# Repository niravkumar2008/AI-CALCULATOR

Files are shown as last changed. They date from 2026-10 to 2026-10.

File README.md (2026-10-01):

# AI Calculator

## Stage 4: the full calculator

The device now works like a Casio fx-300ES PLUS in COMP mode, with the AI photo solver as mode 4 in the MODE menu. The same C++ code runs in three places:

| Where | How |
| --- | --- |
| **Browser** | `AI_Calc_Simulator.html` (next to the exe; same as `sim/web/simulator.html`): double-click to open in Chrome or Edge. Clickable keypad, test bench (demo replies, hotspot/key switches, clock fast-forward, USB unlock). For real scans, pick Photo or Typed problem and paste your API key: it then sends exactly what the ESP32 sends (upright, grayscale, max 1600 px JPEG, same request, model, streaming and error handling). Direct API calls only work in this local file; the Claude artifact page blocks them. |
| **Windows** | `AI_Calc_Simulator.exe`: type on the keyboard (key list at the bottom of the window). **F6 scans a photo** (needs `api_key.txt` next to the exe). |
| **Tester** | `firmware/`: see [firmware/README.md](firmware/README.md). |

What the calculator does:

- **COMP maths:** + − × ÷, exact fractions (1÷3 = 1⌟3, S⇔D for decimal), powers, roots, x², x³, x⁻¹, x!, nPr, nCr, log (with base), ln, eˣ, 10ˣ, sin/cos/tan and inverses, hyp menu, Abs, %, π, e, Ran#, Rnd, ENG. Casio priorities: implicit × binds tighter than ÷ (1÷2π = 1÷(2π)), (−)2² = −4, brackets close themselves at the end. 10 significant digits, Norm1/Norm2.
- **Editing:** cursor with ◀ ▶ (wraps), DEL, SHIFT DEL = INS (overwrite), ▲ ▼ replay of the last 20 sums, Ans / PreAns, carry on from Ans with an operator.
- **Errors:** Math ERROR / Syntax ERROR / Stack ERROR with [AC] Cancel and [◀][▶] Goto.
- **Memory:** STO / RCL into A–F, X, Y, M; ALPHA types a variable; M+ / M−; SHIFT 9 = CLR (Setup / Memory / All).
- **MODE:** 1 COMP, 2 STAT and 3 TABLE (later), 4 AI SOLVE.
- **SETUP (SHIFT MODE):** 1–3 Deg / Rad / Gra, 4–5 Norm1 / Norm2, 6 Wi-Fi & key, 7 Screen look (Plain / LCD dots), 8 Exam mode.
- **AI SOLVE:** = scans; answer, question and steps scroll with ▲ ▼. If the photo is a calculation, Claude also sends it as `expression` and it is **typed into the main screen** for you to check, edit and press = (AC from the answer takes you there). Unclear scans are flagged on the main screen in reverse video.
- **Exam mode:** SETUP 8 then =, or SHIFT, 7, ON while off. AI, camera and Wi-Fi off; black status bar with a padlock and the time it's been on; survives power-off and restarts. Ends only with the USB cable (`exam off` over serial) or after 12 hours. CLR All doesn't end it.
- **Power:** SHIFT AC = OFF, auto-off after 10 minutes idle.

Screen: 125×61 pixels (the 2.13" e-paper at 2×) = 25 characters × 7 rows; row 0 is the status bar (S, A, M, STO/RCL, D/R/G, Wi-Fi, AI, ▲▼).

New code: `core/calc_engine.*` (tokens, parser, exact fractions, formatting), `core/device.*` (keys, menus, modes, exam, drawing), `sim/web/` (browser build). Tests: 422 checks, `./build/tests`.

Rebuild the browser simulator after changing `core/`: install [Emscripten](https://emscripten.org), then `sim/web/build.sh`.

## Stage 2: Windows simulator (AI flow)

Software for a modified Casio fx-300ES Plus that does one thing: take a picture of a problem and show Claude's answer and the steps to it.

Stage 2 runs the whole flow in a Windows simulator with **real Claude calls**: a photo file stands in for the camera.

## Run it

1. Extract the zip anywhere.
2. Create `api_key.txt` next to `AI_Calc_Simulator.exe` containing your Claude API key (from [console.anthropic.com](https://console.anthropic.com), *API Keys*). One line, nothing else. Setting a monthly spend limit in the Console is a good idea.
3. Double-click `AI_Calc_Simulator.exe`. (Windows may show a SmartScreen warning for an unsigned app: *More info → Run anyway*.)
4. Press Enter and pick a photo of a problem (JPG, PNG, HEIC if Windows can open it).

What happens: the photo is rotated upright, shrunk to at most 1600 px, turned grayscale, and sent to Claude Sonnet 5.5. Claude may think first on harder problems. The answer appears as soon as it arrives, and the steps follow a moment later.

**No `api_key.txt`?** The simulator falls back to Stage 1's sample mode and plays back the hand-written replies in `samples/`. The key file is re-read on every request, so you can add or fix it without restarting.

**Privacy:** the photo is sent only when you press Enter and pick a file. It is kept in memory only. `api_key.txt` is listed in `.gitignore`, so it is never committed to your repo.

| Laptop key | Calculator key | What it does |
| --- | --- | --- |
| Enter or `=` | `=` | Calculate; in AI SOLVE: take a picture / retake / retry |
| Esc | `AC` | Clear, back, or cancel while solving |
| Backspace | `DEL` | Delete |
| Arrows | REPLAY pad | Cursor, history, scroll |
| `m` then `4` | MODE 4 | AI SOLVE |
| Other keys | see `keysForChar` in `core/device.h` | s c t = sin cos tan, `[` SHIFT, `]` ALPHA ... |
| F2 / F3 | — | Simulate hotspot / API key on or off |
| F4 | `ON` / `SHIFT`+`AC` | Power on/off |
| F5 | — | USB cable: ends exam mode |

If Claude isn't sure it read the photo correctly (confidence below 0.8), you see what was unclear first: press `=` to retake, or ↓ to see the answer anyway.

## Messages you might see

| Screen | Meaning |
| --- | --- |
| CLAUDE ERROR / API key was rejected | Check `api_key.txt` |
| CLAUDE BUSY | Rate limit or Claude overloaded; try again shortly |
| NO CONNECTION | No internet, or the connection dropped mid-reply |
| TIMED OUT | No reply within 2 minutes |
| CAMERA ERROR / Couldn't open that image | Windows can't decode that file type |

## What's in here

```
AI_Calc_Simulator.exe   Windows simulator (built from the source below)
samples/                Hand-written example replies in Claude's reply format
core/                   Portable C++17 device logic, shared with the future ESP32 firmware
  device.*              The whole calculator: keys, COMP editing, menus, AI SOLVE, exam mode, status bar
  calc_engine.*         Tokens, Casio-order parser, exact fractions, number formatting, typed-text parser
  app.*                 AI SOLVE screens (Ready, Solving, Warning, Answer, Message)
  claude_api.*          Claude's instructions, reply schema, request body, stream reader, error mapping
  framebuffer.*         125x61 1-bit screen buffer (the e-paper at 2x)
  font*.cpp/h           5x7 font (X11 misc-fixed, public domain) incl. Greek, sub/superscripts
  text.*                Word wrap for 25-character lines
  json.*, solve_result.*  Reading Claude's reply
sim/win32_main.cpp      Simulator: Win32 window, file dialog as camera, WIC photo shrinking, WinHTTP
sim/web/                Browser simulator: web_main.cpp (JS bridge), page.html, build.sh -> simulator.html
tests/                  Unit tests + screen snapshots (tests/golden)
tools/gen_font.py       Regenerates core/font_data.cpp
firmware/               ESP32-S3 tester firmware (PlatformIO), Stage 4
```

## Reply format

Claude replies with exactly this JSON, enforced by the API's structured output. The field order is fixed, so the answer streams in before the steps:

```json
{
  "readable": true,
  "confidence": 0.95,
  "unclear": ["line 1: '7' could be '1'"],
  "expression": "sqrt(2*9.81*5.0)",
  "answer": "v ≈ 9.90 m/s",
  "read_as": "the question as understood",
  "steps": ["step 1", "step 2"]
}
```

The instructions (in `core/claude_api.cpp`) tell Claude the screen is 25×6 characters, so the answer is kept to about 2 lines, steps to about 75 characters, in calculator notation with no LaTeX. `expression` is the calculation in typed form (`*`, `/`, `^`, `sqrt(`, `pi`, `E` for ×10ˣ), or empty for word problems.

## Build from source (optional)

The tests run on Linux or macOS: `cmake -S . -B build && cmake --build build && ./build/tests` (run from this folder).
The exe is cross-compiled with MinGW:
`x86_64-w64-mingw32-g++ -std=c++17 -O2 -static -mwindows -o AI_Calc_Simulator.exe sim/win32_main.cpp core/*.cpp -lgdi32 -lwinhttp -lwindowscodecs -lole32 -loleaut32 -lcomdlg32`

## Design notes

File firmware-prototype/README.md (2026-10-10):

# Board firmware (the calculator inside the Casio shell)

This is the firmware for the custom board (`../hardware/kicad`, ESP32-S3-MINI-1-N4R2): the full
calculator from `../core` (the same code as the simulators), the whole keypad, the e-paper, the OV5640
autofocus camera, the 150 mAh battery and deep sleep, Wi-Fi through the AI proxy (`../server/proxy`),
over-the-air updates and a phone setup page. **`../firmware/` is the old breadboard tester** (different
pins, different board): never flash it to this board.

**Status (stage 14, 2026-10-06):** builds clean (`pio run`: RAM 30.7 %, flash 63 % of the 1.9 MB OTA
slot). Not yet run on hardware: start at `../hardware/ARRIVAL_CHECKLIST.md`, then `../hardware/bringup_guide.html`
(step 10 = AI server + token); the day-one script in `../firmware/FINAL_REVIEW_firmware.md` is the same path. Version string: `kFirmwareVersion` in `src/claude_client.h`.

## Hardware it expects (from the schematic)

| Part | What |
| --- | --- |
| Module | ESP32-S3-MINI-1-N4R2 (4 MB flash, 2 MB quad PSRAM) |
| Camera | OV5640 autofocus on J1; power through CAM_PWR_EN (GPIO 34), PWDN 48, RESET 38 (open-drain); data pins in `hardware/pins_final.h` |
| Screen | 2.13" e-paper panel (SSD1680, 250x122) on J2 with the board's boost circuit; BUSY on GPIO 33 (weak internal pull-down so a missing panel doesn't stall the bench) |
| Keys | 49 keys as an 8 x 10 matrix (ROW0-7, COL0-9) into a TCA8418 (I2C on GPIO 1/2, INT 4); ON on GPIO 7 |
| Power | Adafruit #1317 150 mAh LiPo on J4, MCP73831 charger at 50 mA (STAT on GPIO 35, pulled up to VBUS_SENSE), battery sense GPIO 9 (1 M / 1 M), USB sense GPIO 37 |
| USB | the chip's own USB on GPIO 19/20, through the magnetic plug (J3) |

Every pin is in **`hardware/pins_final.h`** (`src/pins.h` only includes it; it is the single source of
truth and `python tools/check_pins.py` compares it with the schematic's netlist). Which key sits at which
matrix crossing is `kMatrix` in `src/keys.cpp`.

## Files

| File | What |
| --- | --- |
| `src/main.cpp` | the loop: keys, screen, Wi-Fi on/off, battery lock-out, viewfinder, Send, setup mode, updates, deep sleep |
| `src/settings.*` | NVS settings (hotspot, proxy, token) and the Serial Monitor commands |
| `src/setup_portal.*` | phone setup: the calculator's own Wi-Fi network + sign-in page that writes the settings |
| `src/ota.*` | over-the-air update: manifest, download, SHA-256 check, second app slot, rollback |
| `src/claude_client.*` | HTTPS to the proxy: the photo solve (streamed), small JSON calls, the firmware download |
| `src/camera.*`, `src/preview.*` | OV5640 capture / tuning, and the laptop preview page (`preview` command) |
| `src/keys.*`, `src/screen.*`, `src/power.*` | TCA8418 keypad + ON, e-paper, battery / charging / deep sleep |
| `src/selftest.*` | factory self-test (`SELFTEST_JSON` line; fields listed in `hardware/bringup_guide.html`) |
| `src/log.h` | `LOGF("module", ...)`: every log line is `[module] text` |
| `platformio.ini` | board settings; `min_spiffs.csv` partition table = two 1.9 MB app slots for OTA |

## 1. Build and flash (USB)

1. VS Code with the PlatformIO extension. **File > Open Folder** > `firmware-prototype` (this folder).
2. Plug the magnetic USB cable into the board and the PC.
3. Click **Upload** (the arrow in the blue bar). First build downloads the toolchain (5-10 minutes).
   Command line: `%USERPROFILE%\.platformio\penv\Scripts\pio run -t upload` from this folder.
4. **Serial Monitor** (plug icon) at **115200**. Type `help`.

The first upload after this version also writes the new partition table (two app slots). Saved settings
survive it (NVS sits at the same place in both tables). **The first flash of every board is this USB
upload**: an over-the-air update only writes the other app slot, never the partition table. After it,
`status` shows `slot app0`.

### Recovery: no COM port, or "no serial data"

The chip is in normal boot and must be forced into download mode. Plugging the cable in does **not**
reset the chip while the battery is connected (the battery keeps 3.3 V and EN up), so holding BOOT while
plugging in does nothing on its own. Back cover off:

1. Hold a wire from **TP1 (BOOT)** to **TP4 (GND)**.
2. Tap a second wire from **TP7 (EN)** to **TP4 (GND)** for about 0.2 s. The chip restarts in download mode.
   (Or unplug the battery at J4 first, then hold TP1 to GND while you plug the cable in.)
3. Release TP1 and click Upload.
4. When it finishes, tap TP7 to GND once more to start the new firmware.

Backup path if the USB path ever fails: the ROM also listens on UART0. A 3.3 V USB-serial adapter on
**TP2 (TX) / TP3 (RX) / TP4 (GND)**, then the same TP1 + TP7 sequence, and upload over that COM port.

**Never burn the security or USB-disable eFuses** (`DIS_USB_SERIAL_JTAG`, `DIS_DOWNLOAD_MODE`,
`ENABLE_SECURITY_DOWNLOAD`), and never enable secure boot or flash encryption on this board: they are
the only things that could lock it out for good.

## 2. First setup

The calculator needs three things to use AI: a phone hotspot (name + password), the AI server address
(`https://...`, your deployed `server/proxy`) and its device token (`python admin.py new-device "board 1"`
on the server). The maths works with none of them. It never holds a Claude API key: the `token` command
refuses anything starting with `sk-ant-`, and an old key left by earlier firmware is erased at first boot.

**From a phone (no PC):** SHIFT MODE (SETUP) > **6: Wi-Fi & key** > press **=**. The screen shows
`SETUP BY PHONE` with a network name (`AI-Calc-xxxx`) and an 8-character password. Join that network on
the phone; the setup form pops up as the network's sign-in page (or open `http://192.168.4.1`). Pick the
hotspot from the list the calculator saw, type its password, the server address and the token, **Save**.
The calculator closes the network a few seconds later. AC leaves setup mode; it also ends by itself after
10 minutes. (The serial command `setup` does the same and prints the details; `setup off` stops it.)

**From the Serial Monitor:** `wifi`, `proxy`, `token`. Then `pair` for the 6-letter code and open
`<server>/link` on the phone (an unlinked calculator also shows the code when you first press = in AI
SOLVE), and `account` for the subscription state.

Other commands: `status`, `scan`, `snap`, `preview` (laptop camera page), `selftest`, `update`,
`forget`, `keys 1/3=` (press keys from the keyboard: digits . + - * / ^ ( ) =; s c t sin cos tan,
l log, n ln, r sqrt, q x², i x⁻¹, b Abs, g logₐb, f fraction, ~ (−), E ×10ˣ, h hyp, k RCL, w S⇔D, M M+,
a Ans, # DEL, $ AC, m MODE, o ON, [ SHIFT, ] ALPHA, < > u d arrows, p π, ! x!, % percent, , comma),
`exam off` (the teacher's USB unlock).

## 3. Using it

- **MODE 4 = AI SOLVE.** The viewfinder runs on the e-paper; **point the camera at the problem and
  press =**. ▲▼ change the effort, **1** toggles tutor mode (one hint per =), AC goes back to the
  calculator, ▶ restarts the viewfinder after its 30 s idle timeout.
- **Messages on the glass:** `No connection` / `NO CONNECTION` (turn the phone's hotspot on),
  `Not set up` (see First setup), `Battery low: plug in the cable to use AI solve` (below 3.6 V the
  camera and Wi-Fi stay off together until the cell is back above 3.7 V or a cable is in; maths keeps
  working), `AI ACCOUNT` (link / subscription / monthly cap, with the server's own sentence), the black
  `EXAM` bar (exam mode), and while off on a cable: `Charging 64%`.
- **Off** (SHIFT AC, or 10 minutes idle) is deep sleep (~25-35 µA for the board). ON or any key wakes
  it; memories, history and settings come back from RTC memory. With a cable in it stays awake so the
  Serial Monitor keeps working.
- **Exam mode:** SHIFT, 7, ON while off (or SETUP 8). Wi-Fi and camera off until a USB cable's
  `exam off` or 12 hours. Survives a battery pull.
- Battery reading off by more than 2 % from a meter on TP6? Adjust `kBatteryCal` in `src/power.cpp`.

## 4. Firmware updates over the air (OTA)

1. Build (`pio run`). The image is `.pio/build/prototype/firmware.bin`; bump `kFirmwareVersion` in
   `src/claude_client.h` first (the proxy compares version strings, so any change counts as "different").
2. On the server: `python admin.py firmware .pio/build/prototype/firmware.bin stage14-2026.10.10`.
   That copies the image into `FIRMWARE_DIR/stage14/` with its size and SHA-256. The proxy keeps one
   image per board family, so a v15 LCD image (`v15lcd-...`) can be published at the same time and
   is never offered to these boards (nor this one to v15 boards).
3. On a calculator: either type `update` in the Serial Monitor, or just **switch it off (SHIFT AC)
   with the cable in**: 20 s later it joins the hotspot, asks the proxy (`GET /v1/firmware` with its
   version), and if the server has a different image it shows `UPDATING ... 45%`, checks the SHA-256,
   writes the other app slot and restarts. It checks again once a day while it stays on the cable.
   On battery an update needs more than 3.8 V (`update` command only; the automatic check needs a cable).
4. The new firmware **confirms itself** 15 s after boot once the keypad scanner answers
   (`esp_ota_mark_app_valid_cancel_rollback`). If it crashes before that, the bootloader boots the
   previous slot (`status` shows the slot and "not yet confirmed").

The image travels over TLS to the root-pinned proxy and is accepted only when its hash matches the
manifest; there is no signing key in the firmware or the repo (nothing secret is in either).

### Proxy follow-ups in `stage14-2026.10.10` (small, safe changes)

- **Preview Send no longer gives up on a long answer.** `kSendSolveTimeoutMs` (120 s *total*) became an
  idle limit, `kSendSolveIdleMs` = 150 s without a byte to or from the proxy (the client's own `kIdleMs`
  of 120 s still reports first), plus an overall cap `kSendSolveMaxMs` = 300 s (`src/main.cpp`). The
  proxy's `: ping` every 15 s counts as activity, so an `xhigh`/`max` solve that is still thinking or
  streaming isn't called "took too long" at 2 minutes. `src/claude_client.cpp` notes the time of the last
  byte sent or received (`claudeLastActivityMs()`).
- **Burst-limit message.** The proxy can now answer its burst limit as `429 rate_limited`; `core`'s
  `classifyFailure` shows its message like the other account errors. The proxy sends the old
  `fair_use_exceeded` to firmware older than 2026-10-10 (by `x-firmware`), so boards still on
  `stage14-2026.10.06` keep showing the message too.
- The request still carries the system prompt on v14 (`CALC_SEND_SYSTEM_PROMPT` defaults to 1), so these
  boards also work with an older proxy. Build result unchanged: RAM 30.7 %, flash 63.4 %, no warnings.

## 5. Serial log

Every line starts with its module: `[keys] 7`, `[wifi] connected: 172.20.10.3`, `[cam] focus ...`,
`[solve] [3] answer after 6120 ms`, `[ota] ...`, `[setup] ...`, `[power] deep sleep`. Two lines are
different on purpose: the `status` block, and `SELFTEST_JSON {...}` (one JSON line the bring-up guide
asks you to save). Interactive prompts (`Hotspot name:`) have no prefix.

## Differences from the tester

| | Tester (`../firmware`) | This board |
| --- | --- | --- |
| Keys | =, AC, ▲, ▼, BOOT | whole keypad; hold ▲ ▼ ◀ ▶ DEL to repeat |
| Key row 2 | — | fx-115ES legends: CALC, ∫dx, x⁻¹, logₐb (CALC / ∫dx show "Not supported yet") |
| Starts in | AI SOLVE | COMP, like the Casio (MODE 4 = AI SOLVE) |
| Photo | 1600x1200 + enhanced close-up | 2048x1536 after autofocus, best of 4 frames, one photo |
| Claude | API key in the device (never ship it) | proxy + device token, no key on the device |
| Power | USB | LiPo; deep sleep when off; Wi-Fi only in AI SOLVE, capped at 11 dBm; AI off below 3.6 V |
| Setup | Serial Monitor | Serial Monitor or the phone setup page |
| Updates | USB | USB or over the air with rollback |
| Serial Monitor | COM/UART port | the magnetic USB plug |

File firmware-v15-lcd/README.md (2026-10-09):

# Board firmware for v15-LCD (colour screen + live camera preview)

Firmware for the **v15-LCD board** (`../hardware/kicad_v15_lcd`): the v14 calculator board with the
2.13" e-paper replaced by a **1.9" 170x320 colour IPS LCD** (panel: **BuyDisplay ER-TFT019-1**, no touch,
ST7789P3, 4-wire SPI) and a PWM backlight (Q5 switch, R23 = 15 Ω: ≈ 26 mA typical at 100 %, 16-37 mA range).
Everything else is the v14 hardware and the v14 behaviour: the full calculator from `../core` (the same
code as the simulators), the whole keypad through the TCA8418, the OV5640 autofocus camera, the 150 mAh
battery and deep sleep, Wi-Fi through the AI proxy, over-the-air updates, the phone setup page and the
factory self-test.

**This is a separate project.** `../firmware-prototype/` is the v14 (e-paper) firmware and is unchanged
for the v14 boards being built now; never flash this one to a v14 board (the e-paper GPIOs are driven as
LCD lines and KEYPAD_INT is on a different pin). `../firmware/` is the old breadboard tester.

**Status (2026-10-08):** builds clean (`pio run`: RAM 28.8 %, flash 68.0 % of the 1.9 MB OTA slot).
**Not yet run on hardware** (the v15 board was verified "ORDER" in `hardware/verification/14_v15_final_preorder.md`
but has not arrived yet): everything marked "verify on the panel" in `PORT_NOTES.md` needs the real LCD.
The GPIO roles below are the final (review 13) ones; `src/pins.h` takes them from the header, so no code
change was needed for review 14 (R23 and the key-pad moves are hardware only; `kMatrix` is unchanged). The v14 project still builds unchanged (RAM 30.7 %, flash 63.4 %).

## What is different from v14

| | v14 (`firmware-prototype`) | v15 (this) |
| --- | --- | --- |
| Screen | 2.13" e-paper, 250x122, 1-bit, ~0.3 s partial refresh, ghosting | 1.9" IPS LCD, 320x170, 65k colours, ~22 ms per frame |
| Driver | GxEPD2 (`screen.cpp`) | LovyanGFX `Panel_ST7789` (`lcd.cpp`): SPI2 at 40 MHz with DMA, column offset 35, canvas in PSRAM |
| UI | the core's 125x61 picture drawn at 2x | the same picture read back as text (`fbtext.cpp`) and re-typeset in colour: status bar with battery % / Wi-Fi, large expression (3x font) and result (4x), soft-key bar (`ui.cpp`) |
| Viewfinder | grey, dithered, 2-3 fps | **live colour preview**, 320x240 RGB565 from the sensor, middle 320x170 shown 1:1, framing guide, focus state, ▶ to refocus (`vf_lcd.cpp`) |
| Backlight | none | LEDC PWM on IO4 (R23 15 Ω: ≈ 26 mA at 100 %, ≈ 9 mA average at the 60 % default, because the duty is squared to 36 %): brightness setting in NVS, dim after 20 s, off after 60 s, panel sleep after 120 s, any key wakes it |
| Power down | hold e-paper lines | backlight 0 → SLPIN → every LCD line low → LCD_PWR_N high (panel unpowered, < 2 µA) |
| Pins | `hardware/pins_final.h` | `hardware/kicad_v15_lcd/pins_v15_lcd.h` (KEYPAD_INT on **IO3**) |
| Self-test | e-paper checkerboard, `display_ok` from the BUSY timing | colour bars + grey ramp + border, backlight sweep: `lcd_ok`, `lcd_push_ms`, `backlight_ok`, `backlight_pct` (and `display_ok` / `display_refresh_ms` kept as aliases) |
| Serial | | new: `bright N`, `screen dim|off|sleep N`; `status` has a Screen line |
| Keys | | SHIFT ▲ / SHIFT ▼ = brightness (like the Casio's contrast); ▶ in the viewfinder = refocus |

Nothing in `../core/` changed. The firmware files that are byte-identical to v14: `claude_client.*`, `ota.*`,
`keys.*` (the pin comes from the header), `preview.*` (the laptop page), `setup_portal.*`, `root_ca.h`, `log.h`.

## Files

| File | What |
| --- | --- |
| `src/main.cpp` | the loop (as v14) + the LCD viewfinder, backlight idle policy, brightness keys |
| `src/lcd.*` | ST7789 driver setup (LovyanGFX), power sequence, panel sleep, canvas, backlight PWM + idle policy (NVS `lcd`) |
| `src/ui.*` | the colour screens: status bar, calculator, menus / AI pages / notices (from the core's render), setup / update / self-test pages |
| `src/fbtext.*` | reads the core's 1-bit render back into text cells (glyph matching against the core font) |
| `src/glyphdraw.h` | draws the core's 5x7 font scaled on an LGFX sprite (one font everywhere, every maths symbol) |
| `src/vf_lcd.*` | the live preview overlay (brackets, focus state, text box, hints) drawn into the camera frame, then pushed |
| `src/camera.*` | v14's capture + **preview mode** (`cameraPreviewBegin / Grab / Release`, `cameraRefocus`, `cameraFocusState`): RGB565 QVGA ↔ JPEG mode switch |
| `src/power.*` | as v14, with the LCD lines held low and LCD_PWR_N / backlight floated in deep sleep |
| `src/selftest.*` | as v14 with the LCD / backlight step |
| `src/settings.*` | as v14 + `bright`, `screen` commands |
| `src/pins.h` | includes `hardware/kicad_v15_lcd/pins_v15_lcd.h`; refuses to build without `-DBOARD_V15_LCD` |
| `platformio.ini` | `env:v15lcd`; the four panel flags to confirm on the bench (`LCD_ROTATION`, `LCD_INVERT`, `LCD_RGB_ORDER`, `PREVIEW_SWAP_BYTES`) |

## Build and flash

1. VS Code + PlatformIO. **File > Open Folder** > `firmware-v15-lcd`.
2. Plug the magnetic USB cable in; click **Upload**. Command line:
   `%USERPROFILE%\.platformio\penv\Scripts\pio run -t upload` from this folder (`pio run` only builds).
3. **Serial Monitor** at 115200, type `help`. Recovery (no COM port) is exactly as in
   `../firmware-prototype/README.md` (TP1 to GND, tap TP7). **Never burn an eFuse.**

Dependencies (fetched by PlatformIO): `lovyan03/LovyanGFX@^1.2.0` (built with 1.2.32), the
`ESP32-OV5640-AF` library, and `../core` via symlink. Partition table `min_spiffs.csv` (two OTA slots),
same as v14, so an OTA image built here installs on a v15 board that was first flashed over USB.

## Pins (from `hardware/kicad_v15_lcd/pins_v15_lcd.h`)

| Signal | GPIO | Note |
| --- | --- | --- |
| LCD_MOSI | 5 | SDO (MISO) not wired: write-only panel |
| LCD_DC | 6 | |
| LCD_SCK | 8 | SPI2 through the GPIO matrix, 40 MHz |
| LCD_CS | 41 | |
| LCD_RST | 42 | |
| LCD_PWR_N | 33 | low = panel powered (Q4 P-FET); R21 pull-up keeps it off in sleep |
| LCD_BL_EN | 4 | backlight PWM (Q5), R22 pull-down = off in sleep |
| KEYPAD_INT | **3** | was IO4 on v14; still an RTC pin (deep-sleep wake works) |
| Camera, I2C, ON, battery, USB | unchanged | |

`python tools/check_pins.py` (copied from v14) compares the header with a netlist exported from the
v15 schematic.

## Using the live preview

MODE 4 (AI SOLVE) starts the camera in preview mode (about 1 s). The screen shows what the camera sees
in colour, the middle 170 of the 240 rows: the photo that will be sent continues above and below the
dashed marks. Top band: the focus state (**FOCUSING** amber / **FOCUSED** green / **HOLD STILL** when
the picture moves), the effort / tutor setting, battery. Bottom band: `= Scan`, `▶ Focus`, `▲▼ Effort`,
`AC Back`, and the frame rate (or "off in 10 s" near the 30 s idle time-out). An amber box marks writing
the analysis found. Keys: **=** takes the full-resolution photo (the sensor switches to JPEG mode for the
scan, ~1 s added to the hold-still time; the viewfinder comes back on the next visit to AI SOLVE),
**▶** triggers a single-shot autofocus, **▲▼** effort, **1** tutor, **AC** back. Rules kept from v14: no
preview, camera or Wi-Fi below 3.6 V on battery (3.7 V to resume, or a cable); camera off before Wi-Fi
bursts; 30 s without a key turns the camera off (▶ turns it on again).

## Screen and backlight

- `bright N` (10-100, saved) or SHIFT ▲ / SHIFT ▼ on the calculator screen. Default 60 %. The duty is
  squared (50 % looks half as bright). Full current at 100 % is set by R23 = 15 Ω: ≈ 26 mA typical,
  16-37 mA depending on the panel's LED voltage (ER-TFT019-1: 2.8-3.2 V at 60 mA); measure it as
  V(R23) / 15 (bring-up guide step 10).
- `screen dim 20`, `screen off 60`, `screen sleep 120` (seconds without a key; 0 = never). While the
  viewfinder, a scan, setup by phone or an update is on, the light stays full. When the light is off, the
  next key only wakes the screen (ON still counts).
- Off (SHIFT AC or 10 min idle) = deep sleep as in v14; the panel is unpowered, so the whole board stays
  at the ≤ 40 µA target. The screen is redrawn from the calculator's saved state on wake (~150 ms).

## Self-test

`selftest` (or SHIFT + ALPHA + ON): colour bars, a grey ramp, a white border and the device id, then the
backlight sweeps 0 → 100 %. The JSON line adds `lcd_ok` (driver initialised and a frame pushed in
< 200 ms — the panel cannot answer back, so look at it), `lcd_push_ms`, `backlight_ok`, `backlight_pct`;
`display_ok` / `display_refresh_ms` are kept so the v14 bring-up checklist still reads. Other fields are
unchanged.

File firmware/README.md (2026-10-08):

# Tester firmware (Stage 4)

> **This is the old breadboard tester (ESP32-S3-CAM dev board + buttons), not the board firmware.** The firmware for the custom board inside the Casio is **`../firmware-prototype/`**; never flash this one to that board.

Runs the full calculator (the same code as the browser and Windows simulators) on the real tester:
ESP32-S3-CAM (OV3660 camera) + Waveshare 2.13" e-paper HAT V4 + 4 buttons.
Wire it first with the hole-by-hole checklist in the Build Book.

## 1. Install (once)

1. Install [VS Code](https://code.visualstudio.com).
2. In VS Code: Extensions (left bar) → search **PlatformIO IDE** → Install. Restart VS Code when asked.

## 2. Upload

1. **File → Open Folder…** and pick `AI-CALCULATOR\firmware` (this folder, not the repo root).
2. Plug a USB-C **data** cable into the board's port marked **COM** (or UART).
3. Click the **→ Upload** arrow in the blue bar at the bottom. The first build downloads the ESP32 tools and takes 5–10 minutes; later builds take seconds.
4. When it says `SUCCESS`, press the board's **RST** button.

If upload fails with "Failed to connect" or "Wrong boot mode": hold **BOOT**, tap **RST**, let go of BOOT, and click Upload again. Press RST once it finishes.

If Windows doesn't show a COM port at all: try a different cable (many only charge), or install the **CH340** USB driver from the chip maker, WCH.

## 3. Set up Wi-Fi and your key (once)

1. Turn on your phone's hotspot. iPhone: Settings → Personal Hotspot → turn on **Maximize Compatibility** (the chip only uses 2.4 GHz).
2. In VS Code, click the **plug icon** (Serial Monitor) in the bottom bar.
3. Type `wifi` and press Enter, then the hotspot name, then the password.
4. Type `key`, press Enter, paste your Claude API key, press Enter.
5. Type `status` to check: camera found, Wi-Fi connected, key saved.

What you type isn't echoed back, so your key never appears on screen. Settings survive power-off and re-uploads. `forget` erases them.

| Command | Does |
| --- | --- |
| `wifi` | Set hotspot name and password |
| `key` | Set the Claude API key |
| `status` | Camera, Wi-Fi, key, free memory |
| `preview` | Live camera view + tuning + **Send to Claude** (scans what the camera sees and shows the answer on the page; the board steps onto the hotspot for a few seconds, then comes back) + a live **Focus** number (highest = sharpest distance), and the last scan photo and its close-up. The board makes its own network (name, password and link printed); join it from the laptop. `preview off` stops, 15 min limit |
| `scan` | List the Wi-Fi networks the board can see (checks the hotspot name) |
| `snap` | Take a test photo and report its size and time |
| `forget` | Erase hotspot and key |
| `keys ...` | Press calculator keys, e.g. `keys 1/3=` (list below) |
| `exam off` | End exam mode (the USB cable is the teacher's unlock) |

## How a scan photo is taken

The photo matters most, so a scan takes its time (about 10 s; the screen counts down):
1. **Careful scan** (on by default): tries exposure, gain and contrast on the real page and keeps
   the best for the light (see below).
2. **Hold still** wait (1.5 s by default; "Hold-still wait" on the preview page, 0.2-3 s).
3. **8 frames over 2 s**; keeps the one whose writing is sharpest.
4. **Zoom + enhance**: the writing is cut out at full resolution (or the whole frame when it fills
   it), the lighting evened out, contrast raised, enlarged to ~1.15 MP and sharpened. Claude gets
   the photo plus this enhanced copy.
With an **OV5640** (5 MP) the photo is 2560x1920, already as much detail as Claude reads, so steps 3-4
become 4 frames and no close-up: just the sharpest photo is sent.
Claude always gives its best guess; unsure answers show as "BEST GUESS (62% sure)" with what to
check. Press = to retake.

**Careful scan** (on by default; turn off on the preview page with "Careful scan" = 0, then Save for scans): before each photo it
tries 5 exposure levels, extra gain for dim rooms and 3 contrast levels on the real page, scores
each photo for clean ink edges, bright-but-not-washed-out paper and dark ink, and keeps the best.
About 5 s slower. "Tune for this light now" on the page does the same once, without scanning.

## 4. Use

The tester starts in **AI SOLVE** (MODE 4). It has 5 buttons:

| Key | Does |
| --- | --- |
| `=` | Take the photo / retake / retry; on the calculator screen: calculate |
| `AC` | Back or cancel. On an empty calculator screen: back to AI SOLVE (the tester has no MODE key) |
| ▲ ▼ | On the AI SOLVE screen: effort (Normal / Careful / Max: slower, better at tricky math). On an answer: scroll (hold to keep scrolling). On the calculator screen: history |
| BOOT (on the board) | ON / OFF |

After a scan of a calculation, `AC` takes you to the calculator screen with the scanned sum typed in: press `=` to check it.

**Every other key** can be pressed from the Serial Monitor with `keys`, one character per key:

| Type | Key | Type | Key | Type | Key |
| --- | --- | --- | --- | --- | --- |
| `0`–`9` `.` | digits | `+ - * /` | + − × ÷ | `^` | xⁿ |
| `(` `)` | brackets | `=` | = | `~` | (−) |
| `s` `c` `t` | sin cos tan | `l` `n` | log ln | `r` `q` | √ x² |
| `i` | x⁻¹ | `f` | fraction | `E` | ×10ˣ |
| `h` | hyp | `k` | RCL | `w` | S⇔D |
| `M` | M+ | `a` | Ans | `#` | DEL |
| `$` | AC | `m` | MODE | `o` | ON |
| `[` | SHIFT | `]` | ALPHA | `< > u d` | ◀ ▶ ▲ ▼ |
| `p` | π | `!` | x! | `%` `,` | % and comma |

Examples: `keys 1/3=` (1⌟3), `keys s30)=` (sin 30), `keys [m1` (SETUP → Deg), `keys m1` (back to COMP), `keys m4` (AI SOLVE), `keys [m8=` (exam mode on), `exam off`.

The Serial Monitor logs each key and each photo: size, time to the answer, time to done. That's the data for the camera distance test (15, 25, 35 cm).

Exam mode turns Wi-Fi off, is saved to flash every minute, and comes back on after a restart; only `exam off` over USB or 12 hours ends it.

## Troubleshooting

| You see | Try |
| --- | --- |
| E-paper stays blank | Check the 8 e-paper wires against the checklist; the Serial Monitor still works |
| `Camera: not found` | Re-seat the camera ribbon (flip the latch up, push the ribbon fully in, latch down) |
| NO CONNECTION | Hotspot on, Maximize Compatibility on, then `status` |
| "Secure connection failed" | Send me the exact text; the server certificate list may need a new entry |
| A button does nothing | Check its wire; pins are in `src/pins.h` |

## Files

```
platformio.ini        board, memory and library settings (N16R8: 16 MB flash, 8 MB PSRAM)
src/pins.h            every pin in one place (provisional until the board's labels are checked)
src/main.cpp          buttons, serial keys, Wi-Fi, exam radios, and the task that captures + sends each photo
src/camera.*          finds the camera wiring, takes a grayscale 1600x1200 JPEG
src/screen.*          draws the 125x61 calculator screen on the 250x122 e-paper (Plain or LCD dots)
src/claude_client.*   HTTPS to Claude with streaming, same request as the simulator
src/settings.*        hotspot, key and exam state in flash, serial commands
src/root_ca.h         certificates used to verify api.anthropic.com
../core/              shared calculator logic (the same code the simulator runs)
```

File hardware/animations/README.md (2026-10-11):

# Animations of the finished calculator

Animated GIFs for the build guides and the project hub (`hardware/project_hub/index.html`, section "See it come together").
They are rendered from the 1:1 Fusion 360 final-assembly models. Only the camera and the part positions are animated: no geometry was changed and nothing was saved in Fusion.

All files are 960 × 720 and loop forever. The `*_poster.jpg` files are the last frame of each GIF. The hub shows them instead of the GIF when "reduce motion" is turned on.

| File | What it shows | Frames | Size |
|---|---|---|---|
| `v15/assembly_v15.gif` | Same order and step numbers as the build guide. The bare board, key side up. Step 5: LCD onto the board, tail through the slot into J5. The board turns over. Step 6: camera + ribbon into J1. Step 7: magnet piece into J3. Step 8: the empty front shell, key mat in, then the finished board onto the posts. Step 9: battery in, plug into J4. Step 10: back cover + screws. Step 11: the view swings to the front and the colour screen comes on. | 50 | 1.67 MB |
| `v15/turntable_v15.gif` | Closed calculator turning 360° (front and back), screen on | 36 | 1.43 MB |
| `v15/xray_v15.gif` | See-through shells, assembled ↔ exploded and back | 24 | 2.93 MB |
| `v14/assembly_v14.gif` | Same steps for the e-paper build (step 5: e-paper screen onto the board). At the end the e-paper shows a sum. | 50 | 1.73 MB |
| `v14/turntable_v14.gif` | Closed v14, 360°, e-paper showing the sum | 36 | 1.42 MB |
| `v14/xray_v14.gif` | v14 x-ray, exploded ↔ assembled | 24 | 2.92 MB |
| `v15/*_poster.jpg`, `v14/*_poster.jpg` | Still of the last frame | 1 | 52–69 kB each |

No MP4 files: ffmpeg is not installed on this PC. If `ffmpeg` is on PATH, the script also writes `<anim>_<ver>.mp4` next to each GIF.

The v15 screen image is the real firmware screenshot `hardware/renders_ui_v15/05_calc_result_functions.png` (`sin(30)+π×2²−log(100)` = 11.06637061). Fusion renders the LCD's active area in chroma-key green. Pillow then fits the screenshot into it with a perspective warp, using the screen's four corners projected from the model (the same method as `compose_v15.py`). While the calculator is still being built, the screen is shown as dark glass (off).

The v14 e-paper works the same way. Its image is drawn by the script (`epd_image()`): a 250 × 122, 1-bit black-on-white screen made with the firmware's own 5 × 7 font from `core/font_data.cpp`. It shows a status line, `√(144)+2^3×1.5` and the result `24`. It is drawn as dark ink on light-grey film. A copy is saved as `_frames/v14/<anim>/epd_screen.png`. Before the screen comes on, the e-paper is shown as blank film. The turntable and x-ray show the e-paper image as well.

The assembly follows the build guides (`final_assembly/assembly_guide.html`, `final_assembly_v15_lcd/assembly_guide_v15_lcd.html`), and its caption bars use the guides' step numbers. Steps 5–7 are shown on the bare board. The camera turns over with the board for steps 6–7. Only the camera moves; the model stays put.

## Regenerate

Fusion 360 must be open with the FusionMCPBridge add-in and both final-assembly documents loaded: v14 (`Final - …`) and v15 (`V15 - …`). Opening `final_assembly/ai_calculator_final_assembly.f3d` and `final_assembly_v15_lcd/ai_calculator_v15_lcd_final_assembly.f3d` is enough. Then run:

```
cd hardware/enclosure
python animate_assembly.py ver=v15 anim=all      # about 6 min: render in Fusion, then build the GIFs
python animate_assembly.py ver=v14 anim=all      # about 1 min
python animate_assembly.py compose ver=v15       # rebuild GIFs only, from frames already rendered (no Fusion)
python animate_assembly.py ver=v15 anim=assembly pick=0,20,43   # quick look at a few frames
```

Then copy the GIFs and posters to `hardware/project_hub/img/` as `anim_<anim>_<ver>.gif` / `anim_<anim>_<ver>_poster.jpg`.

- Raw frames (1280 × 960 PNG plus `frames.json` with the captions, durations and screen corners) go to `_frames/<ver>/<anim>/`. That folder is git-ignored and takes about 50 MB.
- Every change made in Fusion is restored at the end of a run: part positions, visibility, the x-ray opacity and the screen marker's appearance. The document is never saved.
- Fusion's progress is logged to `hardware/enclosure/animate_assembly.log`.
- The GIFs use one shared, optimised palette (median cut, no dithering). If a GIF goes over its limit (assembly 6 MB, turntable 4 MB), the script retries with fewer colours.

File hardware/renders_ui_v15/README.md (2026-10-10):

# v15 colour LCD: real UI screenshots

These are **real screenshots, not mock-ups**. The firmware's own drawing code drew every image on a PC:

- `firmware-v15-lcd/src/ui.cpp`, `fbtext.cpp`, `vf_lcd.cpp` and `selftest.cpp` are compiled **unchanged**.
- They draw into a real **LovyanGFX `LGFX_Sprite`** (the library version the firmware builds with, compiled for the PC).
- The real **core/** calculator feeds them (`calc::Device`, `App`, `Viewfinder`).

Only the panel itself is simulated. `lcd::flush()` and `lcd::pushRaw()` copy the 320 × 170 RGB565 frame into a file instead of sending it over SPI.

Old mock-up, for comparison: `hardware/enclosure/final_assembly_v15_lcd/renders/mock_ui_320x170.png`. It was a mock-up and is **not** what the firmware draws.

## Regenerate

```
python tools/ui_sim_v15/make_screens.py
```

What it needs:

- Pillow and numpy
- the MSVC Build Tools (found the same way as `tests/msvc/build_and_run.bat`)
- LovyanGFX in `firmware-v15-lcd/.pio/libdeps`. If it isn't there, run `pio run -e v15lcd` once in `firmware-v15-lcd`.

What it does:

1. It makes the sample photo.
2. It builds `tools/ui_sim_v15/build/ui_sim_v15.exe` with `build.bat` and runs it.
3. It writes every PNG in this folder.

It takes about 1 minute; the first LovyanGFX build takes about 2 minutes. Nothing in `firmware-*` or `core/` is changed. The harness only adds host stand-ins:

| File | What it stands in for |
|---|---|
| `shim/fw/Arduino.h`, `WiFi.h`, `esp_chip_info.h`, `esp_camera.h` | The ESP32 Arduino core and ESP-IDF headers |
| `host_hw.cpp` | `lcd::`, using a fake clock |
| `shim/lgfx_host/SDL.h` | Type names only, so LovyanGFX picks its desktop platform. No real SDL and no window. |
| `lgfx_host_*.cpp` | LovyanGFX's platform functions |

## Files

All files are 320 × 170, which is exactly the panel's pixels. `x3/<name>_x3.png` is the same image ×3, nearest-neighbour, for print.

| File | Screen | Drawn by |
|---|---|---|
| `01_calc_home` | Calculator after ON (cursor) | `ui::showDevice` ← `Device` |
| `02_calc_typing` | Typing `2×(3+4)²÷7+√16` | same |
| `03_calc_result` | …and `=` → 18 | same |
| `04_calc_typing_functions` / `05_calc_result_functions` | `sin(30)+π×2²−log(100)` (wraps to 2 lines) → 11.06637061 | same |
| `06_calc_shift` | SHIFT on: amber S, soft keys change | same |
| `07_calc_result_fraction` | `1÷3+1÷4` → 7⌟12 | same |
| `08_calc_syntax_error` | Syntax ERROR page (amber) | same |
| `10_menu_mode` | MODE menu | same |
| `11_setup` | SETUP (SHIFT MODE) | same |
| `20_ai_ready` | AI SOLVE home (MODE 4) | same (`App`) |
| `21_ai_hold_still` | `=`: HOLD STILL countdown | same |
| `22_ai_reading`, `23_ai_solving` | Waiting pages | same |
| `24`–`26_ai_answer_page1..3` | Claude's answer (x = 5, ✓ calculator agrees, steps), scrolled with ▼ | same |
| `30`–`35_status_*` | Status bar: Wi-Fi off / joining / connected, charging, 15 % (red), battery unknown | same, different `ui::Status` |
| `36_low_battery_ai_screen` | AI SOLVE at 6 %, AI locked out | same (`setLowBattery`) |
| `37_low_battery_notice` | BATTERY LOW notice after `=` | same |
| `40_off_charging` | Off with the cable in: "Charging 64%" | same (`drawOff`) |
| `41_off_blank` | Off, no cable (black) | same |
| `42_exam_mode_on`, `43_exam_mode_calc` | Exam mode (SHIFT 7 ON while off): red bar | same |
| `50_setup_by_phone`, `51_setup_by_phone_saved` | Setup-by-phone pages | `ui::showLines` with `main.cpp`'s strings * |
| `52`–`54_ota_progress_0/42/100` | Firmware update progress | `ui::showProgress` with `main.cpp`'s strings * |
| `55_ota_done`, `56_ota_failed` | Update result pages | `ui::showLines` * |
| `60_selftest_start` … `65_selftest_pass` | The whole factory self-test: colour bars + grey ramp + border, camera, Wi-Fi, key count, PASS | `selftestRun()` run whole, with stubbed sensors (every check passes) |
| `70_camera_starting` | Camera powering up | `vflcd::showStarting` |
| `71_camera_focusing` | Viewfinder: FOCUSING (amber), white brackets | `vflcd::showFrame` over the sample photo; box from core `Viewfinder` |
| `72_camera_focused` | FOCUSED (green brackets), amber box around the writing | same |
| `73_camera_hold_still` | Picture moved 14 px → core reports motion → HOLD STILL | same |
| `74_camera_careful_tutor` | Mode text "Careful +Tutor" | same |
| `75_camera_fixed_focus_timeout` | Fixed-focus module, 18 % battery (red), "off in 8s" | same |
| `sample_photo_320x240.png` | The made-up camera picture: a handwritten "3x + 7 = 22" on lined paper, made with Pillow, at the preview size | `make_screens.py` |
| `sheet_status_bar_variants.png` | The top 24 px of the status-bar screens, ×3, labelled | composed |
| `sheet_all_screens.png` | Contact sheet of every screen, ×2 | composed |
| `framed/front_*.png`, `framed/display_*.png` | 10 screens placed in the calculator window of `final_assembly_v15_lcd/renders/{front,display}_screen_key.png` | Same chroma-key corner fit as `compose_v15.py` (its functions are imported); slight lens tint |

\* `main.cpp` (Wi-Fi, FreeRTOS, OTA) is not compiled. Its `showLines` / `showProgress` calls are made with the same strings it passes. The network name and password are made up, in `setup_portal.cpp`'s format. The update version `v15lcd-2026.10.20` is invented.

## How these can differ from the real panel

- **Colour.** The PNGs show the RGB565 values exactly, expanded to 8 bits. The real IPS panel adds its own gamma, viewing angle and backlight level. Also, `LCD_INVERT`, `LCD_RGB_ORDER` and `PREVIEW_SWAP_BYTES` in `platformio.ini` are unconfirmed (see `PORT_NOTES.md`). If one is wrong on the real board, colours will be inverted or red/blue swapped until it is set.
- **Camera pictures.** The photo is synthetic, and it is fed in at the right size and byte order. A real OV5640 frame will have its own white balance, noise and sharpness, so the focus state and the writing box will vary. The fps (14.3) and the time-out are fixed inputs, not measured.
- **The cursor.** It blinks on the real screen. Every screenshot is taken in its "on" phase.
- **Fake time.** The self-test runs on a fake clock. The "86 s left" and the key count (`21 of 50`) are what a fast tester would see.

### Fixed in the firmware (2026-10-10)

The first run of these screenshots showed six UI bugs. They are fixed in `firmware-v15-lcd/src` (details in `firmware-v15-lcd/PORT_NOTES.md`, "UI fixes"):

1. √ printed as `?`, and ▲▼ scroll arrows never appeared: the decoder now knows core's replacement glyphs and icons. √ is drawn as a real radical sign; ✓ is green, ⚠ amber.
2. HOLD STILL countdown garbled: the 2× text is read back at 2× and shown as a large amber number.
3. Status bar overlaps: laid out from measured widths.
4. Text cut off at the right (soft keys, "Downloading …", self-test caption): measured, tighter spacing or fewer keys.
5. Viewfinder band collisions: measured layout; the mode or the Effort hint is left out when there's no room.

Before / after: `sheet_before_after.png` (every changed screen; the old images are in `before_fixes/`). Rebuild it with `python tools/ui_sim_v15/before_after.py` after `make_screens.py`.

Known trade-offs: the calculator soft key says `MODE 4 AI` (not "AI solve"), and the AI SOLVE home shows three soft keys (Effort ▲▼ and 1:Tutor are written on the page). With a fixed-focus module and a long mode such as "Careful +Tutor", the top band shows "FIXED" instead of "FIXED FOCUS".

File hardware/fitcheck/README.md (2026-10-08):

# Fit check: paper grind maps, dummy board, clearance table

> **Rev F (2026-10-06, `../verification/07_final_review_fitment.md`):** everything in this folder was regenerated. The maps now carry the Shell Grinding Guide's zone numbers (1 solar box, 2 rib B, 3 camera window, 4 LR44 cup = **keep**, 5 magnet notch, 6 antenna relief = only if needed), the **yellow ESP32 antenna tab** for the paper dry fit, and the battery at its rev E place (Adafruit #1317 on the back-cover floor). The old "LR44 cup: TRIM FLAT" line is gone; the cup is drawn green. Throw away older prints.

Regenerate everything after any board change: `"C:\Program Files\KiCad\10.0\bin\python.exe" tools/make_fitcheck.py` (KiCad's python, from `hardware/`). Inputs: `../kicad/ai_calc.kicad_pcb` (read only) and `backcover_fx115es.json` (ribs, rings, solar box, front-shell features, zone names, antenna tab).

## 1. Paper dry fit and grind maps (1:1)
- Print `grind_map_front_shell.svg` and `grind_map_back_cover.svg` from a browser at **100 % / actual size**. Measure the 50 mm line with the calipers; it must read 50 mm.
- **Front-shell map** = the paper dry fit (`../FINAL_STATUS.md` section 1). Cut along the board outline **together with the yellow antenna tab** (4.5 × 15.4 mm on the map's left edge = the ESP32 module's bare antenna PCB, 0.8 mm thick, 4.15 mm past the board edge). Punch out the post holes. Lay it in the front shell, printed side up, pressed onto the posts: every post inside its hole (H6 has the least play, 0.10 mm), and the tab lying flat beside the side wall. If the tab fouls the thin inner rib of that wall, that is grinding zone 6.
- **Orientation:** the map is drawn in KiCad coordinates (component side up). Lying in the front shell seen from the inside, the map's left edge (antenna, J3, solar-box parts) is the calculator's **right-hand side when you use it** (the solar-window side). "Left edge" in the board docs always means the map's / KiCad's left.
- **Back-cover map** is mirrored on purpose. Red dashed = ribs and rings; red filled = zones 1 and 2 to grind; the 7 mm circle with cross-hairs = zone 3 drill centre.
- Colour of the parts = height above the board (component side): red 4+ mm, orange 2–4, blue 1–2. The camera, the battery (rev E spot, under the board edge) and the magnet body are drawn dashed because they are not soldered to the board.

## 1b. Clearance table
- `clearance_table.md`: every component-side part, its height from its 3D model, the back-cover rib/ring/solar box above it, and the margin for 6.0 mm (design, D4) / 5.5 mm (pessimistic) of free height, plus after the grind plan. Bold = needs a grind. The LiPo row is informational (its real limit is the LR44 cup, 0.3 mm, see `../enclosure/final_assembly/assembly_report.md` section 9).
- The complete CAD check (every part vs every shell feature, closed case) is `../enclosure/final_assembly/clearance_table_full.md`.

## 2. Dummy board (3D print)
- `dummy_board.stl`: the full board at real size (outline, holes, 0.8 mm thick) with **every** part at its real height from the KiCad 3D models, including the ESP32 module with its antenna overhang (x 114.75), plus an 8.5 × 8.5 × 5.4 mm camera block on the board and a **loose 26.02 × 19.75 × 3.8 mm block for the #1317 battery** at its rev E place (KiCad x 152.59–178.61, y 60.36–80.11; it lies on the back-cover floor, not on the board). Tallest point: 5.5 mm above the board (battery socket J4).
- Print it flat, parts up, 0.2 mm layers, no supports.
- Marker test: colour the rib tops (and the ground zones), press the dummy onto the posts, put the battery block on the back-cover floor, close the back cover gently, open it. Marks on the dummy = plastic that still touches.

## Don't grind
Screw bosses (6), the 12 pegs, outer walls, window frame, key holes, the LR44 cup. Grind at low speed, a little at a time, keep the floor at least 0.8 mm thick, eye protection + mask. Zones 5b and 6 only if your shell needs them (pre-grind checklist in `../verification/07_final_review_fitment.md`).

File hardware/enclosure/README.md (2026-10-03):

# AI Calculator custom case (rev A concept)

> **Shell switch (2026-10-02):** Nirav now uses a **Casio fx-115ES** shell, not the fx-300ES Plus. Same key grid, but it has paired screw posts (not 12 pegs), stubs on the side walls beside the screen, and rings and ribs in the back cover. The geometry below is still from the fx-300ES scan: the post holes, outline and key pads must be re-derived from the new readings and a flatbed scan (measurement sheet C7–C15, F6) before ordering.

A 3D-printable replacement for the fx-300ES PLUS shell, generated in Fusion 360
straight from the KiCad board (`hardware/kicad/ai_calc.kicad_pcb`). The board
was laid out to drop into the original Casio shell; this case keeps every
Casio mounting point (screw posts, locating pegs, back-cover pins), so the same
board fits both.

| Front | Back | Exploded |
| --- | --- | --- |
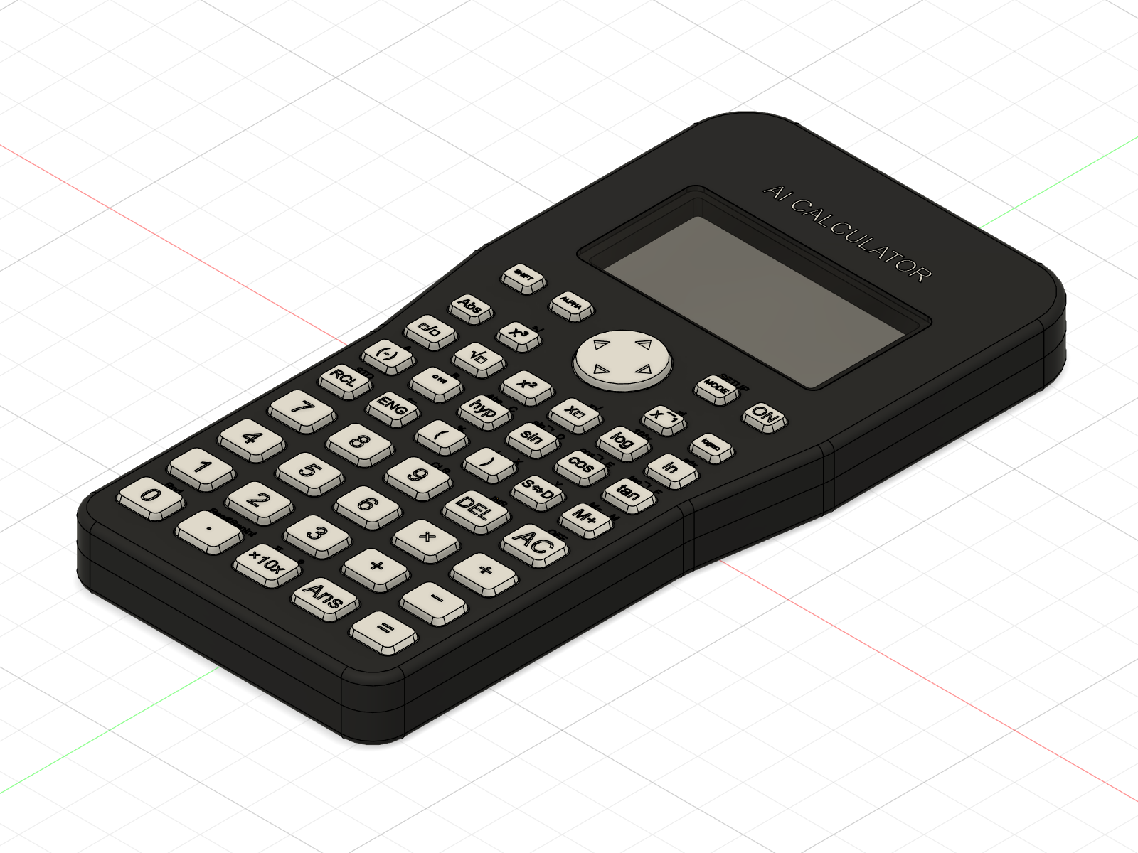
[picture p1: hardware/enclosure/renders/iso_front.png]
front
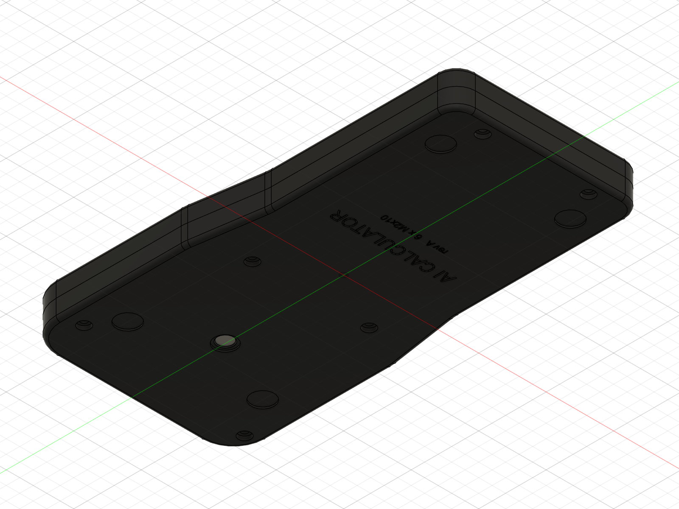
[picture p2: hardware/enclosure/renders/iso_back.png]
back
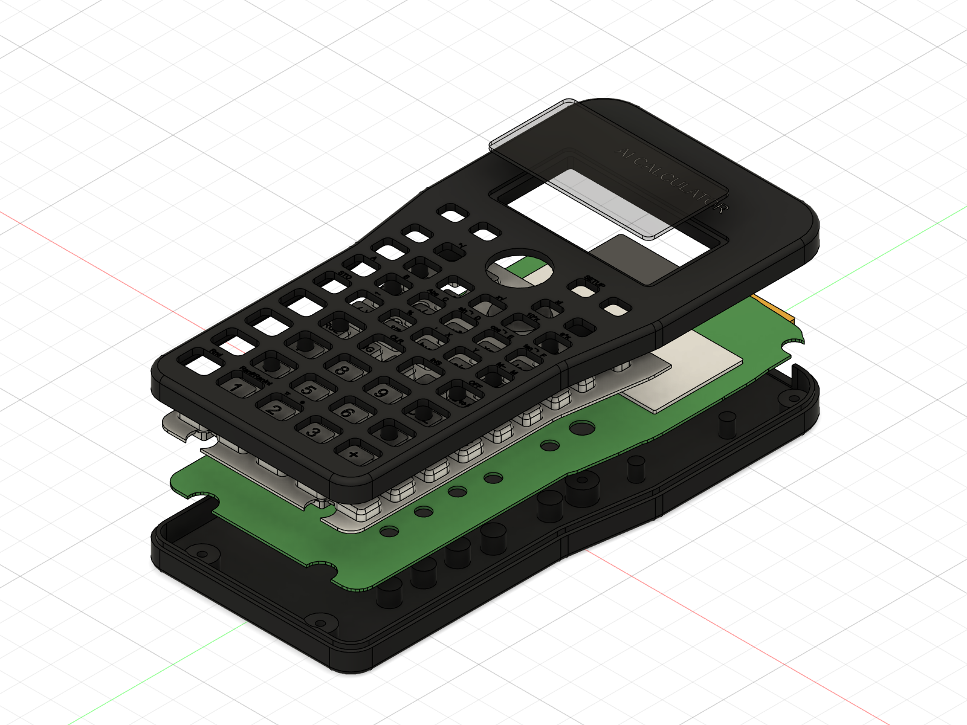
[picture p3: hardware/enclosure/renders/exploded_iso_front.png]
exploded
|  |  |  |

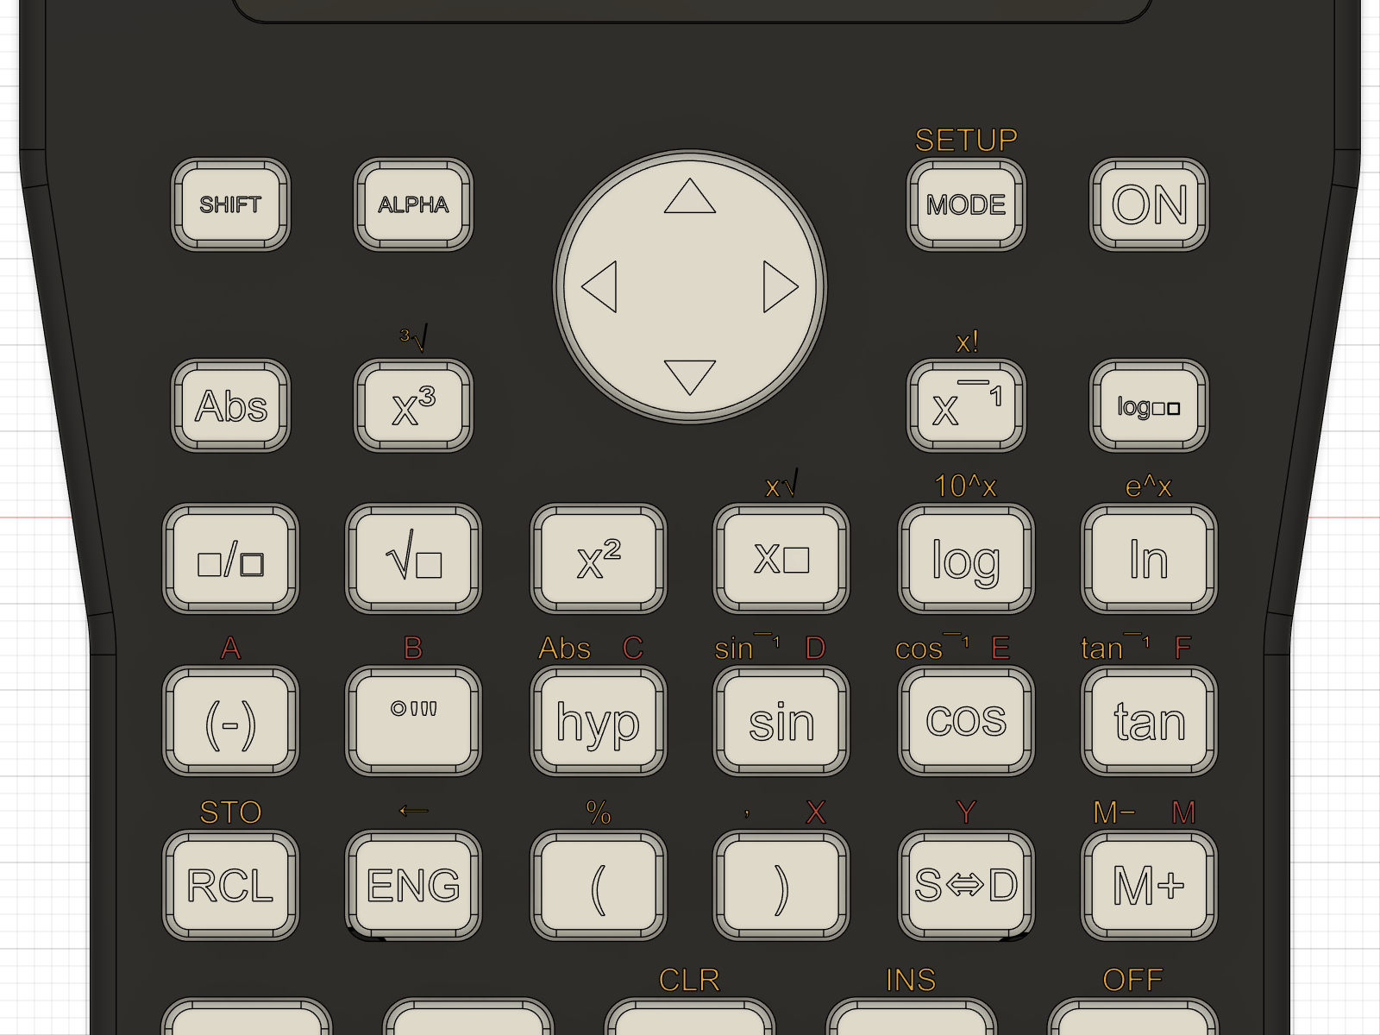
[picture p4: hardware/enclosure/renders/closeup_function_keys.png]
function keys close-up


| Section through display and camera | Section through REPLAY and keys |
| --- | --- |
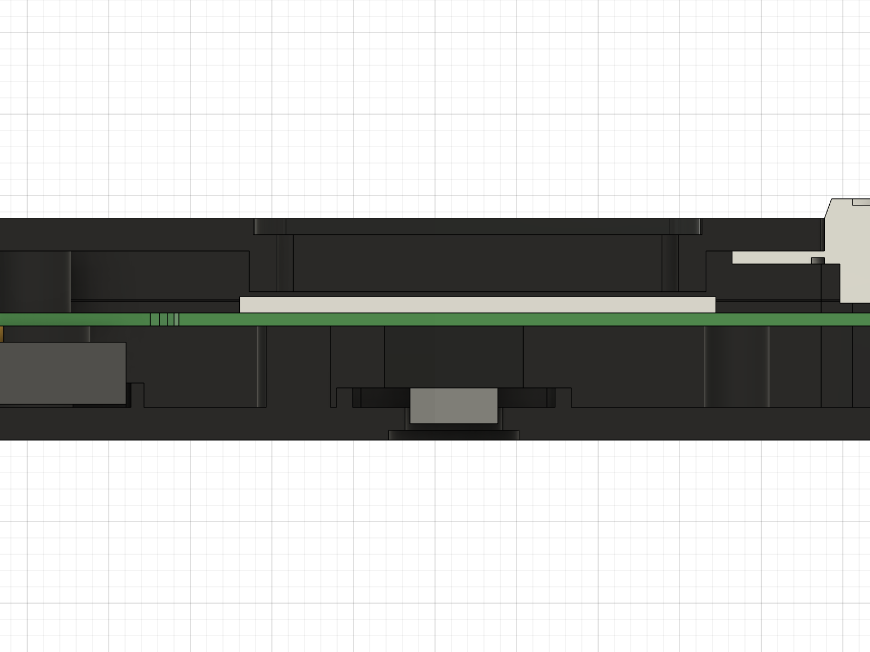
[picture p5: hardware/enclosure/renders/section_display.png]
display section
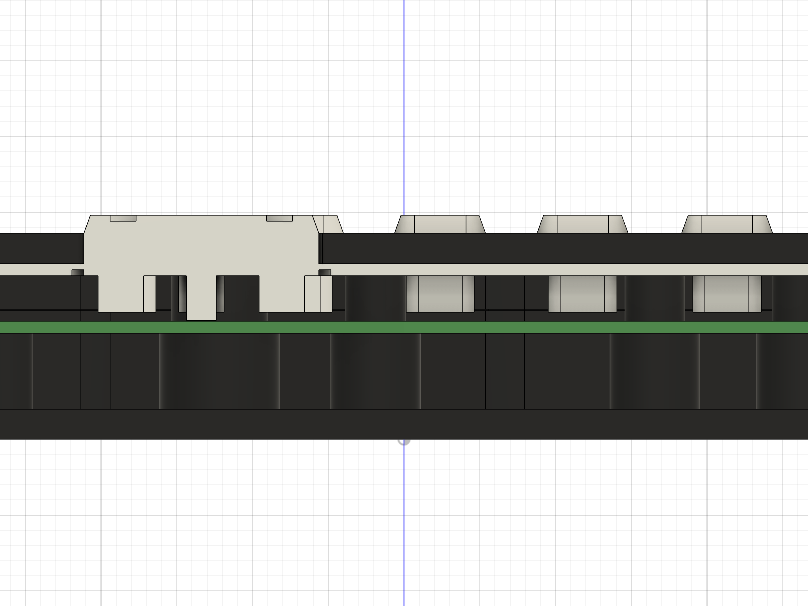
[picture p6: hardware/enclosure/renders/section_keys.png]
keys section
|  |  |

## fx-115ES shell (2026-10-03)
`build_case.py` now copies the **fx-115ES** shell, with no Casio branding:
- **Outline:** `fx115es_outline.json`, traced from Nirav's back-cover photo (fitted on its 6 screw holes, 0.31 mm RMS) and scaled to the caliper readings: **79.3 × 161.0 mm**, **13.8 mm** thick.
- **Screws:** six screws at the fx-115ES spots (row-1 pair, bottom pair, top corners from C11).
- **Pins:** locating pins at the real 3.85 mm post size.
- **Key openings:** the measured fx-115ES sizes, with oval top-row keys and a Ø 15.4 round pad.
- **Window:** 60.65 × 24.3 at the C13 position.
- **Solar window:** kept as a shallow decorative panel.
- **Label:** "AI CALCULATOR" where the Casio logo sits.

`python build_case.py` checks it offline (board-to-wall gap ≥ 0.5 mm, e-paper centred in the window). The 3D build needs Fusion open with the bridge add-in.

## What's in it

- **Casio silhouette** from the board: wide top, short taper, narrow bottom; 77.7 × 156.2 × 13.6 mm.
- **Two-part shell** split at the board's back face, with a 1.1 mm tongue-and-groove lip and 1.5 mm rounded edges.
- **Six M2 screws** at the original Casio screw posts (two through the board, two in its bottom notches, one in the LR44 notch, one in the battery cut-out), plus 10 locating pins through the board's Ø4.4 peg holes and 5 back-cover pins pressing the board under the display.
- **Display:** flush 1 mm acrylic lens in a front recess, window sized to the e-paper's active area (49.5 × 24.6 mm), and a frame that holds the panel against the board.
- **Keymat:** one TPU piece with 46 bevelled caps and a REPLAY rocker (centre pivot, four plungers). Each cap has a thinned hinge ring so the sheet flexes, a plunger 0.6 mm above its carbon pad, and a 0.3 mm debossed legend.
- **Face legends:** SHIFT functions (yellow) and ALPHA letters (red) above the keys, from the firmware's key table, debossed 0.25 mm and modelled as paint fill.
- **Back cover:** camera window with a chamfered bezel and a module guide, a LiPo cradle with a lead gap, a slot for the magnetic connector, counterbored screw holes, pockets for four 8 mm feet, and the label.
- **Interference check:** 0 overlaps between shells, keymat, lens, PCB, e-paper, battery, camera and connector.

## Regenerate

Fusion 360 must be open with the FusionMCPBridge add-in running
(`../../../fusion360-mcp-bridge`). The whole build takes about 3 minutes:

```bash
python build_case.py
```

```bash
python fusion_run.py build_case.py all
```

The first command is an offline check of the outline against the board; the
second runs every stage in order (shells, front, back, keymat, legends,
faceplate, parts, check, export) in a new Fusion document and closes earlier
builds. Single stages and pictures:

```bash
python fusion_run.py build_case.py stage=shots "views=iso_front,front,back,top@0;0;60"
```

```bash
python fusion_run.py build_case.py stage=section x=0.2 "views=left,detail@45;7;40"
```

```bash
python fusion_run.py build_case.py stage=explode gap=14
```

`gap=0` puts the exploded view back together. Progress goes to `build.log`
(the bridge stops waiting after 30 s, Fusion doesn't).

All dimensions are parameters at the top of `build_case.py`. Board features are
read from the KiCad layers each time, so moving a key pad or the camera in KiCad
moves it in the case too.

| KiCad source | Used for |
| --- | --- |
| `Edge.Cuts` | board outline, case outline (0.5 mm clearance + 2.2 mm wall), bottom screw notches |
| `KEYPADS` (User.2) | 46 key holes, caps and plungers, REPLAY pad |
| `KEEPOUTS` (User.3) | e-paper, active area, camera hole, battery bay, magnetic connector, 5 back-cover pins |
| `VERIFY` (User.1) | the two top screw positions |
| `Post_Hole_4.4` / `ScrewBoss_Hole_6.0` footprints | 10 locating pins, 2 middle screws |

## Parts

| Part | Make it from | Notes |
| --- | --- | --- |
| Front shell | PETG / ASA / resin, face down | 2 mm plate, flush lens recess, debossed name |
| Back cover | PETG / ASA / resin, outside down | 2 mm floor, lip that keys into the front shell |
| Keymat | TPU 95A | one piece: sheet + caps + plungers, thinned hinge ring round each cap |
| Lens | 1 mm clear acrylic, laser cut (`export/lens_1mm_acrylic.dxf`) | glue into the front recess |
| Screws | 6 × M2 × 10 pan head, self-tapping into plastic | from the back |
| Feet | 4 × 8 mm self-adhesive bumpers | pockets in the back |

## Stack-up (Z from the back face)

| Z (mm) | What |
| --- | --- |
| 0 – 2.0 | back floor (camera window, counterbores, feet pockets) |
| 2.0 – 7.0 | components on the board's back side: ESP32-S3, camera, battery (3.8 mm) |
| 7.0 | parting line = PCB back face; back bosses and posts stop here |
| 7.0 – 7.8 | PCB (0.8 mm) |
| 7.8 – 8.8 | e-paper (1.0 mm, check the real panel) |
| 8.4 | plunger tips (0.6 mm key travel to the pads) |
| 9.1 – 11.6 | display frame pressing the e-paper |
| 10.8 – 11.6 | keymat sheet |
| 11.6 – 13.6 | front plate |
| 14.8 | key cap tops (1.2 mm proud) |

Total 77.7 × 156.2 × 13.6 mm (the Casio is 80 × 161 × 13.8).

## Printing

| Part | Orientation | Settings |
| --- | --- | --- |
| Front shell | face down on a textured or smooth PEI sheet | 0.2 mm layers, 3 walls, 20 % infill; the face comes out flat and clean. Key holes and the lens recess need no supports. |
| Back cover | outside down | same; the lip prints upright, no supports |
| Keymat | sheet down | TPU 95A, 0.15 mm layers, slow (20–25 mm/s), 100 % infill; the plungers print on top of the sheet without supports. Legends are 0.3 mm deep: fill them with paint and wipe, or print with a colour change at Z = 14.5 mm. |

Resin printing gives a much nicer front face; scale nothing, all clearances are already in the model
(0.5 mm board-to-wall, 0.25 mm per side cap-to-hole, 0.1 mm on the lip).

## Assembly

1. Glue the 1 mm acrylic lens into the front recess (thin bead of UV glue or 0.1 mm VHB tape round the edge).
2. Drop the keymat into the front shell, caps through the holes. The locating pins and screw columns pass through its holes.
3. Fit the e-paper on the board, then lay the board face down on the pins (the ten Ø4.4 holes) so the display sits under the frame.
4. Battery into its cradle on the back cover, leads out through the gap at the right-hand end.
5. Close the back cover (the lip keys into the front shell's groove) and fit 6 × M2 × 10 self-tapping screws.
6. Stick four 8 mm bumpers into the pockets.

## Check on real hardware

Most of these come straight from the board's VERIFY layer; the case has a knob for each one.

| # | What | Where to change it |
| --- | --- | --- |
| 1 | E-paper module thickness (1.0 mm assumed) and whether the frame should press its glass or only its border | `EPD_T`, display frame in `stage_front` |
| 2 | Key travel: 0.6 mm from plunger to pad through a 0.4 mm TPU hinge. Print one row first. Too stiff: thinner hinge or wider ring; too loose / double presses: raise `TRAVEL`. | `TRAVEL`, hinge cut in `stage_keymat` |
| 3 | Magnetic connector height (V5). The slot is 22 × 6 mm in the top wall, Z 2.5 to 8.5. | magnet slot in `stage_back` |
| 4 | Camera module depth (V6). Back cavity is 5 mm; the guide ring assumes a 12 × 12 keep-out and a Ø6 lens window. | `cam_ko`, camera guide |
| 5 | Battery 3.8 mm thick (V3). The cradle gives 31.6 × 12.1 mm and 5 mm of height. | battery cradle |
| 6 | Tallest part on the back of the board (ESP32-S3-MINI-1 is 2.4 mm; the 5 mm cavity has room). | `Z_SPLIT`, `FLOOR` |
| 7 | BOOT button: no access hole yet because it isn't placed on the board. Add a Ø2 pin hole in the back once it is. | `stage_back` |
| 8 | Wi-Fi: the ESP32-S3 antenna works fine through plastic; keep any metal paint or foil off the case near it. | – |
| 9 | Screws: M2 self-tappers into 1.7 mm pilots. For many open/close cycles use M2 heat-set inserts (3.2 mm holes, change `PILOT_D`). | `PILOT_D` |
| 10 | **Key layout mismatch:** the board's second row is Abs, x³ │ x⁻¹, logₐb (the real fx-300ES PLUS), but the firmware key table (`sim/web/page.html` TOP) has x⁻¹, nCr │ Pol, x³. The case follows the board. Change one or the other before printing the keymat. | `FACE`, `LEGENDS`, firmware key table |
| 11 | Small legends: SHIFT/ALPHA/MODE caps get ~1 mm text and the face labels are 1.3 mm. That's fine for resin or paint fill, marginal on FDM. | `FACE_H`, `glyph_width` |

Material (solid volume): front shell 19.9 cm³ (≈25 g PETG solid, ~15 g printed),
back cover 30.6 cm³ (≈39 g solid, ~22 g printed), keymat 16.4 cm³ (≈20 g TPU).

## Files

| File | What |
| --- | --- |
| `build_case.py` | the whole design, generated from KiCad (parameters at the top) |
| `fusion_run.py` | sends a script to Fusion through the FusionMCPBridge add-in |
| `export/ai_calc_case.step` | full assembly (shells, keymat, lens and reference parts) |
| `export/ai_calc_case.f3d` | Fusion archive with the timeline (open in Fusion, edit any feature) |
| `export/*.stl` | print files |
| `export/lens_1mm_acrylic.dxf` | laser-cut file for the window |
| `renders/` | screenshots of the current build |

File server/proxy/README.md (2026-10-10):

# AI Calculator proxy

A small web server that sits between the calculators and Claude. **It holds the Claude API key; the
calculators never do.** Each calculator has its own device token instead.

```
calculator --(HTTPS, device token)--> proxy --(HTTPS, API key)--> Claude API
```

What it does for every AI solve:
1. Checks the device token (stored only as a hash; revocable).
2. Checks the calculator is linked to an account, and the account's subscription: **trial** (first month
   free from linking, one free month per calculator), **active**, **past_due** (card failed: a few days'
   grace), **canceled**. Optional free tier: `FREE_DAILY`.
3. Enforces fair use: a monthly cap per tier (`MONTHLY_CAP` 500 base, `PRO_MONTHLY_CAP` 280 pro) and
   per-calculator burst limits (1 solve at a time, 4 a minute, 40 an hour). Only finished answers count.
4. Keeps only the photos and the short instruction from the calculator's request. **The system prompt and
   the JSON schema are the server's** (`prompts/solver_v1.txt`, `prompts/solver_v1.schema.json`), so a
   prompt fix needs no firmware flash and a stolen token can't be used for anything but photo solves.
   The v15 firmware no longer uploads `system` at all (`CALC_SEND_SYSTEM_PROMPT=0`, about 5 KB less per
   solve); the v14 firmware still does, so it also works with an older proxy. `PROMPT_SOURCE=device`
   (bench testing the prompt in `core/claude_api.cpp`) needs a firmware built with `-DCALC_SEND_SYSTEM_PROMPT=1`.
5. Picks the model by tier and streams Claude's reply back event by event, with a `: ping` comment every
   15 s while Claude thinks, so the calculator's 120 s idle timeout never fires.

**Models** (prices from the Claude API price list; per-user costs from
`hardware/production/UNIT_ECONOMICS.md`):

| Tier | Model | $ per M tokens in / out | Typical user / month | At the cap |
| --- | --- | --- | --- | --- |
| base (the $15 plan) | `claude-sonnet-5-5` | $2 / $10 | about $3.77 | $12.40 at 500 |
| pro (optional) | `claude-opus-5-5` | $4 / $20 | about $7.52 | about $13.84 at 280 ($24.72 at 500) |

- **Fallback:** if the tier's model answers 429 / 5xx / 529 overloaded (or can't be reached), the proxy tries
  the other model once before the calculator shows "busy" (`MODEL_FALLBACK=1`).
- **Prompt caching:** the fixed system prompt (about 1,500 tokens) carries a `cache_control` breakpoint, so
  repeat solves within 5 minutes read it from the cache at a tenth of the input price. The log line of
  every solve shows `cache_read=` / `cache_write=` so you can see it working.
- **Refusal fallback** (`REFUSAL_FALLBACK=1`): the Claude API's server-side fallback (beta
  `server-side-fallback-2026-07-01`, `fallbacks: "default"`), so a harmless homework photo that a safety
  filter declines is answered by another model instead of showing an error. Set 0 if your account rejects it.
- Effort is always sent explicitly (Opus 5.5 would otherwise default to `medium`).
- Optional **Haiku-first routing** (`ROUTING=haiku-first`): tries `claude-haiku-4-5` first and keeps its
  answer only if it is confident and clean.

## Files

| File | What |
| --- | --- |
| `app.py` | the web server (FastAPI): every endpoint, request ids, the SSE relay with keep-alive |
| `solve.py` | checks the calculator's request, the server's prompt, model routing + fallback, prompt caching |
| `policy.py` | who may solve: link, subscription state, tier cap, free tier (messages shown on the calculator) |
| `limits.py` | per-calculator burst limits (in memory: run one worker) |
| `linking.py` + `mailer.py` | the e-mail confirmed link flow (signed, short-lived tokens; SMTP) |
| `billing.py` | Stripe-signed webhook check + subscription events -> accounts |
| `db.py` | SQLite: devices, accounts, pairing codes, usage, billing events (adds new columns itself) |
| `logs.py` | request ids and redaction (no tokens, keys, photos or links in the log) |
| `firmware.py` | over-the-air updates: the published image + manifest, board-family check |
| `admin.py` | command line: devices, tiers, accounts, paid, prompt version, firmware publish |
| `prompts/` | the versioned system prompt and JSON schema |
| `config.py` + `.env.example` | every setting |
| `test_proxy.py`, `test_hardening.py` | tests: `python -m pytest -q` (offline: a fake Anthropic client, no key) |

## Run it on your PC (to try it)

```
cd server/proxy
python -m venv .venv
.venv\Scripts\activate            (Windows)      or   source .venv/bin/activate
pip install -r requirements.txt -r requirements-dev.txt
python -m pytest -q                (all tests, no network)
copy .env.example .env             then edit .env: ANTHROPIC_API_KEY, LINK_SECRET; MAIL_BACKEND=console
python admin.py new-device "board 1"
uvicorn app:app --port 8000
```
On your PC, `MAIL_BACKEND=console` plus `MAIL_LOG_LINKS=1` prints the confirmation link in the terminal
instead of sending an e-mail (never on the real server). The calculator needs **HTTPS**, so for a real
test use a hosted option below (or `cloudflared tunnel --url http://localhost:8000`).

## Deploy (Render, Railway or Fly.io)

The `Dockerfile` is ready (Python 3.12, non-root user, **one** uvicorn worker: the burst limiter is in
memory and SQLite has one writer; one small instance serves thousands of calculators because each solve
mostly waits for Claude).

1. **Create the service from this folder** (`server/proxy`):
   - **Render:** New -> Web Service -> your repo, Root Directory `server/proxy`, Runtime Docker. Add a
     **Disk** mounted at `/data` (1 GB is plenty). Instance: Starter. Health check path `/healthz`.
   - **Railway:** New Project -> Deploy from repo, set the service's Root Directory to `server/proxy`.
     Add a **Volume** mounted at `/data`.
   - **Fly.io:** `cd server/proxy`, `fly launch --no-deploy` (internal port 8000), then
     `fly volumes create data --size 1` and in `fly.toml` add `[mounts] source="data" destination="/data"`.
     Keep exactly one machine (`fly scale count 1`). `fly deploy`.
2. **Set the environment variables** in the host's dashboard (Render: Environment; Railway: Variables;
   Fly: `fly secrets set NAME=value`). Never in git. The required ones are in the table below.
3. Open `https://<your address>/healthz`: `{"ok": true, "version": ...}`. That address is your `PUBLIC_URL`
   (set it, redeploy).
4. **Stripe:** Developers -> Webhooks -> add endpoint `https://<your address>/v1/billing/webhook`, events
   `checkout.session.completed`, `customer.subscription.created`, `customer.subscription.updated`,
   `customer.subscription.deleted`, `invoice.paid`, `invoice.payment_failed`. Copy its signing secret
   (`whsec_...`) into `STRIPE_WEBHOOK_SECRET`. In Checkout, pass the customer's e-mail (or
   `metadata.email`) and start the subscription with `subscription_data.trial_end` = the account's `trial_ends_at` (the
   first month is already free on the proxy). Give the pro price the lookup key `calc_pro_monthly` (or
   list yours in `PRO_PRICE_KEYS`).
5. Set a **monthly spend limit** on the Claude Console (last line of defence).

The calculator trusts Let's Encrypt, Google Trust Services, DigiCert and Amazon certificates, which covers
all three hosts.

## Environment variables

Required in production:

| Variable | What |
| --- | --- |
| `ANTHROPIC_API_KEY` | the Claude API key (only here) |
| `PUBLIC_URL` | the proxy's https:// address (shown with the pairing code, used in e-mails) |
| `LINK_SECRET` | 32+ random characters (`python -c "import secrets;print(secrets.token_urlsafe(32))"`): signs the e-mail links |
| `MAIL_BACKEND=smtp`, `SMTP_HOST`, `SMTP_PORT`, `SMTP_USER`, `SMTP_PASSWORD`, `MAIL_FROM` | where the confirmation e-mails go out (any SMTP provider: Postmark, Resend, SES, Mailgun...) |
| `STRIPE_WEBHOOK_SECRET` | the webhook's signing secret (`whsec_...`) |

Useful knobs (defaults in brackets): `BASE_MODEL` [claude-sonnet-5-5], `PRO_MODEL` [claude-opus-5-5],
`MODEL_FALLBACK` [1], `CLAUDE_MAX_RETRIES` [1 per model], `PROMPT_CACHE` [1], `REFUSAL_FALLBACK` [1],
`ROUTING` [main], `PROMPT_SOURCE` [server], `SYSTEM_PROMPT_FILE` / `SCHEMA_FILE` [prompts/solver_v1.*],
`MONTHLY_CAP` [500], `PRO_MONTHLY_CAP` [280], `TRIAL_DAYS` [30], `PAST_DUE_GRACE_DAYS` [3], `FREE_DAILY` [0],
`SOLVE_CONCURRENCY` [1], `SOLVES_PER_MINUTE` [4], `SOLVES_PER_HOUR` [40], `OTHER_PER_MINUTE` [30],
`LINK_PER_MINUTE_PER_IP` [10], `KEEPALIVE_SECONDS` [15], `LINK_MODE` [email], `LINK_CONFIRM_MINUTES` [30],
`PAIR_CODE_MINUTES` [15], `WEBHOOK_TOLERANCE_S` [300], `PRO_PRICE_KEYS`, `ADMIN_TOKEN` [off],
`DB_PATH` [/data/proxy.db in Docker], `FIRMWARE_DIR` [/data/firmware in Docker], `APP_VERSION`, `LOG_LEVEL`.
`MAIN_MODEL` still works as the old name of `BASE_MODEL`.

## Admin commands

Run them in the host's shell so they use the database on `/data` (Render: the service's **Shell** tab;
Fly.io: `fly ssh console`, then `cd /app`; Railway: the service's shell / `railway ssh`).

```
python admin.py new-device "Nirav board 1"      a device token, shown ONCE (type it into the calculator: token)
python admin.py devices                         every calculator, its account, revoked?
python admin.py revoke dev_1a2b3c               a lost calculator stops working at once
python admin.py tiers                           models (with fallback), caps and limits per tier
python admin.py tier someone@example.com pro    move an account to pro (Opus) or base (Sonnet)
python admin.py account someone@example.com     subscription state, tier, solves this month
python admin.py paid someone@example.com 2026-12-31   mark paid by hand (without Stripe)
python admin.py usage                           solves per account this month
python admin.py prompt                          the prompt version the proxy sends (also in every solve's log line)
python admin.py firmware <firmware.bin> <version>   publish an over-the-air update for that version's board family
python admin.py firmware                        what is published now, per board family
```
With `ADMIN_TOKEN` set, devices can also be created over HTTP:
`curl -X POST "https://<proxy>/v1/admin/devices?label=board%201" -H "x-admin-token: <ADMIN_TOKEN>"`.

**Changing the prompt:** add `prompts/solver_v2.txt` (and a schema file if the reply format changes, which
also needs a firmware change), set `SYSTEM_PROMPT_FILE`, redeploy. The version (`solver_v2+<hash>`) shows
in every solve's log line.

## Set up a calculator

1. `python admin.py new-device "..."` on the server -> copy the token.
2. Calculator on USB, Serial Monitor: `proxy` -> paste `https://your-proxy-address`; `token` -> paste the
   token; `wifi` -> hotspot name and password (or the phone setup page, `firmware-prototype/README.md` §2).
3. Link it: `pair` prints a 6-letter code (an unlinked calculator also shows it when you try an AI solve).
   Open `https://your-proxy-address/link`, type the code and your e-mail. **Open the e-mail and press the
   button**: only then is the calculator linked and the free month starts.
4. `account` on the calculator shows the subscription, tier and solves used this month.

## Firmware updates over the air

Switched off on a cable, a calculator asks `GET /v1/firmware` (device token, its version in `x-firmware`);
when the answer is `"update": true` it downloads `/v1/firmware/image`, checks the SHA-256 and installs it
into its second app slot (rollback if the new one crashes). The board family (`stage14-...` = v14 e-paper,
`v15lcd-...` = v15 LCD) must match, on the manifest and on the image download.

```
python admin.py firmware ../../firmware-prototype/.pio/build/prototype/firmware.bin stage14-2026.10.10
python admin.py firmware ../../firmware-v15-lcd/.pio/build/v15lcd/firmware.bin v15lcd-2026.10.10
python admin.py firmware          (what is published, per family)
```
One image **per board family** (`FIRMWARE_DIR/<family>/firmware.bin` + `firmware.json`; the version's part
before the first `-` picks the folder), so v14 and v15 calculators can be offered updates at the same time;
publishing one family's build never touches the other's. A calculator is only ever offered, and only ever
downloads, its own family's image (by `x-firmware`, which every firmware sends); a request without
`x-firmware` gets the image only when exactly one family has one. An image published by an older proxy
(`FIRMWARE_DIR/firmware.bin`) is still served to its own family until that family is published again.

## Errors the calculator understands

`401 device_unknown`, `402 device_not_linked` (message carries the pairing code), `402 subscription_inactive`
(free month over / payment failed / subscription ended), `429 fair_use_exceeded` (monthly cap),
`429 rate_limited` (burst limits, with `retry-after`), `429 free_tier_exhausted`. The calculator shows these
messages (<= 110 characters). `503 overloaded_error` (and an SSE `error` event if Claude drops mid-answer)
shows "busy".

`rate_limited` is only shown by firmware of 2026-10-10 or later (`core/claude_api.cpp` classifyFailure).
The rule (`policy.rate_limit_error_type`): if `x-firmware` reads `<family>-YYYY.MM.DD...` with a known family
(`stage14`, `v15lcd`) and a date on or after `RATE_LIMITED_SINCE` (2026.10.10 for both), the burst limit is
sent as `rate_limited`; anything else (older builds such as `stage14-2026.10.06` / `v15lcd-2026.10.08`, an
unknown board, no or unreadable header) gets `fair_use_exceeded` with the same message, which every
firmware displays. Guessing "old" is always safe; only the type name differs.

**Early failures are retried:** if Claude's stream fails before the first content event (an `error` event
such as `overloaded_error` / `api_error` / `rate_limit_error`, or the connection drops / ends right after
`message_start`), the proxy has only sent `: ping` comments so far, so it quietly opens the request again on
the other model (`MODEL_FALLBACK`). Once content has started, a failure is passed on as before ("busy"): the
calculator has already shown part of the answer and its `StreamReader` appends text, so a second answer
would be glued onto the first (and the first one's tokens are already paid for).

## Security checklist (before selling)

- [ ] `ANTHROPIC_API_KEY`, `LINK_SECRET`, `STRIPE_WEBHOOK_SECRET`, `SMTP_PASSWORD`, `ADMIN_TOKEN` only in the
      host's secret settings; `.env` and `api_key.txt` are git-ignored, never copied anywhere.
- [ ] Spend limit set on the Claude Console; usage alerts on.
- [ ] `LINK_MODE=email` (default) and SMTP working: link a test calculator end to end.
- [ ] Stripe webhook test event returns 200; an edited payload returns 400.
- [ ] `ADMIN_TOKEN` empty unless needed (admin.py in the host shell is enough).
- [ ] One instance, one worker, a volume on `/data`; back up `/data/proxy.db` (Render/Fly snapshots).
- [ ] `/healthz` shows only ok/version; the logs show device ids, models and token counts, never tokens,
      photos, answers or e-mail links (checked by the tests).
- [ ] Revoke lost calculators with `admin.py revoke`.
- [ ] Root CA bundle in the firmware refreshed before 2031 (DigiCert Global Root CA expiry).

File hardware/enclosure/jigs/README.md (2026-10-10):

# Grinding jigs (3D-printed) for the donor fx-115ES shell

These jigs make the per-unit grinding faster and the same every time. Estimated hand time per unit drops from
**≈ 25–34 min freehand to ≈ 9–11 min** (details: `../final_assembly/battery_upgrade.md`, section 3).
They were modelled **in place on the rev D shell**, then checked in Fusion: each jig has **0 mm³ overlap** with the part
it sits on and rests on it with 0.0 contact (`jigs_check.json`).

| File | Jig | Used for | Print |
| --- | --- | --- | --- |
| `A_back_cover_plate.stl` | **A: back-cover plate** | zones 1 (solar box) + 2 (rib B), and holding A2 | PETG/PLA, 0.2 layers, 4 walls; print with the pins pointing UP |
| `A2_camera_drill_bush.stl` | **A2: camera drill bush** | zone 3 (7 mm camera window), the 2 mm pilot | flange down, 100 % infill round the hole |
| `A3_depth_gauge_7_2.stl` | **A3: depth gauge, 7.2 mm** | sets the Dremel router bit for A | flat |
| `B_magnet_notch_saddle.stl` | **B: magnet-notch saddle** | zone 5 (+ 5b lip) in the grinding guide (U-notch 21.5 × 7.95 in the top wall) | bridge face down, supports off |
| `C_LR44_trim_sled.stl` | **C: LR44 trim sled** | battery upgrade only: holder tips cut 1.9 mm | knob down |

Rebuild / re-export (Fusion open, final assembly built with `python ../build_final_assembly.py new shell grind pcb parts mask`):
```
python ../fusion_run.py build_jigs.py stage=build      # builds component "Jigs", checks, exports the STLs + renders
python ../fusion_run.py build_jigs.py stage=remove
```
All sizes are parameters at the top of `build_jigs.py`; printed fit clearance against the shell is 0.15 mm.

---

## A + A2 + A3: back-cover plate (solar box, rib B, camera window)

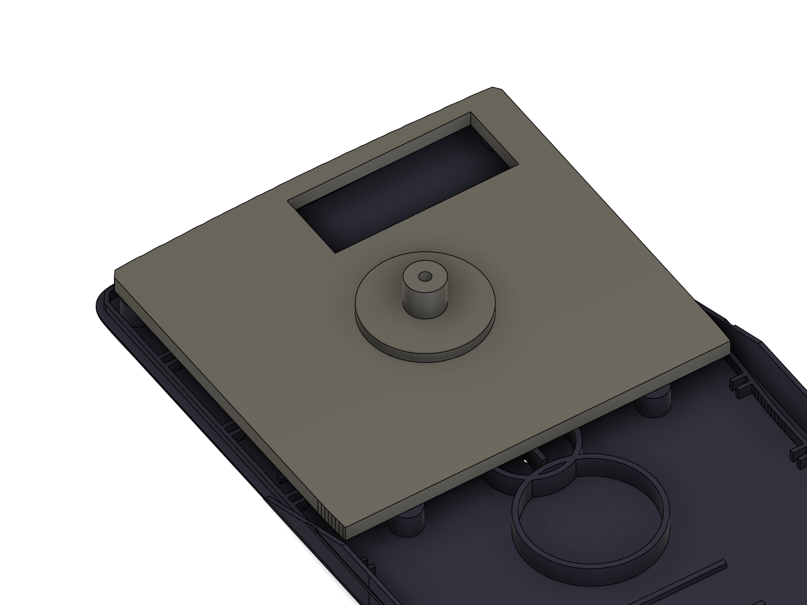
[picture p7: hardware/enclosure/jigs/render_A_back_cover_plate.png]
A on the back cover


**What it is:** a 3 mm plate shaped like the inside of the navy back cover (0.8 mm inside its lip, from the top end
down to 12 mm above the centre line). It **rests on the 4 upper screw bosses** (tops at Z 5.4) and registers with
**four Ø2.0 × 3 mm pins in the bosses' Ø2.2 screw holes** (corner L/R, mid L/R). It has two openings:
- **solar-box window** = the zone 1 outline exactly (front X −4.8…29.8, Y 62.1…75.7, i.e. the frame + grid + 0.8);
  on the part that is the outer frame (6.3–19.3 mm down from the back cover's own top outer edge, straight down at
  the middle of the box) plus about 0.3 mm all round;
- **Ø16 hole** on the camera centre (front X 0, Y 43.84 = 38.0 mm down from the back cover's own top outer edge, on
  the centre line; datums as in the grinding manual, 2026-10-10). It also covers the rib B zone (rib B runs through the camera centre).

**Router depth:** the plate's top is Z 8.4, the floor's top Z 1.0. Stand the Dremel router base (Dremel 335 plunge
attachment or similar) on **A3**, plunge until a **3.2 mm flat-end straight bit** touches the bench, and lock it.
The bit now ends **7.2 mm below the base**, i.e. **0.2 mm above the floor** when the base rides on plate A.

**Steps (≈ 4.5–6.5 min per back cover):**
1. Drop A into the back cover (pins into the 4 boss holes).
2. Solar box: run the router inside the window. The bit shank against the window wall is the fence. Then remove A
   and sand the 0.2 mm skin flat with a sanding block (the floor stays 1.0 mm).
3. Rib B: router inside the Ø16 hole across the rib (it takes 16 mm of rib instead of the 14 mm minimum; fine).
   Scrape the last 0.2 mm off with a flat chisel blade. The camera has to sit flat on the floor.
4. Camera window: put **A2** into the Ø16 hole (flange on top), drill **Ø2.0 straight down** through the bush, remove the
   jigs, then open the hole **from the outside with a step drill to 7 mm** (it centres on the pilot). Deburr.

## B: magnet-notch saddle

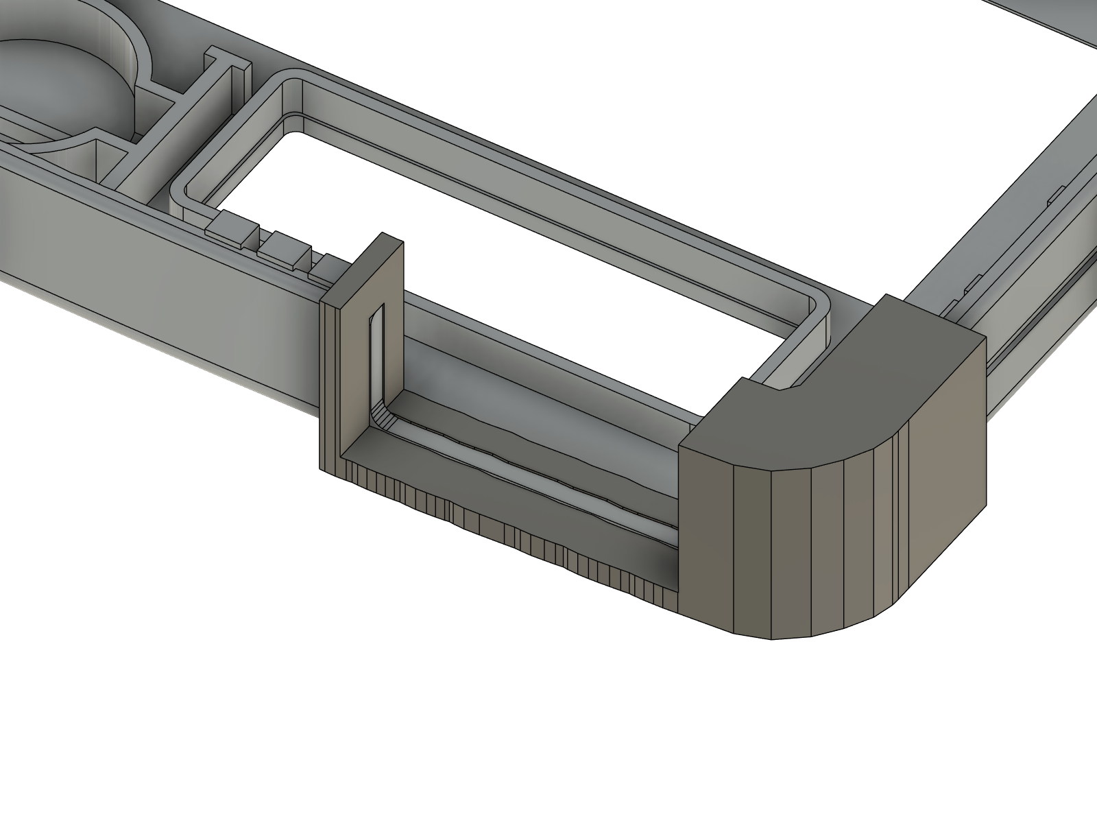
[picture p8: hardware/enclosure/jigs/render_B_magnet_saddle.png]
B on the faceplate


**What it is:** a saddle that clips over the silver faceplate's **top wall** with the faceplate face down on the bench.
- **Bridge** (3 mm) rests on the rim (the parting-line face).
- **Outer leg** (3 mm) hugs the outside of the top wall and **wraps round the right-hand top corner** down to front Y 68.
  That sets the X position; no measuring.
- **Inner leg** (2 mm) hugs the inside of the wall between the comb snap tabs (it starts at X 10, they end at X 9.5) and
  the corner screw post.
- **Window** = the U-notch: 21.5 wide, centred at front X 22.5 (6.4–27.9 mm in from the right outer edge),
  **7.95 deep from the rim**.

**Steps (≈ 4–5 min):** clip B on. Saw down both window edges with a fine razor saw, to the window bottom. Cut the
bottom with flush cutters and file flat to the window's bottom edge (light strokes: PLA wears). Round the two inner
corners (r 1). Then cut the **navy back cover's lip** behind the notch to the same width with two snips (≈ 0.5 min).

## C: LR44 trim sled (battery upgrade only)

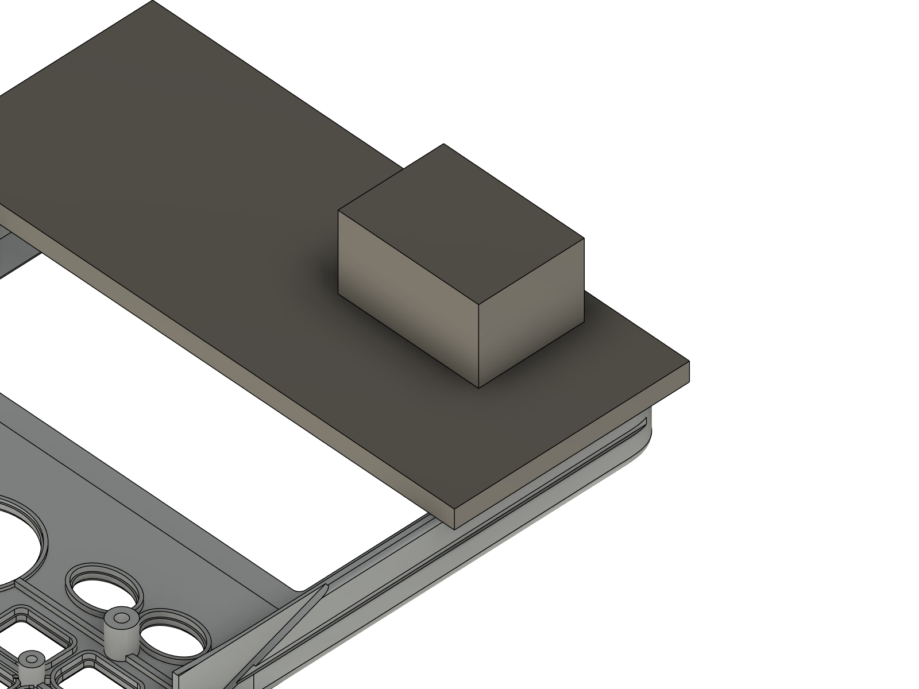
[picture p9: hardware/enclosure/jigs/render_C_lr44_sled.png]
C on the faceplate


**What it is:** an 84 × 35.6 × 3 mm sled that rides on the faceplate rim (wider than the faceplate, so it always spans
both side walls), with a **tongue** under it over the LR44 holder and a knob on top. Fill the tongue with **P120
sandpaper on double-sided tape (≈ 0.6 mm in total)**. The abrasive then ends exactly **5.5 mm below the rim** (Z 7.0).
The tongue is 2.5 mm smaller than the zone in X and 1.5 mm in Y, so you scrub ±2.5 / ±1.5 mm and cover the whole
holder. A relief clears the comb snap teeth at the top.

**Steps (≈ 1–1.5 min):** scrub with small strokes until the sled sits flat on the rim at both side walls. Blow off the
dust. The holder now ends 1.9 mm lower (3.6 mm tall). Nothing else of the faceplate is inside the tongue's reach:
the solar frame stops 1.1 mm short of the abrasive.

---

## Time summary (per unit, estimates)

| Zone | Freehand | With jig |
| --- | --- | --- |
| 1 solar box | 8–12 min | 3–4 min |
| 2 rib B | 2 min | 0.5–1 min |
| 3 camera window | 4–5 min | 1–1.5 min |
| 5 + 5b magnet notch (+ lip) (grinding-guide numbers) | 10–15 min | 4–5 min |
| **Total today** | **≈ 25–34 min** | **≈ 9–11 min** |
| 4a LR44 trim (optional, battery upgrade only; the guide's zone 4 = cup kept) | 4–6 min | 1–1.5 min |
| 6 side-wall relief (only if the paper template won't drop in on the solar-window side; no jig: a needle file, 35 mm of a 1 mm rib) | 3–5 min | — |

Print the jigs in PETG if you can: PLA softens where the Dremel bit rubs the window walls. Check jig A's window walls
after ~20 units and reprint when they're worn.

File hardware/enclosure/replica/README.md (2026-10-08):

# fx-115ES shell replica (unbranded)

> **Stage 14 note:** the fit-check lines about cutting the LR44 cup are superseded: the battery lies on the back-cover floor, so the cup stays. See `../../FINAL_STATUS.md`.

A 3D model of the Casio fx-115ES calculator case, made in Fusion 360 from your caliper readings
(two batches: stage 10 and `hardware/measurements_2026-10-03.md`), your photos and the key positions
on the KiCad board. It has **no logo, no model name and no key labels**. It is for checking fit (will
our board, display and camera fit the real shell?) and as a starting point for a printed case.

**Rev C2 (2026-10-05):** the split between the two body parts now follows Nirav's photos: the **silver faceplate** is deep only in the screen section (it forms the top wall) and is a faceplate with a short skirt round the keypad and the bottom end; the **navy back cover**'s walls rise along a ramp from the small ring to the big ring and form the side walls round the keypad and the bottom end. Proper silver / navy colours. The placeholder slide cover is replaced by the **navy slide case** (a separate part, stored over the face here; guessed sizes). A shallow rail groove along both long sides is a guess (no photo shows one). Photo-by-photo notes: `photo_notes.md` (rev C section). Interference: 0 (with the case on).

**Rev B (2026-10-03):** rebuilt on the second batch of caliper readings. Main changes: the thickness
is now 11.8 at the top part and 11.3 at the keypad (it was 13.8, wrong); the board's component side is
6.0 above the inside of the back floor (D4) and 5.5 below the front shell's rim (D1), so the parting line is
1.5 from the back (rev B2, from Nirav's answers); the posts are placed from C8/C9/C10/C15; the side-wall stubs, the wire holders,
the LR44 cup and the 4 × 2 solar box are modelled at their measured sizes; rib and ring heights come
from D13. A new **fit check** puts our real PCB (STEP) into the replica and lists every collision
(`fitcheck_report.md`).

| Front | Back | Exploded |
| --- | --- | --- |
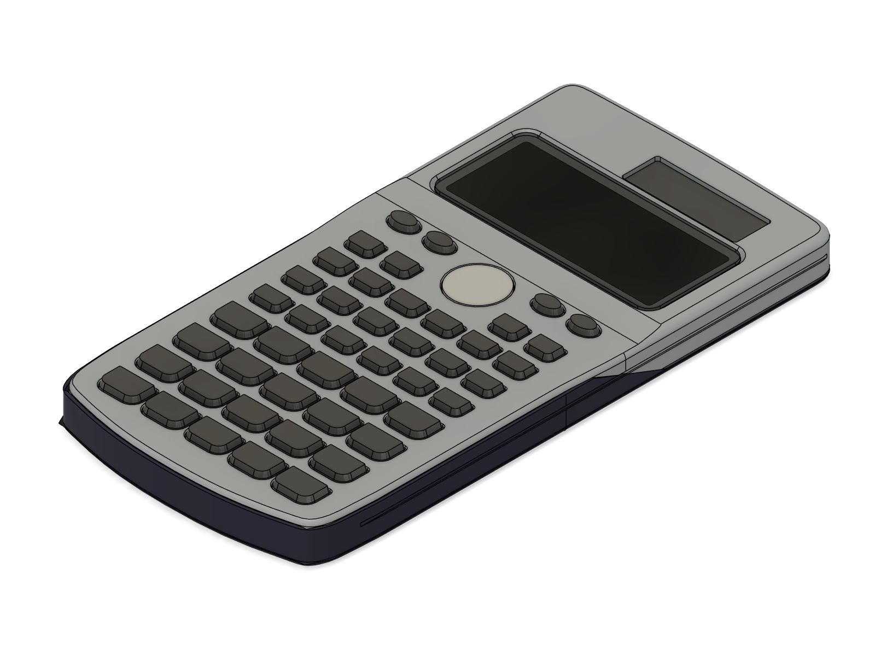
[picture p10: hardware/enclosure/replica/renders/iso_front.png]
front
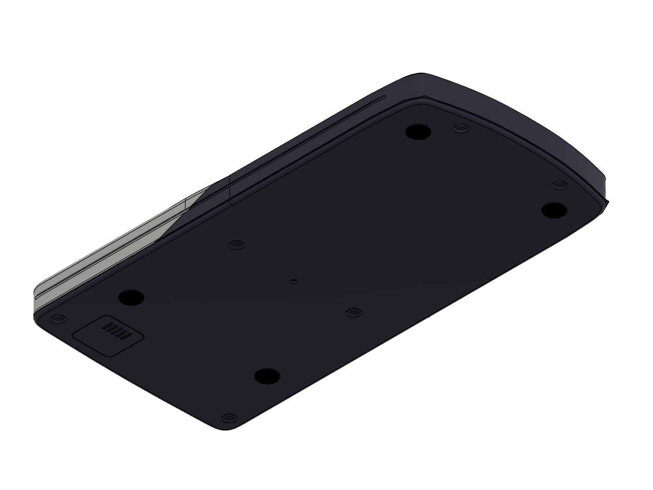
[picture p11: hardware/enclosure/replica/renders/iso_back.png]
back
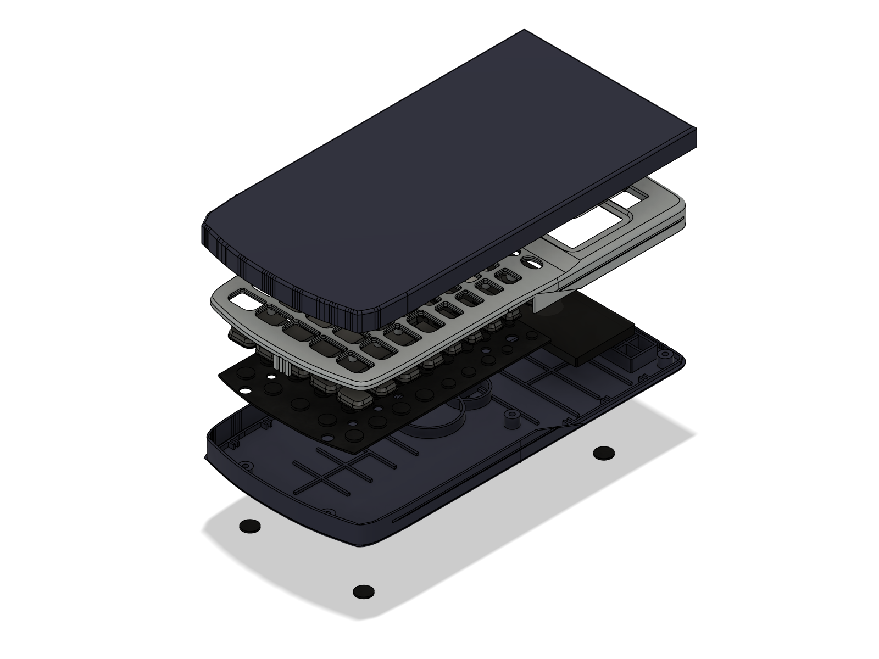
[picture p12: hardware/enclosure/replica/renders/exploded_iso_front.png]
exploded
|  |  |  |

| Side (split line ramps up along the keypad) | Other side | With the slide case (stored) |
| --- | --- | --- |
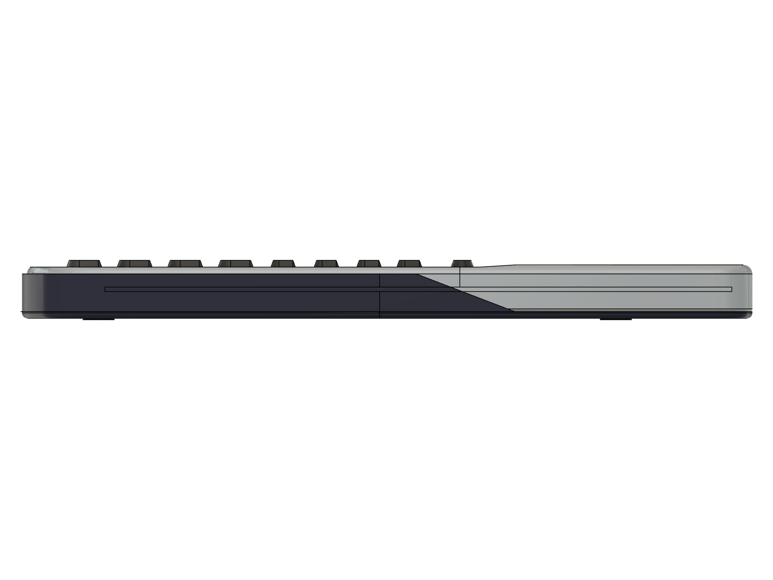
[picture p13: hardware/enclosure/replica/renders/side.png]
side
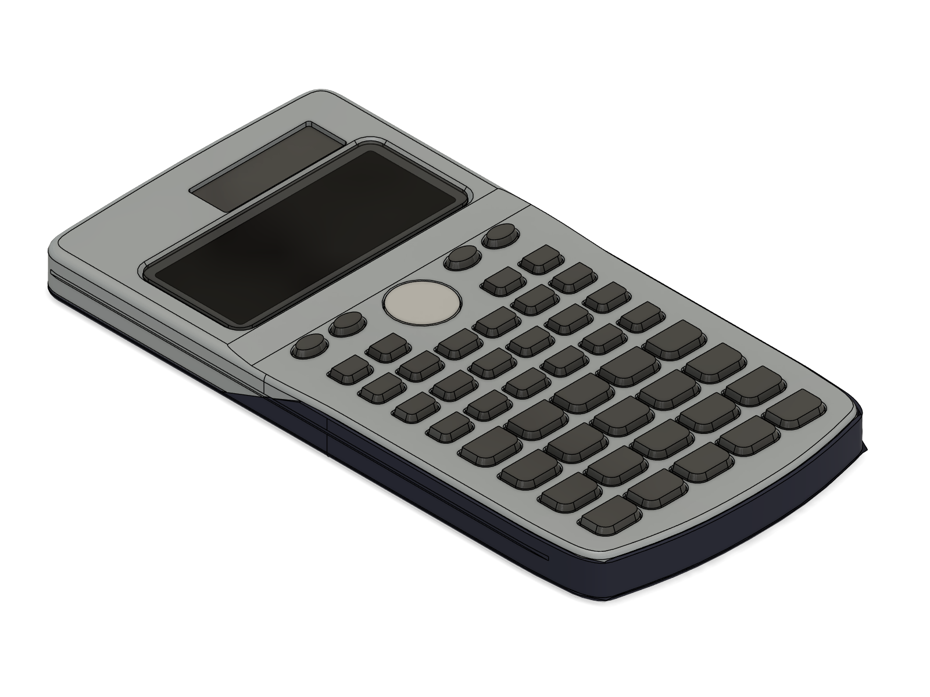
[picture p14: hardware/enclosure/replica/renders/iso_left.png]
left
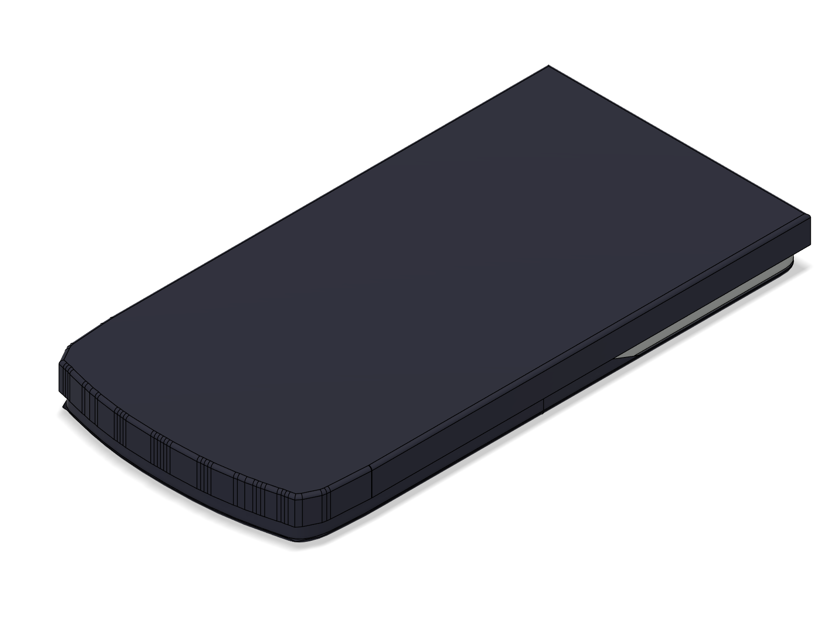
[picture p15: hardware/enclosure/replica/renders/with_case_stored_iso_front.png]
case
|  |  |  |

| Inside the front shell | Inside the back cover | Side (the face steps up 0.5 at the display) |
| --- | --- | --- |
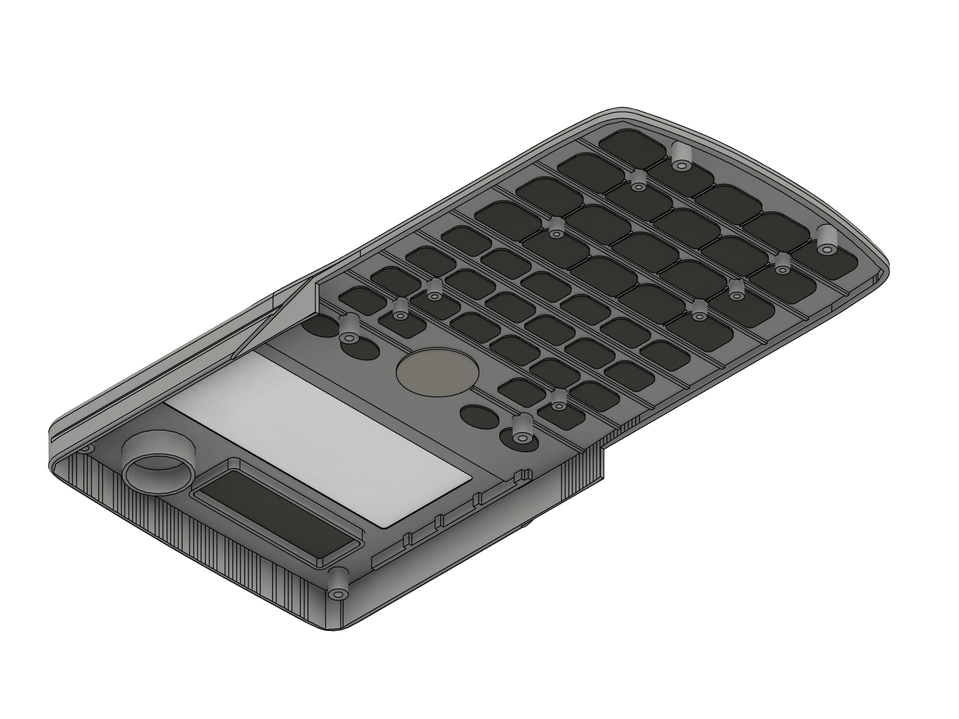
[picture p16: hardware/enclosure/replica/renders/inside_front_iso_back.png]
inside front
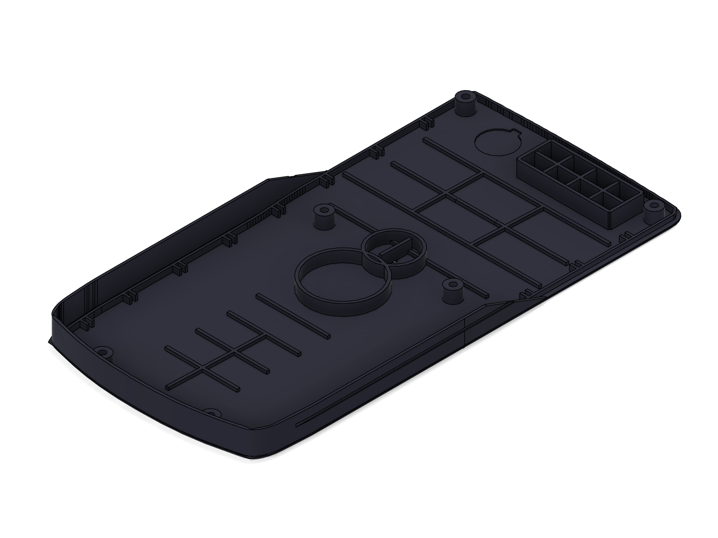
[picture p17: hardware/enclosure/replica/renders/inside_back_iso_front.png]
inside back
|  |  | side |

| Our PCB in the back cover | Cut through the screen section, with our PCB | Close-up of the cut |
| --- | --- | --- |
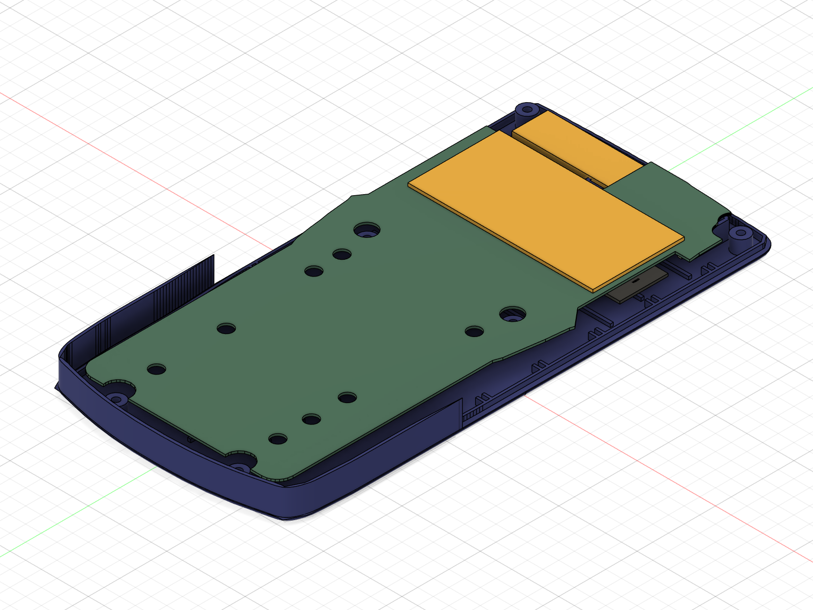
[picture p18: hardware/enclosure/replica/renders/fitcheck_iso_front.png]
fit
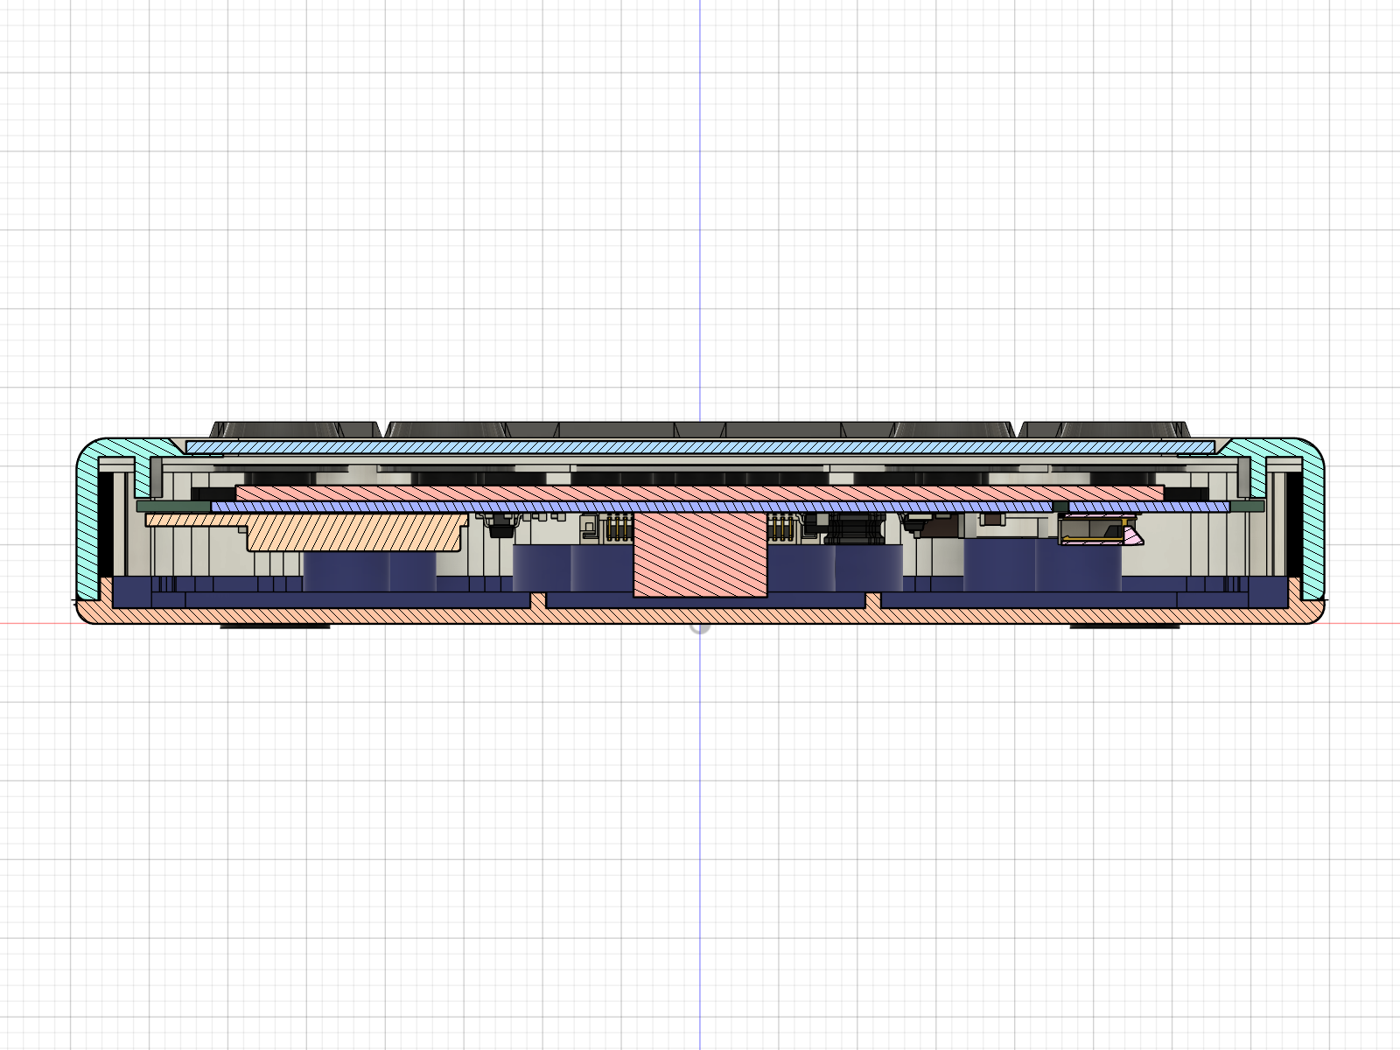
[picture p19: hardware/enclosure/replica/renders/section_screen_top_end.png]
section
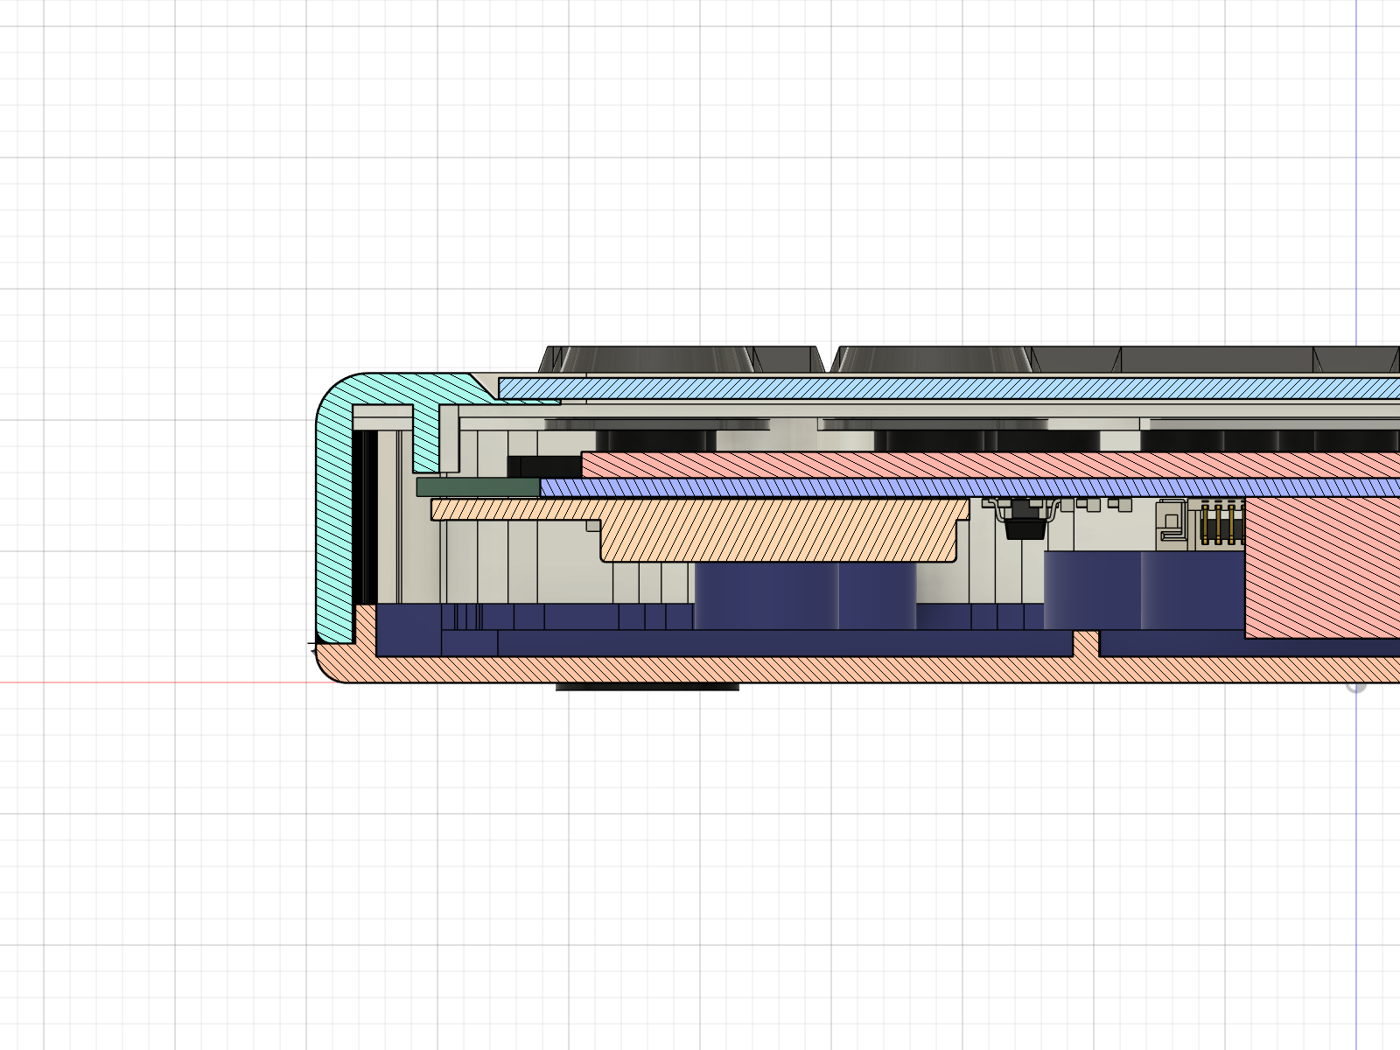
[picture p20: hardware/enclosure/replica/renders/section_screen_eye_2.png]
section close
|  |  |  |

More pictures in `renders/` (straight front/back/side views, the slide cover, a close-up, a lengthwise cut).

## What is in the model

| Part (Fusion component) | What it is |
| --- | --- |
| Front shell | Silver top half: face (11.8 at the display, 11.3 at the keys, with a ramp between), display window in a bevelled recess, solar-cell through-window with a rib frame behind it, 46 key openings (tab-shaped like the real ones, ellipses for SHIFT/ALPHA/MODE/ON, round REPLAY hole), 6 screw posts (Ø3.85, pilot hole), 8 locating posts (Ø2.9, bored), the 4.7 mm wall beside the screen (skin + wire channel + inner rib) with 3 stubs and 1 wire holder per side, the LR44 cup, ribs between the key rows and a collar round each key hole underneath. |
| Back cover | Navy tray: 1.0 floor, rim, a lip that locates inside the front shell, tray walls that come up round the front shell in the keypad section, 6 screw bosses with counterbores, rib grid / two rings / lower ribs (D13 heights), the 4 × 2-cell solar box, short ribs along the inside of the side walls, the round LR44 hole in a shallow recess, the small centre hole, pockets for 4 feet. |
| Keycaps | 47 separate caps (46 keys + REPLAY), each with a skirt at the bottom that stops it falling out. No labels. |
| Keymat | Board-sized rubber sheet lying on the board, one dome per key (top 1.5 above the contact, D9), holes for the posts. |
| Window lens | Clear window in the bezel recess. |
| Solar cell (dummy), Battery lid, Rubber feet | Small parts. |
| Slide case (stored) | The navy slide-on hard case over the face (open end at the display end, closed end at the key end; lips ride in the side grooves). Sizes are guesses (not measured). The final assembly also has it on the back (in use). |
| Reference - Casio board (C6), Reference - LCD (dummy) | Only for checking fit; not exported as STL. LCD: 68 × 28 × 3.75 (D8), fits between the stubs. |
| Fit-check - PCB, Fit-check - missing parts | Only after `fitcheck`: our board from `hardware/fab/ai_calc_board.step`, plus yellow boxes for parts the STEP has no model for. Never exported. |

**Interference check (replica only):** 60 bodies, 0 overlaps (Fusion's own check and a second
pairwise check; `interference.txt`).

## Fit check: our PCB in the shell

```bash
python build_fx115es_replica.py fitcheck fitcheck_shots
```

Run it after `all` (or on the open replica document). It imports `hardware/fab/ai_calc_board.step`,
turns it over (the KiCad top view is seen from the back cover, so F.Cu parts face the back cover),
puts the key side at Z = 6.3 (D1) and checks every board body and part against the front shell,
back cover, keymat, battery lid and solar cell. It also reads `hardware/kicad/ai_calc.kicad_pcb`
(read only) for reference names, the holes, Edge.Cuts and the keep-outs, and adds boxes for the
ESP32-S3 module, the QFN, the camera module, the LiPo and the e-paper glass, which are not in the STEP.
Results, with the STEP timestamp: **`fitcheck_report.md`**. When the PCB agent regenerates the STEP,
just run the two stages again.

Summary of the run on the **stage-12 STEP (2026-10-03 23:02)** with the rev B2 stack-up (6.0 free behind
the board). The full list with depths, the 2D clearances and a stage-11 vs stage-12 table are in
`fitcheck_report.md`; `renders/section_camera_*` and `renders/section_j4_*` cut through the camera and J4.

- **Camera module (proxy, 5.4)**: bottom at Z 1.69, 0.69 above the floor, but it sits on upper rib B (1 high): 0.31 overlap. Grind that rib locally.
- **J4 (JST-PH, 5.5)**: bottom at Z 1.48 (0.48 above the floor) but inside the solar box: grind the box (it overlaps the box walls and grid over J4's full height).
- **J3** (pin socket) 1.0 into the solar-box grid; **U3, D1, Q2** 0.70 to 1.05 into the solar-box frame and grid; **LiPo** 3.2 into the solar box. The solar box has to go (as planned).
- **LiPo vs the front shell's LR44 cup** (D7, 5.5 high): 2.0 overlap. Cut the cup away.
- **Locating posts vs board holes:** H2 −0.54, H9 −0.29, H6 −0.11 (the C15 rows put them 0.8 to 1.2 below the board's holes). H1 is fine now (stage 12).
- Gone with rev B2: everything against the back floor itself, the big ring (D2), the wall ticks (U1), the screen-section inner rib and stubs (they stop above the board).
- The STEP board is 0.71 thick (KiCad 0.8), so real parts sit 0.09 closer to the floor than shown.

## Files

| File | What |
| --- | --- |
| `../build_fx115es_replica.py` | The script. All sizes are named parameters at the top. |
| `fx115es_replica.f3d` | Fusion archive with the full timeline (open it in Fusion and edit anything) |
| `fx115es_replica.step` | Whole assembly for any CAD program (replica only) |
| `stl/` | One STL per part; `stl/keycaps/` has one per key, `keycaps_all.stl` has all of them |
| `renders/` | Pictures (`fitcheck_*` and `section_screen_*` include our PCB) |
| `fitcheck_report.md` | Fit check of our PCB: every collision with location and depth, 2D clearances, STEP timestamp |
| `interference.txt`, `check_2d.txt` | Replica check results (`check_2d.txt` has the caliper cross-checks) |
| `photo_notes.md` | What each of your photos showed and what the model took from it |
| `geometry.json`, `board_snapshot.json` | Numbers the script works from (key and post x positions copied from the KiCad board once, so the replica does not change when the board is edited) |

## Rebuild

Fusion open, FusionMCPBridge add-in running, then in `hardware/enclosure`:

```bash
python build_fx115es_replica.py all
```

It opens a new Fusion document (your other designs are not touched), builds every part, runs
the interference check, exports and takes the pictures, in about 2 minutes. Then optionally
`python build_fx115es_replica.py fitcheck fitcheck_shots`. `python build_fx115es_replica.py` on its own
only checks the 2D layout (no Fusion needed). Single steps: `new front back keys parts check export
shots explode_shots fitcheck fitcheck_shots`. `export` removes the fit-check parts first, so the
exported files are the replica only.

## Every dimension and where it came from

Source: **caliper** = your measurements (ID from the measurement sheets), **spec** = Casio's published
size, **photo** = measured on your photos (about ±1 mm), **board** = KiCad board positions, **derived** =
worked out from other readings, **guess** = my estimate. Confidence: high / medium / low.

| Dimension | Value (mm) | Source | Confidence |
| --- | --- | --- | --- |
| Back cover length x width | 161.0 x 79.3 | caliper C3 | high |
| Front shell length | 159.9 (photo e59eff71 caliper shows 159.8) | caliper C1 | high |
| Front shell width, screen section | 79.3 | caliper C2 | high |
| Front shell width, keypad section | 77.4 (back cover's tray wall 0.8 + 0.15 gap each side) | caliper C5 + photos | medium |
| Outline shape | photo trace 88e03c27, long sides straightened to 79.3 (the trace was ±0.5 wavy), top corners ~5 mm | photo + calipers C2/C3/C9/C11/C15 | medium |
| Thickness, top part / keypad | 11.8 / 11.3 (+ 0.3 feet, + 1.5 keys) | caliper D10 | high |
| Stack-up | floor 1.0 + 6.0 + board 0.8 + 4.0 front side = 11.8; 3.5 front side at the keys = 11.3 | D5 + D4 + board + D10 | high |
| Face step | 0.5, ramp between Y 22 and 30 (between REPLAY and the bezel) | D10 + guess (position) | low |
| Board height | component (F.Cu) side at Z 7.0: 6.0 above the inside of the back floor, 5.5 below the front shell's rim | caliper D4, D1 (Nirav: D4 to the inside face, D1 from the rim) | high |
| Parting line | Z 1.5 from the outside of the back (back cover = shallow tray; tray walls up to 9.8 in the keypad section) | derived from D1 (rim to board 5.5) | high / low (tray walls) |
| Back cover floor | 1.0 | caliper D5 | medium (edges are rounded) |
| Space behind the board | 6.0 (board back to floor) | caliper D4 | high |
| Side wall beside the screen | 4.7 (1.4 skin + channel + 1.0 inner rib), from the plate down to Z 8.0 | caliper C4 + photos; Nirav: stops above the board | medium |
| Side-wall stubs | 3 per side at Y 37.3 / 47.5 / 56.0, tips 5.45 from the outside, from the plate (10.6) down to Z 8.0 (0.2 above the board), 1.5 wide | caliper C14 (depth), Nirav + photo 871567b6 (stop above the board), photo 2a97120d (Y), guess (width) | medium |
| Wire holder | 1 per side at Y 26, tip 5.5 from the outside, 2 wide | caliper C4, photo 2a97120d | medium |
| Tray wall (keypad section) | 0.8 | caliper C5 | medium |
| Front shell skin | 1.4 sides, 1.2 top, 1.6 bottom | derived from C11 (sides, top), guess (bottom) | medium / low |
| Face plate | 1.2 (plate underside 10.6 at the display, 10.1 at the keys) | guess; caps (domes to 9.6 + 0.4 flange) fit under it; D3 check: board line to the outside at the top edge 4.8 ("about 5") | medium |
| Edge round-over front / back | 2.0 / 1.2 | guess (photos) | low |
| Display window | 60.65 x 24.3, top edge 24.0 below the case top, centred | caliper C12, C13 | high |
| Bezel recess | window + 2.5 all round, 1.0 deep, 45° edge | photo 921b4503 + guess | medium |
| Solar window | 34 x 11 at (10.85, 67.3), through; rib frame 0.8 x 2.5 behind it | photo | medium / low |
| Key openings: number / function / row-2 / oval | 11.8x8.2 / 8.9x5.9 / 8.1x6.0 / 8.3x5.6 | measured on the shell (stage 10) | medium |
| Key opening corners (top / bottom) | 1.0/3.0 number keys, 0.8/2.0 others | photo aa09fe8a + guess | low |
| REPLAY opening | Ø15.4 | measured | medium |
| Key centres | KiCad board | board + photos | high |
| Key height above face | 1.5 (REPLAY 1.2) | guess | low |
| Keymat | sheet 0.8 on the board, dome tops 1.8 above the board (contact 0.3 + D9 1.5) | caliper D9 + guess | medium |
| LCD stack | LCD shield 6.8 to 10.55, level with the Casio board's back face (7.0) | D8 + photo 871567b6 | medium |
| LCD module | 68 x 28 x 3.75 | caliper D8 (thickness), photo fd923128 (width), guess (height) | medium / low |
| Screw posts | Ø3.85, pilot Ø1.7 | caliper C7 / guess | high / low |
| Locating posts | Ø2.9, bore Ø1.2 x 3 | caliper C7 / guess | high / low |
| Corner screw posts | (±34.05, 74.05): 68.1 apart, 8.05 below the top | caliper C9, C15 (C11 4.2 / 6.1 agree: 4.20 / 6.02) | high |
| Middle screw posts | (22.45, 13.0), (−24.05, 13.0): 46.5 apart | caliper C8, C15; centre from the mat photo | high (spacing) / medium (centre) |
| Bottom screw posts | (±19.5, −71.65): 39.0 apart | caliper C10, C15 | high |
| Locating posts H8/H10 | 42.3 apart, at the photo height | caliper C8 + photo | medium |
| Locating posts H4, H2/H9, H6, H13/H14 | x from the photo fit, y from C15 rows | caliper C15 + photo | medium |
| C15 reading convention | "to the outside of the holes" = case top to the far edge of the post's hole (pilot / bore); fits the photos to ≤ 1.05 | derived | medium |
| Back ribs and rings | positions photo 2f54d6c7; rings Ø16.8 / Ø24.8 | photo | medium |
| Rib / ring heights | grid 1, rings 4, lower ribs 1, vertical rib through the small ring 4 | caliper D13 (that rib: guess) | high / low |
| Solar box | 33 x 12 at the top right, 4 x 2 cells; frame 5.5, grid 5 high | caliper D6, D13, photo 050df9b7 | medium |
| LR44 cup (front shell) | Ø12.4 inside, 0.8 wall, 5.5 high | caliper D7 (height), photos | medium |
| Battery hole / recess | Ø12 hole with notch, 16 x 15 x 0.6 recess at (−18.3, 69.9) | photo + guess | low |
| Back screw bosses | Ø5.5 up to Z 5.4, Ø2.2 hole, Ø4.4 x 1.2 counterbore | guess | low |
| Feet | 4 x Ø7, 0.3 proud | guess | low |
| Casio board | 65.05 x 97.9 x 0.8 | caliper C6 | high |
| E-paper (fit check) | 59.0 x 29.2 x 1.0 | caliper P3 (thickness from the drawing) | high / medium |
| Split line on the long sides | rim (Z 1.5) in the screen section, ramp from Y 31 (small ring) to Y 8 (big ring), then Z 9.8 round the keypad + bottom | photos 2f54d6c7, 84e63d95, 050df9b7, 7c6e8116 (position) + guess (straight ramp, 9.8) | medium / low |
| Faceplate skirt (keypad section, bottom end) | silver part ends at Z 8.3 inside the navy wall | photos 76dd27d2, e82c982d (shape) + guess (depth) | low |
| Silver step-in (keypad) | 0.95 (navy wall 0.8 + 0.15), from Y 18 (under SHIFT/ALPHA) to full at Y -2 | photos 7c6e8116, 4e287737, e59eff71 | medium |
| Rail groove | 1.0 tall x 0.35 deep at Z 5.9-6.9, both long sides | guess (not in any photo) | low |
| Slide case | wall 1.0, floor 1.2, 0.3 clearance, lips 0.9 in the groove, open end at the top | guess + Casio manual (open end) | low |

Coordinates are front-view mm with (0, 0) at the KiCad board's reference point: X = 150 − x_kicad,
Y = 138.94 − y_kicad.

## Remaining guesses (the things that would make it exact)

1. **Side profile photo with a ruler:** how high the back cover's tray walls come up in the keypad section
   (9.8?), where the face steps from 11.3 to 11.8, edge round-overs, key height.
2. **Stub / inner rib bottom:** Nirav says they stop above the board; modelled 0.2 above it (Z 8.0). The
   exact height would tell how much room is left under them.
3. **Face-plate thickness** (calipers through a key hole) and the **back floor** away from the edge.
4. **A flatbed scan** of the face and of both insides: would replace every "photo" row above.
5. **Battery recess and lid**, the **centre hole**, the **feet**.
6. **Keycap** height and top shape; **slide cover** (not measured at all).

## Known simplifications

- Key tops are a straight bevel, not the real slightly curved shape.
- The inside of the front shell's top wall and the tray walls are built from short straight
  segments, so they show faint facet lines in close-ups (the outer surfaces are smooth).
- The face step is a straight ramp with a small round where it meets the edge round-over.
- The slide cover is a simple lid; the real one's grip is unknown.
- No screws are modelled.

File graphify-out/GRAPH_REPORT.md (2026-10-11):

# Graph Report - AI-CALCULATOR  (2026-10-10)

## Corpus Check
- 424 files · ~7,153,224 words
- Verdict: corpus is large enough that graph structure adds value.
- Unclassified: 328 file(s) not represented in the graph (top: .kicad_mod 81, .stl 69, .step 39)

## Summary
- 4890 nodes · 9633 edges · 306 communities (239 shown, 67 thin omitted)
- Extraction: 90% EXTRACTED · 10% INFERRED · 0% AMBIGUOUS · INFERRED: 934 edges (avg confidence: 0.85)
- Token cost: 0 input · 0 output

## Graph Freshness
- Built from commit: `7f23a282`
- Run `git rev-parse HEAD` and compare to check if the graph is stale.
- Run `graphify update .` after code changes (no API cost).

## Community Hubs (Navigation)
- tests.cpp
- device.cpp
- mm
- Tok
- build_case.py
- win32_main.cpp
- Device
- geometry
- Stage 11: e-paper moved to the measured window, calipers applied, review fixes (ai_calc_pcb_11)
- DKey
- Json
- Ann
- JLCPCB order walkthrough (stage 14 board, silk "AI CALC v14 2026-10-04")
- Fit check: paper grind maps, dummy board, clearance table
- web_main.cpp
- firmware/src/camera.cpp
- battery_envelope.py
- Full tables
- firmware-prototype/src/main.cpp
- AI Answer Flow
- Stage 4: full calculator
- animate_assembly.py
- AI Calculator PCB Handoff
- check_requirements_11.py
- AI Calculator launch roadmap
- vector
- build_fx115es_replica.py
- stage_front
- firmware-prototype/src/setup_portal.cpp
- db.py
- App
- 12: Inner rib / pins / hooks re-check against the v14 board (2026-10-06, before ordering)
- Focus
- Stage 12: second caliper batch, new photos, CAD fit check (ai_calc_pcb_12)
- Vars
- Router
- Framebuffer
- firmware/src/preview.cpp
- sys
- Independent electrical + manufacturability review (2026-10-03)
- ai_calc_pcb_8/hardware/geometry/derive_geometry.py
- Back cover (engraved 'AI CALCULATOR rev A, 6 x M2x10')
- test_hardening.py
- AI Calculator Board Concept Layout v2
- stage_parts
- hardware/tools/build_board.py
- linking.py
- 08 — Second-opinion PCB check (v14), re-derived from the raw files
- app.py
- font.h
- Root sheet ai_calc.kicad_sch
- solve.py
- firmware-prototype/src/camera.cpp
- selfTestRun
- AI Calculator Multiple Choice Test
- fit_tw302030.py
- stage_fitcheck
- View
- Competitor analysis: AI calculators (checked 2026-10-03)
- firmware-prototype/src/power.cpp
- re
- Stage 10: moving the board to the Casio fx-115ES shell
- Breadboard Wiring Diagram (exact, camera up)
- ai_calc_pcb_8/hardware/tools/fixroute.py
- Stage-8 board ai_calc.kicad_pcb (72.3x148.8 mm, 0.8 mm, 2 layers, 140 footprints, 4630 tracks, 322 vias, 92 nets, GND pour)
- publish
- stage_cell
- host_hw.cpp
- Prototype firmware README (board inside the Casio)
- Stage 9: finishing the v8 board (ai_calc_pcb_9)
- Nirav's caliper readings, fx-115ES shell (2026-10-03, second batch)
- D
- os
- build_final_assembly.py
- SolveResult
- fbtext.cpp
- make_lcd_sheet.py
- Parser
- PR_hardware-stage11-roadmap.md
- Tester firmware README (Stage 4)
- make_bringup.py
- Num
- ai_calc_pcb_8/hardware/tools/build_board.py
- Overlay
- SerialCmd
- load_info
- Viewfinder
- algorithm
- Fit check: our PCB in the fx-115ES replica
- fit_2d
- full.sh script
- Stage 12 progress notes (working log)
- firmware-v15-lcd/src/main.cpp
- Stage 14: fixing the 4-part verification findings
- U1 ESP32-S3-MINI-1-N4R2 (MCU module)
- calc_engine.cpp
- 03 — External interfaces, end to end (stage 13b board)
- firmware-v15-lcd/src/claude_client.h
- fx-115ES shell replica (unbranded)
- Board geometry from the scan: assumptions and confidence
- Photo notes for the fx-115ES replica
- clearance_table.md
- Replica progress (for resuming after a cut-off)
- stage11_progress.md
- Fit check: our PCB in the fx-115ES replica
- Stage 13: the three height problems (J4 battery socket, J3 magnet, camera)
- Final pre-order review (2026-10-04, stage 13b board)
- build_jigs.py
- guide_renders.py
- firmware-prototype/src/claude_client.cpp
- stage13_progress.md
- Calculator Mode
- 04 — Manufacturing verification (JLCPCB PCB + PCBA), stage 13b
- Final firmware review (board v14, ESP32-S3-MINI-1-N4R2)
- lgfx_host_platform.cpp
- SerialCmd
- firmware/src/screen.cpp
- Battery upgrade study: a bigger LiPo without changing the board (2026-10-06)
- build
- Docs consistency audit (2026-10-06, 01:20–01:40 EDT, stopped early to save usage)
- Menu System
- test_proxy.py
- pinmap_crossref.py
- Final assembly progress (resume here)
- Firmware stage-13 work: progress notes
- Kind
- graphify skill trigger (/graphify)
- firmware-prototype/src/keys.cpp
- AI Calculator PCB - KiCad design summary
- assembly_howto_pictures.py
- gen.py
- stage_tailcase
- sim/web/build.sh
- Browser simulator page (page.html)
- ui.cpp
- Part B: end-of-line test, every finished unit
- arduino
- Decode
- AI Calculator PCB: handoff for the next Claude session (from stage 14)
- Stage 2: electrical plan (pins, power, keypad)
- JLCPCB order checklist (stage 14, silk "AI CALC v14 2026-10-04")
- Stage 3: schematic (done)
- Stages 4 + 5: footprints and placement
- full.sh script
- Verification 02: power, boot, recovery, protection, analog (stage 13b)
- Final assembly check: does everything fit?
- CameraPins
- 05: Independent re-check of stage 14 (v14) before the one-shot order
- AI Calculator PCB - KiCad design summary
- billing.py
- viewfinder.cpp
- firmware-v15-lcd/src/settings.cpp
- hardware/tools/make_outputs.sh
- annotate_guide_v15.py
- IdlePolicy
- AI Calculator board: final status (start here)
- Slide case mods (LATER: not needed for testing)
- Stage 14 progress (verification fixes)
- time
- clearance_table_full.md
- CameraPins
- Grinding jigs (3D-printed) for the donor fx-115ES shell
- sim_state
- pilroute.py
- annotate_guides.py
- Who should build the board? JLCPCB vs the alternatives
- spline
- firmware-prototype/src/settings.cpp
- Stage 15: v15-LCD, the 2.13" e-paper replaced by a 1.9" colour IPS LCD
- firmware-prototype/src/screen.cpp
- archive/README.md
- 13 — Independent review of the v15-LCD board, re-derived from the raw files
- lcd.cpp
- Knockoff shell plan: measuring a 991ES-style clone and refitting the board (v15)
- rrect_pts
- build_cost_model.py
- all_bodies
- 06 — Final adversarial review of PCB v14 (before ordering)
- app.cpp
- Goldenmorning T190X7-C30-01H: does it fit the v15-LCD build?
- Unit economics: what each calculator costs and earns
- Keypad 8x10 matrix (ROW0-7, COL0-9, SW1-SW50)
- Arrival checklist: from boxes to a working calculator
- 11 — Requirements trace: is everything we decided actually on the v14 board?
- LCD panel options for the v15-LCD board
- Json
- glyphdraw.h
- firmware-v15-lcd/src/claude_client.cpp
- bringUp
- Router
- config.py
- firmware-v15-lcd/src/camera.cpp
- make_screens.py
- make_outputs_v15.sh
- CalcError
- string
- Panel
- What changed, file by file
- previewStart
- Firmware for the stage-13 board
- Status
- probe
- firmware-v15-lcd/src/preview.cpp
- Router
- F
- onWifiEvent
- cam_route
- SerialCmd
- wifi
- t218/clearance_table_full.md
- Event
- 14 — Final pre-order verification of the v15-LCD board (ER-TFT019-1 panel)
- Kind
- final_assembly_v15_lcd/clearance_table_full.md
- FakeClient
- Event
- harness.cpp
- StreamReader
- FrameInfo
- Failure
- View
- JLCPCB order walkthrough: v15-LCD board (silk "AI CALC v15-LCD 2026-10-08")
- restoreState
- 15. v15-LCD key pads vs the original Casio fx-115ES keyboard PCB
- build_final_assembly_v15.py
- ai_calc_pcb_8/hardware/tools/prepass.py
- OtaInfo
- DIR
- Decode
- AI Calculator proxy
- SolveCallbacks
- check_hole_clearance.py
- SendStep
- Crop
- Button
- 2026-10-10
- cameraShot
- t203/clearance_table_full.md
- Wake
- string
- firmware/src/settings.cpp
- firmware/src/main.cpp
- Tuning
- HistoryItem
- ScanNote
- firmware-v15-lcd/src/setup_portal.cpp
- selfTestRun
- annotate_guide.py
- key_pills.md
- Key
- esp_random
- vf_lcd.cpp
- Settings
- check_hole_clearance_v15.py
- v15 colour LCD: real UI screenshots
- pil
- cameraPreviewRelease
- firmware-v15-lcd/src/power.cpp
- Tuning
- Com
- SendStep

## God Nodes (most connected - your core abstractions)
1. `Device` - 122 edges
2. `Tok` - 91 edges
3. `DKey` - 80 edges
4. `App` - 70 edges
5. `Num` - 48 edges
6. `Viewfinder` - 45 edges
7. `Parser` - 42 edges
8. `loop()` - 37 edges
9. `loop()` - 35 edges
10. `Framebuffer` - 33 edges
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

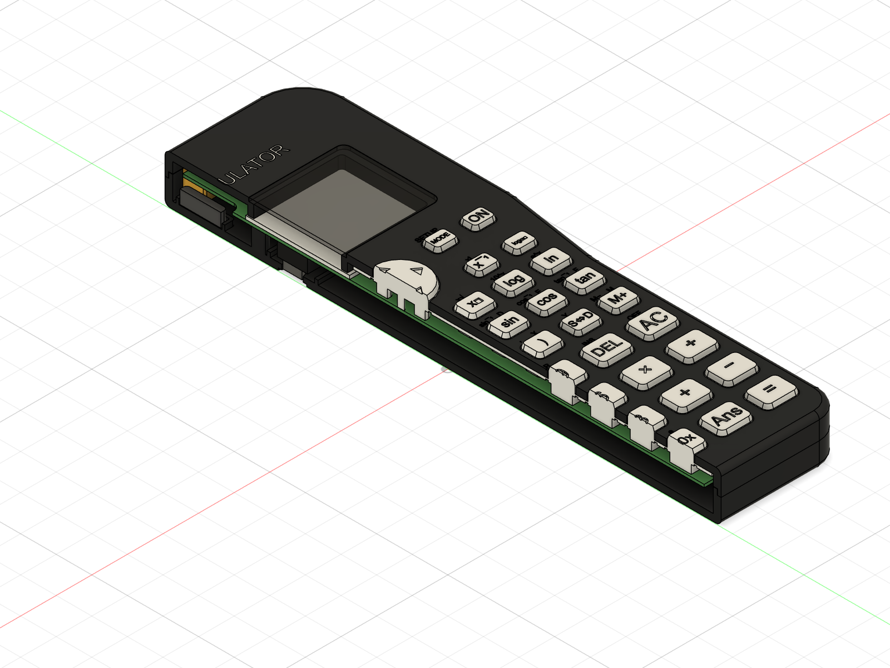
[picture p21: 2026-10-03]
hardware/enclosure/renders/section_iso_left.png

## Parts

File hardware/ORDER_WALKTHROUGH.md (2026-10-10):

# JLCPCB order walkthrough (stage 14 board, silk "AI CALC v14 2026-10-04")

This replaces the walkthrough at the end of `REVIEW_final_2026-10-04.md`. The short version is in `ORDER_CHECKLIST.md`; overall status and what's left: `FINAL_STATUS.md`.

There is only one order, and no second board, so go slowly and check each step.

## 0. Before you start

- **Paper dry fit (the only thing that could still change the board):**
  - Print `../Claude outputs/paper_dry_fit_v14.svg` at 100 % ("actual size"). Measure the printed 50 mm line: it must be 50 mm. Cut it out **together with the yellow antenna tab** on the left edge of the drawing (4.5 × 15.4 mm: the ESP32 antenna is a bare 0.8 mm tab that overhangs the board by 4.15 mm; on the calculator this is the right-hand, solar-window side as you use it). `hardware/fitcheck/grind_map_front_shell.svg` (regenerated 2026-10-06) is the same template with the grinding-guide zone numbers.
  - The antenna tab must clear the shell's side wall; if it rubs on the thin inner rib of that wall, the fix is grinding-guide zone 6 (file 35 mm of that rib, 14–49 mm from the shell's own top outer edge at that wall, i.e. from the rim's top edge right above the side rib; datum corrected 2026-10-10, older notes said 15–50; zones 6 and 6b are now always done, verification 12), not the board; the board's top corner beside the tab must drop in too. Also do the 10-minute pre-grind checklist in `verification/07_final_review_fitment.md`.
  - Lay it in the front shell, on the posts. Each post must sit inside its hole (H2/H3/H6/H9/H13/H14 and the screw posts) without pushing. H6 has the least play (about 0.10 mm); if it pushes only slightly, that's OK (file H6 a little towards the board top later).
  - Ignore any "LR44 cup" grind note: the LR44 holder stays and the battery lies on the back-cover floor.
  - If one is off by more than about 0.5 mm, stop and ask for a hole move.
- **Have these open:**
  - The upload files in `fab/`: `ai_calc_gerbers_JLCPCB.zip`, `ai_calc_BOM_JLCPCB.csv`, `ai_calc_CPL_JLCPCB.csv`.
  - `fab/render_top.png` and `fab/ai_calc_assembly_top.pdf` to compare the preview against.
- **The CPL is already corrected.** `tools/make_outputs.sh` writes it through `tools/jlc_cpl.py`, which adds JLCPCB's rotation offsets:

  | Part | Rotation in the CPL |
  |---|---|
  | Q1 | 180 |
  | Q2 | 270 |
  | U2, U3, U7 | 270 |
  | U4, U5 | 180 |
  | J3 | 180 |

  Every one was checked against JLCPCB's own (EasyEDA) footprints: pin 1 lands on pad 1 (`stage14_verification_fixes.md`, fix 2). **Upload the `fab/` CPL as it is. Don't rotate anything in the preview; only verify it against the table in step 5.** (Independently re-checked: `verification/05_stage14_recheck.md`.)

## 1. Upload the gerbers

- jlcpcb.com → **Order now** → **Add gerber file** → `ai_calc_gerbers_JLCPCB.zip`.
- The viewer should show 2 layers and about **71.7 × 148.9 mm**, with the thin e-paper slot to the right of the screen area.

## 2. PCB options

| Option | Setting |
|---|---|
| Base material | FR-4 |
| Layers | 2 |
| Dimensions | auto |
| PCB qty | **5** |
| Product type | Industrial/Consumer |
| Different design | 1 |
| Delivery format | Single PCB |
| PCB thickness | **0.8 mm** (needed for the keypad stack) |
| PCB colour | Green |
| Silkscreen | White |
| Surface finish | **ENIG** (gold key pads; HASL is too bumpy for the rubber keys) |
| Outer copper weight | 1 oz |
| Via covering | Tented |
| Mark on PCB / remove order number | **Specify a location** (the "JLCJLCJLCJLC" marker is on the component side, away from the keys) |
| Everything else | default |

The four oval NPTH holes and the 1.0 mm e-paper slot are normal. There's no castellation and no impedance control.

## 3. PCB Assembly

| Option | Setting |
|---|---|
| PCBA type | **Standard** (needed for the ESP32 module and the QFN; it includes X-ray) |
| Assembly side | Top side |
| PCBA qty | **2** |
| Tooling holes | Added by JLCPCB |
| Confirm parts placement | **Yes** |
| Edge rails | if asked: **right and bottom edges only** (step 7) |

## 4. BOM and CPL

- Upload `fab/ai_calc_BOM_JLCPCB.csv` and `fab/ai_calc_CPL_JLCPCB.csv`.
- All 30 lines should match, with no shortfall. Every designator is listed separately (C32,C33,C34, not C32-C34), so all 77 parts match the CPL.
  - 14 Extended part types: U1–U7 (6 types), Q3, D7, L1, R12, J1/J2 (one type), J3, J4.
  - Everything else is Basic.
- **Ignore the "not in BOM" note** for TP1–TP7, FID1–3, H* and SW1–SW50. They are bare copper, not parts.
- If any line says "consign" or "pre-order", stop and ask.

## 5. Placement preview: what each part must look like

"Top-left" etc. is as seen in `render_top.png` (component side, board top edge at the top of the picture).

| Part (KiCad x, y) | Must look like |
|---|---|
| **U2, U3, U4, U5** (SOT-23-5) | Pin-1 dot **top-left** (3-pin side on the left) |
| **U7** (SOT-23-6, 133.6, 83.2) | Pin-1 dot **top-left** |
| **Q1** (136.1, 79.5) | Pins 1–2 on the **left**, the single pin 3 on the **right** |
| **Q2** (135.9, 75.6) | The single pin 3 at the **top**, pins 1/2 at the bottom |
| **Q3** (163.6, 97.4) | The single pin 3 on the **left** |
| **U6** TCA8418 (126.0, 146.5) | Pin-1 dot **top-left** |
| **D1–D6** | Band on the **left** pad |
| **D7** TVS (119.2, 73.4) | Band on the **right** pad, towards J3. **This one matters most:** backwards, it shorts the charging cable. |
| **U1** ESP32 (127.55, 97.0) | The antenna end (no pads) hanging off the **left** board edge. If the model sits sideways from the pads, ask them to align it to the pads. |
| **J1** camera socket (150, 161) | Opening facing **up**, towards the camera area. JLCPCB's pin-1 mark will be at the **right** end: that is correct. **J1's pin numbering is intentionally reversed. Don't rotate it.** Align by the pads and the two mounting tabs. |
| **J2** e-paper socket (177.9, 92.8) | Opening facing **left**, towards the slot |
| **J3** magnet header (127.5, 72.0) | The 4 socket openings face the **top edge**; the body hangs about 0.4–1 mm past the edge. The 4 contacts are identical, so "pin 1" doesn't matter here. Only the direction does: body towards the edge, never over D1/D6/U7. |
| **J4** battery socket (142.6, 74.6) | Opening facing **down**; the two small pins at the top, the big tabs at the bottom |

**Don't rotate anything.** The files are already set up to match this table, and the re-check confirmed it. If a part seems to disagree, stop and ask Claude (or JLCPCB's engineer) before clicking anything: it's more likely a reading mistake than a wrong file.

## 6. Order notes (paste into the "remark" box)

> J1 pin numbering is intentionally reversed vs. the library footprint: please align J1 to its pads and mounting tabs, do not rotate it. U1 antenna and J3 body overhang the board edges on purpose (left and top edges). If rails are needed, please put them on the right and bottom edges only. Please X-ray U1 and U6. OK to pull back copper locally if any copper is too close to a hole.

## 7. If JLCPCB's engineers email you

Answer within a day, or the order waits.

| They ask about | Answer |
|---|---|
| "Component exceeds the board edge" (U1, J3) | **Intended, please keep.** The U1 antenna overhang is Espressif's recommended placement. J3 overhangs for the magnet connector. |
| Edge rails / conveyor clearance | Rails on the **right and bottom edges only**. Keep the left edge (antenna) and the top edge (J3) free. A small rail fee is fine. |
| Copper too close to a hole / NPTH / board edge | **OK to pull back copper locally.** Stage 14 already keeps everything ≥ 0.25 mm from every hole. |
| J1 pin 1 doesn't match the library | **Intentionally reversed.** Align by pads and mounting tabs; don't rotate. |
| D7 polarity | Cathode band on the pad towards J3 (KiCad x 120.65, the VBUS pad). |
| Pin-1 silk marks too thin to print | Fine. Use the pads / the assembly drawing. |
| Oval holes / the slot | Intended non-plated slots; the 1.0 mm slot is a routed cut-out. |
| Drill-map files are "unknown layers" | Ignore them, or delete the two `*-drl_map.gbr` files from the zip and re-upload. |
| A part is out of stock / needs a substitute | Stop and check with Claude before accepting a substitute. |

## 8. Expected cost (2026-10 prices; check the final quote)

| Item | Estimate |
|---|---|
| 5 PCBs, 2-layer, 71.7 × 148.9, 0.8 mm, ENIG | $25–40 |
| PCBA setup (Standard) + stencil | about $33 |
| Extended part fees (14 × $3) | $42 |
| Parts (2 boards) | $28–30 |
| Solder joints, misc, possible edge-rail fee | about $2–10 |
| **Subtotal** | **about $135–155** |
| Shipping (DHL/FedEx express) | $20–40 |
| US import duty, collected at checkout (about 35–37.5 %; de-minimis suspended since 2026-06-24) | about $45–55 |
| **Total delivered** | **about $200–240** |

Timing: about **10–14 days door-to-door** (build 5–8 days + express 3–6 days). If express isn't offered, economy shipping takes 7–15 days on its own. Other fabs compared in `FAB_VENDOR_COMPARISON.md` (verdict: stay with JLCPCB).

If the quote is far above this (for example over $200 before shipping), something is mis-ticked. Look for a consigned part, "Economic" instead of "Standard", or a PCB qty other than 5.

## 9. After the boards arrive: meter checks before anything is plugged in

### Battery
- Meter the Adafruit cell's red wire against J4 "+" (right-hand pin, seen from the component side with the opening towards you).
- If it's reversed, swap the two crimp pins in the plug: lift the tabs with a needle. No soldering.

### Camera ribbon
- Fingers 2 and 15 must both beep to GND.

### Magnet piece (do this **before gluing**, with the real #5412 cable)

J3 is wired, from pin 1 (silk "N" and "+", the leftmost pin seen from the component side with the top edge away from you): **VBUS, D−, D+, GND**.

Alternates (added 2026-10-10): the Yiwei **MG04254FRA1S1N** piece is the same part as the #5358, and the Yiwei **MG0425-UB-60-4P** cable is the equivalent of the #5412 (its face reads GND, D+, D−, V+ from its N end, like the #5412). Do exactly the same steps with whichever cable you actually use.

1. Straighten the 4 legs of the #5358 piece, but don't fit it yet. Snap the cable's magnet end onto it. The magnets only latch one way.
2. Plug the cable's USB-A end into a **phone charger**. Set the meter to DC volts.
   - Black probe on one **outer** leg, red on the other outer leg. You should see about **+5 V**. The red-probe leg is **VBUS**; mark it with a pen.
   - If you read −5 V, swap the probes.
   - The two inner legs must read **0–0.6 V** to the black (GND) leg. If 5 V appears on an inner leg, **stop**: the cable is wired differently from Adafruit's drawing. Don't fit it, and ask.
3. Unplug the charger. Set the meter to continuity (beep).
   - The VBUS leg beeps to one **outer** contact of the USB-A plug (USB pin 1). The GND leg beeps to the other outer contact (USB pin 4), and usually to the metal shell.
   - The inner leg **next to VBUS** must beep to the USB-A contact next to pin 1 (USB pin 2 = **D−**).
   - The inner leg **next to GND** must beep to the contact next to pin 4 (USB pin 3 = **D+**).
   - If the inner legs are the other way round, stop and ask. It wouldn't damage anything, but USB data wouldn't work.
4. Fit the piece with the **VBUS leg in J3 pin 1** (silk "N" / "+") and the **GND leg in pin 4** (silk "−"). By Adafruit's drawing, that puts the piece's N magnet at the pin-1 end.
5. With the piece pushed in (not glued), meter on the board:
   - J3 pin 4's leg beeps to **TP4 (GND)**.
   - J3 pin 1's leg does **not** beep to TP4.
6. Only now glue the body into the top-wall slot.

*Why this matters:* if the piece went in backwards, the cable's 5 V would land on the board's GND contact. D7 clamps that, and a computer's USB port cuts the current quickly, but a phone charger can push 2 A or more through D7 and the charger chip, so damage is possible (`verification/05_stage14_recheck.md` C1). Never test it. (Stage 14 wiring puts power and ground on the outer pins, so a backwards fit can never put 5 V on a data line. The old advice "turn the magnet piece over if mirrored" is withdrawn.)

### First power-up
- USB only, with nothing else plugged in.
- Probe TP5 = 3.3 V and TP7 = EN high. TP6 = battery (0 V, or 4.1–4.25 V from the charger, with no cell).
- First flash over USB (always; the OTA partition table can't arrive over the air), then the e-paper, then the camera, then the AI settings. The full sequence is the Power-Up guide (`bringup_guide.html`); start at `ARRIVAL_CHECKLIST.md`.

### If the board ever won't take new firmware
See `firmware-prototype/README.md` §1, "Recovery" (and Power-Up guide step 7):
1. Hold TP1 (BOOT) to TP4 (GND).
2. Tap TP7 (EN) to GND.
3. Flash.

The UART backup is TP2/TP3. Never burn the security or USB-disable eFuses.

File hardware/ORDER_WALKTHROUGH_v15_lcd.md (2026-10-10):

# JLCPCB order walkthrough: v15-LCD board (silk "AI CALC v15-LCD 2026-10-08")

The v15 version of `ORDER_WALKTHROUGH.md` (which stays as the v14 record). The board was verified **"ORDER"** by the final pre-order review `verification/14_v15_final_preorder.md` (ERC 0, DRC 0/0/0/0, copper-to-hole ≥ 0.25 mm, CPL 20/20 against freshly fetched EasyEDA footprints, every part in JLCPCB stock on 2026-10-08 21:30). Overall status: `FINAL_STATUS.md`. v14 stays frozen (git tag `v14-order`, `kicad/`, `fab/`): **don't upload anything from `fab/`.**

The settings below are the ones Nirav used for the v14 order on 10/8. Go slowly and check each step.

## 0. Before you start

- **No paper dry fit and no panel test are needed first.** The outline and all holes are identical to v14 (review 14 §2 check 6), and the bench checks for the panel (section 9) can all be fixed on this board if they come out differently.
- **Panels:** order **3 × BuyDisplay ER-TFT019-1, the version without touch** (~$6–7 each; $6.22 at 10), the same day. Do **not** add BuyDisplay's ER-CON30HT-1 socket: J5 is already on the board. (Adafruit #5394 is only an optional fallback.) Shopping list: `Claude outputs/AI_Calculator_Shopping_List.xlsx`, sheet "v15-LCD prototype".
- **Have these open** (all regenerated **2026-10-08 21:38** from the final board):
  - Upload files in **`hardware/fab_v15_lcd/`**: `ai_calc_v15_lcd_gerbers_JLCPCB.zip`, `ai_calc_v15_lcd_BOM_JLCPCB.csv`, `ai_calc_v15_lcd_CPL_JLCPCB.csv`.
  - To compare the preview against: `fab_v15_lcd/render_top.png` and `fab_v15_lcd/ai_calc_v15_lcd_assembly_top.pdf`.
- **The CPL is already corrected.** `tools/v15_lcd/make_outputs_v15.sh` writes it through `tools/jlc_cpl.py`, which adds JLCPCB's rotation offsets. Every polarised or multi-pin part (20 of them) was placed with JLCPCB's own EasyEDA footprint at the CPL angle and compared pad by pad: 20 PASS (`fab_v15_lcd/cpl_easyeda_check_v15.md`). **Upload the CPL as it is. Don't rotate anything in the preview; only verify it against the table in step 5.**

## 1. Upload the gerbers

- jlcpcb.com → **Order now** → **Add gerber file** → `fab_v15_lcd/ai_calc_v15_lcd_gerbers_JLCPCB.zip`.
- The viewer should show 2 layers and about **71.7 × 148.9 mm** (same outline as v14), with a thin **1.0 × 20 mm slot near the right edge** beside the screen area (x 180.5–181.5). The old e-paper slot further in is gone.

## 2. PCB options

| Option | Setting |
|---|---|
| Base material | **FR-4** |
| Layers | **2** |
| Dimensions | auto |
| PCB qty | **5** |
| Product type | Industrial/Consumer |
| Different design | 1 |
| Delivery format | Single PCB |
| PCB thickness | **0.8 mm** (needed for the keypad stack) |
| PCB colour | Green |
| Silkscreen | White |
| Surface finish | **ENIG, 1U"** (gold key pads; HASL is too bumpy for the rubber keys) |
| Outer copper weight | 1 oz |
| Via covering | **Tented** |
| Min via hole size / diameter | **0.3 mm** (the board's vias are 0.3 mm) |
| Mark on PCB | **Remove mark** |
| Confirm production file | **Yes** |
| Everything else | default |

The oval NPTH holes and the 1.0 mm slot are normal. There's no castellation and no impedance control.

## 3. PCB Assembly

| Option | Setting |
|---|---|
| PCBA type | **Standard** (needed for the ESP32 module and the QFN; it includes X-ray) |
| Assembly side | **Top side** |
| PCBA qty | **5** (as for v14; 2 is the minimum and saves roughly $40–55) |
| Edge rails / fiducials | **Added by JLCPCB**, on the **right and bottom edges only** (say so in the remark, step 6) |
| Depanel boards before delivery | **Yes** (rails removed) |
| Confirm parts placement | **Yes** |
| Photo confirmation | **Yes** |
| Review before payment | **Yes** (pay only after JLCPCB's engineers have reviewed the files) |

## 4. BOM and CPL

- Upload `fab_v15_lcd/ai_calc_v15_lcd_BOM_JLCPCB.csv` and `fab_v15_lcd/ai_calc_v15_lcd_CPL_JLCPCB.csv`.
- **32 BOM lines, 65 placed parts**, all matched, no shortfall. Every designator is listed separately, so the BOM matches the 65 CPL rows.
  - **13 extended part types** (v14 had 14): U1 C3013941, U2 C424093, U3 C841192, U4 C53099, U5 C53100, U6 C138713, U7 C7519, D7 C193402, J1 C6364666, J3 C46061768, J4 C295747, **J5 C2919501**, **R23 C22810** (15 Ω, new in review 14). L1, Q3, R12 and the second C6364666 socket (J2) are gone.
  - Everything else is Basic (Q4 is the same AO3401A C15127 as Q1/Q2; Q5 AO3400A C20917 is Basic).
- Stock on 2026-10-08 21:30 (review 14): **U1 ESP32-S3-MINI-1-N4R2 C3013941: 1,218** (the tightest), J5 C2919501: 2,242, R23 C22810: 314,584. **If U1 is out of stock, accept no substitute** (an N8R8 loses IO33–37, which the board uses): order the bare PCBs and ask for a pre-order of C3013941.
- **Ignore the "not in BOM" note** for TP1–TP7, FID1–3, H* and SW1–SW50. They are bare copper, not parts.
- The LCD panel is **not** on the BOM: it plugs into J5 by hand.
- If any line says "consign" or "pre-order", stop and ask.

## 5. Placement preview: what each part must look like

"Top-left" etc. is as seen in `fab_v15_lcd/render_top.png` (component side, board top edge at the top of the picture). Coordinates are KiCad (x, y) in mm.

| Part (KiCad x, y) | Must look like |
|---|---|
| **J5** LCD socket (158.6, 93.1) | Opening facing **right**, towards the slot (x 180.5–181.5); the row of 30 pads on the **left**. **J5's pin numbering is intentionally reversed, like J1's.** JLCPCB's pin-1 mark will be at the **top** end; our pad 1 and the silk tick are at the **bottom** (157.4, 100.35). That is correct. **Don't rotate it.** Align by the pads and the two mounting tabs. |
| **Q4** LCD power switch, AO3401A (159.5, 103.9), just below J5 | The single pin 3 at the **top**, pins 1/2 at the bottom (same as Q2) |
| **Q5** backlight switch, AO3400A (157.3, 82.3), just above J5 | The single pin 3 at the **bottom**, pins 1/2 at the top |
| **D7** TVS (119.2, 73.4) | Band on the **right** pad, towards J3 (KiCad x 120.65, the VBUS pad). **This one matters most:** backwards, it shorts the charging cable. |
| **U1** ESP32 (127.55, 97.0) | The antenna end (no pads) hanging off the **left** board edge. If the model sits sideways from the pads, ask them to align it to the pads. |
| **U6** TCA8418 (126.0, 146.5) | Pin-1 dot **top-left** |
| **J1** camera socket (150, 161) | Opening facing **up**, towards the camera area. JLCPCB's pin-1 mark will be at the **right** end: that is correct. **J1's pin numbering is intentionally reversed. Don't rotate it.** Align by the pads and the two mounting tabs. |
| **J3** magnet header (127.5, 72.0) | The 4 socket openings face the **top edge**; the body hangs about 0.4–1 mm past the edge. The 4 contacts are identical, so "pin 1" doesn't matter here. Only the direction does: body towards the edge, never over D1/D6/U7. |
| **J4** battery socket (142.6, 74.6) | Opening facing **down**; the two small pins at the top, the big tabs at the bottom |
| U2, U3, U4, U5 (SOT-23-5) | Pin-1 dot **top-left** (3-pin side on the left), as v14 |
| U7 (SOT-23-6, 133.6, 83.2) | Pin-1 dot **top-left** |
| Q1 (136.1, 79.5) | Pins 1–2 on the **left**, the single pin 3 on the **right** |
| Q2 (135.9, 75.6) | The single pin 3 at the **top**, pins 1/2 at the bottom |
| D1, D2, D6 | Band on the **left** pad |
| R23 (161.0, 80.6), 15 Ω 0603 | Not polarised; just check it sits on its two pads |

**Don't rotate anything.** If a part seems to disagree, stop and ask Claude (or JLCPCB's engineer) before clicking anything: it's more likely a reading mistake than a wrong file.

## 6. Order notes (paste into the "remark" box)

> J1 and J5 pin numbering is intentionally reversed vs. the library footprints: please align J1 and J5 to their pads and mounting tabs, do not rotate them. U1 antenna and J3 body overhang the board edges on purpose (left and top edges). Edge rails: please add them on the right and bottom edges only, and remove them before delivery (depanel). Please X-ray U1 and U6. Please do not substitute U1 (ESP32-S3-MINI-1-N4R2, C3013941). OK to pull back copper locally if any copper is too close to a hole or the slot.

## 7. If JLCPCB's engineers email you

Answer within a day, or the order waits.

| They ask about | Answer |
|---|---|
| "Component exceeds the board edge" (U1, J3) | **Intended, please keep.** The U1 antenna overhang is Espressif's recommended placement. J3 overhangs for the magnet connector. |
| Edge rails / conveyor clearance | Rails on the **right and bottom edges only**, removed before delivery. Keep the left edge (antenna) and the top edge (J3) free. A small rail fee is fine. |
| Copper too close to a hole / NPTH / slot / board edge | **OK to pull back copper locally.** Everything is already ≥ 0.25 mm from every hole and ≥ 0.30 mm from the slot. |
| J1 or J5 pin 1 doesn't match the library | **Intentionally reversed** (the ribbons arrive mirrored). Align by pads and mounting tabs; don't rotate. |
| D7 polarity | Cathode band on the pad towards J3 (KiCad x 120.65, the VBUS pad). |
| Pin-1 silk marks too thin to print | Fine. Use the pads / the assembly drawing. |
| Oval holes / the slot | Intended non-plated slots; the 1.0 × 20 mm slot is a routed cut-out for the LCD ribbon. |
| Drill-map files are "unknown layers" | Ignore them, or delete the two `*-drl_map.gbr` files from the zip and re-upload. |
| A part is out of stock / needs a substitute | Stop and check with Claude before accepting a substitute. **Never** for U1. R23 may only be another **15 Ω** 0603 (not 10, 12, 20 or 22 Ω). |

## 8. Expected cost (2026-10 prices; check the final quote)

v14 (5 PCBs, 5 assembled) came to about **$275 delivered**. v15 has **one fewer extended part type** (13 × $3 instead of 14 × $3; R23 C22810 is new, but L1, Q3 and R12 left) and a board BOM about **$0.19 cheaper** per board, so expect about the same:

| Item (5 PCBs, 5 assembled) | Estimate |
|---|---|
| 5 PCBs, 2-layer, 71.7 × 148.9, 0.8 mm, ENIG, remove mark | $25–40 |
| PCBA setup (Standard) + stencil | about $33 |
| Extended part fees (13 × $3) | $39 |
| Parts (5 boards; ESP32 module ≈ $5 each) | $70–75 |
| Solder joints, edge rails, depanel, misc | about $5–12 |
| **Subtotal** | **about $172–199** |
| Shipping (DHL/FedEx express) | $20–35 |
| US import duty, collected at checkout (about 35–37.5 %) | about $60–65 |
| **Total delivered** | **about $255–285 (≈ $270)** |

With only 2 assembled the total drops to about $195–235. Timing: about **10–14 days door-to-door**. If the quote is far above this (for example over $230 before shipping), something is mis-ticked: look for a consigned part, "Economic" instead of "Standard", or a PCB qty other than 5. The cost model uses $270 (`production/COST_MODEL.xlsx`, Inputs "v15-LCD JLCPCB order"); replace it with the real total.

## 9. After the boards and panels arrive (bench checks)

None of these blocked the order; all are recoverable on this board (review 14 §6). Step by step: the **v15 Power-Up guide** `bringup_guide_v15_lcd.html` (https://claude.ai/artifact/BeQnacuLhchaHz492CnLRT) and the **v15 Assembly guide** (https://claude.ai/artifact/FU8YVqaksDPk2cfiD2cz3f); checklist: `ARRIVAL_CHECKLIST.md`, v15 section.

- **Magnet piece, battery polarity, camera ribbon:** exactly as v14 (`ORDER_WALKTHROUGH.md` step 9; J3 is 1 VBUS, 2 D−, 3 D+, 4 GND). Magnet parts: Adafruit #5358 + #5412, or the equivalent Yiwei MG04254FRA1S1N piece (same part as #5358) + MG0425-UB-60-4P cable (GND, D+, D−, V+ from its N end, like #5412); meter check before gluing either way.
- **Pin-1 end of the panel tail: diode test on the first ER-TFT019-1, before it is plugged in.** The LED sits between finger 20 (anode) and finger 22 (cathode), i.e. the 11th and 9th fingers from the pin-30 end. Mark the finger-1 corner. Plugged in with no twist, finger 1 must land at the **J5 silk tick (bottom)**, the LED fingers in the top half. If not: nothing is damaged; a half twist of the tail fixes it.
- **Backlight current:** volts across R23 ÷ 15 at 100 %. Expect **16–37 mA (≈ 26 mA typical)**; it cannot exceed the 60 mA rating.
- **Panel at 3.3 V:** picture quality (3.3 V is the top of its 2.4–3.3 V range); IDD ≤ 20 mA.
- **Colours:** `LCD_INVERT` / `LCD_RGB_ORDER` build flags (`firmware-v15-lcd/PORT_NOTES.md`).
- **Tail length 36.6 ± 0.3 mm** and the bow's clearance to rib B (assembly guide, marker dot).
- **Feel of the three moved keys** SHIFT (SW1), ALPHA (SW2) and ON (SW50), now centred on the Casio contacts.
- **Recovery** if a board won't take firmware: as v14 (TP1 to TP4, tap TP7, flash). Never burn an eFuse. Flash only `firmware-v15-lcd/` to a v15 board.

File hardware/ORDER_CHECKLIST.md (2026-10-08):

# JLCPCB order checklist (stage 14, silk "AI CALC v14 2026-10-04")

One order, no second board. The full click-by-click version, with the meter checks, is `ORDER_WALKTHROUGH.md`. Overall status and what's left: `FINAL_STATUS.md`.

**Board state:** DRC 0 errors / 0 warnings / 0 unconnected / 0 schematic-parity issues. ERC 0. Every copper item is ≥ 0.25 mm from every hole. What stage 14 fixed is in `stage14_verification_fixes.md`.

## Before paying
- [ ] **Paper dry fit:** print `Claude outputs/paper_dry_fit_v14.svg` at 100 %, check the printed 50 mm line measures 50 mm, cut it out **with the antenna tab** and lay it in the front shell; the tab must clear the side wall's inner rib (if not: grinding zone 6, plastic only). Then the pre-grind checklist in `verification/07_final_review_fitment.md`. Every post must sit inside its hole (H2/H3/H6/H9/H13/H14 and the screw posts); H6 has the least play. Off by more than about 0.5 mm → stop and ask.
- [ ] Use the files in `fab/`, regenerated by `tools/make_outputs.sh` (stage 14). Don't use the older `verification/ai_calc_CPL_JLCPCB_corrected.csv`: it's the same data, but `fab/` is the maintained copy.

## Files
| Upload where | File |
|---|---|
| "Add gerber file" | `fab/ai_calc_gerbers_JLCPCB.zip` |
| PCB Assembly → BOM | `fab/ai_calc_BOM_JLCPCB.csv` |
| PCB Assembly → CPL | `fab/ai_calc_CPL_JLCPCB.csv` (**already rotation-corrected** for JLCPCB: Q1 180, Q2 270, U2/U3/U7 270, U4/U5 180, J3 180) |

## PCB options
2 layers · qty **5** · **0.8 mm** · **ENIG** · green · tented vias · "Specify a location" for the order number · everything else default.

## Assembly options
**Standard** PCBA · top side · qty **2** · tooling holes by JLCPCB · confirm parts placement **Yes**.

## In the placement preview
The CPL is corrected, so **don't rotate anything: only verify** against the table in `ORDER_WALKTHROUGH.md` step 5. If something disagrees, stop and ask before clicking. The ones that matter most:
- **D7** band on the **right** pad (towards J3).
- **U2/U3/U4/U5/U7** pin-1 dot top-left.
- **Q1:** single pin on the right. **Q2:** single pin at the top.
- **U1:** antenna off the left edge.
- **J3:** openings face the top edge.
- **J1: pin numbering is intentionally reversed. Don't rotate it.** Align it by its pads and tabs; JLCPCB's pin-1 mark sits at the right-hand end.

## Order notes (paste)
> J1 pin numbering is intentionally reversed vs. the library footprint: please align J1 to its pads and mounting tabs, do not rotate it. U1 antenna and J3 body overhang the board edges on purpose (left and top edges). If rails are needed, please put them on the right and bottom edges only. Please X-ray U1 and U6. OK to pull back copper locally if any copper is too close to a hole.

## If the engineers email
- **Board-edge overhang (U1, J3):** intended, keep.
- **Rails:** right and bottom edges only.
- **Copper near a hole:** OK to pull back copper locally.
- **J1 pin 1:** intentionally reversed, don't rotate.
- Full answer table: `ORDER_WALKTHROUGH.md` step 7.

## Expected cost
About **$135–155 before shipping** (5 PCBs + 2 assembled; 14 Extended parts × $3). About **$200–240 delivered** (+ $20–40 express shipping and US import duty about 35–37.5 % collected at checkout (the de-minimis exemption has been suspended since 2026-06-24)). Much more than that means something was mis-ticked. Door-to-door about **10–14 days** (economy shipping 7–15 days on its own if express isn't offered).

## After it arrives (before anything is plugged in)
1. **Battery:** red wire vs J4 "+". If it's reversed, swap the crimp pins.
2. **Camera ribbon:** fingers 2 and 15 beep to GND.
3. **Magnet piece, before gluing:** with the real cable on a phone charger, find the +5 V leg and put it in **J3 pin 1** (silk "N" / "+"). The GND leg goes in **pin 4** (silk "−"). D−/D+ must beep through to USB-A pins 2/3. Full steps: `ORDER_WALKTHROUGH.md` → "Magnet piece".
4. **First power-up** from USB only. TP5 = 3.3 V, TP7 = EN, TP4 = GND, TP1 = BOOT, TP2/TP3 = UART.
5. **Recovery if flashing ever fails:** hold TP1 → TP4, tap TP7 → GND, flash. Never burn the security or USB-disable eFuses.

## Before closing the case
Grind list (`stage13_heights.md` §6, updated by the final assembly; guide: https://claude.ai/artifact/9rCWyw8MeHP2z8FWijnyfL):
- Solar box flat to the floor.
- Rib B flat for 14 mm over the camera.
- **Not** the LR44 cup: the battery lies flat on the back-cover floor (`enclosure/final_assembly/assembly_report.md`).
- Back-cover lip at the magnet notch (5b), only if your cover has a lip there.
- Camera window Ø 7 mm. Drill it where the lens actually ends up after taping the module down: the camera ribbon has only about 1.4 mm spare (see `stage14_verification_fixes.md`, fix 6).
- Magnet U-notch.

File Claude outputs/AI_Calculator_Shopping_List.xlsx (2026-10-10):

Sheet: Budget
What the 2026-10-08 plan costs now, against the $2,000 budget
All black cells are formulas from the other two sheets. The rest of the $2,000 plan (knockoff samples, pilot, legal) is in hardware/production/COST_MODEL.xlsx 'Cash budget'.
Item | Amount | Notes
Option A, all current parts: 5 testers |  | Plan ≈ $670.
Option B, all generic screen / camera / battery: 5 testers |  | Plan ≈ $575. Cheapest, but every unit carries the untested generic parts.
Option C, units 1–3 current, 4–5 generic: 5 testers (recommended) |  | Plan ≈ $670.
Chosen option |  | Switch on the 'Testers v14 (5 units)' sheet.
Chosen option total
…of which the JLCPCB v14 order (paid 10/8)
…still to buy for the testers
v15-LCD: 3 × BuyDisplay ER-TFT019-1 + the v15 JLCPCB order |  | v15 verified ORDER (review 14). Panels ≈ $32, board order ≈ $270 (estimate).
SPEND NOW (testers + v15 order + panels)
Budget | $2000.00 | Business plan: $2,000 total budget.
LEFT after these, for the rest of the plan |  | Covers knockoff samples, pilot, server, legal: see COST_MODEL.xlsx 'Cash budget'.
Share of the budget spent now

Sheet: Testers v14 (5 units)
AI Calculator: 5 v14 e-paper TESTERS in genuine Casio fx-115ES shells. Options A / B / C side by side; the switch picks one.
Updated 2026-10-08. Blue = inputs/estimates you can edit (yellow cells); black = formulas. v14 is ordered at JLCPCB (git tag v14-order). Prices: Adafruit/Seeed/Waveshare checked 2026-10-03/06; generic prices are AliExpress-level estimates; JLCPCB delivered ranges from hardware/FAB_VENDOR_COMPARISON.md.
Inputs
Option chosen (A / B / C) |  | C | A = all current parts (Seeed camera, Waveshare screen, Adafruit battery). B = all generic. C = units 1–3 current, 4–5 generic (recommended: known-good parts first, generic ones tested on 2 units).
Tester units to build |  | 5 | Plan 2026-10-08: 5 testers.
JLCPCB boards assembled (PCBA qty, 2 or 5) |  | 5 | Nirav was choosing 2 vs 5 at checkout on 10/8. Assumed 5; set 2 if you picked 2 (then only 2 testers can be built until more boards come).
JLCPCB delivered, 5 PCBs with 2 assembled |  | $220.00 | ≈ $200–240 incl. DHL and ~35 % US duty collected at checkout (DDP); midpoint. Replace with the real order total.
Extra delivered cost for 5 assembled instead of 2 |  | $55.00 | ≈ $50–60 more (parts + assembly for 3 more boards, incl. ~35 % duty). Midpoint.
Casio fx-115ES shells you already own |  | 2 | You own 2 (one is the measured one).
Casio fx-115ES price each |  | $20.00 | Walmart $19.99 (LAUNCH_ROADMAP.md [S6]); tax not included. Must be the SAME edition you measured.
Spares per part kind (camera, screen, battery, magnet piece) |  | 1 | 6 of each for 5 units = 1 spare. In option C each kind (current and generic) gets its own spare.
 |  |  |  |  | Option → | A | B | C
Units built with CURRENT parts (Seeed camera, Waveshare screen, Adafruit battery) |  |  |  |  |  |  | 0 | 3
Units built with GENERIC parts (GDEY0213B74, generic OV5640 AF, 302030 cell)
# | Item | Vendor | Link | Part / SKU | Unit $ | Qty A | Qty B | Qty C | Total A | Total B | Total C | Qty (chosen) | Total (chosen) | Order by | Why / notes
 | JLCPCB board order (v14, ordered 2026-10-08)
1 | JLCPCB v14: 5 PCBs, 2 assembled, DELIVERED (incl. DHL + US duty) | JLCPCB | https://jlcpcb.com | ai_calc_pcb_14.zip / tag v14-order |  |  |  |  |  |  |  |  |  | Ordered 10/8 | 2-layer, 0.8 mm, ENIG, Standard PCBA. Delivered ≈ $200–240 (duty ~35 % collected at checkout, de-minimis suspended). Boards ≈ 10/18–22.
2 | JLCPCB: boards 3–5 assembled too (per extra board) | JLCPCB | https://jlcpcb.com | PCBA qty 5 |  |  |  |  |  |  |  |  |  | Ordered 10/8 | ≈ $50–60 more for all 3, incl. duty. Qty follows the PCBA input (5 assembled → 3 extra).
 | Shells
3 | Casio fx-115ES donor calculator (buy the missing ones) | Walmart / Target / Staples | https://www.walmart.com/ip/418401755 | fx-115ES PLUS (same edition) |  |  |  |  |  |  |  |  |  | Before boards land | You own 2, buy 3. Check the box shows the same edition you measured (PLUS vs PLUS 2nd edition): posts and ribs can differ.
 | Per-unit parts: CURRENT (known-good) vs GENERIC (cheaper, needs checking)
4 | Camera OV5640 AF for XIAO ESP32S3 Sense (CURRENT) | Seeed / DigiKey | https://www.seeedstudio.com/catalogsearch/result/?q=OV5640%20XIAO | 114993115 | $12.99 |  |  |  |  |  |  |  |  | Now | J1 (reversed) was worked out for THIS ribbon. Seeed $12.99; DigiKey US $11.99 was faster on 10/6. Avoid the $46 Newegg reseller.
5 | Camera OV5640 AF, generic 24-pin 0.5 mm DVP (GENERIC) | AliExpress | https://www.aliexpress.us/w/wholesale-ov5640-af-24pin.html | OV5640 AF 24-pin | $7.00 |  |  |  |  |  |  |  |  | Now | ≈ $7 (estimate; listings $4.58–8). BEFORE plugging in: beep test E6, fingers 2 and 15 must beep to GND, and the ribbon length/contact side must match the Seeed one. Wrong pinout = no image (no damage).
6 | Waveshare 2.13" e-Paper raw panel V4, B/W, SSD1680 (CURRENT) | Waveshare / Amazon Prime | https://www.waveshare.com/2.13inch-e-Paper.htm | SKU 12672 | $6.99 |  |  |  |  |  |  |  |  | Now | $6.31–6.99. You also own 1 in your HAT: lower the qty by 1 if you will use it.
7 | Good Display GDEY0213B74 2.13" e-paper (GENERIC) | AliExpress / Good Display | https://www.good-display.com/product/391.html | GDEY0213B74 | $4.50 |  |  |  |  |  |  |  |  | Now | ≈ $4.50 (estimate). Same 250 × 122 SSD1680 family, 24-pin 0.5 mm FPC, same pin order as the V4: compare one with the Waveshare panel before relying on it.
8 | LiPo 3.7 V 150 mAh JST-PH, 26 × 19.75 × 3.8 mm (CURRENT) | Adafruit | https://www.adafruit.com/product/1317 | #1317 | $5.95 |  |  |  |  |  |  |  |  | Now | Fits with no grinding. Meter-check polarity before plugging in (red = + on J4 pad 2).
9 | LiPo 302030 150 mAh with PCM, JST-PH 2.0 (GENERIC) | AliExpress / Amazon | https://www.aliexpress.us/w/wholesale-302030-lipo-jst-ph.html | 302030 | $3.00 |  |  |  |  |  |  |  |  | Now | ≈ $3 (estimate). 30 × 20 × 3 mm fits the 33.5 × 20.7 × 3.8 envelope. Generic JST leads are OFTEN REVERSED: meter it, swap pins if needed. Must have a protection board (PCM). Candidate: Taiwoo TW302030 (140 mAh, 30 × 20 × 3.0, Alibaba): CAD fit-checked 2026-10-10 (v14 + v15), it fits when placed 1 mm LEFT of the #1317 position (left edge ~1.7 mm from the corner post, top edge 0.8 mm from the lip); same tape L. Order: PCM, JST-PH 2.0 red (+) on pin 2, 50–80 mm leads, UN38.3 + MSDS (hardware/enclosure/final_assembly/battery_upgrade.md).
10 | Magnetic connector, 4-pin right angle, both halves (all options) | Adafruit | https://www.adafruit.com/product/5358 | #5358 | $6.50 |  |  |  |  |  |  |  |  | Now | Legs straightened into J3. Meter-check against the cable before gluing. Alternate (2026-10-10, from Nirav): Yiwei MG04254FRA1S1N is the same part as #5358. Not price-checked.
11 | Magnetic USB charging cable for the 4-pin (all options, 1 per tester) | Adafruit | https://www.adafruit.com/product/5412 | #5412 | $4.95 |  |  |  |  |  |  |  |  | Now (low stock) | Charges AND flashes. Stock was ~35 on 10/6: order first. Backup: Jameco / DigiKey. Alternate (2026-10-10, from Nirav): Yiwei MG0425-UB-60-4P = equivalent of #5412; reads GND, D+, D−, V+ from its N end, like #5412. Same J3 order (1 VBUS, 2 D−, 3 D+, 4 GND, N end at pin 1) and the same meter check before gluing. Not price-checked.
 | Shipping
12 | Adafruit shipping (UPS 2nd Day), one box | Adafruit | https://www.adafruit.com | — | $15.00 |  |  |  |  |  |  |  |  | Now | Estimate. The v15 panels now come from BuyDisplay (sheet 'v15-LCD prototype'), not in this box.
13 | Seeed / DigiKey shipping (only if current cameras) | Seeed | https://www.seeedstudio.com | — | $12.00 |  |  |  |  |  |  |  |  | Now | Estimate.
14 | Waveshare shipping (only if current screens) | Waveshare | https://www.waveshare.com | — | $20.00 |  |  |  |  |  |  |  |  | Now | Estimate; $0 with Amazon Prime.
15 | AliExpress shipping (only if generic parts) | AliExpress | https://www.aliexpress.us | — | $10.00 |  |  |  |  |  |  |  |  | Now | Estimate (Choice shipping, 7–15 days). Batteries may ship separately.
 | Supplies and tools (same for every option; ≈ $61)
16 | Kapton tape (10–20 mm) | Amazon | https://www.amazon.com/s?k=kapton+tape+10mm | — | $9.00 | 1 |  |  |  |  |  |  |  | This week | Insulates the battery, camera and e-paper back. Estimate.
17 | Thin double-sided tape 0.1 mm (camera, battery) + about 0.15 mm for the e-paper | Amazon | https://www.amazon.com/s?k=thin+double+sided+tape+0.1mm | — | $10.00 | 1 |  |  |  |  |  |  |  | This week | No foam anywhere: only 0.3 mm above the battery and 0.5 mm above the lens. Estimate.
18 | Plastic glue / 2-part epoxy | Hardware store | — | — | $6.00 | 1 |  |  |  |  |  |  |  | This week | Glues the magnet piece into the top-wall slot. Estimate.
19 | 7 mm drill bit (9/32" OK) + 2–3 mm pilot bit + deburring tool | Hardware store | — | — | $12.00 | 1 |  |  |  |  |  |  |  | This week | Camera window in the back cover at KiCad (150, 95.1): pilot first, then 7 mm, then deburr. Estimate.
20 | Matte black vinyl sheet (window mask, 47.75 × 22.90 mm opening) | Amazon | https://www.amazon.com/s?k=matte+black+adhesive+vinyl+sheet | — | $8.00 | 1 |  |  |  |  |  |  |  | This week | Hides the board edge beside the e-paper glass (hardware/enclosure/final_assembly/window_mask.md). Estimate.
21 | Isopropyl alcohol 99 % | Amazon / pharmacy | https://www.amazon.com/s?k=99%25+isopropyl+alcohol | — | $6.00 | 1 |  |  |  |  |  |  |  | This week | Cleans the ENIG pads and the window. Estimate.
22 | Safety glasses + dust mask | Hardware store | — | — | $10.00 | 1 |  |  |  |  |  |  |  | This week | Grinding and drilling (ABS dust). Estimate.
23 | USB-A 5 V charger or USB-C→USB-A adapter (only if you have none) | Amazon | https://www.amazon.com/s?k=usb-a+5v+wall+charger | — | $8.00 | 0 |  |  |  |  |  |  |  | This week | Qty 0 = you have one (that is how the $61 is counted). Set 1 if not.
 | TOTAL for 5 testers |  |  |  |  |  |  |  |  |  |  |  |  |  | Plan figures: A ≈ $670, B ≈ $575, C ≈ $670 (recommended C).
 | …of which the JLCPCB order (already paid on 10/8)
 | …still to buy (everything else)
 | Per tester (total ÷ testers)
 | Chosen option
Not on this list (you already have them): 2 Casio fx-115ES calculators, calipers, multimeter, 1 Waveshare e-paper panel (in the HAT), a rotary tool for the grinds. Casio screws are reused.
Option C detail: units 1–3 get the known-good Seeed/Waveshare/Adafruit parts so the first builds isolate board problems; units 4–5 test the generic parts that bulk will need. Each kind gets 1 spare.

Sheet: v15-LCD prototype
v15-LCD prototype: the v15 JLCPCB order and the panels for it
v15-LCD board verified "ORDER" in hardware/verification/14_v15_final_preorder.md (2026-10-08). Panel: BuyDisplay ER-TFT019-1, no-touch version (datasheet checked pin for pin; hardware/LCD_PANEL_OPTIONS.md). Buy 3 panels and order the v15 board (hardware/ORDER_WALKTHROUGH_v15_lcd.md). Bench checks at arrival: diode test (pin-1 end), backlight V(R23)/15, panel at 3.3 V, colour flags, tail 36.6 ± 0.3 mm, the 3 moved keys. Adafruit #5394 is only an optional fallback now.
# | Item | Vendor | Link | Part / SKU | Unit $ | Qty | Line total | When | Why / notes
1 | BuyDisplay ER-TFT019-1 1.9" 170×320 IPS, ST7789P3, 30-pin 0.5 mm FPC, NO touch | BuyDisplay (East Rising) | https://www.buydisplay.com/full-viewing-angle-spi-1-9-inch-ips-tft-lcd-display-panel-170x320-st7789 | ER-TFT019-1 | $6.75 | 3 |  | Now, with the v15 order | ~$6–7 each at 1–9 pcs (6.75 = estimate inside that range; confirm at checkout); $6.22 @10, $5.71 @100. Same glass as the board was designed for; pin 1 lands at the J5 silk tick. Do NOT add the ER-CON30HT-1 socket (J5 is on the board).
2 | BuyDisplay shipping | BuyDisplay | — | — | $12.00 | 1 |  | Now | Estimate, not quoted: replace with the checkout figure.
3 | v15-LCD JLCPCB order: 5 PCBs, 5 assembled (Standard PCBA), delivered incl. DHL + ~35 % duty | JLCPCB | https://jlcpcb.com | hardware/fab_v15_lcd/ (21:38 files) | $270.00 | 1 |  | Now | Estimate ≈ $255–285 (ORDER_WALKTHROUGH_v15_lcd.md §8): v14 was $275; v15 has one fewer extended part type (13 vs 14, ~$3) and a ~$0.19/board cheaper BOM. Replace with the real total.
4 | Optional fallback: Adafruit 1.9" 320×170 IPS breakout #5394 (same 30-pin glass inside) | Adafruit | https://www.adafruit.com/product/5394 | #5394 | $17.50 | 0 |  | Only if needed | Fallback only (qty 0). $17.50 (1) / $15.75 (10+). The breakout does not fit the calculator: take the panel off it.
5 | Adafruit shipping (only if the fallback is bought) | Adafruit | — | — | $10.00 |  |  | Only if needed | Estimate ≈ $10 if ordered on its own.
6 | Optional bulk check: Alibaba Goldenmorning T190X7-C30-01 sample (plastic frame) | Alibaba (Shenzhen Goldenmorning) | https://www.alibaba.com/product-detail/1-9-Inch-IPS-TFT-LCD_1601731552729.html | T190X7-C30-01 | $2.50 | 0 |  | Later, before bulk | $1.85–2.50, MOQ 1 (search snippets). Ask for the plastic-frame (~1.4 mm) build. ZJY (~$2.30–2.50) is the other bulk candidate. Qty 0 = not now.
7 | Alibaba express shipping (only if the sample is bought) | Alibaba | — | — | $20.00 |  |  | Later | $15–30 by express for a few panels (LCD_PANEL_OPTIONS.md).
 | TOTAL to buy now (3 panels + the v15 order)
 | …of which the panels (rows 1–2)
 | Board parts JLCPCB places on the v15 order (inside row 3, info only)
 | Board part | LCSC |  |  | Unit $ (JLCPCB 10/8) | Qty / board | Per board
J5 | HDGC 0.5K-HX-30PWB 30-pin 0.5 mm FPC socket, dual contact (LcdReversed footprint) | C2919501 |  |  | $0.360 | 1
Q4 | AO3401A P-MOSFET (LCD power switch) | C15127 |  |  | $0.100 | 1
Q5 | AO3400A N-MOSFET (backlight switch) | C20917 |  |  | $0.090 | 1
R21, R22, C36 | 100 k ×2, 100 nF | C25741 / C1525 |  |  | $0.002 | 3
R23 | 15 Ω 0603 (was 22 Ω until review 14; extended part, ~$3 one-off fee) | C22810 |  |  | $0.001 | 1
 | Added parts per v15 board (the 17 removed e-paper parts make the board ≈ $0.19 cheaper overall)
The rest of the $2,000 plan (knockoff samples, pilot, legal) is in hardware/production/COST_MODEL.xlsx 'Cash budget' (rows 3–4 there = this sheet).

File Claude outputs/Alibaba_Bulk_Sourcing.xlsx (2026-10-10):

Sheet: Cost by batch
AI Calculator: bulk cost per unit at 10 / 100 / 1,000 units (knockoff 991ES-style shell)
Prices as of 2026-10-05. Blue = estimate inputs you can edit; black = formulas. Sources: 'Supplier options' and 'Sources' sheets, and Claude outputs/LAUNCH_ROADMAP.md §3 (JLCPCB, freight). Alibaba pages sit behind a CAPTCHA for automated reading, so listing prices come from search-index snippets: confirm every number by RFQ before paying. Battery updated 2026-10-06: Adafruit #1317 150 mAh (26 × 19.75 × 3.8) replaces the #1570 100 mAh.
 |  |  |  |  |  |  |  |  |  |  |  |  | Batch size → | 10 | 100 | 1000 | ← edit batch sizes here
# | Category | Item & key spec | Source @10 | Source @100 | Source @1,000 | Main link | Qty / unit | Unit $ @10 | Unit $ @100 | Unit $ @1,000 | Per-unit $ @10 | Per-unit $ @100 | Per-unit $ @1,000 | Batch total @10 | Batch total @100 | Batch total @1,000 | Price basis / notes
1 | PCBA | Main board v14: PCB 2-layer 0.8 mm ENIG + Standard PCBA (ESP32-S3-MINI-1, TCA8418, LDOs, FPCs, passives) | JLCPCB | JLCPCB | JLCPCB (Economic/Standard PCBA) | link (https://jlcpcb.com/quote) | 1 | $18.00 | $9.00 | $7.30 |  |  |  |  |  |  | LAUNCH_ROADMAP.md §3 price-scaling table (JLCPCB + LCSC breaks, estimate). Stays with JLCPCB at all sizes. Extended-part fees ($3 x 14 types) vanish into per-unit cost at 100+.
2 | Shell | Knockoff 991ES PLUS-style calculator (shell, key mat, window, screws, slide cover); board removed | AliExpress / Amazon (MOQ 1) | Alibaba (MOQ ~20-50) | Alibaba factory (same mould, MOQ 500-3,000) | link (https://www.alibaba.com/product-detail/Multifunctional-Function-Calculator-991ES-PLUS-Scientific_1600201758973.html) | 1 | $6.00 | $3.99 | $3.25 |  |  |  |  |  |  | Alibaba listing seen at $3.25-3.99, MOQ 20 [S1]; factories quote $1.50-3.50 at MOQ 3,000 [S2]. @10 = retail clone incl. shipping (estimate).
3 | Camera | OV5640 AF, 24-pin 0.5 mm FPC DVP, Seeed XIAO-Sense pinout, AF lens | Seeed SS114993115 (known pinout) | Alibaba OEM (V-Vision etc.) after pinout check | Alibaba OEM, custom FPC length | link (https://www.alibaba.com/product-detail/Auto-Focus-OV5640-camera-OEM-24pin_60812933393.html) | 1 | $12.00 | $6.00 | $4.50 |  |  |  |  |  |  | Roadmap table [S8]; Alibaba OV5640 24-pin modules ~$5-18 [S3]; eBay/AliExpress AF 24-pin ~GBP 7.49 [S4].
4 | Display | 2.13" B/W raw e-paper, SSD1680, 250x122, 24-pin 0.5 mm FPC (GDEY0213B74 / Waveshare V4 family) | Waveshare raw panel | Good Display direct (RFQ) | Good Display direct (RFQ) | link (https://www.good-display.com/product/391.html) | 1 | $6.60 | $5.50 | $4.00 |  |  |  |  |  |  | Waveshare $6.31-6.99 [S8]; GDEY0213B74 retail ~EUR 6.89 [S5]; volume price by RFQ to buyepaper@good-display.com (estimate).
5 | Battery | LiPo 3.7 V ~150 mAh with PCM, JST-PH 2.0 plug (red = +, Adafruit polarity), Adafruit #1317 class 26 × 19.75 × 3.8 mm; max 33.5 × 20.7 × 3.8 mm incl. PCM fold | Adafruit #1317 | Alibaba stock cell + PH2.0 lead | Alibaba custom cell (~382026 / 402025 class, 150 mAh) with certs | link (https://www.adafruit.com/product/1317) | 1 | $5.95 | $1.80 | $1.30 |  |  |  |  |  |  | Adafruit #1317 $5.95 [S8] (switched from the 100 mAh #1570 on 2026-10-06; same price). Alibaba 401230 listings $0.56-1.60 [S6] are 100 mAh references (401230 is 4.0 x 12 x 30: too thick and wide); ask for a ~150 mAh cell in 26 x 20 x 3.8. @100/@1,000 include PH lead + PCM (estimate). Named bulk candidate (2026-10-10): Taiwoo TW302030, 140 mAh, 30 × 20 × 3.0; fits the fx-115ES spot in CAD when placed 1 mm left of the #1317 position ('Supplier options' row 49); price not yet quoted, so the estimates stand.
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

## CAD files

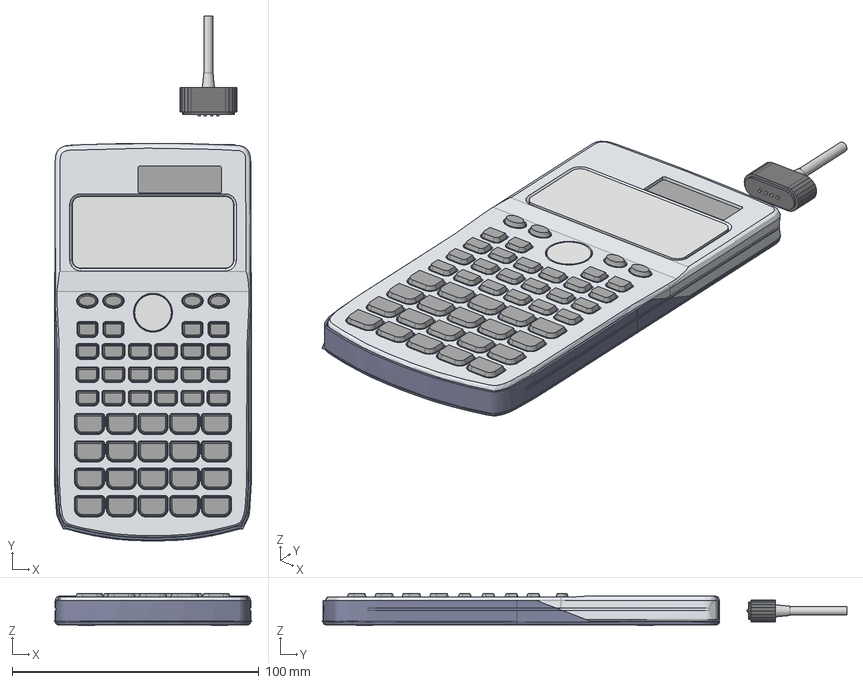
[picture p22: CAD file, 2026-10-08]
hardware/enclosure/final_assembly/ai_calculator_final_assembly.step
79.9 x 212.9 x 13.1 mm
C_1206_3216Metric_1
SOT-23-6_1
C_0603_1608Metric_1 x 16
FPC-SMD_24P-P0.50_FPC-0.5-24P-HYH2.0_1 x 2
R_0402_1005Metric_1 x 19
C_0805_2012Metric_1 x 4
C_0402_1005Metric_1 x 13
HX_PM2.54-1x4P_WT
CONN-SMD_P2.00_S2B-PH-SM4-TB-LF-SN_1
D_SOD-123_1 x 6
D_SMF_1
SOT-23-5_1 x 4
L_0603_1608Metric_1
IND-SMD_L4.0-W4.0-H2.0_1
SOT-323_L2.0-W1.3-H1.0-LS2.1-P1.30_1
BULETM-SMD_ESP32-S3-MINI-1-N8
R_0603_1608Metric_1
SOT-23_1 x 2
HVQFN_24_1EP_4x4mm_P05mm_EP21x21mm
ai_calc_PCB

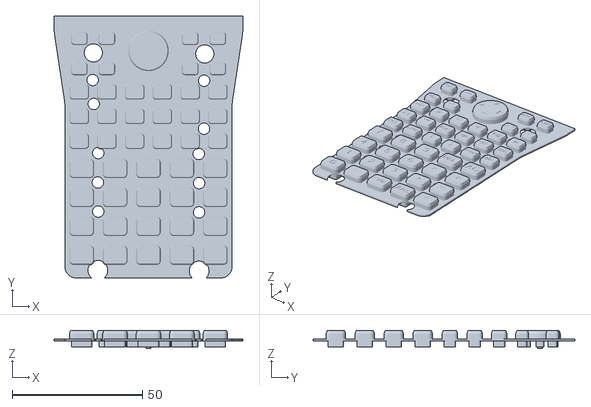
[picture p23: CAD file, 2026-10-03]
hardware/enclosure/export/keymat_TPU.stl
72.5 x 100.7 x 6.95

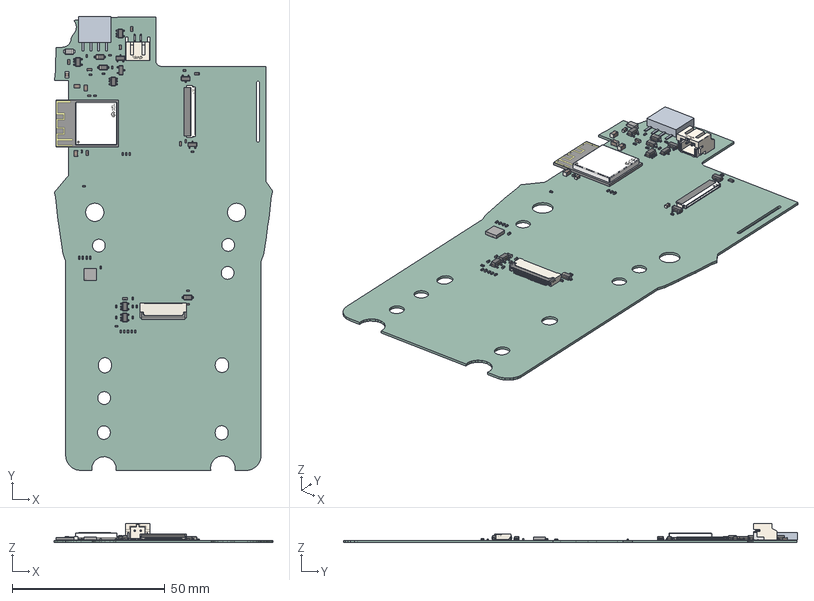
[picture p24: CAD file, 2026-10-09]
hardware/enclosure/final_assembly_v15_lcd/board/ai_calc_v15_lcd_board.step
71.6 x 148.8 x 6.30 mm
SOT-23-6
SOT-23 x 4
C_0603_1608Metric x 6
FPC-SMD_30P-P0.50_HDGC_0.5K-HX-30PWB
R_0402_1005Metric x 20
C_0402_1005Metric x 14
C_0805_2012Metric x 4
HX_PM2.54-1x4P_WT
CONN-SMD_P2.00_S2B-PH-SM4-TB-LF-SN
R_0603_1608Metric
D_SOD-123 x 3
FPC-SMD_24P-P0.50_FPC-0.5-24P-HYH2.0
D_SMF
SOT-23-5 x 4
L_0603_1608Metric
BULETM-SMD_ESP32-S3-MINI-1-N8
HVQFN_24_1EP_4x4mm_P05mm_EP21x21mm
ai_calc_v15_lcd_PCB

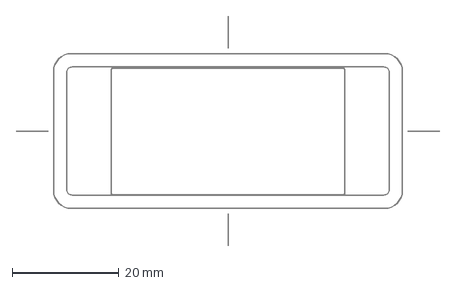
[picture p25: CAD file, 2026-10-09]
hardware/enclosure/final_assembly_v15_lcd/window_mask_template_v15.dxf
79.3 x 43.0 mm

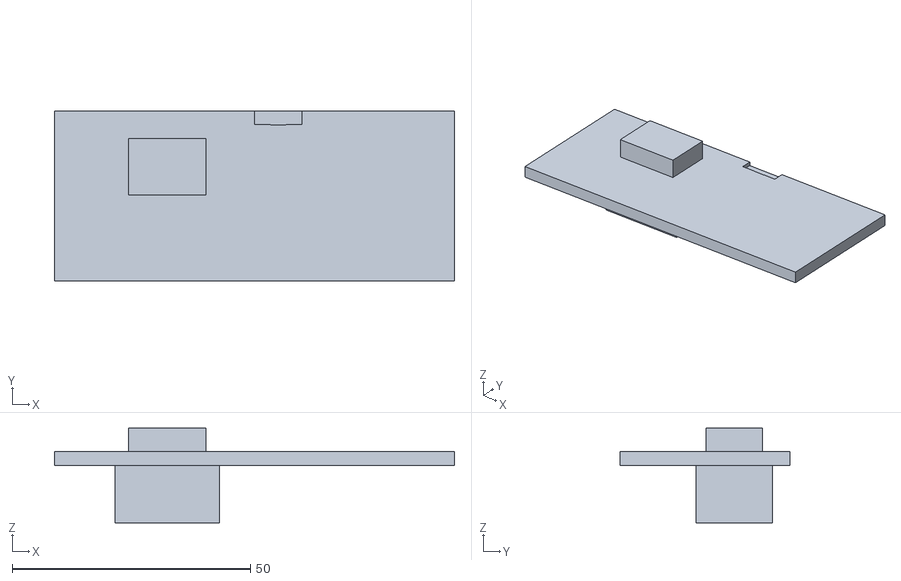
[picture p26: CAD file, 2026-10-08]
hardware/enclosure/jigs/C_LR44_trim_sled.stl
84.0 x 35.6 x 19.9

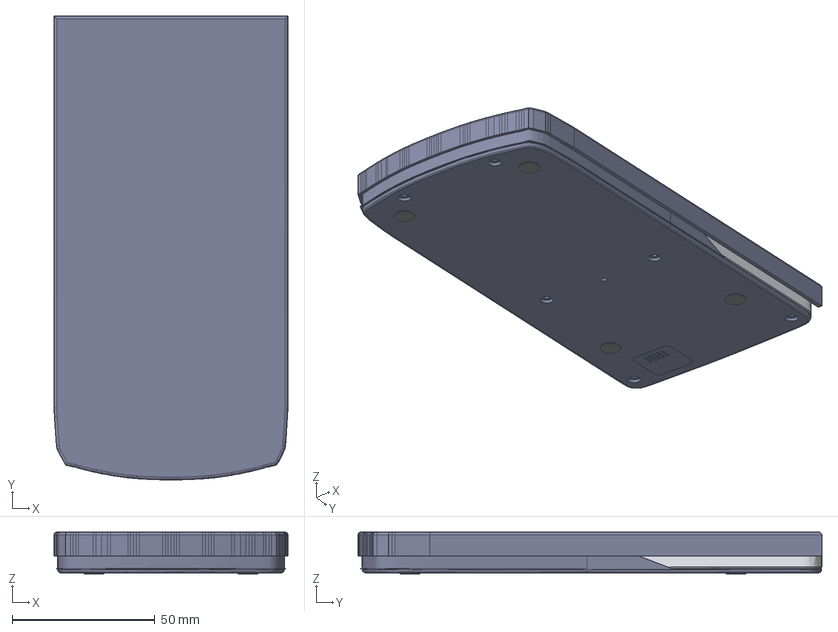
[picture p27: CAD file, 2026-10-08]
hardware/enclosure/replica/fx115es_replica.step
81.9 x 162.3 x 14.6 mm

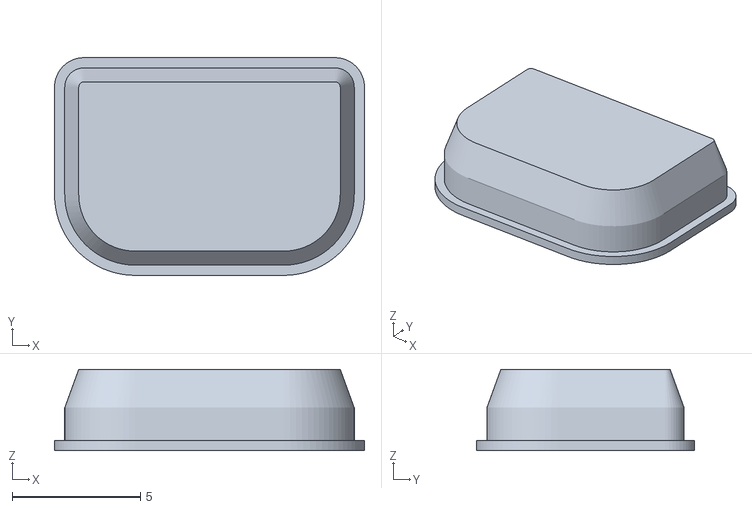
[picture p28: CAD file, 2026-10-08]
hardware/enclosure/replica/stl/keycaps/04_Key_7.stl
12.1 x 8.50 x 3.18

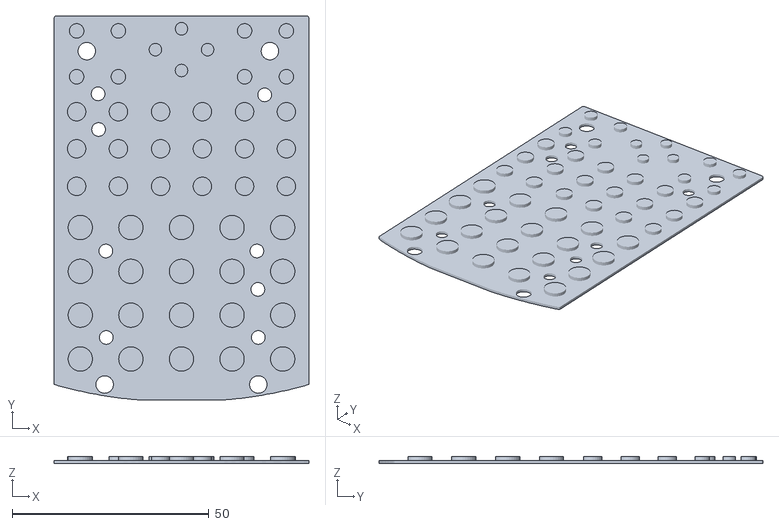
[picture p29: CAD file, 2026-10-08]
hardware/enclosure/replica/stl/Keymat_Keymat__rubber.stl
64.7 x 97.5 x 1.78

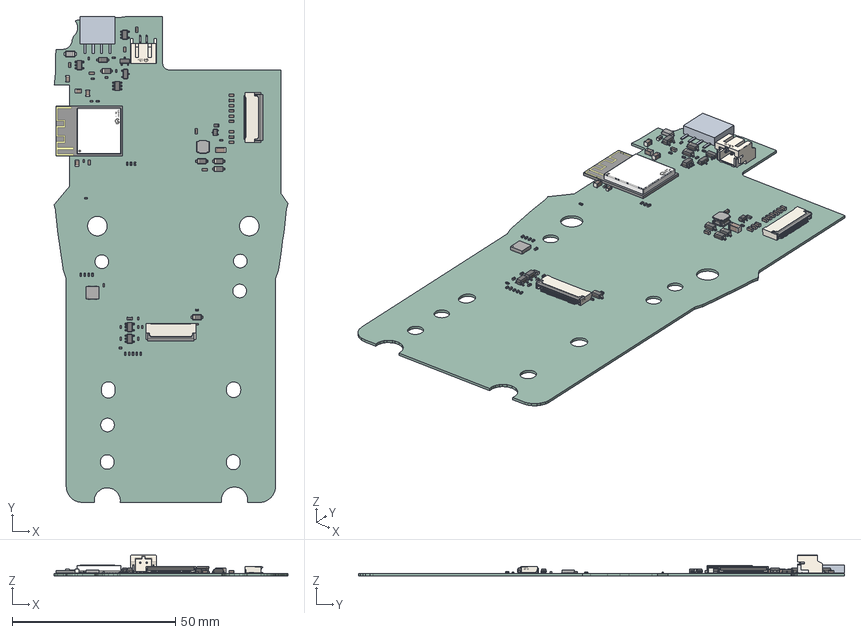
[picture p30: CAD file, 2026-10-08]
hardware/fab/ai_calc_board.step
71.6 x 148.8 x 6.30 mm
C_1206_3216Metric
SOT-23-6
C_0603_1608Metric x 16
FPC-SMD_24P-P0.50_FPC-0.5-24P-HYH2.0 x 2
R_0402_1005Metric x 19
C_0805_2012Metric x 4
C_0402_1005Metric x 13
HX_PM2.54-1x4P_WT
CONN-SMD_P2.00_S2B-PH-SM4-TB-LF-SN
D_SOD-123 x 6
D_SMF
SOT-23-5 x 4
L_0603_1608Metric
IND-SMD_L4.0-W4.0-H2.0
SOT-323_L2.0-W1.3-H1.0-LS2.1-P1.30
BULETM-SMD_ESP32-S3-MINI-1-N8
R_0603_1608Metric
SOT-23 x 2
HVQFN_24_1EP_4x4mm_P05mm_EP21x21mm
ai_calc_PCB

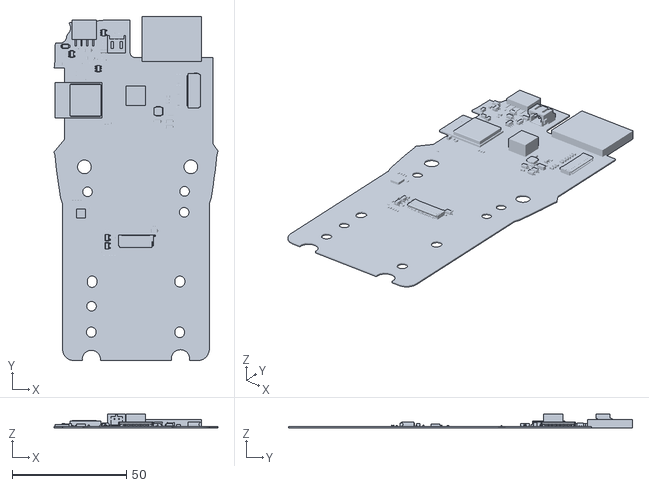
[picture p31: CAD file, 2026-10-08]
hardware/fitcheck/dummy_board.stl
71.6 x 150.4 x 6.30

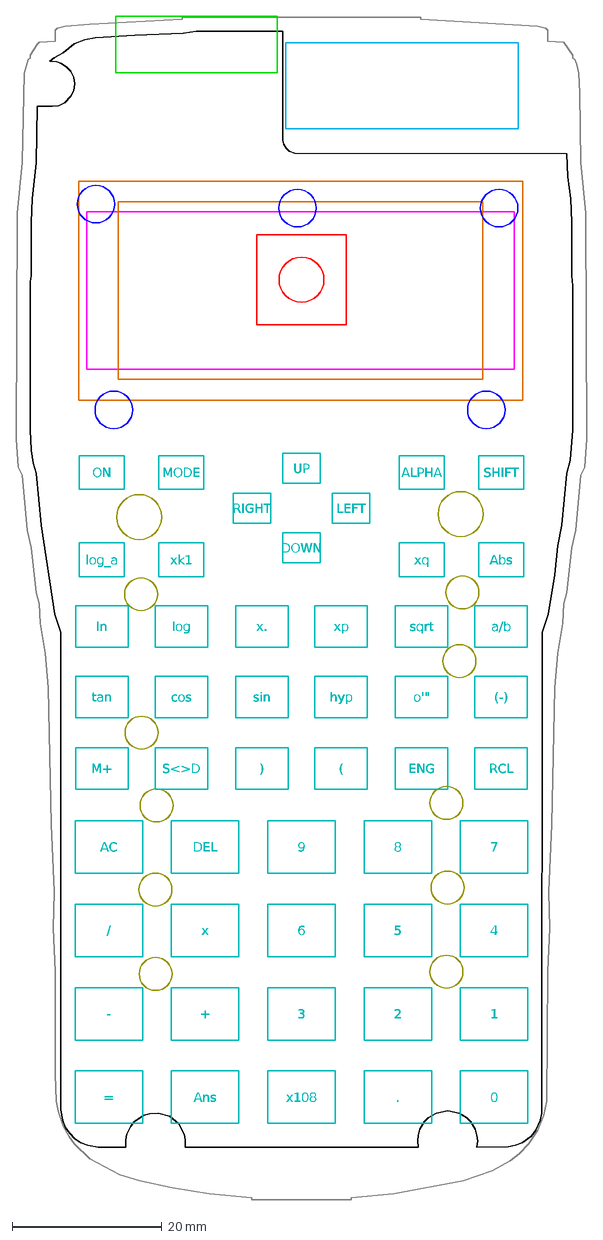
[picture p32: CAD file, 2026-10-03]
hardware/geometry/board_outline.dxf
SHIFT
ALPHA
MODE
ON
Abs
xq
xk1
log_a
a/b
sqrt
xp
x.
log
ln
(-)
o'"
hyp
sin
cos
tan
RCL
ENG
(
)
S<>D
M+
7
8
9
DEL
AC
4
5
6
x
/
1
2
3
+
-
0
.
x108
Ans
=
UP
DOWN
LEFT
RIGHT

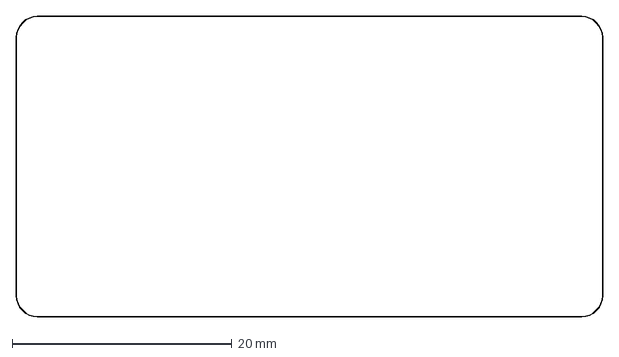
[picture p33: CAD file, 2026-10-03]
hardware/enclosure/export/lens_1mm_acrylic.dxf
53.3 x 27.3 mm

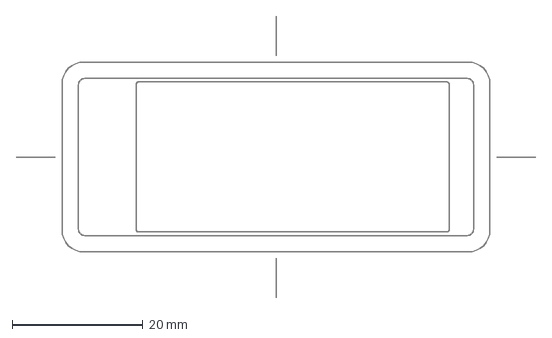
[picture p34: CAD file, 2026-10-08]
hardware/enclosure/final_assembly/window_mask_template.dxf
79.3 x 43.0 mm

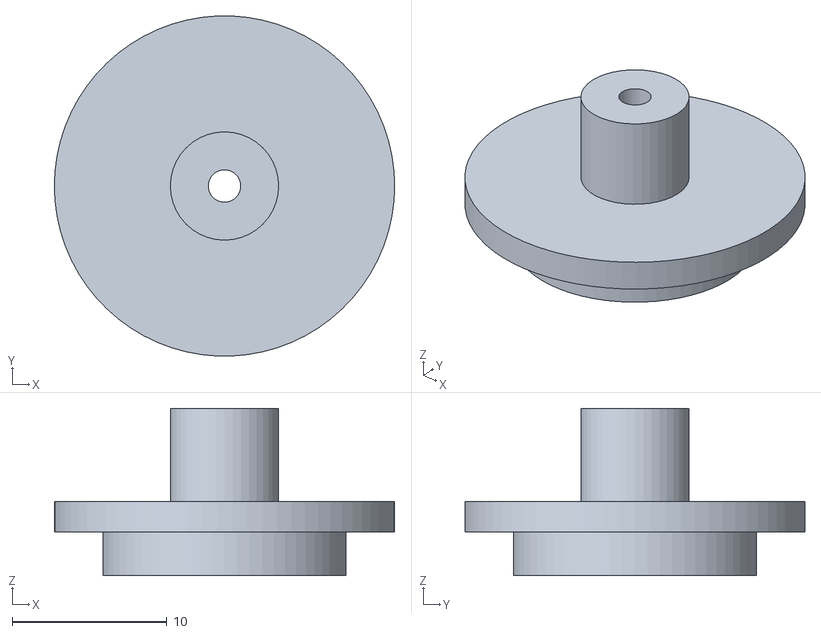
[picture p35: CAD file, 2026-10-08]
hardware/enclosure/jigs/A2_camera_drill_bush.stl
22.0 x 22.0 x 10.8

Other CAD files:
hardware/enclosure/final_assembly_v15_lcd/ai_calculator_v15_lcd_final_assembly.step
hardware/fab_v15_lcd/ai_calc_v15_lcd_board.step
hardware/enclosure/replica/stl/keycaps/05_Key_ALPHA.stl
hardware/enclosure/replica/stl/Rubber_feet_Foot_2.stl
hardware/enclosure/export/ai_calc_case.f3d
hardware/enclosure/export/ai_calc_case.step
hardware/enclosure/export/back_cover.stl
hardware/enclosure/export/front_shell.stl
hardware/enclosure/final_assembly/ai_calculator_final_assembly.f3d
hardware/enclosure/final_assembly_v15_lcd/ai_calculator_v15_lcd_final_assembly.f3d
hardware/enclosure/jigs/A3_depth_gauge_7_2.stl
hardware/enclosure/jigs/A_back_cover_plate.stl
hardware/enclosure/jigs/B_magnet_notch_saddle.stl
hardware/enclosure/replica/fx115es_replica.f3d
hardware/enclosure/replica/stl/Back_cover_Back_cover.stl
hardware/enclosure/replica/stl/Battery_lid_Battery_lid.stl
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

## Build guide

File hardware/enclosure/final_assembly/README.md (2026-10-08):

# AI calculator: final assembly, 1:1 (Fusion 360)

> **Stage 14 note:** the model uses the stage-13b board STEP; v14 only re-wired J3's pins and notched SW1, so the mechanics are unchanged. Final decision: the battery lies on the back-cover floor and the LR44 cup is **not** ground (the "LR44 cup trimmed flat" in the table below is the old plan). See `../../FINAL_STATUS.md`.

> **Rev C2 (2026-10-05): the body is two parts + a separate case.** Rebuilt from Nirav's photos: the silver
> faceplate and the navy back cover now split the way the real calculator does (the navy back cover forms the side
> walls round the keypad and the bottom; the silver part is deep only in the screen section). Added the black
> window mask and the navy slide case (hidden in the main configuration). Results: `assembly_report.md` section 7.
>
> **The correct files:** `ai_calculator_final_assembly.f3d` / `.step` in this folder (rebuilt 2026-10-05 14:54 on the
> v14 board STEP `hardware/fab/ai_calc_board.step` of 2026-10-04 14:50). The replica alone: `../replica/fx115es_replica.f3d` / `.step`. Older copies elsewhere are out of date.
>
> | Part | Colour | Fusion component | What it is |
> | --- | --- | --- | --- |
> | 1. Faceplate (the "front shell") | silver | `Replica - Front shell` | face with the keys, display window (lens recess), solar window; posts, ribs and collars underneath. Deep walls only in the screen section (stubs, clips, wire channel, top wall with the magnet U-notch); round the keypad and the bottom it is a faceplate with a short skirt that sits inside the back cover |
> | 2. Back cover | navy | `Replica - Back cover` | the screwed-on tray: floor, ribs and rings, bosses; low rim in the screen section, walls rising along a ramp to full height round the keypad and the bottom end; rail groove on both long sides (guess) |
> | 3. Slide case (accessory) | navy | `Final - Slide case (in use)` (on the back) and `Final - Slide case (stored)` (over the face) | separate hard case, **hidden** in the main configuration; not used for testing. `slide_case_mods.md` |
> | Window mask | black | `Final - Window mask` | 0.1 mm black sticker inside the lens, opening = e-paper active area. `window_mask.md`, `window_mask_template.svg/.dxf` |
>
> To show the case in Fusion: turn on the light bulb of one of the two `Slide case` components (never both).

This is the whole finished calculator as one 3D model: our ESP32-S3 board with every part on it,
inside the **ground (modified) fx-115ES shell** (unbranded replica), with the e-paper, camera, battery,
magnetic charging connector, key mat, key caps, window and screws. It is for checking the real product
before ordering the board.

- Fusion: **`ai_calculator_final_assembly.f3d`** (full timeline; File > Open in Fusion) and
  `ai_calculator_final_assembly.step` (any CAD program). The script tries to save the open document to your Fusion
  project as "AI Calculator - Final Assembly 1:1", but Fusion's cloud data wasn't reachable during this build
  ("InternalValidationError: id.size()"), so the build document is still open as "Untitled": save it under that name
  yourself, or open the .f3d.
- Collisions, in plain English: **`assembly_report.md`**.
- Pictures: `renders/` (list at the end).

**Board version used:** `hardware/fab/ai_calc_board.step` of **2026-10-04 04:11** (stage 13b: magnet header J3 =
C46061768 at KiCad (127.5, 72.0), no board notch, magnet face flush in a U-notch in the top wall).

**Result in one line:** everything fits after the 5 planned grinds, except the LiPo where stage 13 places it (it hits
the solar-window frame and cell, and its wires can't get round the board edge). Laying it on the back-cover floor fixes
that; see `assembly_report.md`.

## Part list

| Part (Fusion component) | Source | Size used (mm) | Where it sits |
| --- | --- | --- | --- |
| Front shell | fx-115ES replica (`../replica/`, your calipers), **ground**: LR44 cup trimmed flat, magnet slot cut in the top wall | 159.9 × 79.3, 11.8 / 11.3 thick | |
| Back cover | replica, **ground**: solar box flat to the floor, rib B flat over the camera, 7 mm camera window drilled, lip notched at the magnet slot | 161 × 79.3, floor 1.0 | |
| PCB | `hardware/fab/ai_calc_board.step` (KiCad export, every part with its 3D model) | 0.71 in the STEP (KiCad says 0.8) | component (F.Cu) side 6.0 above the inside of the back floor (Z 7.0), turned over so the parts face the back cover |
| E-paper panel | Waveshare 2.13" V4 raw panel: outline 59.2 × 29.2 × 1.05, active area 48.55 × 23.71 (Waveshare manual); your caliper P3 59.0 | 59.0 × 29.2 × 1.05 (bottom glass 0.7 + film/cover 0.35, 5 mm bare ledge with the driver IC at the ribbon end: estimate) | key side, on 0.15 double-sided tape, active area at the KiCad keep-out (147.445, 92.986), display facing the window |
| E-paper ribbon | 24-pin, 0.5 pitch; 14.3 long (stage 5 / V9) | 13.0 wide × 0.12 | out of the panel's ribbon end, folded 180° under the panel (in the tape gap), back to the 1.0 × 14 board slot at x 172.9, through it, 90° into J2 |
| Camera module | Seeed OV5640 AF (for XIAO ESP32S3 Sense), 8.5 × 8.5 × 5.4 (stage 13) | sensor board 1.0 + AF motor + Ø6 lens barrel 1.0 (split is an estimate) | component side at KiCad (150.0, 95.1) on 0.1 tape, lens pointing at the 7 mm window |
| Camera ribbon | Seeed: 70.5 long (stage 2) | 8.0 wide × 0.12 | flat, lying on the tallest part in its path, into J1. Path needed 58.7 mm from the module's near edge (tip 2 mm inside J1); Seeed's 70.5 mm is read from the module's far edge, so about 62 mm is ribbon and the spare is only 1.4–3.3 mm (review 07): no loop, lay it straight |
| LiPo battery | Adafruit #1317, 3.7 V 150 mAh (rev E) | 26.02 × 19.75 × 3.8 | KiCad x 152.59–178.61, y 60.36–80.11, centre (165.6, 70.24), flat on the back-cover floor, Z 1.0–4.8 (z_rel +2.2 to +6.0; stage 13 had it against the front plate, which collides) |
| JST-PH plug + leads | JST PHR-2 housing 6.0 × 4.5; leads Ø1.1 | only the part outside J4 (4.0 long) | in J4, leads round the board edge into the bay |
| Magnet connector (device half) | Adafruit #5358 = Yiwei MG04254FRA1S1N (`hardware/geometry/adafruit_5358_MG04254FRA1S1N.pdf`): obround face 21 × 7, 4 pads Ø1.5 at 2.5 pitch, pins Ø0.6 | face flange 1.0 + housing 19 × 5 × 3.0 (housing size estimated from the side view); legs straightened to 7.3 | face flush in the U-notch of the top wall at KiCad x 127.5, Z 2.2–9.2 (stage 13b); body ends just in front of the board edge; legs (5.3 long) pushed into J3 |
| Magnetic cable plug (detached) | Adafruit #5412 (USB-A to 4-pin magnetic, 60 cm) | mating face 21 × 7, overmould 23 × 9 × 10, Ø3.5 cable (estimated from photos) | 12 mm in front of the slot, shown unplugged |
| Key mat, key caps (47), window lens, battery lid, rubber feet, solar cell | replica | see `../replica/README.md` | as in the replica |
| Screws (6) | **assumption:** Casio-style 2.0 mm self-tapping pan head, **2 × 8** | head Ø3.8 × 1.1, modelled core Ø1.6 (threads not modelled) | from the back, head in the Ø4.4 counterbore. 8 mm gives 3.7 mm of thread in the front post; 6 mm would only give 1.7. Measure one of yours |

Not modelled: solder, wires' exact route, tape pads (0.1 / 0.15 mm), key legends (unbranded).

## Assumptions (check these on the real parts)

1. **Stack-up:** back floor 1.0 + 6.0 free (D4) + board + key side; the board is placed by its component face, so the parts on that side are at their true distance from the back cover. The STEP board is 0.71 thick (KiCad 0.8): the key side shows 0.09 low.
2. **Shell:** everything not measured in the replica is as listed in `../replica/README.md` (guesses marked there).
3. **Grinding** is modelled as flat to the floor (1.0 mm of floor left everywhere; the plan's limit is 0.8).
4. **E-paper** on 0.15 mm double-sided tape. Without it the ribbon fold has no room under the panel.
5. **Battery** on the back-cover floor (stage-14 re-check), not against the front plate as in stage 13 section 7.
6. **Magnet connector** as stage 13b: face 21 × 7 × 1.0, then a 0.7 plate, a 3.5-tall neck and a 5.0-tall rear block (4.0 deep in all), legs straightened to 5.3. Widths behind the face and the cable plug's shape are estimates. The U-notch (21.5 wide, 7.95 up from the rim) also cuts the back cover's locating lip there (the lip is a replica guess).
7. **Screws** 2 × 8 self-tappers (above).

## Re-run after a board change

Fusion open with the FusionMCPBridge add-in, then in `hardware/enclosure`:

```bash
python build_final_assembly.py pcb parts check export renders
```

`pcb` re-imports `hardware/fab/ai_calc_board.step` and finds every part by its KiCad reference
(`hardware/kicad/ai_calc.kicad_pcb`, read only); `parts` re-places the ribbons, plug and leads on the
connectors it finds (J1, J2, J4). If the board outline or the magnet position changes, edit the
parameters at the top of `build_final_assembly.py` (`MAG_XK`, `MAG_ZREL`, `LIPO_K`, `CAM_K`, ...).
Then rewrite `assembly_report.md` from `interference.json`.

A complete rebuild (new document, about 3 minutes plus the check):

```bash
python build_final_assembly.py all
```

`all` = `new shell grind pcb parts mask case check case_check export renders case_renders` (rev C2). `mask` adds the
window mask and lifts the lens by its thickness; `case` builds both slide-case positions (hidden) with the camera
hole; `check` runs with the case hidden; `case_check` checks each case position against everything (`case_fit.json`);
`case_renders only=case,mask,compare` makes the new pictures. Then `python final_assembly/window_mask_template.py`.

The shell comes from `build_fx115es_replica.py` (loaded as a module, unchanged), so any replica
parameter change shows up here on the next `all`. `python build_final_assembly.py` with no stage only
prints the derived numbers. Stages: `new shell grind pcb parts check export renders`;
`renders only=hero,section,grind,exploded,back_cover_off` makes a subset.

Each grind zone is its own timeline feature named `GRIND <zone>`: suppress it in Fusion to see the shell before grinding.

## Files

| File | What |
| --- | --- |
| `../build_final_assembly.py` | the script (parameters at the top) |
| `ai_calculator_final_assembly.f3d` / `.step` | the model |
| `assembly_report.md` | interference check, plain English |
| `interference.json` | raw check output (every overlap with its box) |
| `placement.json` | where every STEP part landed, STEP timestamp |
| `geometry.json` | the replica's 2D numbers used for this build |
| `PROGRESS.md`, `build.log` | build notes |
| `renders/` | pictures |

## Renders (`renders/`)

| File | What |
| --- | --- |
| `hero_front.png`, `hero_back.png`, `front.png`, `back.png` | the finished calculator (cable plug shown detached) |
| `exploded_front.png`, `exploded_back.png` | exploded views |
| `back_cover_off.png`, `back_cover_off_top.png`, `back_cover_off_closeup_top.png` | back cover, screws and feet removed: board, camera + ribbon, LiPo, J4 plug + leads, magnet in its notch |
| `section_camera.png`, `section_camera_wide.png` | cut through the camera and its 7 mm window |
| `section_j4_battery.png`, `section_battery_lengthwise.png` | cut across J4 + plug + LiPo, and along the battery |
| `section_magnet_slot.png` | cut through the magnet, its legs in J3, the top wall |
| `section_screen.png`, `section_screen_fpc_end.png` | cut across the screen section, and close-up of the e-paper ribbon fold, slot and J2 |
| `case_in_use_front/back/side.png`, `case_stored_front/back.png` | the slide case on the back (in use) and over the face (stored) |
| `case_camera_hole_closeup.png`, `case_camera_hole_section.png` | the 8 mm case hole over the 7 mm camera window |
| `case_magnet_closeup_in_use.png`, `case_magnet_closeup_stored.png` | the magnet face with the case on (open end: not blocked) |
| `exploded_3_parts_and_case.png`, `exploded_shells_only.png` | silver faceplate, navy back cover and navy case, apart |
| `mask_before_*.png` / `mask_after_*.png` | display without / with the window mask (straight on, whole front, angled) |
| `compare/cmp_*.jpg` | Nirav's photos next to the CAD at the same angle (front, faceplate inside, back cover inside); `compare/*_cad.png` the CAD views |
| `grind_<zone>_before.png` / `_after.png` | one pair per grind, in grinding order (each "before" already has the earlier grinds done): `solar_box`, `rib_b`, `camera_window` (+ `_inside_`), `lr44_cup`, `magnet_slot` |

Other stages: `check grind=off` (the shell before grinding, `interference_before_grind.json`), `clearances`
(smallest gaps, `clearances.json`), `lipo_alt dz=-5.6 [dx=..] [unground=lr44_cup]` (what-if for the battery position),
`view` (any debug picture).

## Assembly-guide pictures (`renders/steps/`, `renders/photos/`)

`python build_final_assembly.py steps [only=s05,s07]` renders the 16 step shots (`STEP_SHOTS` in the script: parts shown, moves, camera,
labelled anchor points) to `renders/steps/sNN_*.png` plus `anchors.json`. Then `python final_assembly/annotate_guide.py` (Pillow)
draws the arrows and labels into `*_ann.png`, and resizes/labels Nirav's photos into `renders/photos/` (`*.jpg`, `*_ann.jpg`, private).
`assembly_guide.html` uses the `_ann` files.

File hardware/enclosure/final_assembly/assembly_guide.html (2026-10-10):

AI Calculator · board v14 · Casio fx-115ES shell

# Calculator Assembly Guide

How to turn a tested v14 board, a ground fx-115ES shell and the bought parts into a finished calculator. Build one calculator at a time, in order. Tick each box as you go. Ticks are saved in this browser only, separately for calculator 1 and calculator 2.

Every step has the same parts: time and what you'll need, pictures, numbered sub-steps (tick each), why notes (what goes wrong if you skip it), a check before moving on box and the common mistakes. Every picture opens full size when you tap it. Labels: suggestion = my idea, the project docs say nothing. unsure = not checked on real parts, or the docs disagree. Times are rough, for a first build; the second calculator goes about twice as fast.

Calc 1 Calc 2

0 / 0 Clear ticks

5 rules for the whole build

1. No power while you plug a ribbon. Never plug or unplug a ribbon (e-paper or camera) while the board has any power. Once the battery is in J4, the board is always powered. So both ribbons go in before the battery.
2. Glue the magnet piece last. Only after its meter check has passed.
3. Never grind, file or force a post. If the board sticks on post H6, file the board's hole a little towards the top of the board.
4. Keep TP1, TP4 and TP7 clear. No tape, foam or glue on these three test pads. They are your only way to rescue a board that won't take firmware.
5. Never burn eFuses, and never turn on secure boot or flash encryption.

Step | What | Time (first build)
1 | Take the Casio apart | 20 min
2 | Grind the shell (grinding guide) | 1–2 h + drying
3 | Test the bare board (power-up guide) | 2–4 h
4 | Prepare the parts | 30–40 min
5 | E-paper on + window mask | 40 min
6 | Camera on | 15 min (+20 if drilling)
7 | Magnet piece into J3 | 10 min
8 | Key mat, board in, key test, glue | 45 min + glue set
9 | Battery | 20 min
10 | Close up | 10–15 min
11 | Final test + QA | 40 min + next-day check

## ··Parts and tools at a glance

Lay everything out on a clean, light-coloured cloth before you start, so small parts don't get lost and you can see dust. One calculator's parts:

The v14 board seen from its component side

Board v14 (JLCPCB). Hold it by the edges.

The bare e-paper panel

E-paper panel, Waveshare 2.13" V4, bare glass, 24-pin ribbon.

The OV5640 camera module with its orange ribbon

Camera, Seeed OV5640 autofocus, 8.5 × 8.5 mm.

The flat battery with its leads and white plug

Battery, Adafruit #1317, 150 mAh, JST-PH plug.

The magnetic connector piece with four legs

Magnet piece, Adafruit #5358 (+ one #5412 cable).

Photo of the silver front shell and navy back cover of the Casio

Casio fx-115ES shell: front shell + back cover (your photo).

Photo of the grey rubber key mat

Rubber key mat from the Casio (your photo).

### Tools

Multimeter: DC volts, beep, mA.

Calipers: lengths to 0.1 mm.

Fine tweezers (plastic tips are best near sockets).

Small Phillips screwdriver.

Flush / side cutters and flat pliers.

Kapton tape (orange, insulating, 5–10 mm wide).

Thin double-sided tape: 0.1 mm (camera, battery) and 0.15 mm (e-paper). No foam.

Craft knife (new blade) + steel ruler, for the window mask.

Plastic pick / spudger or a fingernail, for socket latches.

Epoxy or hot glue (magnet); isopropyl alcohol (lens).

Magnetic USB cable, a phone charger and a PC with VS Code + PlatformIO.

Round needle file (only for hole H6, if needed).

Also: a 2.4 GHz phone hotspot, the grinding kit from the Shell Grinding Guide (https://claude.ai/artifact/9rCWyw8MeHP2z8FWijnyfL), a small cup for screws, a clean bag for the key mat, a pen and a marker.

## ··Words you'll meet

The orange flat ribbon of the camera Ribbon (FPC)

The thin, flat, flexible cable on the e-paper panel and on the camera. FPC = "flexible printed circuit". Bend it gently in a curve; never crease it sharp, never pull it at its root.

Diagram of a ribbon end: thin ribbon, thicker stiff end, gold fingers Stiffener and gold fingers

The ribbon's last few mm are thicker and stiff (the stiffener) and carry the gold contacts ("fingers"). Only this stiff end goes into a socket.

Close-up of socket J1 with its dark hinged bar Socket latch (lid)

The dark hinged bar on a ribbon socket (J1, J2). Flip it up to open, slide the ribbon in, press it flat to lock. On these sockets the bar is on the side away from the opening. A ribbon never goes in or out while it's closed.

An orange Kapton square on the board where the camera sits Kapton

Thin (about 0.06 mm), orange, heat-proof tape that doesn't conduct electricity. It goes between parts so nothing bare touches.

The white JST-PH battery plug pushed into socket J4 JST-PH plug (J4)

The small white 2-pin plug on the battery and its socket J4. It only fits one way round, but the battery maker decides which wire is +, so you always meter it first.

Board corner with yellow round test pads TP5, TP7, TP2, TP3 labelled Test pad (TP)

A small round bare copper spot, labelled TP1, TP2… You touch a meter probe to it. TP1 = BOOT, TP4 = GND (0 V), TP7 = EN (reset).

J1, J2, J3, J4

Names printed on the board for its connectors. J1 = camera ribbon. J2 = e-paper ribbon. J3 = magnetic charging piece. J4 = battery plug.

Pin 1

The end of a connector marked with a small triangle, dot, "1" or "N". Every connector here has a pin-1 end that must meet the part's pin 1.

Polarity

Which wire is + and which is −. Battery and charging power only work one way round. Backwards can damage parts.

VBUS / GND

VBUS is the +5 V wire from a USB cable. GND is ground, the 0 V wire.

Meter "beep"

The continuity setting on your multimeter. It beeps when the two probes are joined by metal. Only on an unpowered board.

Key side / component side

The board's two faces. Key side: flat, with the key pads, facing the keys and the screen. Component side: all the parts, facing the back cover.

Rim / parting line

The edge where the front shell and the back cover meet.

## 00Overview: what goes where

The new board sits in the front shell exactly where Casio's board was. Its key side faces the rubber key mat. The e-paper screen is taped to the key side, behind the display window. Its ribbon goes through a slot in the board to J2 on the other side. The camera, the battery and the magnetic charging piece are all on the component side, facing the back cover.

Exploded view from the front: window lens, front shell, key mat, board with e-paper, magnetic connector and cable, back cover, six screws

Look for: the order of the layers, top to bottom: window, front shell, key mat, board (e-paper on top), back cover, 6 screws.

Exploded view from the back: back cover with camera window and battery lid, board with camera and ribbon, battery, key mat, front shell

Look for: the camera looking out through a 7 mm hole in the back cover, and the battery lying on the back cover's floor.

### The order of work

1. 1Take the Casio apart
2. 2Grind the shell
3. 3Test the bare board
4. 4Prepare parts
5. 5E-paper on
6. 6Camera on
7. 7Magnet piece into J3
8. 8Mat, board into shell, glue magnet
9. 9Battery into J4
10. 10Close
11. 11Final test + QA

Battery is lastThe board goes into the shell (step 8) before the battery (step 9). The battery lies beside the board on the back-cover floor and plugs into J4, so it can only go in once the board is seated. It must be the last thing connected.

### Parts for one calculator

- AI CALC v14 board (assembled by JLCPCB).
- One Casio fx-115ES with all its pieces: front shell, back cover, rubber key mat, key caps, display window, battery lid, rubber feet, 6 screws. Both calculators should be the same edition (back label: fx-115ES, PLUS or PLUS 2nd edition) open question.
- Seeed OV5640 autofocus camera (from the XIAO ESP32S3 Sense kit). 8.5 × 8.5 × 5.4 mm; ribbon 70.5 mm by the drawing, measured from the module's far edge to the tip (measure yours in step 4: it decides where the camera sits).
- Waveshare 2.13" V4 e-paper panel, bare (about 59.0 × 29.2 × 1.05 mm, 24-pin ribbon).
- Adafruit #1317 battery: 3.7 V, 150 mAh, 26 × 19.75 × 3.8 mm, JST-PH plug.
- Adafruit #5358 magnetic connector piece (the calculator half). One #5412 cable works for both calculators. Equivalents: Yiwei MG04254FRA1S1N (same part as #5358) and the Yiwei MG0425-UB-60-4P cable (same pin order as #5412); the meter check is the same.
- Supplies: Kapton tape (5 and 10 mm). Thin double-sided tape, 0.1 mm or less (for example 3M 9080 / tesa 4965 type) for the camera and the battery. Double-sided tape about 0.15 mm thick for the e-paper. Matte black sticker paper or vinyl (0.08–0.15 mm) for the window mask. Epoxy or hot glue for the magnet. No foam tape anywhere.

## 01Take the Casio apart

≈ 20 minDifficulty: easy

You'll needSmall Phillips screwdriver, a soft cloth, a cup for screws, side cutters, a marker, a clean bag for the key mat, calipers, a tray for loose key caps.

You keep the outside and throw out the insides. Keep: front shell, back cover, rubber key mat, key caps, display window, battery lid, rubber feet, all 6 screws. Remove: the Casio board, the LCD screen module, the LR44 coin cell. The docs don't describe how this Casio comes apart, so these steps are general practice suggestion.

Photo of the opened Casio front shell with its green board and silver LCD module still inside, labelled: remove LCD module, remove Casio board, take the coin cell out first, cut these wires, keep th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

Look for: the green Casio board and the silver LCD module, which both come out. The grey shell and its posts stay. Cut the wires at the board.

- Take the LR44 coin cell out first, so nothing can short while you work. It sits in a round cup in the top corner.
- Lay the calculator face down on a soft cloth.
- Undo the 6 screws on the back. Put them in a cup.
- Measure one screw with the calipers and write down its length. The 3D model assumes 2 × 8 mm self-tapping screws assumed.
- Lift the back cover straight up. If it sticks, look for a missed screw. Don't pry.
- Cut or unsolder the wires going to the Casio board (including the solar cell's wires) at the board end.
- Keep the shell face down so the key caps stay in their holes. Lift the Casio board straight up off the posts, together with the LCD module (a flex joins them). Unclip the LCD gently from the side clips.
- If the grey rubber key mat sticks to the board, peel it off slowly from one corner. Hold the flat sheet, never a dome. Don't touch the black dots under the domes: finger grease makes keys unreliable suggestion. Put the mat in a clean bag.
- Solar cell: leave it glued in its window as a cover. The battery's new spot clears it by more than 3 mm (settled: nothing in the build needs it out). Only if it falls out: cover the window with a sticker.
- Measure the Casio board's thickness with the calipers and write it down. Ours is 0.8 mm; if Casio's is noticeably different (say 1.0), the key feel changes slightly but nothing else: the posts, not the board, set the heights.
- If key caps come loose, keep them in rows on a tray so each goes back in the same hole suggestion.
- Write "1" or "2" inside both shell halves with a marker, so halves, mats and screws stay together.

3D picture of the empty front shell with the black key mat inside, next to the open back cover, labelled key mat, front shell, back cover and display window

Look for: this is what you keep: the front shell with the key mat in it, and the empty back cover. (The 3D mat is drawn black; yours is grey.)

the coin cell comes out first because a cut wire touching the wrong spot can short it. Labelling the halves matters because the two shells are not quite identical: mixing them gives a cover that rocks.

Check before moving on

- 6 screws in the cup, length written down.
- Key mat in its bag, no fingerprints on the black dots.
- No wire stubs left on the posts or in the clips.

Common mistakes

- Prying the cover open with a screwdriver: it marks the rim and can crack a clip. A missed screw is almost always the reason.
- Turning the shell over with loose key caps in it: they fall out and get mixed up.
- Pulling the LCD flex instead of unclipping the LCD.

only the empty shell halves, the key mat, the key caps, the small parts and 6 screws are left, labelled 1 or 2.

## 02Grind the shell

≈ 1–2 h + dryingDifficulty: medium (go slowly)

You'll needThe grinding kit, safety glasses and a mask (all listed in the grinding guide), calipers, a marker, the printed templates.

Follow the Shell Grinding Guide (https://claude.ai/artifact/9rCWyw8MeHP2z8FWijnyfL) step by step. It has the tools, safety rules, before/after pictures and the depth to check for each zone. In short:

Back cover inside, top end on the right, with zones 1, 2, 3 and 5b marked in red

Back cover (top end on the right): 1 solar box, 2 rib B, 3 camera hole, 5b lip if present.

Front shell inside, top end on the right, with zones 5, 6, 6b and 6c marked in red

Front shell (top end on the right): 5 magnet notch, 6 side-wall relief, 6b pins and hooks, 6c only if needed. The LR44 cup stays.

Zone | Part | What | Why
1 | Back cover | Solar box flat to the floor, no stub | J4 is only 0.41 mm from the floor after this
2 | Back cover | Rib B flat for 14 mm over the camera | The camera lens would hit it by 0.5 mm
3 | Back cover | Camera window: 7 mm drill (small pilot hole first), on the centre line, 38.0 mm down from the back cover's own top outer edge | The camera's view. See the note below
4 | Front shell | LR44 cup: don't grind | Not needed with the battery on the back floor
5 | Front shell | U-notch in the top wall: 21.5 mm wide, 7.95 mm down from the rim, 6.4–27.9 mm from the right edge (display up) | The magnet face sits flush in it
5b | Back cover | Lip under the magnet notch, 21.5 mm wide, only if your cover has a lip there | The magnet body would hit it by 0.5 mm
6, 6b, 6c | Front shell | 6b: snip the pins and hooks off the inner side-wall ribs. 6: file 35 mm of the inner rib (solar-window side, 14–49 mm from the shell's own top outer edge at that wall) only if the paper template (with its yellow antenna tab) won't drop in. 6c: rib ends, only if needed | The board's top corner and the ESP32 antenna tab would hit that rib if it reaches the board plane

Back cover from outside: the drill centre 38.0 mm below the cover's top outer edge, on the width centre line, 39.3 mm from each side

Camera hole, from outside: on the width centre line, 38.0 mm down from the navy back cover's own top edge (39.3 mm from each side in the model = half its 78.7 mm width; halve your own measured width). Older notes said 38.3: that was measured to the top of the whole calculator, where the silver front shell stands about 0.3 mm beyond the cover. Use 38.0 on the loose cover.

Before grinding: the 10-minute pre-grind checklist

hardware/verification/07_final_review_fitment.md lists the few shell dimensions the 3D model only guessed. Measure them on your shell before the first cut: the depth of the inner side-wall rib (decides zone 6), the flat strip between the solar window and the display window (must be at least 2.6 mm: the e-paper panel's top edge lies there), the floor thickness at the moulded label on the back (the camera hole and rib B are inside it), whether the back cover has a lip at the magnet notch (zone 5b), and the screw length. Write the numbers on the template.

Camera hole: drill now or later?

Measure the camera ribbon from the module's far edge to its tip (bring-up step 5). 70.3 mm or more: drill at the normal spot (centre of rib B) now. Shorter: wait. In step 6 the camera moves up to 1.7 mm towards J1, and you drill where the lens really ends up.

- Pre-grind checklist measured and written down (inner-rib depth, solar-frame strip, floor at the label, lip, screw length).
- Zones 1, 2, 5 and 6b done (and 5b if there was a lip, 6 / 6c if the paper template didn't drop in).
- Floor still at least 0.8 mm thick everywhere (calipers).
- Zone 3 camera hole drilled (centre line, 38.0 mm from the cover's own top edge, middle of the rib-B gap), or deliberately left for step 6.
- Screw posts, locating posts, clips, walls and key holes untouched.
- Both halves washed or blown completely clean. Dust under a key dome stops that key working.
- If you washed them: both halves fully dry before any electronics come near.

Back cover after all grinds: flat floor at the old solar box, gap in rib B with the 7 mm hole

Back cover, finished: green outlines show what came off.

Front shell after all grinds: notch in the top wall, pins and hooks gone

Front shell, finished.

every zone is there because a part would otherwise hit plastic: J4 by 4.6 mm without zone 1, the lens by 0.5 mm without zone 2, the magnet face by 1.0 mm without zone 5. Too much grinding is worse than too little: a hole in the 1 mm floor can't be undone.

Check before moving on

- Fingernail across each ground spot: no ridge, no stub (zone 1 especially).
- Hold the cover to a light: no thin, glowing spots in the floor.
- The camera hole is round, 7.0–7.1 mm both ways, on the centre line.

Common mistakes

- Leaving a 0.5 mm stub in zone 1: the cover won't close over J4.
- Measuring the camera hole from the calculator's top end (38.3) instead of the loose cover's edge (38.0).
- Grinding the locating posts "to make the board fit". Never: file hole H6 instead (step 8).
- Fitting electronics into a still-damp shell.

all planned zones are ground, nothing else is touched, and the shell is clean and dry.

## 03Test the bare board first

≈ 2–4 h (power-up guide)Difficulty: medium

You'll needThe First Power-Up Guide (https://claude.ai/artifact/PqTARcDutvwxS5aGB8iEG9), the board, the e-paper panel, the camera, the battery, the magnet piece and cable, the multimeter, the PC.

Before anything goes into a shell, the bare board must pass the First Power-Up Guide (https://claude.ai/artifact/PqTARcDutvwxS5aGB8iEG9): inspection, meter checks, first power on USB, flashing the firmware, the self-test, then screen, camera and battery one at a time. This guide doesn't repeat it.

The v14 board's component side with J1, J2, J3, J4 and the test pads TP1 to TP7 labelled

Board map (component side): J1 camera, J2 e-paper, J3 magnet (pin 1 = N = VBUS), J4 battery (pin 1 GND, pin 2 +), and the test pads. You'll use this map in steps 5–9.

### If your e-paper panel is still on the Waveshare HAT

The HAT is the blue test board from the prototype. The bare panel's ribbon is held in the HAT's socket by a latch. Free it before the power-up guide connects it to J2.

Photo of the Waveshare 2.13 inch e-paper HAT held in a hand, with the panel's gold ribbon entering the white socket at the top; labels mark the ribbon, the latch and the socket

Look for: the gold ribbon entering the socket at the top edge of the HAT, and the dark hinged bar (the latch) on the socket's far side from the ribbon.

- Unplug the HAT's coloured wire bundle, so the HAT has no power.
- With a fingernail, gently lift the dark hinged bar on the socket (the side away from the ribbon) to about 90°. It hinges up; it doesn't come off. If it won't move with light pressure, stop and send a photo: don't pry the white part socket type not checked on the real part.
- Slide the ribbon straight out. If it resists, the latch isn't open. Never pull hard.
- Keep the panel in a clean place, glass side down on a soft cloth. Don't bend the ribbon at its root (where it leaves the glass).

Must pass before assembly

- Power good: TP5 reads 3.25–3.35 V, TP7 high, nothing warm.
- Firmware flashed; status works in the Serial Monitor.
- Self-test with screen and camera connected: display_ok, camera_ok, keypad_scanner_ok, wifi_ok all true. The 50-key test waits until the key mat is on (step 8).
- Battery charging seen in status ("(charging)").
- AI settings in (power-up guide step 10): status shows your hotspot, the proxy address and a device token; account shows the calculator linked.
- Written down: the camera ribbon length (power-up step 5) and the magnet piece's VBUS leg (power-up step 3).
- Power-up guide finished on this board. SELFTEST_JSON line saved in a text file.
- Battery unplugged from J4 and cable off. The board has no power at all.

once the board is inside a glued shell, finding a bad solder joint means taking everything apart again. Ten minutes of testing on the bench saves an evening.

Check before moving on

- Nothing is plugged into J4 and the cable is off: ribbons may now be handled.
- If the ribbons are still in J1/J2 from testing and the latches are closed, you can leave them in.

Common mistakes

- Unplugging a ribbon with the battery still in J4.
- Skipping the magnet meter check because "it worked on the computer": a phone charger is the dangerous case.

the board passed every check above and is now unpowered.

## 04Prepare the parts

≈ 30–40 minDifficulty: easy, but careful

You'll needMultimeter, phone charger, the #5412 cable, flat pliers, a pen, calipers, Kapton tape (5 and 10 mm), scissors, thin (0.1 mm) double-sided tape, a needle (only if a plug needs re-pinning).

Most of these checks are in the power-up guide (its steps 3–5). If you did them there, just tick them here. Do them on the real parts of each calculator.

The five parts laid out: the board seen from its component side, the e-paper panel, the camera module, the battery with its plug, and the magnet piece with four legs

Look for: the five parts you'll fit, laid out. The ribbons on the screen and the camera are not drawn here.

Delicate: the magnet piece's +5 V leg

Diagram: magnet piece snapped onto the cable, charger on, meter red probe on the outer leg at the N end reads +5 V; mark that leg

The meter check. The piece hangs on the real cable, the cable is in a phone charger, the legs point down in the air. Red probe on one outer leg, black on the other: +5 V means the red-probe leg is VBUS.

- Meter check passed with the real #5412 cable (power-up guide step 3): +5 V leg found on a phone charger, inner legs 0–0.6 V, D− and D+ beep to USB-A pins 2 and 3.
- VBUS (+5 V) leg marked with a pen. It should be the leg at the piece's N end, and it goes into J3 pin 1.
- All 4 legs straightened with flat pliers, pointing straight back out of the body. If they come out more than 1 mm off-centre, bend a small step into them.

if the piece goes in backwards, the cable's 5 V lands on the board's ground. A computer port cuts out, but a phone charger can push 2 A or more through D7 and the charger chip and burn them. The meter is the only way to know which leg is which on your piece and cable.

Never "turn it over"If the +5 V leg is not at the N end, or the reading is odd, stop and ask. Don't fix it by flipping or reversing the piece: the cable only snaps on one way, so a turned piece lines up the wrong pins with the cable, and the face would no longer sit flush in the notch.

Delicate: battery polarity

Diagram: meter on the battery plug reads +3.9 V with the red probe on the contact that meets J4 plus; on the board J4 pin 1 beeps to TP4 and pin 2 does not

Two checks: (1) the battery plug: red probe on the contact that will meet J4 "+", reading positive and on the red wire; (2) the board: J4 pin 1 (left, seen from the component side with the opening towards you) beeps to TP4.

Board render: J3 pin 1 = N = VBUS on the left, J3 pin 4 GND; J4 pin 1 GND black, J4 pin 2 BAT plus red

The real board: J4 pin 2 (red, +) is the right-hand pin in this view; pin 1 (black, GND) the left one. J3 pin 1 is the "N / +" end.

- Polarity checked with the meter (power-up guide step 4): the plug contact that meets J4 "+" is on the red wire and reads a positive voltage. If it was backwards, the crimp pins were swapped and checked again.
- Board unpowered, meter on beep: J4 pin 1 beeps to TP4, pin 2 doesn't. (Touch the pins where they are soldered, from the back of J4.)
- Peel the tape that holds the #1317's lead on top of the cell, slowly, holding the wires flat with a thumbnail at the protection-board edge. Leave the yellow Kapton on the protection board. Lead the wires straight out of the lead end and fix their roots to the cell's end face with a 5 × 10 mm piece of Kapton. Don't wrap the whole cell: nothing may sit on top of it.
- Cut two strips of 0.1 mm double-sided tape for under the battery: 6 × 18 mm and 4 × 16 mm. No foam pad: the coin-cell holder above the battery leaves only about 0.2 mm.

the #1317 ships with its lead taped on top: that makes it 4.9 mm tall and it would hit the coin-cell holder. The wires snap at the solder joints if they bend there, so the Kapton takes the pull instead.

### Camera

- Ribbon beep test passed: fingers 2 and 15 beep to each other (both GND).
- Ribbon measured, module far edge → tip: ____ mm. Under about 70.3 mm means the camera shifts towards J1 in step 6.
- If the camera came with a heat sink that makes it taller than 5.5 mm, leave the heat sink off.

### Kapton

Component side of the board: an orange Kapton square about 13 by 13 mm where the camera sits, with a smaller blue square of thin tape on it; arrow shows the ribbon runs towards J1

The camera spot: a Kapton square (about 13 × 13 mm) on the board first; the camera's thin tape goes on top of it later (blue).

- A piece of Kapton (about 13 × 13 mm) on the board where the camera will sit, smoothed flat with a fingernail, no bubbles. It insulates the tracks under the module. Keep it off TP1, TP4, TP7.
- On the back of the e-paper: one thin layer of Kapton over the driver-chip end, so nothing bare touches the key pads suggestion. Keep it off the ribbon's fold. If it makes the panel sit high, leave it off not modelled.

Check before moving on

- VBUS leg marked; you know which J3 pin it goes in (pin 1, N).
- Battery reads positive on the contact that meets J4 "+".
- Camera ribbon length written down.
- Kapton flat, no wrinkles, test pads bare.

Common mistakes

- Doing the magnet check on a computer port only (a charger is what can do damage, and the check must use the cable you'll really use).
- Bending the battery wires at the protection board while peeling the tape.
- Kapton over a test pad.

the magnet leg is marked and straight, the battery is checked and its lead re-taped to the end face, the camera ribbon is measured, and the Kapton is on.

## 05E-paper screen onto the board

≈ 25 min + 15 min maskDifficulty: delicate

You'll need

- E-paper panel, double-sided tape about 0.15 mm thick, scissors.
- A fingernail or plastic pick (for J2's latch), clean dry hands.
- The front shell (for a dry fit).
- For the mask: the template, matte black sticker paper, steel ruler, new craft-knife blade, isopropyl alcohol.

The panel lies on the board's key side, screen facing out through the window. Its ribbon leaves the panel's short end, folds back under the panel, runs about 6.6 mm to a 1.0 × 14 mm slot, goes through the board and turns straight into J2 on the component side.

Key side of the board with the e-paper panel face up on it; the ribbon goes round into the 1 by 14 mm slot

Where it ends up: panel face up on the key side, ribbon end at the left, going round into the slot.

Cut-away close-up at the ribbon end: the ribbon leaves the top of the panel, folds 180 degrees under it inside the thin tape gap, goes down through the board slot and turns into J2 under the board

The ribbon's path in a cut-away: out of the panel, a 180° fold back under it (inside the tape gap), down through the slot, then sideways into J2.

The ribbon is short

It is 14.3 mm long (Waveshare drawing, ±0.3). The 3D model's path from the glass edge into J2 needs 12.7 mm with the tip 2 mm inside J2, so the nominal spare is about 1.6 mm; with a 3 mm insertion and a short ribbon it is nearer 0.3 mm. Settled (review 07): treat it as no spare: the fold hugs the panel end, the ribbon hugs the slot's outer wall, and it goes fully into J2. If you measured the stiff end longer than 5 mm before ordering, follow what Claude told you then.

Delicate: opening and closing a ribbon socket (J2 here, J1 in step 6)

Four side-view panels: socket closed; dark bar flipped up 90 degrees; ribbon slid 2 to 3 mm in until it stops with the gold fingers hidden; bar pressed flat. Below: ribbon square in the socket versu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

The four moves, seen from the side, and what "square" looks like from above.

J2 on the component side: the dark latch bar on the right side, the ribbon comes up the slot on the left

J2 open. The dark bar is on the right here; the ribbon comes up through the slot on the left and enters from that side.

J2 with the ribbon all the way in and the latch pressed down

J2 closed: ribbon all the way in and square, latch flat. (The 3D model draws the bar the same in both pictures; on the real part it stands up when open.)

#### Which way the ribbon faces

Don't think about it, just don't twist it. Fold the ribbon back under the panel and feed it straight down the slot: when it comes up beside J2, its gold fingers face the board (down), which is right for J2. J2 makes contact on both faces, but a ribbon that is turned over or twisted puts pin 1 at the wrong end, and the screen stays blank.

#### How far it goes in

Until it stops by itself, about 2–3 mm. All the gold disappears into the mouth, and the edge of the stiff end lines up with the mouth, the same depth at both corners. If gold shows at one corner, it is crooked: open, pull out, try again. Never push with the latch closed.

a ribbon that is only half in still works on the bench, then loses one line when the board goes into the shell. A crooked ribbon shifts every pin by one. Pushing into a closed socket bends its contacts for good.

### Fit the panel

- Board unpowered: no battery, no cable.
- Lay the panel face down beside the board's key side, ribbon end towards the slot.
- Fold the ribbon gently back under the panel. Use a fingertip to make a smooth curve; never make a sharp crease.
- Feed the ribbon tip through the slot from the key side, stiff end first. It hugs the slot's outer wall.
- Turn the board over (support the panel with a finger so it doesn't hang on its ribbon). Lift J2's dark bar to about 90° with a fingernail at its centre.
- Slide the ribbon into J2 straight and fully (2–3 mm, no gold showing). Press the bar flat in the middle.
- Give the ribbon a very light tug: it must not move. (Skip these J2 lines if the ribbon is still in from the power-up test and the bar is closed.)

### Tape the panel square

Key side of the board: the dashed panel outline, two blue tape strips along the long edges, no tape at the ribbon end next to the slot

Tape layout: two strips of 0.15 mm tape along the panel's long edges, inside the dashed outline. Nothing under the ribbon end (left): the fold lives there.

- Turn back to the key side and lay the panel flat, without tape yet. Rough position: glass centred along the slot's 14 mm length, its ribbon-end edge about 6.6 mm past the slot's centre line from board numbers. Its edges should run parallel to the board's edges ("square").
- Cut two strips of the 0.15 mm tape a little shorter than the panel's long edges. Stick them on the board along where the long edges go, away from the ribbon end. Peel the liners, lower the panel on, and press only lightly for now strip layout: suggestion. The tape's thickness is the room the fold needs.
- Dry fit: lower the board onto the front shell's posts (no key mat yet is fine) and look through the window from the front. The screen should be centred and square. Adjust while the tape is still light.
- Press the tape down firmly, on the strips only, for 10 s. Never press on the middle of the glass.

The board seen from its key side with the e-paper panel lying on its upper part; labels mark the panel, the ribbon end and the key pads

Whole board, key side: the panel near the top, ribbon end towards the left edge, key pads below it untouched.

foam or thick tape lifts the panel into the window (it has only 1.79 mm to the mask) and leaves no room for the fold. Pressing the glass can crack the panel.

Delicate: the window mask (hides the ribbon and glass edges)

Through the clear window you would see the ribbon's root at the left end and the glass edges. A thin matte-black sticker on the inside of the window lens hides everything except the picture. It sits 1.79 mm above the screen, so it never touches it.

Display window without the mask: the ribbon end and the glass edges are visible

Before: the ribbon root (left) and the glass edges show.

Display window with the black mask: only the screen's picture area shows inside a black frame

After: only the picture shows, inside a black frame.

You'll needThe template window_mask_template.svg (also in the repo at hardware/enclosure/final_assembly/), matte black sticker paper or black vinyl (0.08–0.15 mm), a steel ruler, a new craft-knife blade, isopropyl alcohol.

- Print the template at 100 % / Actual size. Measure the 50 mm bar. If it's off, fix the print setting and print again.
- Cut the opening first (47.75 × 22.90 mm): ruler + new blade, 2–3 light passes per side, stop exactly at the corners.
- Cut the outer edge. Easiest: the blue dashed line (60.35 × 24.00), so the sticker fits through the window and the lens can stay in the faceplate.
- Faceplate open, board not in yet: wipe the inside of the lens with isopropyl and let it dry. Don't touch it with fingers afterwards.

Inside of the front shell: the clear lens in the display window, with the black mask held above it, sticky side towards the lens

Inside of the front shell, top end up: the mask goes onto the clear lens, sticky side towards the lens.

- Which way round: the opening is off-centre on purpose. Seen from the front, the wide black band (11.35 mm) is on the left, the ribbon side. Seen from the inside (as in these pictures) it's on your right.
- Hold the sticker by its edges. Line its edges up with the window's edges, lay one long edge down first, then roll it down with a fingertip from the middle outwards, to avoid bubbles.
- Check from the front: a black frame with the clear opening a little right of centre, no white border, no bubble in the opening.

Inside of the front shell: the black mask stuck on the lens, the wide black band on the right as seen from inside

Mask on, seen from inside: the wide band is on the right here (= left from the front). "Centred" in the label means centred over the picture, not over the window.

the wide band covers the ribbon's root; stuck the other way round, the ribbon shows on one side and the picture is cut off on the other.

Check before moving on

- J2's bar is flat and the ribbon doesn't move on a light tug.
- No sharp crease in the fold; the fold isn't pinched under tape.
- Dry fit: screen centred and square in the window.
- Mask: wide band on the ribbon side, no bubbles, no white border.

Common mistakes

- Tape under the ribbon end: the fold has no room and pulls out of J2.
- Ribbon twisted on the way through the slot: blank screen.
- Holding the board by the panel while turning it over: the ribbon tears at its root.
- Mask stuck the wrong way round, or a fingerprint under it.

the panel is taped flat, centred in the window on the dry fit, its ribbon is locked in J2 with no sharp crease, and from the front you see only the picture inside the black mask.

## 06Camera onto the board

≈ 15 min (+ 20 min if you drill now)Difficulty: delicate

You'll needCamera, thin double-sided tape (0.1 mm or less, not foam tape), tweezers, a fingernail or pick for J1's bar, the back cover; calipers and drill if the hole waits for this step.

The camera sits on the component side, on its Kapton square, lens pointing at the back cover, centred under the 7 mm hole (on the case's centre line). Its ribbon lies flat and runs straight down the board to J1, with no twist and no loop.

Component side: the camera near the top with its lens facing up, the orange ribbon running straight and flat down into J1

The ribbon path: camera at the top, lens towards the back cover; ribbon flat, straight, no twist, no sag, into J1.

Whole component side with the camera and its ribbon running straight down the middle into J1

Whole board: the ribbon runs down the middle of the board.

- Board unpowered.
- Cut a square of thin double-sided tape (0.1 mm or less) a little smaller than the camera's base and put it on the back of the camera. Not foam tape: 1 mm of foam pushes the lens into the cover.
- Stick the camera centred on its Kapton spot, square to the board (lens axis straight out of the back; a tilt shows as a dark corner in the preview). If your ribbon measured under about 70.3 mm, shift it up to 1.7 mm towards J1, no more. Centre to the hole within about 0.8 mm: more than that and the 7 mm hole starts to shade the picture's corners.

Delicate: J1 (same moves as J2 in step 5)

J1 close-up with its dark latch bar at the front and the pin-1 end marked on the left

J1 open: dark bar up. Pin 1 is at the left end in this view. The ribbon enters from the side away from the bar (the top here).

J1 with the camera ribbon straight in from the top and the latch pressed down

J1 closed: ribbon straight in all the way, nothing of the contacts showing, bar flat.

Which way it faces: exactly as it comes off the camera lying lens-up, laid flat down the board. No twist, no flip: the board was designed for that (its contacts then face the board from the render, not seen on the real ribbon). How far: until it stops, about 2 mm, square, no gold showing.

- Lift J1's dark bar to about 90° with a fingernail at its middle.
- Slide the ribbon straight into J1: no twist, no flip. All the way in, the same depth at both corners.
- Press the bar flat in the middle. Light tug: it must not move.
- Lay the ribbon flat, no S-shaped loop. No slack sagging where it crosses the middle rib of the back cover (only 0.48 mm to spare there). If it has spare length, let it lie as a gentle flat bow, not a loop standing up.

Cut-away through the camera module under the 7 mm window in the back cover

How close it is: the lens top ends about 0.5 mm below the inside of the cover. That's why the tape must be thin.

- Only if you left the hole for now: measure the lens centre with calipers from the board edge or a post hole, mark the same spot inside the back cover method: suggestion, then drill as in the grinding guide zone 3 (pilot, then 7 mm). For reference the normal spot is on the centre line, 38.0 mm down from the back cover's own top outer edge; a camera shifted towards J1 moves the hole the same distance further from the top. Wash out the dust.
- Hold the back cover on and look through the hole: the lens is in the middle, with an even ring of lens barrel visible all round (the lens top sits 0.5 mm below the floor's inside face, so a 0.5 mm ring of light can enter beside it; it only lights the board, nothing that matters).
- Know the camera's reach: the OV5640 autofocus module focuses from about 10 cm to far away. A worksheet is read with the calculator held 15–30 cm above the page, back facing down; it cannot focus lying flat on the page. The firmware runs the autofocus before each shot.

the camera has only 0.71 mm to the edge of the hole and 0.5 mm to the cover: thick tape, a tilt or an off-centre camera shows up as a dark corner or a cover that won't close. A loop in the ribbon gets pinched by the mid rib.

If the camera fails laterJ1's pin order is about 90 % sure. If camera_ok is false after reseating once, the known fix is a 180° twist along the ribbon's length (J1 makes contact on both faces). The power-up test should already have settled this.

Check before moving on

- Lens centred in the hole, even ring all round.
- J1 bar flat, ribbon doesn't move.
- Ribbon lies flat along the board, no twist, no standing loop.

Common mistakes

- Foam tape under the camera.
- Touching the lens glass (fingerprint = blurry pictures). Hold the module by its sides with tweezers.
- Flipping the ribbon to "make it reach": it never needs that.

the camera is stuck down under the hole, the lens shows in the middle of the hole, and the ribbon is flat and locked in J1.

## 07Magnet piece into J3

≈ 10 minDifficulty: easy, polarity critical

You'll needThe magnet piece (VBUS leg marked in step 4), flat pliers, side cutters, the multimeter on beep, the board map (step 3).

J3 is a sideways socket at the board's top edge, its holes facing the top wall. The magnet piece's legs push into it. Later its face is glued flush in the U-notch. The glue takes the cable's pull, never the legs.

Magnet piece above J3: N mark on the face, the pen-marked leg at the N end lines up with pin 1 = VBUS; pin 4 = GND at the other end

Line-up: the pen-marked leg at the N end goes into pin 1 (VBUS, silk "N" / "+"); the other outer leg into pin 4 (GND, silk "−"). The face points away from the board, towards the top wall.

- The magnet meter check from step 4 passed. Don't go on without it.
- VBUS leg into pin 1 (silk "N" / "+"), so the GND leg goes into pin 4 (silk "−"). J3 is 1 VBUS, 2 D−, 3 D+, 4 GND. Start all four legs in their holes before pushing.
- Push about 4.5 mm deep, body square to the board edge. If the legs bottom out before the face would be flush, trim 0.5–1 mm off them with side cutters (all four the same).
- Meter on beep: the leg in pin 4 beeps to TP4 (GND). The leg in pin 1 does not.
- Leave it in. The legs go in sideways, so the piece rides into the shell with the board in step 8. Glue comes at the end of step 8.

The magnet piece pushed fully home with its legs inside J3

Pushed home: legs hidden inside J3, body square to the board edge.

Why polarity matters hereBackwards, the cable's 5 V lands on the board's GND. A phone charger can then push 2 A or more through D7 and the charger chip. Never test that on purpose. If the beep test says the pin-1 leg is GND: pull the piece out and ask. Never turn it over.

Check before moving on

- Pen mark at pin 1 (N end).
- Pin-4 leg beeps to TP4; pin-1 leg silent.
- Body square, not leaning.

Common mistakes

- Pushing with one leg outside its hole: it folds under the body.
- Gluing now. Glue only after the key test in step 8.

the marked leg is in pin 1, the pin-4 leg beeps to TP4, and the piece sits square on the board edge.

## 08Key mat and board into the front shell

≈ 45 min + glue setting timeDifficulty: medium

You'll needSoft cloth, the front shell with key caps, the key mat, the board with screen, camera and magnet on it, the back cover, 2 screws, the magnetic cable and PC, epoxy or hot glue, a round needle file (only if H6 binds), a soft brush or air blower.

### Key mat

Photo of the grey key mat showing its black contact dots, small post holes and two half-round notches

Your key mat, black-dot side: this side faces the board (up at you with the shell face down). The domes bulge the other way, down into the key caps. Checked on your own photos of the opened calculator (2a97120d, 478afcb6: the mat as it sat in the shell, black dots up) and against the 3D model (mat on the key side of the board, caps below it).

Photo of the empty front shell from inside with the grey rubber key mat in place; labels mark the key mat, locating posts, H6's post, clips, a screw post and where the magnet notch goes

Mat in the shell: white posts poke through the grey mat. Post H6 (lower left) is the tightest fit H6 position read from the model.

Key mat being lowered into the face-down front shell, domes towards the keys, every post through its hole, half-round notches at the bottom posts

Lowering it in: domes towards the keys, half-round notches at the bottom screw posts.

Key mat seated flat in the front shell, posts poking through

Seated: flat, every post through its hole. (The 3D mat is black; yours is grey.)

- Front shell face down on a soft cloth. All key caps in their holes. Blow out any dust.
- Drop the rubber mat in with its domes pointing down into the key caps (black dots up at you), the two half-round notches at the bottom screw posts. Hold it by its edges.
- Every post goes through its hole. The mat lies flat with no fold or bump; run a fingertip over the flat parts (not the dots).

a mat that sits on a post instead of around it lifts the board there: that key and its neighbours stop working, and the board rocks.

Delicate: dropping the board onto the posts

The board, key side down, being lowered onto the posts; hole H6 and its post circled

Line up H6 first, then lower the board flat. The magnet rides along at the top end into the U-notch.

The board, key side down, being lowered onto the posts of the front shell, with the magnet piece riding along at its top edge towards the U-notch

Whole view: key side down (screen towards the window), magnet at the top, H6 meeting its post.

- Hold the board by its long edges, key side down. Tilt the top end in first so the magnet face drops into the U-notch from the rim, then lower the rest. Let each post find its hole. Never force it; it should drop the last millimetre under its own weight.
- If it binds at H6 (only about 0.10 mm of play): take it out and file H6's hole a little towards the top of the board, 2–3 strokes at a time, then try again. Never file the post.

Diagram of hole H6 with its off-centre post; the hole's edge towards the board's top end is filed; never the post

Filing H6: only the hole's edge towards the board's top end. Blow the dust off before you try again.

the posts set where the key pads sit over the domes. File a post and the keys go off-centre for good; a hole can be filed a little without harm.

- Board flat on all posts, no rocking (press each corner lightly). Screen still centred in the window. Neither ribbon pinched by a post or wall.
- Solar-window side: the board's top corner and the ESP32's bare antenna tab sit free of the side wall's inner rib. If the board rocks on that side, that rib needs zone 6 of the grinding guide.
- E-paper top edge: the panel is not pressed by the rib between the solar window and the display window (it should clear by about 0.3 mm). If it is, slide the panel 0.5 mm down towards the keys before the tape sets: the picture still fits inside the window and the mask.

Close-up of the top wall: the magnet piece's black face with four gold pads sits in the U-notch, level with the outside of the wall

Magnet face flush: the black face with its 4 gold pads level with the outside of the top wall, not sunk in and not sticking out.

- Magnet face flush with the outside of the top wall, 0.45–7.45 mm below the rim. Run a fingernail across: it doesn't catch.
- Lay the back cover on (no screws): the face is still flush and the cover closes.

### Key test before gluing (cable power, no battery)

- Back cover on with two screws finger-snug, so the board presses on the mat suggestion.
- Snap the cable onto the magnet. Other end into a computer USB port.
- Serial Monitor: type selftest. Press all 50 keys (ON too) when asked; the screen counts them. Result: keys_ok 50 and keys_missing [].
- If a key is missing: cable off, open, check that key's dome for dust and that the mat is flat there, try again.

### Glue the magnet

- Cable off. Back cover off.
- Glue the magnet body into the notch with epoxy or hot glue: small beads on the sides and underneath, from the inside. The glue fills the 0.25 mm each side and the 0.7 mm gap underneath. Keep glue off the contact face, out of J3 and off the board.
- For the first build, hot glue is easier to undo if you ever need the board out suggestion.
- Let it set fully (see the glue's packet) before going on. Don't snap the cable on while it sets.

the cable snaps on and off hundreds of times. Without glue that pull goes into J3's legs and breaks them loose; with glue the shell takes it.

Check before moving on

- Board flat, no rocking, screen centred.
- keys_ok 50.
- Magnet flush, glue set, contact face clean.

Common mistakes

- Pressing the board down hard when it binds: it bends round H6 and the keys under it fail.
- Gluing before the key test: if a key fails, the board can't come out easily.
- Glue on the gold pads of the magnet face: no charging, no USB.

the board sits flat, all 50 keys count, and the magnet is glued flush and set.

## 09Battery

≈ 20 minDifficulty: delicate (tight space, polarity)

You'll needThe battery (polarity checked, lead re-taped in step 4), the two 0.1 mm tape strips (6 × 18 and 4 × 16 mm), one 10 × 15 mm Kapton strip, the back cover, a 2.5 mm drill bit (as a feeler gauge), tweezers.

The battery (Adafruit #1317, 150 mAh) lies flat on the back-cover floor, in the top-left corner as seen from the front, beside the board. Its long side (26 mm) runs left to right and the wire end faces right, towards the middle of the cover and J4. The wires stay below the board's level and the plug goes into J4. From now on the board is always powered.

Photo of the navy back cover inside up with the rough battery spot outlined in the top-left corner over the old lid opening, the corner screw post, rib A and the solar box labelled

On your own cover (inside up, top end away): the battery's corner, the screw post beside it, rib A below it, the solar box (ground flat in zone 1) to the right. Rough positions; the numbers below decide.

Delicate: where the tape goes (an L of two strips)

To-scale diagram: the cell outline, the old battery-lid opening under it marked no tape, strip 1 6 by 18 mm under the lead end, strip 2 4 by 16 mm along the bottom edge, leads down past rib A then r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

To scale: strip 1 (6 × 18) under the lead end, 1 mm in from the right edge; strip 2 (4 × 16) along the bottom edge, 1 mm in from the left and 0.5 mm above the bottom edge. Both stay off the old lid opening. Leads go down past rib A, then right, and into the plug from below.

3D view of the back-cover floor with the battery outline, the round lid opening and the two tape strips in an L

3D view of the same corner. The same L as the diagram above: strip 1 (6 × 18 mm) under the lead end, strip 2 (4 × 16 mm) along the bottom edge, both on solid floor and clear of the round lid opening.

the cell lies over the old battery-lid opening. Tape on the lid would rip the cell off its wires the day someone opens the lid. Anything on top of the cell (foam, a second tape layer) stops the cover closing: the coin-cell holder above it leaves only about 0.2 mm.

The battery flat on the floor in the corner, its leads making a short loop down and across to the white plug for J4

Placed: flat on the floor, leads down and across at J4's height, plug ready for J4.

Alternative cell: TW302030A Taiwoo TW302030 (140 mAh, 30 × 20 × 3.0 mm) also fits, in the CAD at both its nominal and worst-case size (32 × 20.5 × 3.3). Three conditions: place it 1 mm further left than the #1317 (left edge about 1.7 mm from the corner post, top edge against the lip); if it measures over about 20.3 mm wide, push its top edge right up to the lip so it clears rib A; and its leads must leave the short (lead) end. The same tape L and lead route work. It must have a protection board and a JST-PH plug wired pin 1 = GND, pin 2 = +; meter it before plugging in.

TW302030 cell in the battery corner with the worst-case outline, the tape L, the lid opening and J4

The TW302030 in place (solid: nominal size, dashed: worst case), with the tape L and the lead route.

- Both ribbons fully in, both bars closed. (After this step you may not touch them again without unplugging the battery.)
- Stick the two thin tape strips to the underside of the cell first (easier to line up than the floor): the 6 × 18 mm strip under the wire end, running top to bottom, 1 mm in from the cell's right edge; the 4 × 16 mm strip along the bottom edge, running left to right, 1 mm in from the left edge and 0.5 mm above the bottom edge. Tape only where there is solid floor, never on the battery lid; strip 1 stays 2 mm clear of the lid opening, strip 2 about 0.7 mm below it. Nothing on top of the cell.
- Peel the liners and lower the cell into its spot on the back-cover floor: top edge up against the lip of the top wall, then slide left until a 2.5 mm drill shank just fits between its left edge and the round corner screw post. Rib A should show as a 1 mm sliver below the cell. Press 10 s on the strips only, never in the middle over the lid. Route the wires: down past the cell's right edge, over the low rib A, then right towards J4. Fold the spare ~100 mm into a flat S of three runs on the floor between the cell and J4, under 4 mm tall, not over J4 or the camera ribbon, held with the 10 × 15 mm Kapton strip. Leave a free tail long enough to reach J4 with the cover tilted up. No sharp bend at the plug.

Delicate: the plug into J4 (pin 1 GND, pin 2 +)

The white JST plug in J4: pin 1 GND black wire, pin 2 plus red wire; push by the plug body

J4: pin 1 = GND (black wire), pin 2 = + (red wire). J4's mouth faces the keypad end; the plug slides in along the board, towards the top end. Push by the plug body.

- Last look before plugging: red wire on the side of J4's "+" (pin 2), black on pin 1. If it doesn't match what you metered in step 4, stop.
- Hold the back cover tilted up beside the shell's top end, battery side towards the board suggestion. Plug the battery into J4: hold the plug by its body, not the wires, line it up square and push firmly until it seats with a small click. Fully in = no gap between the plug and J4's housing.
- Lower the cover onto the shell (no screws): the battery must be held, not squeezed, and the free bit of lead folds flat beside J4, not on top of it.
- No tape, foam or glue on TP1, TP4 or TP7. Kapton wherever a bare pad could touch the battery's foil.

the board has no power switch: from this moment the ESP32 runs whenever it's awake. That's why both ribbons had to be in first. The plug only fits one way, but a cell with swapped crimps fits too: the meter is the only guard.

Cut-away across J4, its plug and the battery lying on the back-cover floor

How tight it is: J4 ends 0.41 mm above the floor. Any stub left from grinding zone 1 stops the cover closing.

Check before moving on

- Plug fully home in J4, red on "+".
- Cell flat, doesn't slide when you nudge it; nothing on top of it.
- Lead bundle under 4 mm, not over J4 or the camera ribbon.
- TP1, TP4, TP7 bare.

Common mistakes

- Tape on the battery lid.
- Leaving the #1317's lead taped on top of the cell (4.9 mm tall: the cover won't close).
- Pulling the plug in or out by the wires.
- A lead loop standing up between the cell and J4.

the plug is home in J4, the battery is snug under the test-fitted cover, and TP1/TP4/TP7 are bare.

## 10Close up

≈ 10–15 minDifficulty: easy, no force

You'll needBack cover, 6 screws, small Phillips screwdriver, battery lid, rubber feet, a torch; a marker for the "won't close" check; meter on mA only for the optional sleep test.

- Last look: camera ribbon flat, not over a screw post, not sagging onto the middle rib. E-paper ribbon still hugging the slot. Battery wires clear of the rim and low.
- Optional, now or never (cover must be off): sleep current. Switch off (SHIFT AC), wait 10 s, meter on mA in series with the battery wire. Target 40 µA or less. Skip if measured at bring-up.

### The cover in four frames

Frame 1: the back cover held parallel above the shell, its 7 mm window over the camera

1. Cover parallel to the shell, 7 mm window over the camera; battery flat, leads tucked.

Frame 2: the cover coming down level; the magnet face in its notch

2. Keep it level as it comes down. Magnet face in its notch; nothing pinched at the edges.

Frame 3: the cover resting on the rim by itself, screws ready

3. It must sit on the rim by itself, before any screw. A gap anywhere: stop.

Frame 4: the closed back with all six screws snug

4. Corner screws first, then the rest, crosswise. Snug, not tight.

- Lower the back cover straight down, level, the last 10 mm with no tilt. It must sit fully on the rim by itself, before any screw. If it rocks or leaves a gap, stop (see the box below).
- Put in all 6 screws, a little at a time, crosswise (corners first).
- Snug, not tight: stop when the head touches and the cover is firm. These screws strip plastic posts easily. Tip: turn each screw backwards first until you feel it click into its old thread suggestion.
- Run a fingernail round the rim: no gap anywhere, no bulge over the camera, J4 or the magnet.
- Battery lid and rubber feet back on.

If the cover won't sit flat

Back cover off: six numbered spots to check: J4 plug and floor stub, battery, camera, magnet lip, camera ribbon over the mid rib, e-paper ribbon at J2

The six usual causes, in the order to check them.

1. Take the cover off again. Never pull it down with the screws: the board bends and keys fail.
2. Find where it lifts: press the cover lightly at each corner; the corner that springs back is near the cause.
3. Marker trick: colour the tops of the parts there (J4's plug, the camera, the magnet body) with a dry-erase marker, close gently, open: the mark that transferred to the cover shows what hits.
4. Fix that one thing: grind the stub left in zone 1, swap foam for thin tape, re-lay a ribbon loop, notch the 5b lip, peel anything off the top of the battery.
5. Try again: it must sit by itself.

The closed calculator from the back: plain navy back cover with the small 7 mm camera window near the top

Done: a normal-looking back. The only change is the small round camera window near the top.

every gap at the rim means something inside is being pressed: a ribbon, the camera or the battery. Screws hide it for a week, then a key or the screen fails.

Check before moving on

- Cover flat with no screws in.
- 6 screws snug, none spinning (stripped).
- Camera lens visible in the middle of the window from outside.

Common mistakes

- Forcing the cover with the screws.
- Over-tightening: the plastic thread strips and that screw never holds again.
- Lowering the cover at an angle: a ribbon or the battery lead gets caught at the rim.

the cover sits flat with no gap, all 6 screws are snug, and the lid and feet are on.

## 11Final test

≈ 30 min (+ next-day check)Difficulty: easy

You'll needThe closed calculator, the magnetic cable and PC, a printed maths problem, a 2.4 GHz hotspot and your phone (the server address and token are already in the board from power-up step 10).

The finished calculator from the front, with the e-paper screen behind the display window and the ON key marked

Look for: the e-paper screen sitting square in the display window.

Photo of the calculator front with labels on the SHIFT, ALPHA and ON keys, the display window where the screen shows, the unused solar cell, and the top wall where the magnet goes

Look for: the three keys for the self-test: SHIFT and ALPHA on the left, ON on the right.

### Self-test

- Calculator off: hold SHIFT + ALPHA, press ON. (Or type selftest with the cable in.)
- Checkerboard on the screen, no dead lines, refresh 0.3–9 s. Camera OK (JPEG over 1 KB). Wi-Fi sees a network better than −80 dBm.
- All 50 keys pressed and counted. Screen shows SELF-TEST PASS. Save the SELFTEST_JSON line if the cable is in.

### Camera preview

- MODE 4 (AI SOLVE): the screen becomes a viewfinder (about 2–2.5 frames a second). Point it at a worksheet: the picture moves the right way, the crosshair is in the middle, "✓ SHARP" appears when held still.
- If the picture is mirrored or upside down, write it down: hmirror/vflip get set in the preview code's tuning once the camera's real direction in the case is known.

### AI solve through the proxy

The hotspot, server address and token went in at power-up step 10 and are still in the board. (Not done yet? Do that step first: it also says how to put the server online and make the token.) Here you check the keypad route a customer uses, then a real solve.

- Phone setup from the keys: SHIFT MODE (SETUP), 6 (Wi-Fi & key): the screen shows your hotspot and "Key: token …". Press =: SETUP BY PHONE with a network AI-Calc-xxxx and its password.
- Join that network on the phone; the form pops up (or open http://192.168.4.1). Pick your hotspot, type its password, leave the address and token as they are (empty token = keep), Save. The screen says "Saved. Closing the setup network…". AC leaves setup.
- Linked: account (cable in) shows the trial. If not, pair and <proxy>/link as in power-up step 10 (an unlinked calculator also shows its code when you press = in AI SOLVE).
- On battery, cable off: MODE 4, aim at a printed problem, press =. An answer comes back (with ✓ if the calculator agrees). If the screen says "Battery low: plug in the cable to use AI solve", the cell is under 3.6 V: charge it first (maths still works).
- status does not say "Last restart: brownout".

### Charging and sleep

- Snap the magnetic cable on: status says "(charging)", later "(USB, full)". Charge current is 50 mA (a full charge of the 150 mAh cell takes about 3.5 h). There's no charge light.
- Store 7 in A. Unplug, switch off (SHIFT AC).
- Next day: ON wakes it in about 0.3 s and RCL A still shows 7. Sleep target 40 µA or less (measured in step 10 or at bring-up).

the bench test proved the parts; this proves the assembly: no ribbon pulled loose on the way in, no key pressed by the shell, and the antenna still hears Wi-Fi through the case.

Common mistakes

- Testing AI solve only with the cable in: the battery case (brownout) is the one that matters.
- Holding the calculator flat on the page: the camera can't focus closer than about 10 cm.

SELF-TEST PASS, an AI answer came back on battery, charging shows in status, and memory survived a night off.

## QAFinal quality check (before you hand it to anyone)

≈ 10 min

One last walk round each calculator. Every line must be a yes. Any "no": open it (step 12, reopening safely) and fix that before it leaves the bench. Electrical results come from the First Power-Up Guide (https://claude.ai/artifact/PqTARcDutvwxS5aGB8iEG9) (bench) and step 11 (closed).

- The power-up guide (https://claude.ai/artifact/PqTARcDutvwxS5aGB8iEG9) results are saved for this board: TP5 3.25–3.35 V, SELFTEST_JSON line, camera ribbon length, magnet VBUS leg noted.
- Closed calculator: SELF-TEST PASS with all 50 keys, on battery.
- One AI solve on battery returned an answer; status shows no brownout.
- Cable snaps on by itself, status says "(charging)". Magnet face flush, no glue on the gold pads.
- Memory kept overnight; sleep current 40 µA or less (if measured).
- From the front: only the picture shows inside the black mask; no ribbon, no white edge, no dust or bubble under the window.
- Back cover flat all round (fingernail test), 6 screws snug, none stripped; battery lid and feet on; no rattle when you shake it gently.
- Camera lens centred in the 7 mm window; preview not dark at a corner.
- Every key clicks and returns; no key sticks down or sits higher than its neighbours.
- Notes written: calculator number (1/2), board serial or label, screw length, anything you had to file or change.

every line above is ticked for this calculator.

## 12Problems and reopening

Problem | Likely cause | What to do
Back cover won't close, gap at the rim | Stub left on the solar box (J4 has 0.41 mm), camera on foam, magnet hits a lip (5b), pinched ribbon, foam or thick tape on the battery, lead taped on top of the battery | Open. Marker on the tall parts, close gently, open, look for marks (step 10 box). Grind the marked spot; use thinner tape
Board won't drop onto the posts | H6 (0.10 mm play) | File H6's hole towards the board's top. Never the post
Keys missing in the self-test | Dust on a dome or pad, mat folded, board not pressed down | Open, clean the dome and pad with a dry brush, re-lay the mat, screws snug
Screen blank or dead lines | E-paper ribbon pulled part-way out of J2 when the board went in | Unplug the battery first, then reseat J2
camera_ok false | Ribbon not seated, or reversed | Battery off, reseat J1; then try the 180° twist
Camera picture dark at one side | Hole off-centre from the lens, or camera tilted | Move the camera slightly (within its 1.7 mm) or open the hole carefully
No charging, no COM port | Magnet face sunk in, legs pulled out of J3, deep sleep | Press ON. Check the face is flush. Then the TP1 + TP7 rescue
Restarts during AI SOLVE | Battery voltage dips (brownout) | Lower kWifiMaxTxQuarterDbm to 34 in power.h
Sleep current about 330 µA / 0.3–1 mA | Keypad interrupt stuck / camera pins | Note the number and ask (firmware fix)
Rattle | Battery loose | Re-stick it to the floor with fresh 0.1 mm tape; never add foam on top
"Battery low: plug in the cable to use AI solve" | Cell under 3.6 V: camera and Wi-Fi stay off | Charge (AI is back above 3.7 V, or at once with the cable in). Maths keeps working
"Not set up yet: SETUP 6" | Server address or token missing | SHIFT MODE, 6, = and the phone form, or power-up guide step 10
UPDATING … % after switching off on the cable | An over-the-air update from your server | Leave the cable in until it restarts. UPDATE FAILED keeps the old firmware

### Reopening safely

- Cable off. Calculator switched off.
- Face down on a cloth. Undo the 6 screws, lift the back cover straight up (the battery comes up with it, still plugged in: lift slowly).
- Unplug the battery from J4 first (by the plug body), before touching any ribbon or test pad.
- To rescue the firmware with the cover off: hold TP1 to TP4, tap TP7 to TP4 for about 0.2 s, let go of TP1, upload, tap TP7 again. Serial backup on TP2/TP3. (With the battery unplugged you can instead hold TP1 to GND while plugging in the cable.)

Taking the board out againThe docs don't cover this. The magnet is glued in the shell and its legs sit sideways in J3, so lifting the board straight up would bend the legs. Soften or cut the glue first (hot glue is easier), lift the board and magnet out together, then pull the legs out of J3 suggestion.

Sources: hardware/FINAL_STATUS.md, HANDOFF.md, ORDER_WALKTHROUGH.md §9, stage13_heights.md, stage14_verification_fixes.md, stage11_epaper_calipers.md, QUESTIONS_AND_ISSUES.md, ARRIVAL_CHECKLIST.md, enclosure/final_assembly/README.md, assembly_report.md, battery_upgrade.md §8, window_mask.md, enclosure/replica/photo_notes.md, verification/01, 03, 07 and 12, bringup_guide.html, firmware-prototype/README.md (firmware stage14-2026.10.10), server/proxy/README.md. 3D pictures from the Fusion final-assembly model (battery on the back floor); close-ups in renders/detail and renders/grind; drawn how-to pictures in renders/howto (assembly_howto_pictures.py); photos are Nirav's own.

Linked: First Power-Up Guide (https://claude.ai/artifact/PqTARcDutvwxS5aGB8iEG9) · Shell Grinding Guide (https://claude.ai/artifact/9rCWyw8MeHP2z8FWijnyfL) · entry point hardware/FINAL_STATUS.md

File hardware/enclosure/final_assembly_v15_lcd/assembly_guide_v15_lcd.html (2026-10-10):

AI Calculator · board v15-LCD (colour screen) · Casio fx-115ES shell

# v15 Assembly Guide

How to turn a tested v15-LCD board, a ground fx-115ES shell and the bought parts into a finished calculator with the colour screen. Same order as the v14 (e-paper) guide; the screen, camera-choice and checking steps are new or explained in more depth. Build one calculator at a time, in order. Tick each box as you go. Ticks are saved in this browser only, separately for calculator 1 and calculator 2, and separately from the v14 guide.

Every step has the same shape: time and you'll need, then numbered sub-steps (each with a picture, a why note and its tick boxes), a green check before moving on box, an amber common mistakes box, and a done when line. Every picture opens full size when you tap it. Labels: suggestion = my idea, the project docs say nothing. unsure = not checked on real parts, or the docs disagree. Times are rough. No v15 calculator has been built yet: the 3D pictures come from the Fusion model of the final v15-LCD board; drawings marked "diagram" are simple sketches, not to scale.

Calc 1 Calc 2

0 / 0 Clear ticks

6 rules for the whole build

1. No power while you plug a ribbon. Never plug or unplug a ribbon (LCD or camera) while the board has any power. Once the battery is in J4, the board is always powered. So both ribbons go in before the battery.
2. Never crease the LCD tail. It goes down the slot and makes one soft bow to J5. No folds, no Z-fold, no pinching. A crease can break the tracks inside it, and you can't see that until the screen fails.
3. Finger 1 to the silk tick. The LCD tail goes into J5 with its finger-1 end (found with the meter) at the bottom of J5, next to the small silk tick. Never guess.
4. Glue the magnet piece last. Only after its meter check has passed. Never "turn it over" to make it fit.
5. Never grind, file or force a post. If the board sticks on post H6, file the board's hole a little towards the top of the board. And keep TP1, TP4 and TP7 clear of tape, foam and glue.
6. Never burn eFuses, and never turn on secure boot or flash encryption.

## ··Words you'll meet

Each word has a small picture; the same parts appear big in the steps below.



LCD (panel)

The new colour screen: a 1.9-inch, 320 × 170 pixel panel (49.72 × 25.80 mm, 1.43 mm thick). It has its own light behind the picture (the backlight).



Tail (FPC)

The thin, flat, flexible cable that comes out of the LCD, 15.5 mm wide and 36.6 mm long, with 30 gold fingers at its tip. FPC means "flexible printed circuit". Bend it gently over a fingertip; never crease it.

Stiffener

The last 4.5 mm of the tail is backed with a stiff strip, so the tip can be pushed into the socket. That part stays straight. Your finger-1 dot goes on it.



Finger 1

The gold finger at one end of the tail. It must go to pad 1 of J5. You find it with the meter's diode test (step 4) and mark it with a dot.

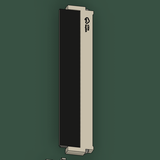
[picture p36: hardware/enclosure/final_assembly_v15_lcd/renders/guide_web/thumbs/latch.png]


Connector latch (lid)

The small hinged bar on a ribbon socket (J1, J5). Lift it to open the socket, slide the ribbon in, press it flat to lock. A ribbon never goes in or out while the lid is closed.



J1, J3, J4, J5

Names printed on the board for its connectors. J1 = camera ribbon. J3 = magnetic charging piece. J4 = battery plug. J5 = LCD tail (new on v15; v14's J2 is gone).



Slot

The long narrow hole near the board's edge (1 × 20 mm). The LCD tail goes through it from the key side to the component side.



Bow

The one soft U-shaped curve the tail makes under the board. All the spare tail length (about 6.4 mm) lives in it. Its lowest point hangs about 4.7 mm below the board.



Rib B

A low plastic wall inside the back cover. Its middle 14 mm is ground flat over the camera (grinding zone 2). The un-ground part beside it sits just 0.25 mm under the tail's bow: the tightest spot in the build.

Kapton

Thin, orange, heat-proof tape that doesn't conduct electricity. You put it between parts so nothing bare touches.

ESD

Static electricity. A spark you don't even feel can kill the LCD's driver chip. Touch something grounded (a radiator, the PC case) before you handle the panel, and don't work on carpet in socks or a fleece.



Test pad (TP)

A small round bare copper spot on the board, labelled TP1, TP2… TP1 = BOOT, TP4 = GND (ground, 0 V), TP7 = EN (reset).



Polarity

Which wire is + and which is −. Battery and charging power only work one way round. Backwards can damage parts.

Meter modes

"Beep" (continuity) beeps when two points are connected by metal. "Diode" mode (symbol →|) pushes a tiny current and shows the voltage it needs: a white LED shows about 2.4–2.9 V.



Key side / component side

The board's two faces. Key side: the flat side with the key pads, facing the keys and the screen. The LCD is taped here. Component side: the side with all the parts, facing the back cover.



Position jig

A paper template (lcd_position_jig_v15.svg) that you lay on the key side: its window shows exactly where the panel goes, its cut-out shows the slot.



Window mask

A thin matte-black sticker on the inside of the clear window lens. Its 43.72 × 23.70 mm opening shows only the picture and hides the panel's edges and tail.



Pill

The black carbon dot under each rubber key dome. When you press a key, the pill bridges the gold fingers of the key pad on the board.



S-fold, tuck bay

Only for the DCXYX camera: its ribbon is about 8 mm longer, so the spare length is folded into a soft S that sits in the "tuck bay", a floor pocket in the back cover between rib C and the small round ring.

Protection board

A tiny circuit board on the battery's wire end, usually under the tape. It cuts the battery off if it is shorted, over-charged or run flat. Never cut it off.

## 00Overview: what goes where

The board sits in the front shell exactly where Casio's board was, key side towards the rubber key mat. The LCD is taped to the key side, behind the display window. Its tail goes down through a slot in the board, makes one soft bow under the board and plugs into J5 on the other side. The camera, the battery and the magnetic charging piece are all on the component side, facing the back cover, exactly as on v14.

Exploded view from the front: window lens, front shell, key mat, board with the LCD, magnetic connector and cable, back cover, six screws

Look for: the order of the layers, top to bottom: window, front shell, key mat, board (LCD on top), back cover, 6 screws.

Exploded view from the back: back cover with camera window and battery lid, board with camera and ribbon, battery, key mat, front shell

Look for: the camera looking out through a 7 mm hole in the back cover, and the battery lying on the back cover's floor.

### The order of work

1. 1Take the Casio apart
2. 2Grind the shell
3. 3Test the bare board
4. 4Prepare parts (diode test, tail length)
5. 5LCD on, tail into J5, mask
6. 6Camera on (Seeed or DCXYX)
7. 7Magnet piece into J3
8. 8Mat, board into shell, glue magnet
9. 9Battery into J4
10. 10Close
11. 11Final test
12. QAFinal checklist

Battery is lastThe board goes into the shell (step 8) before the battery (step 9). The battery lies beside the board and plugs into J4, so it can only go in once the board is seated. It must be the last thing connected.

Step | Time (rough) | Hard part
1 Take apart | 20 min | Keeping key caps in order
2 Grind | 1–2 h + drying | Not grinding too deep (floor ≥ 0.8 mm)
3 Test board | 15 min + power-up guide | Done in the power-up guide
4 Prepare | 45 min | LCD diode test and tail length
5 LCD | 45 min | One soft bow, finger 1 at the tick
6 Camera | 15 min (Seeed) · 35 min (DCXYX) | DCXYX S-fold
7 Magnet | 10 min | VBUS leg in pin 1
8 Board in | 40 min + glue | H6 post, screen and key test
9 Battery | 15 min | Polarity, lead routing
10 Close | 15 min | Bow vs rib B marker check
11 + QA | 45 min + next day | Nothing hard: just thorough

### Parts for one calculator

- AI CALC v15-LCD board (assembled by JLCPCB). Silk: "AI CALC v15-LCD 2026-10-08".
- One Casio fx-115ES with all its pieces: front shell, back cover, rubber key mat, key caps, display window, battery lid, rubber feet, 6 screws. Both calculators should be the same edition (back label: fx-115ES, PLUS or PLUS 2nd edition) open question.
- Camera, one of: Seeed OV5640 autofocus (from the XIAO ESP32S3 Sense kit; 8.5 × 8.5 × 5.4 mm; ribbon about 70.5 mm from the module's far edge to the tip, about 62 mm beyond the module), or DCXYX OV5640-AF (DCXYX-LZTKQJ-5M-339-V1; ribbon about 78.5 mm far edge to tip, 70 mm beyond the module, narrow 6 mm ribbon with a 12.5 mm wide tip). Measure yours in step 4: it decides the route in step 6.
- 1.9" 170 × 320 IPS LCD, ST7789, 30-pin tail. Baseline: BuyDisplay ER-TFT019-1 (the version without touch panel), a bare panel 49.72 × 25.8 × 1.43 mm, tail 36.6 mm. Other panels: see the panel-choice box below. (If you use a panel taken from an Adafruit #5394 breakout instead, step 3 shows how to free it.)
- Battery: Adafruit #1317 (3.7 V, 150 mAh, 26 × 19.75 × 3.8 mm, JST-PH plug), or a generic TW302030 140 mAh cell with a protection board and JST-PH plug (see step 9: its size and polarity must be checked).
- Adafruit #5358 magnetic connector piece (the calculator half). One #5412 cable works for both calculators. Equivalents: Yiwei MG04254FRA1S1N (same part as #5358) and the Yiwei MG0425-UB-60-4P cable (same pin order as #5412); the meter check is the same.
- Supplies: Kapton tape. Thin double-sided tape, 0.1 mm or less (for example 3M 9080, or a loop of Kapton), for the LCD, the camera and the battery: no foam anywhere. Matte black sticker paper or vinyl for the window mask. Epoxy or hot glue for the magnet. A fine permanent marker. Lipstick or a whiteboard marker for the step-10 contact check.

Panel choice: which LCD, and what changes

All three are the same 30-pin ST7789 glass with the same pin order, outline (25.80 × 49.72 mm), active area and finger-1 end, so the board, jig, mask and steps are the same. What differs is the thickness and the tail-length limit.

Panel | Thickness | Tail OK up to (glass edge → tip) | Notes
BuyDisplay ER-TFT019-1 (no touch) | 1.43 mm | 37.0 mm | Baseline. Everything in this guide was modelled with it. Drawing: 36.6 ± 0.3 mm. 1.27 mm free to the front plate.
Sungood (1.43 mm build) | 1.43 mm | 37.0 mm | Treat exactly as the baseline. not in the project docs: check the thickness and tail on yours
Goldenmorning T190X7-C30-01H | 2.03 mm (2.18 worst) | 37.5 mm (37.6 at 2.18) | Fits with conditions (REPORT_goldenmorning.md): confirm the real thickness; only 0.67 mm (0.52) left to the front plate, so nothing may sit on the glass. Its 36.6 ± 0.5 tail length is measured from the frame edge, about 0.6 mm beyond the glass, so from the glass it is about 37.2 (36.7–37.7): measure the sample. The thicker panel raises the bow, so it actually has more room above rib B. Same 0.1 mm tape (0.15 also works).

## ··Parts and tools gallery

Lay everything out on a clean, bare table before step 4. The small tags say which steps use each item.

### Parts

The v15-LCD board, component side v15-LCD boardTested first (step 3).steps 3–11

LCD panel with its tail LCD panelER-TFT019-1 or equivalent, bare.steps 4, 5, 8

Seeed camera on the board Seeed cameraStraight ribbon.steps 4, 6

DCXYX camera with its S-folded ribbon DCXYX cameraLonger ribbon: S-fold.steps 4, 6

Battery on the back-cover floor Battery#1317 or TW302030.steps 4, 9

Magnet piece above J3 Magnet piece + cable#5358/#5412 or Yiwei.steps 4, 7, 8

The Casio fx-115ES Casio fx-115ESShell, mat, caps, screws.steps 1, 2, 8, 10

Window mask above the lens Mask + jig (paper)Print both at 100 %.steps 4, 5

### Tools and supplies

MultimeterVolts, beep, diode, mA.steps 3, 4, 7, 9, 10

CalipersTail length, ribbon, screws.steps 1, 2, 4, 6

Fine tweezersRibbon tips, tape.steps 5, 6

Plastic pick / cardLifting latches, never metal.steps 3, 5, 6

2 sewing pinsFine probe tips (0.5 mm fingers).step 4

Kapton tapeInsulating, heat-proof.steps 4, 6, 9

0.1 mm double-sided tapeNo foam anywhere.steps 4, 5, 6, 9

Fine permanent markerFinger-1 dot, leg mark.steps 1, 4, 7

2.4 mm drill (shank)Rod for the DCXYX S-fold; 2.5 mm feeler for the battery gap.steps 6, 9

Craft knife + steel rulerNew blade, for the mask.step 5

Isopropyl + microfibreLens and board cleaning.steps 5, 8

Small Phillips screwdriver6 screws, snug not tight.steps 1, 8, 10

Side cutters, flat pliersLeg trim, straightening.steps 1, 4, 7

Hot glue or epoxyMagnet body only.step 8

Lipstick / whiteboard markerContact check, rib B.step 10

Phone charger + cableMagnet meter check only.step 4

Grounded metalTouch before the LCD (ESD).steps 3, 4, 5, 8

## 01Take the Casio apart

≈ 20 min

You'll needSmall Phillips screwdriver, a soft cloth, a cup for screws, side cutters, calipers, a marker, a clean bag for the key mat, a tray for loose key caps.

Identical to v14. You keep the outside and throw out the insides. Keep: front shell, back cover, rubber key mat, key caps, display window, battery lid, rubber feet, all 6 screws. Remove: the Casio board, the Casio LCD module, the LR44 coin cell. The docs don't describe how this Casio comes apart, so these steps are general practice suggestion.

### 1.1Battery out, screws out≈ 5 min

Photo of the opened Casio front shell with its green board and silver LCD module still inside, labelled: remove LCD module, remove Casio board, take the coin cell out first, cut these wires, keep th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

Look for: the green Casio board and the silver Casio LCD module, which both come out. The grey shell and its posts stay. Cut the wires at the board.

- Take the LR44 coin cell out first, so nothing can short while you work. It sits in a round cup in the top corner.
- Lay the calculator face down on a soft cloth.
- Undo the 6 screws on the back. Put them in a cup.
- Measure one screw with the calipers and write down its length. The 3D model assumes 2 × 8 mm self-tapping screws assumed.
- Lift the back cover straight up. If it sticks, look for a missed screw. Don't pry.

a loose coin cell can short across the Casio board while you cut wires; and the plastic clips break if you pry instead of finding the last screw.

### 1.2Casio board and LCD out≈ 10 min

3D picture of the empty front shell with the black key mat inside, next to the open back cover, labelled key mat, front shell, back cover and display window

Look for: this is what you keep: the front shell with the key mat in it, and the empty back cover. (The 3D mat is drawn black; yours is grey.)

- Cut or unsolder the wires going to the Casio board (including the solar cell's wires) at the board end.
- Keep the shell face down so the key caps stay in their holes. Lift the Casio board straight up off the posts, together with its LCD module (a flex joins them). Unclip the LCD gently from the side clips.
- If the grey rubber key mat sticks to the board, peel it off slowly from one corner. Hold the flat sheet, never a dome. Don't touch the black dots under the domes suggestion. Put the mat in a clean bag.
- Solar cell: leave it glued in its window as a cover. Only if it falls out: cover the window with a sticker.

the black dots (pills) under the domes are what close each key on the new board. Skin grease on them makes keys unreliable.

### 1.3Measure and label≈ 5 min

Photo of the empty front shell from inside with the grey rubber key mat in place

Look for: an empty shell with the mat in it. Write "1" or "2" inside, away from the posts.

- Measure the Casio board's thickness with the calipers and write it down. Ours is 0.8 mm.
- If key caps come loose, keep them in rows on a tray so each goes back in the same hole suggestion.
- Write "1" or "2" inside both shell halves with a marker, so halves, mats and screws stay together.

Check before moving on

- Coin cell out, no Casio electronics left in either half.
- All 6 screws in the cup; screw length written down.
- Key mat clean and bagged; caps all present.

Common mistakes

- Prying the back cover instead of finding the 6th screw: snapped clips.
- Pulling the key mat by a dome: tears it.
- Mixing the halves of calculator 1 and 2: the ground parts no longer match.

only the empty shell halves, the key mat, the key caps, the small parts and 6 screws are left, labelled 1 or 2.

## 02Grind the shell

≈ 1–2 h + drying

You'll needThe grinding kit, safety glasses and a mask (all listed in the grinding guide), calipers, flush cutters, and your camera choice (Seeed or DCXYX, see step 6), because it decides where the camera hole goes.

The grinding is exactly the same as for v14. The 3D check of the v15 model found nothing of the LCD, its tail or J5 touching the un-ground shell, so there is no new grind and none can be skipped. Follow the Shell Grinding Guide (https://claude.ai/artifact/9rCWyw8MeHP2z8FWijnyfL) step by step: it has the tools, safety rules, before/after pictures and the depth to check for each zone. In short:

Zone | Part | What | Why
1 | Back cover | Solar box flat to the floor, no stub | J4 is only 0.41 mm from the floor after this
2 | Back cover | Rib B flat for 14 mm over the camera | The camera lens would hit it
3 | Back cover | Camera window: 7 mm drill (small pilot hole first) | The camera's view. See the notes below
4 | Front shell | LR44 cup: don't grind | Not needed with the battery on the back floor
5 | Front shell | U-notch in the top wall for the magnet face | The magnet face sits flush in it
5b | Back cover | Lip under the magnet notch, only if your cover has a lip there | The magnet body would hit it
6 | Front shell | Side-wall relief on the solar-window side, only if the paper template won't drop in | The board's top corner and the ESP32 antenna tab
6b | Front shell | Snip the 3 pins and 3 wire hooks on both inner side walls flush with the rib | They cross the board plane
6c | Front shell | Rib ends, only if the paper dry fit says so (the grinding guide's check) | Decided on your shell, not modelled

### 2.1Back cover: zones 1, 2 (and 5b)≈ 45 min

Inside of the back cover, straight on, with every grind zone numbered, after grinding

Look for: where each back-cover zone is. (v14 grinding picture; the back cover is the same for v15.)

Rib B after zone 2: the middle 14 mm ground 1 mm down to the floor

Look for: zone 2: only the middle 14 mm of rib B, flush with the floor. Leave the rest of rib B alone for now.

rib B carries on beside the ground part, and the LCD tail's bow hangs over that un-ground part with only about 0.25 mm to spare. Grinding it now "just in case" weakens the cover for nothing; step 4 (tail length) and step 10 (marker check) tell you if it is needed.

### 2.2Camera hole (zone 3): where, and when≈ 20 min

Inside of the back cover after grinding: rib B ground flat and the 7 mm camera hole drilled in the middle

Look for: inside the back cover after zones 2 and 3: the rib ground flat and the round 7 mm hole in the middle of it.

Camera window drill position from outside, with distances from the top edge and the side edge

Look for: the normal drill spot measured from outside (top edge and side edge).

Decide the camera first

- Seeed, ribbon 70.3 mm or more (far edge → tip): drill at the normal spot now.
- Seeed, shorter: wait. In step 6 the camera moves up to 1.7 mm towards J1, and you drill where the lens really ends up.
- DCXYX with the S-fold (recommended): the camera stays at the normal spot: drill there now.
- DCXYX fallback (camera moved 8 mm): the hole is drilled 8 mm further from J1 (towards the top of the calculator). Only choose this if the S-fold has been tried and won't sit. Don't drill the normal hole first.

a drilled hole can't be moved. The whole point of the camera choice is where the lens sits, so the drill waits until you know.

### 2.3Front shell: zones 5, 6b (6, 6c only if needed)≈ 40 min

Front shell inside, straight on, every grind zone numbered, after grinding

Look for: the U-notch in the top wall (zone 5) and the snipped pins and hooks on both side walls (6b).

- Zones 1, 2, 5 and 6b done (and 5b if there was a lip, 6 / 6c if the paper template said so).
- Pre-grind checklist from the grinding guide measured and written down.
- Floor still at least 0.8 mm thick everywhere (calipers).
- Zone 3 camera hole drilled at the spot your camera choice needs, or deliberately left for step 6.
- Screw posts, locating posts, clips, walls, key holes and the rest of rib B untouched.
- Both halves washed or blown completely clean. Dust under a key dome stops that key working; dust on the LCD shows in the picture.
- If you washed them: both halves fully dry before any electronics come near.

Rib B: the one thing to leave alone for now

The un-ground part of rib B (seen from the inside, to the right of the camera hole) sits under the LCD tail's bow. In the model the bow clears its top by about 0.25 mm with a 36.6 mm tail, about 0.1 mm with a 36.9 mm tail, and touches from about 37.1 mm. Don't grind more of it now. Only if step 4 measures a tail over 37.0 mm, or step 10's marker check shows the bow squeezed, grind zone 2 extended: the same 1 mm depth, about 15 mm further towards that side (the slot side) rib height from the replica model.

Check before moving on

- Floor ≥ 0.8 mm everywhere you ground.
- No stub left on the solar box (zone 1): J4 has only 0.41 mm.
- Camera hole drilled where your camera choice needs it, or deliberately not yet.
- Both halves clean and dry.

Common mistakes

- Grinding all of rib B "to be safe": not needed, and it can't be put back.
- Drilling the camera hole before choosing the camera (DCXYX fallback needs it 8 mm away).
- Leaving dust in the key holes: dead keys in step 8.
- Filing a post because the board is tight: never. File the board hole (step 8).

all planned zones are ground, nothing else is touched, and the shell is clean and dry.

## 03Test the bare board

≈ 15 min here + the power-up guide

You'll needThe v15 First Power-Up Guide (https://claude.ai/artifact/BeQnacuLhchaHz492CnLRT), the board, the LCD (bare), the camera, the battery, the magnet piece and cable, the multimeter, the PC, a plastic card.

Before anything goes into a shell, the bare board must pass the v15 First Power-Up Guide (https://claude.ai/artifact/BeQnacuLhchaHz492CnLRT): inspection, meter checks, first power on USB, flashing firmware-v15-lcd, the self-test, then screen, camera and battery one at a time. This guide doesn't repeat it. The ER-TFT019-1 (and the Sungood and Goldenmorning panels) arrive bare, so there is nothing to free: skip sub-step 3.2.

### 3.1Know the board before you test it≈ 5 min

v15 board component side with test pads, J1, J3, J4 and J5 labelled

Component side: J5 (LCD) at the upper right with the long slot beside it, J1 (camera) near the bottom, J3/J4 in the top corner, TP1/TP4/TP7.

v15 board key side with key pads and the screen area

Key side (seen from below, so left and right are swapped): the LCD lies here; keep the gold key pads clean.

every later step names these parts. Two minutes with these pictures saves plugging the wrong socket.

### 3.2Only if your panel is on an Adafruit #5394 breakout: taking it off≈ 10 min

On the breakout, the bare panel is held on the front by double-sided tape, and its tail wraps round the board's edge into a 30-pin socket on the back. You want only the panel. The socket type is read from Adafruit's PCB files, not seen yet: check when yours arrives

Diagram: work the card slowly along under the panel. Never bend the glass, never pull by the tail.

- Unplug the breakout from everything (no wires, no power).
- Touch something grounded (radiator, PC case) first. Work on a bare table or a cloth, not on carpet, no fleece suggestion.
- Turn the breakout over. Find the socket where the gold tail goes in. With a fingernail, gently lift its dark hinged bar (the latch) about 90°. It hinges up; it doesn't come off. If it is a slide-out drawer instead, pull the drawer out about 1 mm by its two ends. If nothing moves with light pressure: stop and send a photo. Don't pry the white housing.
- Slide the tail straight out of the socket. If it resists, the latch isn't open. Never pull hard.
- Turn back to the front. Slide a plastic card under the panel from the end away from the tail, between the panel and the breakout, and work it slowly across to release the tape. Lift the panel; never bend the glass, never pull it by the tail.
- Hold the panel by its edges, the glass and the backlight together. Adafruit warns that the backlight (the white layer under the glass) can come away if nothing holds it: if it does, press it straight back on, edges lined up, and handle the panel even more gently until it is taped in step 5.
- Peel any old tape off the back of the backlight. Leave the clear protective film on the glass until step 8.
- Store it glass side down on a soft cloth. Don't bend the tail at its root (where it leaves the glass). Keep the breakout: it is a spare tester.

Must pass before assembly

- Power good: TP5 reads 3.25–3.35 V, TP7 high, nothing warm.
- firmware-v15-lcd flashed; status shows v15lcd-….
- LCD tail diode test done, finger-1 corner marked on the stiffener (power-up step 5 = this guide's step 4.5).
- Self-test with LCD and camera connected: colour bars seen, backlight sweep seen, lcd_ok, backlight_ok, camera_ok, keypad_scanner_ok, wifi_ok all true. The 50-key test waits until the key mat is on (step 8).
- Panel flags settled (colours right way round), written on the bag.
- Battery charging seen in status; AI settings in (power-up step 11).
- Power-up guide finished on this board. SELFTEST_JSON line saved in a text file.
- Battery unplugged from J4 and cable off. LCD tail and camera ribbon unplugged (lids opened first). The board has no power at all.

Check before moving on

- Every line in the red box is true for this board.
- The board has no power: no battery, no cable.

Common mistakes

- Skipping the power-up guide because "it's the same board": a fault found inside a closed case costs an hour.
- Unplugging a ribbon with the battery still in J4.

the board passed every check above, the panel is bare (or free of its breakout) with finger 1 marked, and the board is unpowered.

## 04Prepare the parts

≈ 45 min

You'll needMultimeter (with diode mode), two sewing pins, phone charger, the #5412 cable, flat pliers, a fine marker, calipers, Kapton tape, scissors, thin (0.1 mm) double-sided tape, a printer. Touch something grounded before the LCD.

Most of these checks are in the power-up guide (its steps 3–5). If you did them there, just tick them here. Do them on the real parts of each calculator. The LCD part is explained in more depth here because it decides the rest of the build.

The five parts laid out: the board seen from its component side, the LCD panel, the camera module, the battery with its plug, and the magnet piece with four legs

Look for: the five parts you'll fit, laid out. The ribbons on the screen and the camera are not drawn here.

### 4.1Magnet piece: find VBUS with the meter≈ 10 min

Magnet piece above J3: N end equals pin 1 equals VBUS, pin 4 GND, pen-mark the VBUS leg

Look for: the N end of the face, the leg you pen-mark, and where it goes: J3 pin 1.

Diagram: outer leg to outer leg = about +5 V. If it reads −5 V, swap the probes, never the legs.

- Meter check passed with the real #5412 cable (power-up guide step 3): +5 V leg found on a phone charger, inner legs 0–0.6 V, D− and D+ beep to USB-A pins 2 and 3. (Same check for the Yiwei MG04254FRA1S1N piece and MG0425-UB-60-4P cable.)
- VBUS (+5 V) leg marked with a pen. It goes into J3 pin 1.
- All 4 legs straightened with flat pliers, pointing straight back out of the body.

the piece looks the same both ways round, and its legs fit J3 both ways. Only the meter knows which leg carries 5 V. Backwards, 5 V lands on the board's ground.

### 4.2Battery: polarity and wrap≈ 10 min

JST-PH plug in J4: pin 1 GND black wire, pin 2 plus red wire

Look for: J4 pin 1 = GND (black), pin 2 = + (red).

Diagram: hold the plug the way it will go into J4 (opening towards you: − left, + right), then meter it. A minus sign = reversed.

- Polarity checked with the meter (power-up guide step 4): the plug contact that meets J4 "+" is on the red wire and reads a positive voltage (about 3.0–4.2 V). Probe tips must not touch each other.
- Battery wrapped in one layer of Kapton, wire exit and protection board left as they are (don't peel the maker's tape) suggestion.
- Cut two strips of 0.1 mm double-sided tape for under the battery: 6 × 18 mm and 4 × 16 mm. No foam pad.

generic cells are often wired the other way round in the plug. Reversed, the battery fights the charger. If reversed: swap the two crimp pins in the plug (lift each tab with a needle, slide out, swap, click back), then meter again. No soldering.

### 4.3Camera: beep test, ribbon length, which camera≈ 10 min

Diagram: measure with calipers from the module's far edge to the ribbon tip. The same beep test works for both cameras: fingers 2 and 15 beep to each other (both GND).

- Ribbon beep test passed: fingers 2 and 15 beep to each other (both GND). (DCXYX: the drawing shows the same pin order as the Seeed, but it is low resolution: this test confirms it.)
- Ribbon measured, module far edge → tip: ____ mm. Seeed under about 70.3 mm means the camera shifts towards J1 in step 6. About 78.5 mm means DCXYX: S-fold in step 6.
- A piece of Kapton (about 13 × 13 mm) on the board where the camera will sit.

the ribbon length decides the camera position and route, and the camera position decides the hole in the back cover. One measurement now avoids a wrong hole.

### 4.4LCD: handling the bare panel≈ 3 min

Diagram: the panel is a stack of glass on a white backlight. The tail is bonded only to a narrow ledge by the driver chip: that root is the weakest point.

- ESD first: touch a radiator or the PC case before you pick it up, and again if you stood up and walked. No carpet, no fleece, no plastic tray rubbed on clothes. Keep the panel in its anti-static bag until you need it suggestion.
- Hold it by the two short edges, glass and backlight together, between finger and thumb. Never by the tail, never by the glass alone (the backlight can come away).
- No fingers on the gold fingers of the tail: skin grease makes a poor contact in J5.
- Protective film: the clear film on the glass protects the polarizer from scratches and fingerprints. Leave it on through steps 4–7. Peel it in step 8, just before the board goes into the shell: peel slowly from the tab (fast peeling makes static), then blow off dust and don't touch the glass again.
- Fingerprint on the glass after peeling? Wipe once, lightly, with a dry microfibre cloth; only if that fails, a cloth barely damp with isopropyl, no pressure suggestion.
- Store it glass side down on a soft cloth, tail lying flat. Don't bend the tail at its root.

the driver chip is right at the tail root and is the part static kills; the tail root is where a bend cracks the tracks. Both failures are invisible until the screen stays dark.

### 4.5LCD: find finger 1 with the diode test (fingers 20 and 22)≈ 10 min

The 30 gold fingers are not numbered. Plugged in the wrong way round, the screen just stays dark (nothing is damaged, but you lose time). The backlight is small white LEDs between finger 20 (+, anode) and finger 22 (−, cathode on the ER-TFT019-1; 21, 23, 24 are unused). A meter in diode mode lights them a little, and that tells you which end is which.

Diagram: sewing pins on the probe tips (the fingers are 0.5 mm apart). Count in from one end ("end A"): red on the 11th finger, black on the 9th. About 2.4–2.9 V (maybe a faint glow) = end A is the 30 end, so finger 1 is at the other end. "OL" or nothing = count from the other end.

1. Touch something grounded. Panel glass down on a soft cloth, gold fingers up.
2. Meter on diode mode (→|): red lead in VΩ→|, black in COM. A sewing pin pushed onto each probe tip.
3. Pick one end of the fingers and call it end A. Red probe on the 11th finger from end A, black on the 9th. Light pressure, no scratching.
4. Reading of about 2.4–2.9 V: end A is the 30 end. "OL": try from the other end. Neither end reads: swap the probes once. Still nothing: stop and ask (wrong panel type?).
5. Fine marker: a small dot on the stiffener (the stiff back of the tip) at the finger-1 corner. Never on the gold.
- Finger-1 dot on the tail's stiffener (power-up step 5). Diode reading noted: ____ V.

the dot is the only thing that tells you, in step 5, which way round the tail goes into J5. The meter pushes about 1 mA: enough for a faint glow, never enough to harm the LEDs. 2.4–2.9 V is a typical white LED, not from the datasheet

### 4.6LCD: measure the tail length≈ 3 min

Diagram: each extra 0.3 mm of tail drops the bow about 0.15 mm closer to rib B in the back cover.

- Measure the tail with calipers from the glass edge to the tip: ____ mm (ER-TFT019-1 drawing: 36.6 ± 0.3). Up to 37.0 mm: fine, go on. Over 37.0 mm (or over 37.5 mm on a 2.03 mm Goldenmorning): plan the zone-2 extended grind below and tell Claude before step 5.

Tail over 37.0 mm: zone 2 extended grind

Grind rib B in the back cover about 15 mm further from the zone-2 gap towards the slot side (seen from inside: to the right of the camera hole), at the same depth (flush with the floor, floor still ≥ 0.8 mm), with the same tools as zone 2 in the grinding guide. Never shorten or fold the tail to make room, and 2 mm-radius bends are not an option either (they would hang even lower).

Rib B before zone 2, with the 14 mm to remove marked in red

Look for: zone 2's 14 mm (red). The extension carries on along the same rib, about 15 mm more, on the slot side.

the bow hangs right over the un-ground part of rib B. A longer tail makes a deeper bow; squeezed by the closed cover, it can crack.

### 4.7LCD: tape strips, jig and mask template≈ 10 min

Diagram: tape only along the long sides. Nothing under the tail end.

- Cut two strips of 0.1 mm double-sided tape, about 5 × 40 mm, for under the panel size: suggestion. Only 0.1 mm: the panel has 1.27 mm to the front plate, and thicker tape eats it.
- Print the LCD position jig at 100 %, check its 50 mm bar, cut along the board-edge lines and cut out the grey panel window and the slot optional, but easier than measuring.
- Print the v15 window mask template at 100 % too (used at the end of step 5). Don't use the v14 mask: its opening is in a different place.

a printer set to "fit to page" shrinks the jig by a few percent, and then the panel ends up off-centre in the window. The 50 mm bar catches that.

Check before moving on

- Magnet VBUS leg marked; battery polarity positive on the red wire.
- Camera ribbon length written down, and you know Seeed or DCXYX.
- Finger-1 dot on the LCD stiffener; diode reading written down.
- Tail length written down and ≤ 37.0 mm (or the zone-2 extended grind is planned).
- Jig and mask printed at 100 % (50 mm bar measured).

Common mistakes

- Measuring the tail from the frame or backlight edge instead of the glass edge (adds about 0.6 mm on some panels).
- Counting fingers from the wrong end and still marking: if neither end gives 2.4–2.9 V, stop.
- Dot on the gold: the ink can spoil the contact. Dot on the stiffener only.
- Swapping magnet legs when the meter shows −5 V: swap the probes instead.
- Foam tape anywhere: it is 1 mm thick; the gaps are 0.1–0.5 mm.

the magnet leg is marked and straight, the battery is checked and wrapped, the camera ribbon is measured, the LCD's finger 1 is marked, the tail is measured, and the tape, jig and mask template are ready.

## 05LCD onto the board, tail into J5

≈ 45 min

You'll needThe LCD (finger 1 marked, film still on), the two 0.1 mm tape strips, the paper jig, a fingernail or plastic pick, tweezers, a soft cloth, the front shell (for a dry fit), the mask template and black sticker material. Touch something grounded first.

The panel lies flat on the board's key side, screen facing out through the window. Its tail leaves the panel's short end, runs about 5 mm on the key side to a 1.0 × 20 mm slot, goes straight down through the board, makes one soft bow under the board (towards the back cover) and comes back up into J5, the stiff tip going straight in. The tail is 36.6 mm; the direct route is about 30.2 mm, so the bow takes up about 6.4 mm. In the model it hangs about 4.7 mm below the board, with bends of about 1.2 mm radius: a soft U, not a fold.

Side section: the tail leaves the panel, goes down the slot, makes one gentle bow under the board and goes into J5

Look for: the whole route in one cut-away: panel, down the slot, one gentle bow, into J5. All the spare length lives in the bow.

3D view from the component side: tail through the slot, the bow, J5

Look for: the same route in 3D from the component side: through the slot, one wide bow, square into J5.

### 5.1Clean the key side and lay the jig≈ 5 min

Paper position jig on the key side: the cut-out is the LCD backlight outline, the slot cut-out shows where the tail goes down

Look for: the jig's edges on the board's edges, its slot cut-out over the real slot, the red window where the panel drops in.

- Board unpowered: no battery, no cable. Touch something grounded.
- Key side clean where the panel goes: no dust, no flux, no solder balls (a grain under the panel shows as a bright spot in the backlight).
- Lay the paper jig on the key side: its edges on the board's edges, its slot over the board's slot. Without a jig: the panel is centred along the slot's 20 mm length (slot centre = panel centre), and its tail-end edge (the backlight's edge) is 4.3 mm from the slot's near edge. (The panel outline in the KiCad file, the "KEEPOUTS marker", is not printed on the board: the jig is that marker on paper.)

the panel's picture must sit centred in the 43.72 × 23.70 mm mask opening; the jig puts it there to within a fraction of a millimetre without measuring.

### 5.2Tape the panel and place it≈ 10 min

LCD panel placed in the jig outline on 0.1 mm tape, tail towards the slot

Look for: the panel inside the dashed jig outline, tail end towards the slot.

The board seen from its key side with the LCD panel lying on its upper part

Look for: on the flat key side, near the top, centred left-right, tail end towards the left edge (seen from the key side).

- Stick the two 0.1 mm tape strips on the back of the backlight, running along its long sides, about 2 mm in from the edges (diagram in step 4.7). Keep tape off the tail, the driver-chip ledge at the tail end and the tail root.
- Hold the panel just above the board by its short edges, tail end towards the slot. Lower it into the jig's window without pressing. Pull the jig away sideways (or leave it if it lies flat under nothing: it must not end up under the panel).
- Dry fit: lower the board onto the front shell's posts (no key mat yet is fine) and look through the window from the front. The lit area should sit centred, with an even black border left and right. Lift and nudge the panel if not. Tape that has been pressed only lightly lets go easily.
- Press the panel down firmly along the taped edges only, with a fingertip through a cloth. Never press the middle of the glass.

pressing only lightly first lets you correct the position after the dry fit. The glass is thin: pressure in the middle can crack it or mark the picture.

### 5.3Feed the tail down the slot: ONE gentle bow≈ 5 min

Diagram: the bend happens over your fingertip at the slot, never sharply at the panel's edge (the tail root).

- Bend the tail gently down over a fingertip at the slot (not at the panel's edge) and feed the tip through the slot from the key side. The 15.5 mm tail fits the 20 mm slot with room either side. On the ER-TFT019-1 the tail leaves the panel about 0.5 mm off its middle, towards the finger-1 end, so with the panel centred on the slot the tail sits that much towards the slot's finger-1 end (about 2.7 mm free at one end, 1.7 mm at the other). That's normal: don't pull it to the middle.
- Turn the board over, panel side down on a soft cloth. The tail now sticks out of the slot on the component side.

Diagram: side views under the board (slot on the right, J5 on the left). Only the first one is allowed.

the copper tracks in the tail survive a soft curve many times, but a crease can crack them at once, and you can't see the crack: the screen fails later, maybe only when the case is pressed.

### 5.4J5: open the latch, check the dot≈ 3 min

J5 with the latch up (open), pin-1 end at the silk tick marked

Look for: the latch lifted up (open) and the pin-1 end at the bottom, at the silk tick.

J5 socket from above on the board render with the pin 1 silk mark circled

Look for: the small silk tick beside J5's bottom end. That is where your finger-1 dot goes.

- Lift J5's lid to about 90° with a fingernail or plastic pick at its centre. The lid is on the side away from the slot.
- Check the dot: lay the tail towards J5 with no twist. The finger-1 dot must be at the bottom end of J5, next to the silk tick (towards Q4), and the LED fingers in the top half (towards Q5). If it is at the top: stop, don't twist it yourself; write it down and ask. from the panel drawing, not seen on a real panel yet

J5 is mirrored on purpose so that a tail running naturally through the slot, with no twist, arrives the right way round. If it doesn't, something differs from the drawing, and a half twist (there are about 7 mm to spare) is a decision to make together, not a guess.

### 5.5Insert about 2 mm, square; close the latch≈ 3 min

Diagram: side view of J5. The tail goes in from the slot side; the latch hinges on the far side.

Finger 1 marked dot at the J5 silk tick, pin 1 end

Look for: the marked dot at the J5 silk tick end as the tail goes in.

J5 with the tail fully in and the latch closed

Look for: latch down, no gold showing, the tail square to the socket and not twisted.

- Let the tail curve down and back up in one soft bow, and slide the stiff tip into J5 straight and square, all the way (about 2 mm, the gold fingers disappear). Press the lid flat.
- Very light tug at the tip: it must not move.

a tip that goes in at a slant touches the wrong contacts on one side; a tip only half in loses contact when the case is pressed. Square and fully in, the latch clamps all 30 fingers evenly.

### 5.6Check the bow (and know the rib-B spot)≈ 2 min

Section: the tail bow over un-ground rib B, 0.25 mm gap with a 36.6 mm tail, 0.10 with the longest tail

Look for: the bow's lowest point right above the un-ground part of rib B: 0.25 mm with a 36.6 mm tail. You check this for real in step 10.

- Look at the bow from the side: one smooth curve, its lowest point no more than about 5 mm below the board. No kink at the slot, no fold, nothing pressing it flat. Don't tape the bow down.

If the tail is longer or shorter than 36.6 mm

Each extra mm of tail makes the bow about 0.5 mm deeper. The model has about 0.25 mm between the bow and the un-ground part of rib B with a 36.6 mm tail; at 36.9 mm about 0.1 mm, and from about 37.1 mm the bow touches the rib. Touching lightly is harmless; being squeezed by the closed cover is not. You check it in step 10. If it squeezes: zone 2 extended grind (step 4.6), never a fold.

### 5.7Quick screen test (optional here, required in step 8)≈ 3 min

The display window with the screen showing a test picture (mock-up)

Look for: a picture filling the window evenly. (Mock-up picture; the self-test shows colour bars.)

Only if the magnet piece is still pushed into J3 from the power-up guide: snap the cable on (no battery) and type selftest, q to skip the keys. Colour bars, grey ramp and border appear, then the backlight sweeps up. Cable off again before going on. Otherwise this test happens in step 8.

- Colour bars white, yellow, cyan, green, magenta, red, blue, black, left to right; the backlight sweep visible; lcd_ok and backlight_ok true. (Or: deferred to step 8.)

### 5.8The v15 window mask≈ 15 min

Through the clear window you would see the panel's black glass border, the tail end and the board around the panel. A thin matte-black sticker on the inside of the window lens hides everything except the picture. It sits about 1.5 mm above the panel, so it never touches it. The v15 opening is centred, not off-centre like v14's.

v15 window mask held above the clear lens inside the front shell, opening 43.7 by 23.7 mm

Mask off: the sticker above the clear lens, seen from inside the front shell.

v15 window mask stuck on the inside of the lens

Mask on: stuck to the inside of the lens, opening centred.

The display window with the v15 mask: a black frame around the LCD's picture area, screen off

From the front, screen off: a black frame with the picture area in the middle.

The display window with the v15 mask and the screen on, showing a mock calculator screen

Screen on: the whole picture shows, with about 8.5 mm of black on each side (mock-up).

You'll needThe template window_mask_template_v15.svg (in the repo at hardware/enclosure/final_assembly_v15_lcd/), matte black sticker paper or black vinyl (0.08–0.15 mm), a steel ruler, a new craft-knife blade, isopropyl alcohol.

- Template printed at 100 % / Actual size. Measure the 50 mm bar. If it's off, fix the print setting and print again.
- Cut the opening first (43.72 × 23.70 mm, the picture plus 0.5 mm all round): ruler + new blade, 2–3 light passes per side.
- Cut the outer edge. Easiest: the blue dashed line (60.35 × 24.00), so the sticker fits through the window and the lens can stay in the faceplate.
- Faceplate open, board not in yet: wipe the inside of the lens with isopropyl and let it dry.
- Which way round: left-right it is symmetric (10.8 mm black each side). The top band (2.76 mm) is a hair wider than the bottom (2.54 mm): keep the template's "TOP" towards the solar cell.
- Stick it on the inside of the lens, one long edge first, then roll it down from the middle out to avoid bubbles.
- Check from the front: an even black frame with the clear opening in the middle.

cutting the opening first, while the sheet is still big and flat, keeps its corners square. The opening is 0.5 mm bigger than the picture all round, so a slightly off-centre panel still shows its whole picture.

Viewing angleThe whole picture shows straight on and up to about 19° off to the side; tilt it further and the mask edge starts to cover the far edge of the picture (a few rows at 30°). That's normal for a mask above the glass if it bothers you: cut the opening at 45.5 × 24.0 for about ±43°, the panel's own black border then shows.

Check before moving on

- Panel taped flat, centred in the window at the dry fit, film still on.
- Tail: down the slot, one soft bow ≤ about 5 mm deep, no kink at the slot.
- Finger-1 dot at J5's silk tick, tip fully in, latch flat, tug passes.
- Mask on the lens, even frame, TOP towards the solar cell.

Common mistakes

- Bending the tail at the panel edge instead of at the slot.
- Pulling the tail to the middle of the slot: its 0.5 mm offset is normal.
- Pushing the tail into J5 with the latch closed: it won't go in, and it bends the fingers.
- Taping the bow down or pressing it flat "to make room".
- Pressing the middle of the glass when sticking the panel.
- Using the v14 mask: wrong opening position.

the panel is taped flat and centred in the window, its tail goes down the slot in one soft bow into J5 with finger 1 at the silk tick, the lid is closed, and the mask is on the lens.

## 06Camera onto the board

≈ 15 min Seeed · ≈ 35 min DCXYX (+ 20 min if you drill now)

You'll needCamera, thin double-sided tape (0.1 mm or less, not foam tape), Kapton, tweezers, a plastic pick, the back cover; for the DCXYX also a 2.4 mm drill bit (its smooth shank is the bending rod) and a ruler; calipers and drill if the hole waits for this step.

The camera sits on the component side, lens pointing at the back cover, centred under the 7 mm hole. Its ribbon runs to J1 near the bottom of the board. The LCD tail's bow is beside it, about 4 mm away: they don't touch. Which route the ribbon takes depends on the camera.

Camera choice: Seeed or DCXYX

| Seeed OV5640 AF (baseline) | DCXYX OV5640-AF (recommended route) | DCXYX fallback
Ribbon beyond the module | ≈ 62 mm | ≈ 70 mm | ≈ 70 mm
Route | Straight and flat to J1 | One S-fold (bends r 1.2 mm) in the tuck bay, rest straight at J1 height | Camera and window moved 8 mm away from J1; straight ribbon, 3.5 mm slack
Camera spot | Normal (up to 1.7 mm towards J1 if the ribbon is short) | Normal | 8 mm towards the top of the calculator
Change to shell / board | None | None | Shell drill only (hole 8 mm further up); no board change
Model check | Fits (v14/v15 baseline) | Fits: 0 errors; ribbon 0.44 mm above the bay floor, 0.53 mm from the ring wall | Fits, if the battery leads are dressed tight

### 6.1Stick the camera down (both cameras)≈ 5 min

Camera spot on the component side: Kapton square about 13 by 13 mm and thin tape outline

Look for: the Kapton square first, then thin tape (≤ 0.1 mm) under the module. (v14 model picture; this area is the same on v15.)

Component side of the board: the camera module near the top with its lens facing up, its ribbon running straight down the middle into J1

Look for: the camera near the top, lens facing you, ribbon running down the middle to J1 with no twist.

- Board unpowered.
- Put thin double-sided tape (0.1 mm or less) on the back of the camera. Not foam tape: 1 mm of foam pushes the lens into the cover.
- Stick the camera centred on its Kapton spot, square to the board. Seeed with a ribbon under about 70.3 mm: shift it up to 1.7 mm towards J1, no more. DCXYX: normal spot (fallback: 8 mm towards the top, see 6.4). Centre to the hole within about 0.8 mm.

Cut-away through the camera module under the 7 mm window in the back cover

Look for: how close it is: the lens top ends about 0.5–0.7 mm below the inside of the cover. That's why the tape must be thin. (DCXYX 5.6 mm tall: still 0.58 mm.)

### 6.2Seeed: straight route into J1≈ 5 min

Seeed camera with its ribbon running straight to J1, back cover removed

Look for: one flat, straight ribbon from the camera to J1.

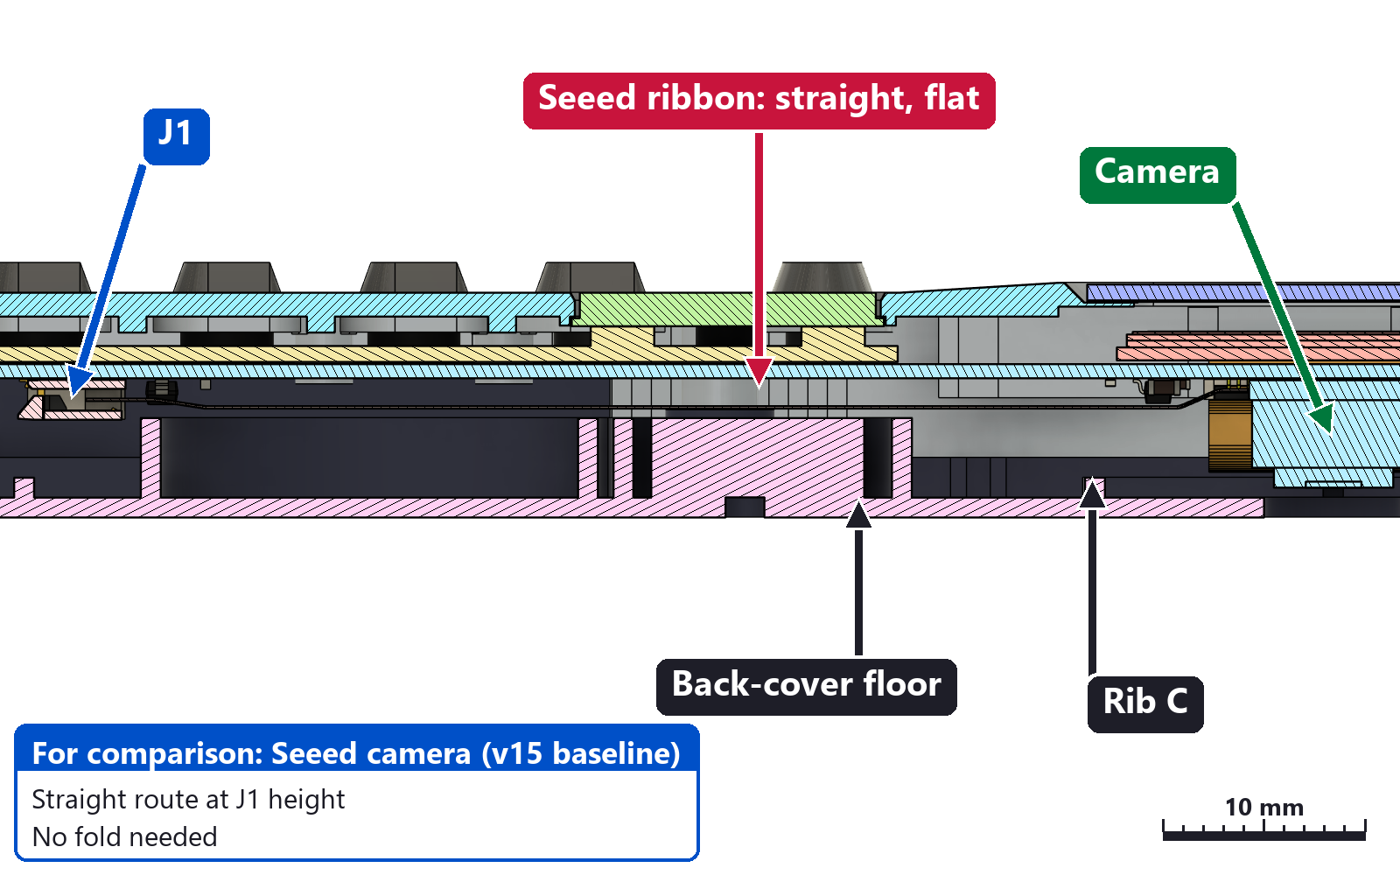
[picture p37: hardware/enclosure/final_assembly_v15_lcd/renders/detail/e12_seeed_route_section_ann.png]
Lengthwise section of the Seeed camera ribbon running straight and flat to J1


Look for: the ribbon lying flat at J1 height all the way, no loop, nothing sagging onto the ribs.

J1 camera socket with the latch up, pin-1 end marked

Look for: J1's latch flipped up before the ribbon goes in.

Close-up of J1 with the camera ribbon going straight and square into the socket

Look for: the ribbon's end square in J1, all the way, gold fingers hidden.

- Lift J1's lid to about 90°.
- Slide the ribbon straight into J1: no twist, no flip. All the way in.
- Press the lid flat. Light tug: it must not move.
- Seeed: lay the ribbon flat, no S-shaped loop, no slack sagging where it crosses the middle rib (only 0.48 mm to spare there). Keep it off the LCD tail's bow. (DCXYX: J1 is the same; the route is 6.3.)

the back cover's middle rib passes only 0.48 mm under a flat Seeed ribbon. A loop of slack there gets pinched when the cover closes.

### 6.3DCXYX: pre-bend the S-fold and place it in the tuck bay≈ 20 min

The DCXYX ribbon is about 8 mm longer than the Seeed's (about 11 mm more than the straight path needs). Instead of a loose loop, that spare length is folded into one tidy S that sits in the tuck bay: the floor pocket in the back cover between rib C (camera side) and the small round ring (J1 side), at KiCad y 108–116, x 147–153. On the real board that is straight down the ribbon's line from the camera: the fold starts about 9 mm past the camera module's edge (13 mm from the camera centre) and ends about 21 mm from the camera centre.

DCXYX camera ribbon: one S-fold in the tuck bay at KiCad y 108-116, rest straight at J1 height

Look for: the whole route: camera unchanged, one S-fold in the bay, then straight at J1 height into J1 (tip 2 mm in).

DCXYX S-fold close-up: pre-bend round a 2.4 mm rod, Kapton strip on the floor

Look for: the two soft bends (r 1.2 mm) and the Kapton strip on the floor under the fold. Gaps: floor 0.44, ring wall 0.53, board 0.54, rib C 2.58 mm.

Diagram (not to scale): A, how to form the two bends; B, where the S ends up when the cover is on. Compare with the 3D close-up above.

1. Ribbon beep test done (step 4.3). Camera stuck at the normal spot (6.1).
2. Lay the ribbon flat towards J1 and mark lightly on its back (not the gold) where the fold starts: about 9 mm past the camera module's edge marking: suggestion.
3. Hold the 2.4 mm drill bit by its shank across the ribbon at the mark. Bend the ribbon slowly round the shank, about 180°: fold 1. Slide the bit out.
4. A few millimetres on, bend the other way round the shank: fold 2. You now have a soft S. Never pinch a bend flat with fingers or pliers.
5. Check the free end now reaches J1 straight and flat with the S in place, then plug it into J1 exactly as in 6.2 (latch up, square, all the way, latch down, light tug).
6. Put a strip of Kapton on the floor of the tuck bay in the back cover, under where the S will sit. Hold the straight part of the ribbon flat to the board with a small strip of Kapton just past the fold, so the S stays over the bay second strip: suggestion.
7. Lay the back cover on (no screws) and look in from the side: the S sits in the bay, nothing pinched against the ring wall or rib C.

DCXYX route seen from the back with the cover removed: camera, S-fold in the tuck bay, straight run into J1

Look for: the fold just past the camera, between rib C and the small ring, then a straight run into J1.

- DCXYX only: S-fold pre-bent round the 2.4 mm shank (two soft bends, no crease), placed over the tuck bay (KiCad y 108–116), Kapton strip on the bay floor, ribbon straight from the fold into J1. (Seeed: tick and skip.)
- DCXYX only: cover laid on (no screws): the S sits in the bay and is not crushed. (Seeed: tick and skip.)

a loose loop of 11 mm would land wherever it likes, maybe across the middle rib (0.48 mm) or the LCD bow. Pre-bending on a rod gives a known, gentle radius (1.2 mm, the same as the LCD bow corners) and puts the spare length in the one pocket that has 6 mm of free height and no board parts.

### 6.4DCXYX fallback: move the camera hole 8 mm≈ 25 min, only if needed

Only if the S-fold won't sit (it springs open, or the cover crushes it): the camera and its 7 mm window move 8 mm away from J1 (towards the top of the calculator, KiCad y 87.1). The ribbon then runs straight with about 3.5 mm slack, like the Seeed. Shell drill only: no board change.

- The camera sits on bare board there (nearest parts: Q5 1.55 mm, J5 2.45 mm, R22 3.7 mm): Kapton under it as usual.
- The lens then ends up about 1.9 mm from rib A on the back cover: don't move further than 8 mm (limit about 8.9 mm).
- Dress the battery leads tight at the plug exit in step 9, or they touch the camera's focus motor.
- Outside, the moulded label's border crosses the new hole: pilot-drill first; it is only cosmetic.
- If you already drilled the normal hole: cover it from inside with black tape suggestion, and ask first.

Camera window seen from outside after drilling

Look for: the normal hole from outside. The fallback hole is the same 7 mm, 8 mm further from J1 (towards the top edge).

it is the one known-good fallback from the model: it needs no new board and no fold, only a hole in a different place.
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

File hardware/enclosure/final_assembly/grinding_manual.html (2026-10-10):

AI calculator · fx-115ES shell · grinding

# Shell Grinding Guide

How to grind your Casio fx-115ES shell so the AI-calculator board, camera, battery and magnet connector fit. Three jobs on the back cover (zones 1–3), the magnet notch on the front shell (zone 5), the side-wall jobs on the front shell (zones 6 and 6b), and two "only if your shell needs it" jobs (5b and 6c). Zone 4 (the LR44 cup) is kept, not ground. Every zone below has: why it's needed, the exact numbers, the tool, diagrams, steps with depth-rod checks, how to know you're done, and the usual mistakes. Go slowly: you can check every step with your calipers before you go further.

The finished calculator seen from the back, with the camera window in the back cover.

What you are working towards: the finished calculator from the back (3D model).

Read this first

The back-cover floor is only about 1.0 mm thick (your reading D5). You may never go below 0.8 mm. That leaves you just 0.2 mm of room for mistakes when you grind things "flat to the floor". Aim to stop at the floor, never into it.

## The map: what comes off, on your own shell

These are your photos with the zones drawn on. Red = remove. Orange = only if your shell needs it. Green = leave alone. The positions on the photos are rough (the camera looks at the shell at an angle); the printed grind maps and your calipers decide the exact spots.

removeonly if neededleave / keep clear

Nirav's navy back cover, inside up, with zone 1 (solar box), 2 (rib B), 3 (camera hole) and 5b (lip) marked; screw posts, rings and the v15 camera bay marked to leave.

Back cover, inside up, top end away: zones 1, 2, 3 and 5b. Leave the posts and rings; keep the v15 camera bay clean.

Nirav's silver front shell, keys down, with zone 5 (magnet notch), 6 (rib relief), 6b (pins and hooks) and 6c marked and the LR44 cup marked keep.

Front shell, keys down, top end away: zones 5, 6, 6b, 6c. The solar window is on your left in this view.

The same two parts from the 3D model, straight on from the inside, with every zone numbered. In these four pictures the calculator's top end is on the right (turn your phone sideways). Before: red = what comes off. After: green outline = where it was. The 10 mm bar in the corner is to scale.

Back cover inside, straight on, top end on the right: zone 1 solar box, zone 2 rib B (14 mm), zone 3 camera window and zone 5b lip marked in red.

Back cover, before: 1 solar box, 2 the 14 mm of rib B, 3 the camera window, 5b the lip (only if yours has one).

Back cover inside after all zones: the solar box gone, a 14 mm gap in rib B with the 7 mm hole, the lip notched.

Back cover, after: flat floor where the solar box was, the gap in rib B with the hole in its middle.

Front shell inside, straight on, top end on the right: zone 5 magnet U-notch, zone 6 side-wall relief, zone 6b pins and hooks on both walls, zone 6c rib ends; the LR44 cup stays.

Front shell, before: 5 the magnet U-notch, 6 the side-wall relief, 6b pins and hooks on both walls, 6c rib ends (only if needed). The round LR44 cup stays.

Front shell inside after all zones: notch cut in the top wall, rib relieved, pins and hooks snipped.

Front shell, after: notch open in the top wall, rib relieved, pins and hooks gone, everything else untouched.
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

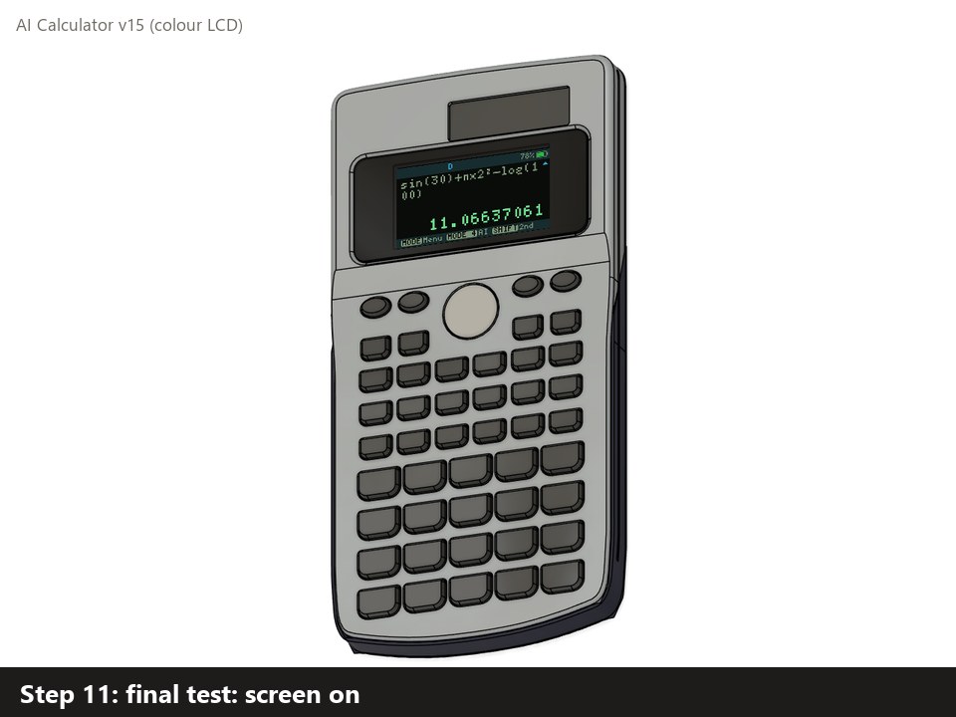
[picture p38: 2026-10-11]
hardware/project_hub/img/anim_assembly_v15_poster.jpg

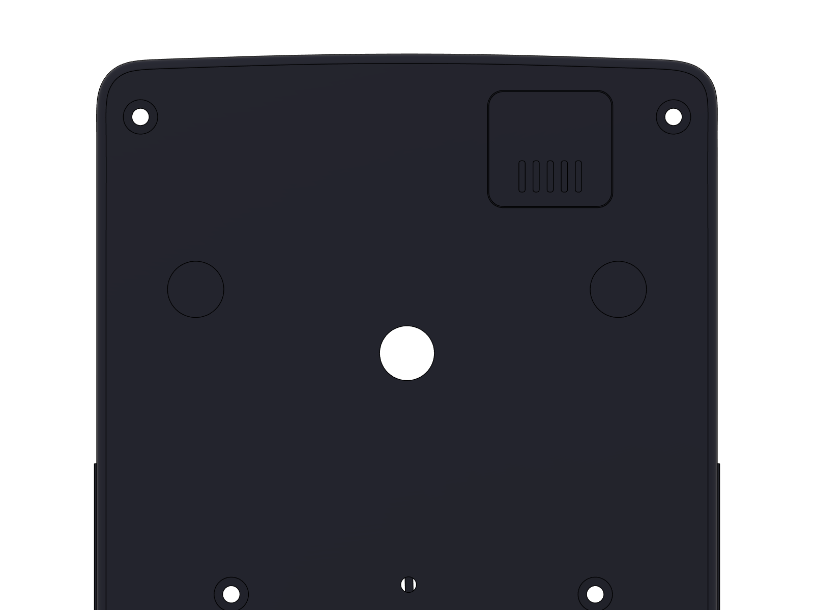
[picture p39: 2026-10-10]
hardware/enclosure/final_assembly/renders/grind/camera_hole_position.png

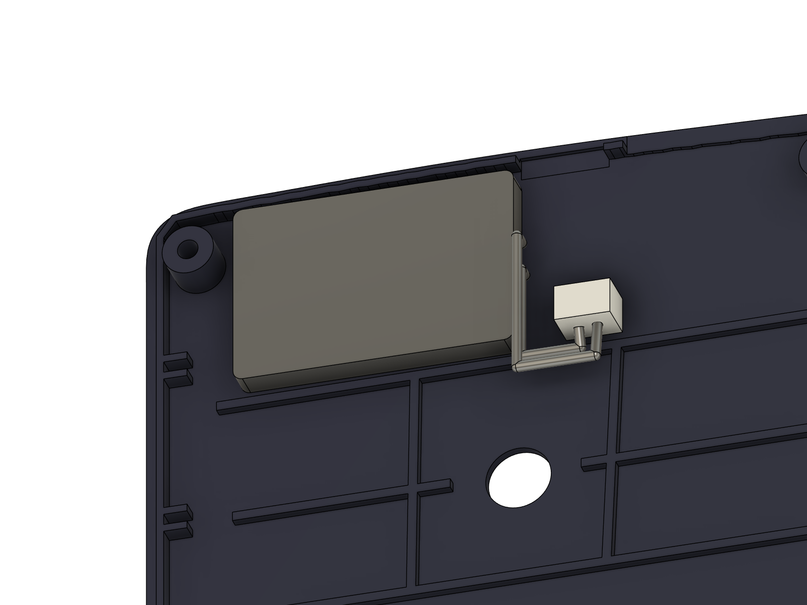
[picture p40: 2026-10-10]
hardware/enclosure/final_assembly/renders/detail/d22_battery_tw302030.png

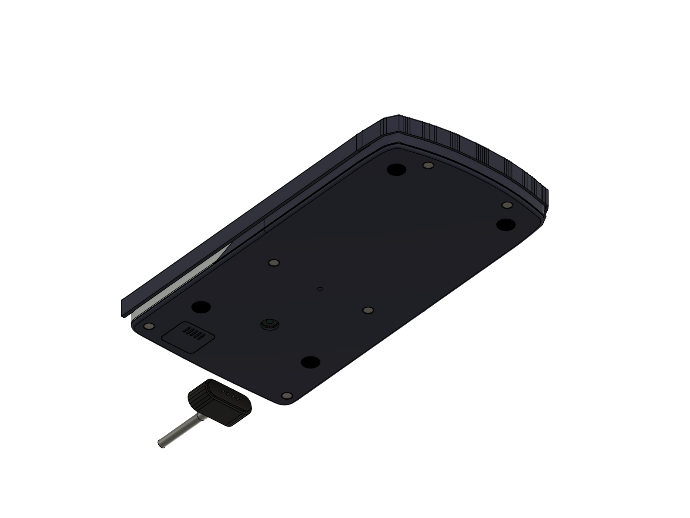
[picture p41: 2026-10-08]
hardware/enclosure/final_assembly/renders/case_stored_back.png

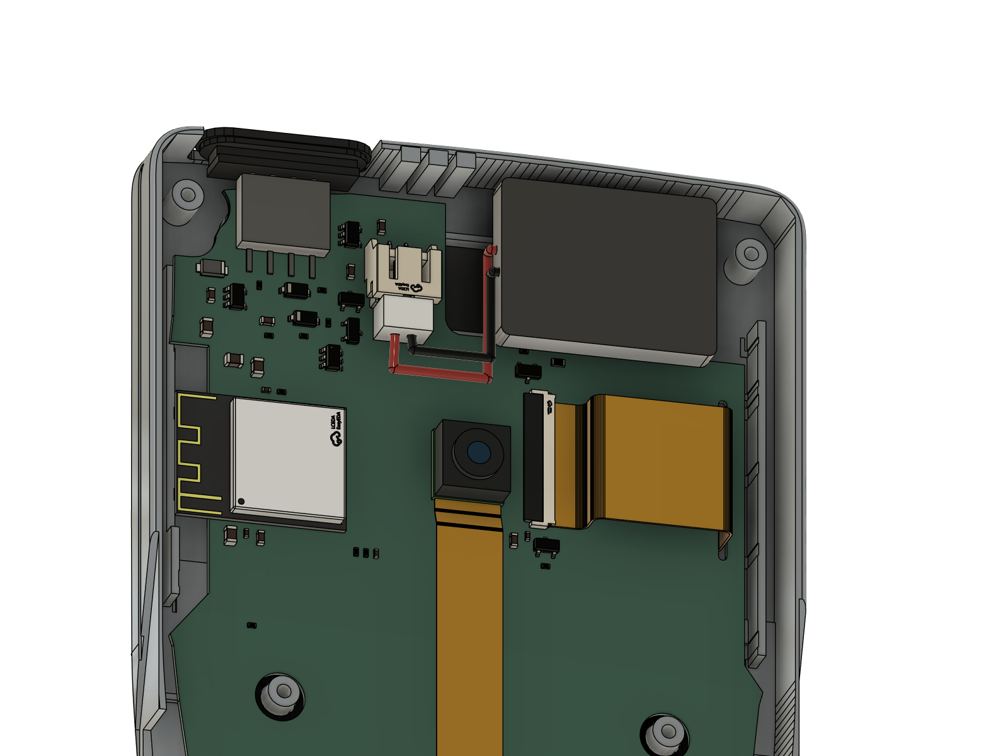
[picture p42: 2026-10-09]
hardware/enclosure/final_assembly_v15_lcd/renders/steps/s09_battery.png

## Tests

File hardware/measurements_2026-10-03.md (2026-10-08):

# Nirav's caliper readings, fx-115ES shell (2026-10-03, second batch)

> **Status (stage 14):** these raw readings are all used. C4/C8/C9/C14/C15 and D1–D13 were answered in stages 12–13. Still open: E6 (camera ribbon beep test), E7 (e-paper ribbon / stiffener length) and the camera ribbon length; see `FINAL_STATUS.md` §6. The "still to do" line at the end is history.

These are verbatim except that typos are fixed. The interpretation notes in *italics* are Claude's first read. Workers must check them against the photos in `C:\Users\r_kas\.claude\uploads\` (all subfolders; newer uploads may appear) before relying on them.

## Case, with calipers
| ID | Item | Reading | Notes |
|---|---|---|---|
| C1 | Front shell outer length | 159.9 | |
| C2 | Front shell outer width, screen section | 79.3 | |
| C3 | Back cover outer length × width | 161 × 79.3 | |
| C4 | Wall thickness, screen section (L/R) | 5.5 / 5.5 including a small plastic part that holds the wires; 4.7 without it | Nirav will upload a picture. *If the walls are really 4.7 thick, the inside width there is 79.3 − 9.4 = 69.9, against a board width of 72.3. Check with photos and C14.* |
| C5 | Wall thickness, keypad section | 0.8 | |
| C6 | Casio board width × length | 65.05 × 97.9 | |
| C7 | Post diameters | 3.85 for all screw posts; 2.9 for all non-screw (locating) posts | |
| C8 | Post-pair spacing, top to bottom | "Start at the hole below the screw hole: **46.5** / the 2nd row only has one peg, on the right side but parallel to the last one / **42.3** / the 5th row only has one, on the left side / 4th, 5th and 6th rows all parallel" | *46.5 matches the photo pair-1 spacing (46.4) and 42.3 matches pair 2 (42.3). So the stage-10 photo holes are confirmed. The earlier "61.8" reading is superseded.* |
| C9 | Top-corner screw posts, centre to centre | **68.1**. "The top holes are in the corners, nowhere near the board." | *The board probably doesn't need corner cut-outs for these. Check the board outline against the posts plus clearance.* |
| C10 | Bottom screw posts, centre to centre | about 39–40 | Matches the board notches (38.94) |
| C11 | Top-left corner post: centre to inside of left wall / top wall | 4.2 / 6.1 | |
| C12 | Window opening | 60.65 × 24.3 | |
| C13 | Window top edge to case top edge | 24.0 | |
| C14 | Side-wall stubs beside the screen: how far they stick in / how high | **5.45 / 5** | *How this relates to C4 is unclear. They may be the "wire holder" bits.* **Answered 2026-10-03 (photo 871567b6):** the stubs/clips stop above the board plane, so they never touch the board. The stage-12 narrowing is kept (harmless, and the ESP32 antenna overhang is good). |
| C15 | How far down each post row is | "From the outside of the calculator to the outside of the holes": **8.9 / 69.95 / 89.6 / 120.45 / 130.2 / 142.4 / 154.6**. "There are 8 rows of holes in total, but row 4 only has a hole on the right side of the PCB and row 6 only on the left. Look at the uploaded picture to cross-reference." | *7 numbers for 8 rows, so one row is missing (probably the row 2/3 pair at about 80 mm). "Outside of holes" may mean the hole's far edge, so centre = reading − r. First mapping, with the case top edge at KiCad y ≈ 56.9: 8.9 = top corners; 69.95 = H1/H3 (photo y ≈ 126.2 → 69.3); 89.6 = H4 (146.5 → 89.6); 120.45 = H2/H9 (175.6 → 118.7); 130.2 = H6 (187.2 → 130.3); 142.4 = H13/H14 (198.1 → 141.2); 154.6 = bottom posts (210.1 → 153.2). Residuals are −0.1 to +1.75, so work out the right edge convention and top reference.* |

## Depths and heights
| ID | Item | Reading | Notes |
|---|---|---|---|
| D1 | Board height above the front floor | 5.5 | **Clarified 2026-10-03:** measured from the front shell's rim (the parting line where the back cover meets it) down to the board, i.e. the board's F side (component side) is 5.5 below the parting line. |
| D2 | Battery bay depth (old coin-cell corner) | not measured. "You do the math with the rest." | |
| D3 | Space above the board line at the top edge | about 5 | Needs 3.5, or 6 without the notch |
| D4 | Space behind the board at the camera spot | ~~5.5~~ **about 6.0** | **Corrected 2026-10-03:** measured from the board to the back cover's INSIDE face, "closer to 6.0". Stack: back cover ~1.0 + 6.0 + board 0.8 + ~4.0 front side = 11.8 (D10). Design limit = 6.0 − 0.3 clearance = **5.7**, minus any rib under it. Camera (5.4) and J4 (5.5) fit where no rib is above them (stage 13). |
| D5 | Back cover thickness at the camera spot | about 1 (edges are rounded) | |
| D6 | Solar box height on the back cover | frame 5–6. "I can grind it with a Dremel." | |
| D7 | Coin-cell holder rib height | 5–6 | |
| D8 | LCD module thickness | 3.75 (glass and metal shield, about half each) | |
| D9 | Key mat: top of the button rubber to the black contact | 1.5 | |
| D10 | Closed calculator thickness | 11.3; the top part is a little more, 11.7–11.8 | **Not 13.8.** The CAD replica must use these. |
| D12 | Back-cover centre rib start/stop | unknown. "You figure it out." | Use photo 2f54d6c7 |
| D13 | Back-cover rib and ring heights | 1 / 4 / 4 / 1. The solar panel grid is 5 high; "will probably have to grind it". | Order of the D13 sheet: rib grid / small ring / big ring / lower ribs (see stage10_fx115es.md) |

## Parts already in hand
| ID | Item | Reading |
|---|---|---|
| P3 | E-paper outline × thickness | 59.0 × 29.2 × unknown (Waveshare drawing: about 1.0) |
| P5 | Magnetic connector | not here yet |

## Photos
- F6 flatbed scan: none. Nirav asked whether Purdue has a scanner. *Purdue libraries have free flatbed scanners. Also, any phone scan app on a flat surface with a ruler in frame works.*

## Decisions
| ID | Question | Answer |
|---|---|---|
| Q1 | Magnetic cable: solder a USB cable or buy ready-made? | "Whichever is cheaper and easier." → **buy the ready-made Adafruit #5412** |
| Q2 | 3.3 V regulator | "Whichever is cheaper and easier." Stage 11 already switched to RT9080 (about 4–6 months standby vs about 6 weeks). Check whether it's a JLCPCB extended part (+$3 per order) vs AP2112K. |
| Q3 | JST-PH 2.0 mm battery plug | **Yes** |

Still to do (must): D11, E1, E6, E7, F1, F3, F4.

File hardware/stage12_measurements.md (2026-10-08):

# Stage 12: second caliper batch, new photos, CAD fit check (ai_calc_pcb_12)

> **⚠ History (stage 12).** "Still don't order" below is resolved: the J4/J3 height problems were solved in stage 13/13b, and the battery now lies on the back-cover floor (the LR44 cup is not ground). The camera window is **7 mm** (stage 13), not the 6 mm below; the battery is the #1317 150 mAh. Current status: `FINAL_STATUS.md`.

**Result:** `kicad-cli pcb drc --refill-zones --schematic-parity` = **0 errors, 0 warnings, 0 unconnected, 0 parity issues**. ERC = 0. Report: `kicad/ai_calc_drc_violations.json`.

**Still don't order.** Two height problems at the top of the board (J4 battery socket and the J3 magnet socket) can't be settled from the readings we have. See "Clearance problems" and QUESTIONS_AND_ISSUES.md → "PCB (stage 12)".

Inputs: `measurements_2026-10-03.md` (C1–C15, D1–D13, P3), four new photos (2026-10-03 19:22: `2a97120d` front shell with mat, straight on; `fd923128` Casio board; `e59eff71` front with calipers; `fb0c138c` Waveshare HAT), the 23 older photos, the CAD replica fit check (`enclosure/replica/fitcheck_report.md`), and the Waveshare 2.13" V4 spec (mechanical drawing, page 6).

## 1. What changed on the board, and why

| # | Change | Why (plain English) |
|---|---|---|
| 1 | **Left edge of the screen section pulled in to x = 118.9** (from 113.84–114.6) between y 82.9 and 114.0, then a slant back to the old edge at y 119.6. | The "4.7 mm wall" (C4) is an outer skin + a wire channel + a thin inner rib, with 3 pins (C14) and 2 wire hooks sticking in. From the straight photo (key-fitted, RMS 0.37 mm) the pins reach x ≈ 116.8–117.4 and the top hook x ≈ 118.2. The board now stops 0.6–2.1 mm clear of them. |
| 2 | **Right edge pulled in to x = 183.65** (from 185.4–186.16) between y 78.3 and 116, then a slant to the old edge at y 119.2. | Same wall on the right: pins at x ≈ 184.0–184.2 (C14 5.45 from the outside puts them at 184.2), hook at 182.5 / 184.75. The board now stops 0.35–0.55 mm short of the pins. The bottom-right hook (184.75, 114.3) is outside the board. The top-right hook (182.5, 84.5) is 1.2 mm inside the board edge: it sits next to the e-paper socket J2 area with no parts there, but it touches the board face. **Snip that one hook (and the top-left one if it touches) with side cutters**; they only held Casio's wires. |
| 3 | J2's lower fan-out tracks (EPD_PREVGH/VSH/VPP/VDD) squeezed from 0.5 mm to 0.4 mm pitch. | That freed 0.5 mm so the right edge could move in. Same connections, clearances still ≥ 0.2 mm. |
| 4 | **ESP32 (U1) antenna now overhangs a board cut-out.** The board ends at x = 118.9; the module's antenna part runs from 114.75 to 119.85, so ~4 mm of the antenna hangs past the board edge. | This is Espressif's preferred antenna placement (antenna off the board edge, no copper under it). The module is still held by all its pads (the first pad column is at x 120.55). The old "antenna edge strip" rule area was removed (no board there now); the top/bottom antenna keep-outs were trimmed to the new edge. The U1 silkscreen box was cut at the edge (library footprint updated to match). |
| 5 | **H1 (left screw post, row 1/2) moved 0.86 mm: (128.36, 126.74) → (127.5, 126.1).** | C8 says this pair is 46.5 apart centre to centre; the board had 45.64. Now H1–H3 = 46.50. Both photos put the post at x 127.5–127.6. The old hole left only ~0.2 mm of play. KEYPAD_INT, I2C_SCL and a GND track were re-routed around it, and the SCL via moved 0.2 mm; two GND stitching vias under the new hole were removed. |
| 6 | **H8 → (128.85, 137.0), H10 → (171.25, 136.8)** (moved 0.24 / 0.28 mm inward). | C8 says this pair is 42.3 apart; the board had 42.85. Now 42.40. They couldn't go further without cutting COL1/COL4 (hole-to-copper must stay ≥ 0.25 mm). With 4.2 mm holes and 2.9 mm posts that still leaves ≥ 0.6 mm of play. |
| 7 | The other locating holes (H2, H4, H6, H9, H13, H14) and H3 **not moved**. | The new straight photo agrees with the stage-10 photo positions to 0.2–0.5 mm, with mixed signs (scatter, not a shift). C15 (see §3) disagrees with the photos by up to ±1 mm, but with opposite signs on neighbouring rows, which points at reading error, not at the holes. I tried widening H9/H6 into slots, but key-pad copper is too close (0.3 mm edge rule). |
| 8 | **Top corners kept as they are.** | C9 (68.1 apart) and C11 put the corner screw posts at ≈ (115.9 / 184.0, 65), which is outside the board in the right corner (board's top edge there is at y 78.3, battery cut-out) and ≥ 1.5 mm clear of the top-left cut-out. "Nowhere near the board" is right. Filling the top-left cut-out back in wouldn't add useful space (the LR44 cup and solar box are there), so I left it. |
| 9 | **E-paper panel drawing 59.2 → 59.0 mm** (P3), and the active area redrawn from the Waveshare V4 drawing. | See §4. No copper change needed. |
| 10 | **3D models attached for U1 (ESP32-S3-MINI-1) and U6 (TCA8418)**, both stored in the project (`ai_calc.3dshapes/`). | The CAD fit check had to use guessed boxes. U1's model came from LCSC/EasyEDA and was offset so its body lines up with the pads (checked: body 114.75–135.25 × 89.3–104.7, 2.4 mm tall). |
| 11 | **3 fiducials** FID1 (121.5, 203.5), FID2 (178.5, 203.5), FID3 (177.0, 112.5): 1 mm copper, 2 mm mask opening, F side. | JLCPCB adds its own tooling, but fiducials help the pick-and-place camera with the 0.5 mm-pitch parts (ESP32, TCA8418, FPC sockets). Free. They are not in the BOM or CPL. |
| 12 | Silkscreen: "AI CALC v12 2026-10-03" (moved off H10), test-point names (BOOT, GND, 3V3, BAT, EN, TX, RX), and "+"/"−" beside the battery socket J4. | For first power-up with a meter. No silk on any key pad or exposed pad (DRC checks this). |
| 13 | `tools/make_fitcheck.py` rewritten: part heights now come from the 3D models; new `fitcheck/clearance_table.md`; grind maps mark the features to grind in red. `fitcheck/backcover_fx115es.json` gained the solar box, a heights table and the free-height cases. | Task 3. |

Things deliberately left alone: J1 CamReversed footprint, the stage-6 camera GPIO map, no LED, magnet contacts never on battery voltage, R20 → VBUS_SENSE, C32, TP5–TP7, 2-layer 0.8 mm ENIG.

## 2. The screen-section width (was blocking)

Side view across the screen section (left wall, looking from the top of the calculator; not to scale):

```
 outside                                          inside
 |<-1.2->|<--- ~2.5 wire channel --->|<1.0>|
 +-------+                           +-----+                 back cover (D5 ~1)
 |       |                           |     |    =========================== <- inside of back cover
 | outer |                           |inner|      free ~4.0-4.6 (see 3)
 | skin  |                           | rib |  ...........................
 |       |                           |     |  ######## board 0.8 ########  <- board F side faces up here
 |       |      pins (C14) stick in  |     o====> 5.45 from outside, top 5.0 above floor
 |       |      5.45 from the outside|     |  ~~~~~~~~ key mat ~~~~~~~~~~
 |       |                           |     |      board top face 5.5 above the front floor (D1)
 +-------+---------------------------+-----+==============================  front floor (window side)
 x=111.5         (KiCad x)              114.3-114.8     pins reach 116.8-117.4 (L) / 184.0-184.2 (R)
```

- The pins are 5.0 above the floor and the board occupies 4.7–5.5 above the floor, so the pins sit right at board level: the board edge must not reach them. The inner rib runs from the floor up to the parting line, so it also blocks the board.
- Free width at board height, screen section, by y (KiCad x): pins and hooks on the left at 116.8–118.3, on the right at 182.5–184.2. The board is now **x 118.9 → 183.65 (64.75 wide)** there. Clearance: left ≥ 0.6 mm to the hook, ≥ 1.5 mm to the pins; right 0.35–0.55 mm to the pins, and the one top-right hook needs snipping.
- Below y ≈ 116 (keypad section) the walls are 0.8 mm (C5) and the board is unchanged (C6: our keypad section is narrower than Casio's board).

## 3. Heights: what's behind the board (F side faces the back cover)

**Stack-up.** D10 says the closed calculator is 11.3 (keypad) / 11.75 (top part). The front face is about 1.5 thick at the window, the board's top face is 5.5 above the front floor (D1), the board is 0.8, the back cover about 1.0 (D5):

D1 is measured from the front floor to the board's **top face**, which is its F side (the board lies key side down). So the free height above the F side is about 11.75 − 1.5 (face) − 5.5 (D1) − 1.0 (back cover) = **≈ 3.75–4.25**. D4 cross-check: the LCD module (3.75, D8) sits on the floor, so its back is 1.75 below the board line, and D4's 5.5 would then leave ≈ 3.75 above the board. The CAD replica (which reads D1/D4 to the outside faces) gets 4.59. D4 read literally says 5.5. I used **4.5 as the design value, 4.0 pessimistic and 5.5 optimistic**, and checked all three.

```
 back cover outside  ----------------------------------------  Z 0
 back cover floor 1.0
 ribs 1 / rings 4 / solar box 5-5.5 (D13, D6) hang down from here
 free height above board F side: 4.0 .. 4.6 .. 5.5   <-- the open question
 board F side (parts point up, towards the back cover)
 board 0.8
 key mat + keys, 5.5 down to the front floor (D1)
 front face ~1.5
 front outside ----------------------------------------------  Z 11.3 / 11.75
```

The full table for all 82 F-side parts is `fitcheck/clearance_table.md`. Summary:

| Part (height from 3D model) | Over it | Margin at 4.5 | After grinding | What I did |
|---|---|---|---|---|
| **J4** battery socket S2B-PH-SM4-TB, **5.50** | solar box (5–5.5) | −6.5 | **−1.0** (−0.0 at 5.5) | **Not solved. Blocks order.** No JST-PH SMD socket on JLCPCB is lower than 5.45. Options in Q12-1. A 3.6 mm MX1.25 socket (C7430468, in stock) is ready in the library (`ai_calc:MX1.25_2P_SMD_RA_H3.6_C7430468`) but needs a battery with a 1.25 mm plug. |
| **J3** magnet socket, **5.00** + magnet legs | solar box | −6.0 | **−0.5** | **Not solved. Blocks order.** The magnet connector isn't in hand (P5); its legs plug into J3 from above, so the magnet body sits even higher. Needs P5 + D3/D11 measured on the real part. |
| U2, U3, D1, Q2, D7, C5, C6… (≤ 1.6) | solar box | −1.5 to −2.6 | **+2.9 or more** | Grind the solar box flat (D6: "I can grind it"). Marked red on the grind map. |
| **D2** (1.26), **C16** (0.55) | big ring wall (4) | −0.76 / +0.0 | **+1.2** | Grind the arc of the big ring next to D2/C16 down to 2 mm (marked). Moving D2 would need re-routing the camera bus; not worth it. |
| U1 ESP32 2.41 | upper rib B (1) | +1.09 | — | OK (+0.59 even at 4.0). |
| L1 2.0, J1 2.0, J2 2.0 | 1 mm ribs | +1.5 | — | OK. |
| C20 1.59, all other passives | ribs or nothing | ≥ +1.9 | — | OK. |
| **Camera module** 8.5 × 8.5 × 5.4 (not soldered) | rib B through the camera spot | 5.4 vs 4.5 | — | The lens has to poke into the 6 mm back-cover hole (cover 1.0 thick): body (without lens) must be ≤ ~4 mm and the barrel ≤ 6 mm across. Rib B must be ground where it crosses the camera. Check the split on the real module (F3). |
| LiPo 3.8 (in the bay, under board level) | LR44 cup (5–6) | — | — | The LR44 cup ribs in the front shell must be cut out (D7, grindable), as planned since stage 3. |

## 4. E-paper (P3: 59.0 × 29.2)

- Waveshare V4 drawing: outline 59.2 ± 0.2 × 29.2 ± 0.2 × 1.0, active area 48.55 × 23.70. Your 59.0 is within tolerance. I redrew the panel 59.0 long, keeping the FPC end (right end, x 179.47) fixed, so the ribbon/slot/J2 geometry is unchanged.
- **Active area is not centred on the glass**: 2.70 mm from the non-FPC end, ~7.95 mm from the FPC end, 2.75 mm top and bottom. Earlier stages assumed it was centred. On our board the picture is therefore centred at x ≈ 147.4, **2.6 mm left of the window centre** (in the view from the front it's toward the FPC side, i.e. the right-hand side of the window as you look at the calculator — mirror if unsure). It's fully inside the window (3.5 mm margin one side, 8.6 the other). It's cosmetic; firmware can shift the drawing area, or the e-paper block could move 2.6 mm in a later revision.
- Vertical: active area centre y 92.99 vs window 93.10 (0.1 mm). The new straight photos put the window centre at 92.75–93.36 and its left-right centre at 150.0 ± 0.3, so Q4 from stage 11 (window centred) is confirmed.
- FPC slot budget unchanged: ribbon 14.30 ± 0.3 by the drawing, path needs 13.5–15. **E7 still not measured** (Nirav can measure it on the panel in the HAT, photo `fb0c138c`).

## 5. C15 and residuals (hole positions)

C15 was read "from the outside of the calculator to the outside of the holes". I fitted the three possible conventions (to the hole centre, its far edge, its near edge) against the photo-derived hole rows, solving for the top reference each time:

| Convention | Top edge at KiCad y | Residuals corner / H1-H3 / H4 / H2-H9 / H6 / H13-H14 / bottom (mm) | RMS |
|---|---|---|---|
| centre | 55.97 | −0.13 / −0.18 / −0.39 / +0.82 / −1.03 / +0.32 / +0.47 | 0.61 |
| far edge | 57.58 | −0.45 / −0.50 / −0.23 / +0.98 / −0.87 / +0.48 / +0.15 | 0.62 |
| near edge | 54.36 | +0.19 / +0.14 / −0.55 / +0.66 / −1.19 / +0.16 / +0.78 | 0.68 |

The conventions can't be told apart (0.6 mm RMS each). The two big residuals (H2/H9 +0.9, H6 −1.0) have opposite signs only 11 mm apart, while three independent photo fits agree with each other to ≤ 0.5 mm, so I trust the photos there. The CAD replica used the far-edge reading and reports H2 rubbing by 0.54; with the photo positions every locating hole has ≥ 0.4 mm of play.

Final hole residuals vs the new straight photo `2a97120d` (board − photo, x / y, mm): H1 +0.01/+0.05, H3 +1.0 (post tip) / +1.4 (mat hole) in x, H8 +0.02/−0.40, H10 +0.05/−0.21, H4 −0.14/−0.64, H2 +0.30/−0.40, H9 +0.22/−0.29, H6 +0.19/−0.53, H13 +0.11/−0.27, H14 +0.10/−0.56. The y values share a −0.4 offset (the photo's fit is shifted, not the holes). H3 was confirmed at 174.0 by the stage-10 mat photo, C8 (46.5 from H1) and the shell photo; the new photo's top row fit is worse (0.7 mm residuals on the 4 top keys), so I kept H3. Its 6 mm hole gives 1.07 mm of play for the 3.85 post, which covers the new photo's tip reading but not its mat-hole reading: dry-fit check Q12-5.

## 6. CAD fit-check collisions (fitcheck_report.md, STEP of 18:10) and what was done

| # (report) | Collision | Done |
|---|---|---|
| 1, 10, 22–28 | J4 into back floor / solar box | Open, blocks order (Q12-1). Solar box marked GRIND. |
| 2 | LiPo vs solar box grid | Battery sits in the bay below board level; grind the solar box flat (it's over the bay too). |
| 3, 7, 29 | J3 vs solar box / floor | Open, blocks order (Q12-2). |
| 4 | Camera vs rib B and floor | Grind rib B over the camera; lens into the 6 mm hole; body/lens split to confirm (Q12-3). |
| 5, 6, 8, 9, 19 | D1, Q2, D7, U3, C6 vs solar box | Grind the solar box flat: then ≥ 2.9 mm margin. |
| 11 | Board vs post H13 | The CAD uses C15 rows; photos put H13 within 0.3 mm. Not moved (§5). |
| 12, 16, 15 | Board vs H6, H2, H9 | Same; ≥ 0.4 mm play against the photo posts. H2/H9/H6 rows flagged for a quick dry fit (Q12-5). |
| 13 | Board vs mid-R screw post (H1) | **Fixed**: H1 moved to 46.5 spacing. |
| 14, 17 | Board vs screen-section inner ribs | **Fixed**: edges at 118.9 / 183.65. |
| 18 | Board vs solar box (board face) | Grind the solar box flat. |
| 20, 21 | LiPo vs LR44 cup | Cut the LR44 cup out of the front shell (D7, already in the plan). |
| 2D | stubs / wire holders −0.23 to −0.73 | **Fixed** by the new edges, except the top-right hook at (182.5, 84.5): snip it. |
| — | U1/U6 had no 3D model | **Fixed**: models attached. New STEP: `fab/ai_calc_board.step` (2026-10-03 23:02). |

## 7. Parts and cost (checked live on JLCPCB's parts API, 2026-10-03)

- **Regulator:** RT9080-33GJ5 **C841192 is an Extended part, 39,625 in stock, $0.120**. AP2112K-3.3 **C51118 is also Extended, 38,405 in stock, $0.171**. Same $3 loading fee either way, the RT9080 is cheaper and gives 4–6 months standby instead of ~6 weeks. **Kept RT9080.**
- All 31 LCSC numbers are in stock. Lowest: ESP32-S3-MINI-1-N4R2 1,893, L1 5,250, TCA8418 28k; all far above the 2–5 needed.
- 14 Extended part types (ESP32, TCA8418, MCP73831, RT9080, 2 × ME6211, USBLC6, SI1308, SMF5.0A, L1, R12 3 Ω, FPC socket, J3, J4) ≈ $42 in loading fees. I searched for Basic substitutes with the same footprint: none for the ICs/FET/TVS/inductor. The only candidate is **R12 3 Ω → 2.2 Ω C22939 (Basic)**, saving $3, but R12 sets the e-paper booster's current limit and Waveshare's reference uses 3 Ω (sheet item E5 not measured), so I didn't change it.
- Not changed: fixed main ICs and connectors.

## 8. Robustness checks

- **Polarity / pin 1:** every D/U/Q/J part has a pin-1 or cathode mark in its footprint silk (checked by script). J4 now has "+"/"−". D7: cathode bar on the VBUS pad (stage 11 check still holds).
- **Fiducials:** 3 added (change 11).
- **Version silk:** "AI CALC v12 2026-10-03", F side, on bare board between H1 and H3 rows, no pads under it.
- **Test points:** TP1 BOOT, TP2 TX, TP3 RX, TP4 GND, TP5 3V3, TP6 BAT, TP7 EN, all F side, all labelled, all in the screen section (reach them with the back cover off; nothing tall within 2 mm of any of them except TP6 beside J4's corner).
- **Net widths** (2-layer, 1 oz, 10 °C rise, IPC-2221 outer): BAT+, VBAT_P, SYS, VBUS = 0.5 mm (≈ 1.2 A) for ≤ 0.5 A peaks (Wi-Fi TX + charging); +3V3 trunk 0.5 mm, branches 0.25 mm (≈ 0.75 A) feeding single ICs; camera rails 0.25 mm for ≤ 0.15 A; GND is two pours. OK.
- **USB pair:** D+ 48.1 / D− 45.9 mm, 0.2 mm tracks, through the USBLC6. A 2.2 mm mismatch is irrelevant at 12 Mbit/s.
- **Thermal/DFM:** no starved thermals, smallest track 0.2 / gap 0.15 / via 0.6/0.3 (JLCPCB minimums 0.1 / 0.1 / 0.45/0.2). The LDOs dissipate < 0.2 W. GND islands: every pour island ≥ 1 mm² has ≥ 2 vias (`tools/gnd_islands.py`, 0 added).

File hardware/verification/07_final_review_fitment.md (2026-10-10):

# 07: Final fitment review, v14 board in the ground fx-115ES shell (2026-10-06)

> **2026-10-06 (later): superseded on S1 / zone 6 / checklist items 1, 8, 9 by [`12_rib_pin_recheck.md`](12_rib_pin_recheck.md).** Nirav's depth rod put the inner rib's top edge 4.5–5.0 mm below the rim, the round pins at 5.1–6.1 and the U hooks at 5.5 (both walls): the rib, every pin and every hook sit at board height. Zone 6 is now mandatory (notch to 7 mm below the rim), zone 6b snips all pins and hooks on both walls, zone 6c (rib ends) is conditional. Verdict there: order the board as-is.

> **Correction 2026-10-10 (top-edge datums only; findings and verdict unchanged).** The "mm from the top" figures below were taken from the top of the whole outline (model Y 82.1) or from the middle of the top end. The guides now measure each part from its **own** top outer edge. Front shell, zone 6: measured along the solar-window wall from the rim's top outer edge right above the side rib (about 1 mm lower than the middle of the top end), so zone 6 relief 15–50 → **14–49 mm**, board corner strip 15–26/27 → **14–25/26**, antenna tab 31–50 / 32–48 → **30–49 / 31–47** (relief / tab itself). Back cover: zone 1 outer frame **6.3–19.3 mm** down from the back cover's own top outer edge, straight down at the middle of the box (older notes: 7.2–19.2 from the outline top); camera hole **38.0 mm** from the back cover's own top outer edge on the centre line (38.3 was to the outline top, where the silver front shell stands about 0.3 mm proud). KiCad coordinates are unchanged. Source: `enclosure/final_assembly/grinding_manual.html` (zones 1, 3, 6).

**Verdict: GO for the shell work, with one new conditional grind (zone 6, antenna relief) and a 10-minute pre-grind checklist that must be done on the real shell before the first cut. Nothing found needs a board change; `hardware/kicad/*` is untouched.**

Scope: every guessed shell dimension, outline vs faceplate, heights on both sides, e-paper window/mask/FPC, camera, magnet, the grinding manual + jigs, the assembly guide, the fit-check files, and a from-scratch Fusion check of the whole closed assembly (every board part and every loose part against every shell feature). Inputs: `FINAL_STATUS.md`, `measurements_2026-10-03.md` (C1–C15, D1–D13), `stage12_measurements.md`, `stage13_heights.md`, `stage14_verification_fixes.md` §6, `enclosure/final_assembly/*` (report §7–9, PROGRESS, battery_upgrade, window_mask, slide_case_mods, renders, both scripts, both guides), `enclosure/jigs/README.md`, `enclosure/replica/photo_notes.md` + `fitcheck_report.md`, `fitcheck/*`, verification 06 (M1) and 10, the KiCad board parsed by script (Edge.Cuts, holes, U1/J1–J4 pads, rule areas), all 29 of Nirav's photos (both upload folders, every file opened and compared with `renders/compare/*` and the grinding-manual pictures), and the live Fusion model (`ai_calculator_final_assembly.f3d`, rebuilt as rev F).

Frames: KiCad x/y as in the board file (component side up). Front view X = 150 − x, Y = 138.94 − y, Z from the outside of the back cover (board component face Z 7.0, key face 7.8, faceplate rim Z 1.5, plate underside Z 10.5 in the screen section). "Depth below the rim" = Z − 1.5. On the real calculator, **KiCad low x = the right-hand side as you use it** (solar-window side); the paper map lies in the shell mirror-image to the front view.

---

## 1. Findings

### FATAL
None.

### SERIOUS

**S1. On the solar-window side the board's own top corner (up to 0.85 mm) and the ESP32 antenna tab (0.4 mm) run into the faceplate's inner side-wall rib if that rib reaches the board plane, and the model had never looked.**
- Evidence: U1 body from the STEP spans KiCad x 114.74–135.26, y 89.29–104.71; the part past the board edge (x < 118.9) is the module's bare antenna PCB, **0.8 mm thick** (Z 6.1–6.9 in the model, i.e. flat on the board's component face), not the 2.4 mm shield (verification 06 M1 assumed the full module height; the tab is 0.8). The traced shell outline is 79.0–79.1 wide at y 89–105; C4 says the screen-section wall is 4.7 (5.5 at the wire holders), so the inner face of the thin inner rib is at x ≈ 115.1–115.2. Module tip 114.75 → **0.35–0.45 mm overlap over 15.4 mm, 0.8 mm tall**. In the replica (rev C–E) the inner rib was modelled only from Z 8.0 up to the plate ("the stubs stop above the board plane"), so the component-side depth was empty wall and every check passed. But C4 was read with the calipers **on the rim**, and photo 871567b6 (Casio board in the shell) shows that rib's top edge level with the board's back face, so the rib is there at board depth.
- The same rib also catches the **board's top corner strip**: Edge.Cuts keeps the full width there (x 114.28 at y 82.9 → 114.77 at y 72.0; stage 12 narrowed the board to x 118.9 only from y 82.9 down, below the LCD), and the rib (inner face x ≈ 115.15, modelled Y 24–66 = KiCad y 72.9–114.9 because the two wire hooks hang from it at y 75.4 / 80.8) is up to **0.85 mm inside that strip over 10 mm** (rev F before-grind check: 3.1 mm³, Z 7.0–7.71). This one is a rigid board edge, not a 0.8 mm tab, so it is the more certain of the two.
- Failure mode: the board sits 0.4–0.85 mm proud at that corner, cocked; J4 (0.41 mm to the floor) and the camera lens (0.71) lose their margin, the rim gaps. Nothing electrical.
- Fix applied: (a) replica rev F: `INNER_RIB_FULL = True` (inner ribs from the rim to the plate, pins/hooks unchanged); (b) new **grind zone 6 "side-wall relief"** in `build_final_assembly.py` (`ANT_RELIEF_K` = KiCad y 71.5–106.5 = 15–50 mm from the top outer edge: the 1 mm rib removed from the rim down to the stub level 6.5 mm below the rim, 35 mm long, pins and hooks kept; after it the tab has 0.9–1.1 mm and the board corner ≥ 0.6 mm in the model), in the grinding manual (new article, pictures `grind_antenna_relief_before/after.png`, `section_antenna.png`), the assembly guide (zone table + step-8 check), both grind maps (dashed red zone 6 + the yellow tab), FINAL_STATUS, HANDOFF, ORDER_WALKTHROUGH/CHECKLIST, jigs README; (c) the paper dry fit now carries the tab printed on the map (the coordinator's `paper_dry_fit_v14.svg` tab, x 114.4–118.9 / y 89.3–104.7, is **correct**: 0.35 mm past the module tip, same y as the body). Zone 6 is conditional: the paper template (with the tab) or the depth rod (checklist item 1) decides it. For v15 the board corner should simply be narrowed to x 118.9 all the way up (noted in HANDOFF).
- Measurement to take: checklist item 1.

**S2. The e-paper panel's top edge sits 0.29 mm from the solar-window frame, and the frame's position and depth are photo guesses (±0.5 mm).**
- Evidence: `clearances.json` "E-paper panel ↔ Front shell 0.29 at front (27.25, 60.55, 8.1)" = KiCad (122.75, 78.39), the panel's corner against the rib between the solar window and the display window; `SOLAR_FRAME = (0.8, 2.5)` and `SOLAR_C` are "photo (stage 10)" / "guess" in `build_fx115es_replica.py`. The panel (59.0 × 29.2, y 78.39–107.59) is 4.9 mm taller than the window opening (C12 24.3) and extends 2.56 mm above the window's top edge (C13 → y 80.95) into that strip.
- Failure mode: if the real strip between the two openings is narrower than about 2.6 mm (inside, at the rib), the frame rib lands on the panel's glass edge when the board is pressed onto the posts: the panel is pushed off its tape or cracked.
- Fix applied: pre-grind checklist item 2 (measure the strip); assembly guide step 8 now says what to do if it touches (slide the panel ≤ 0.5 mm towards the keys before the tape sets: the picture stays inside the window, 3.5 mm margin, and inside the mask's 0.4 mm margins only if ≤ 0.4; the mask template is cut after this check anyway). No CAD change: the model keeps the photo value.

### MINOR

**M1. Verification 06 M1 and FINAL_STATUS §1 described the antenna as "left edge (front view)" and 2.4 mm tall.** It is the KiCad-left edge = the right-hand side in use, and the overhanging part is 0.8 mm. Fixed in FINAL_STATUS §1 (items 3, 6, 9), fitcheck/README, ORDER_WALKTHROUGH, HANDOFF, the map legend. 06 is left as written (history); this file supersedes it.

**M2. E-paper ribbon spare: docs disagreed (0 vs 1.6 mm). Settled.** The Fusion path from the glass edge into J2 is 12.7 mm with 2.0 mm inside J2 (fold hugging the panel end at r 0.25, 7.5 mm back under the panel, 1.9 mm down through the slot, 1.8 + 2.0 mm into J2); the ribbon is 14.3 ± 0.3 → **1.6 mm nominal, ≈ 0.3 mm if the ribbon is short and J2 wants 3 mm of insertion**. Rule kept: build as if there were none; E7 and the stiffener rule (stage 14 §6) stand. Fixed in: assembly guide step 5 ("docs disagree" label removed), FINAL_STATUS §1b, HANDOFF, stage14 §6, assembly_report §3.

**M3. Camera ribbon spare: docs disagreed (12 mm vs 1.4 mm). Settled.** The Fusion path from the module's near edge into J1 is 58.7 mm (tip 2 mm inside J1, lying 1.46 mm under the board on the tallest part in its corridor). Seeed's 70.5 mm is read from the module's **far** edge (stage 14 / verification 03 L1), so only ≈ 62 mm is ribbon: **1.4–3.3 mm spare**, never 12. The "under 70.3 mm → shift the module ≤ 1.7 mm towards J1 and drill where the lens is" rule stands. Fixed in assembly_report §3, final_assembly/README (which said "~11 mm loop"), grinding manual test-fit.

**M4. Zone numbering was inconsistent** (jigs README and battery_upgrade §3 called the magnet notch "zone 4" and the LR44 trim "5a/5b"; the guides use 1–5, 5b). Everything now uses the guide's numbers: 1 solar box, 2 rib B, 3 camera window, 4 LR44 cup (**keep**), 5 magnet notch, 5b lip, 6 antenna relief; the LR44 trim of the battery study is "4a/4b". Fixed in jigs README, battery_upgrade §3, both grind maps (zone labels printed on the map), fitcheck README.

**M5. Fit-check files were stale** (battery block #1570 at the old bay position, "LR44 cup: TRIM FLAT", no antenna tab, no drill mark for zone 3). Regenerated with `tools/make_fitcheck.py` (patched): `dummy_board.stl` now has the loose #1317 block at KiCad x 152.59–178.61, y 60.36–80.11 (z 0–3.8, verified in the STL) and the antenna overhang is in it through U1's 3D model (verified: vertices to x 114.75, 0.8 mm tall); `grind_map_front_shell.svg` has the yellow 4.5 × 15.4 tab, the LR44 cup in green "zone 4 (KEEP)", zone 6 dashed, zone numbers in the legend, and the **50 mm line unchanged** (x 112.162 → 162.162 in the 1:1 viewBox); `grind_map_back_cover.svg` has the 7 mm zone-3 drill circle with cross-hairs; `clearance_table.md` LiPo row now describes the floor position.

**M6. The faceplate's LR44 holder leaves only 0.30 mm over the #1317 (0.20 with the 0.1 mm tape), and the holder's height is D7 "5–6" modelled as 5.5.** If the real holder is 5.8 tall it touches the cell (a pouch is soft, so this is a rattle/pressure issue, not a crush). Checklist item 3 measures it; the fallback (jig C trim, 1.9 mm) already exists.

**M7. The back cover's moulded label (photo e82c982d outside, 2f54d6c7 inside: the faint rectangle 32–48 mm from the top edge, x ≈ 135–170 KiCad) contains the camera window spot and the rib B grind.** Debossed lettering means the floor can be thinner than D5's "about 1.0" there. Checklist item 4 (floor thickness at the label ≥ 0.9 before grinding rib B flat; never below 0.8). The second, grained rectangle lower down (between low ribs 1 and 2, ≈ 95–104 mm from the top, over J1/D2) is a mould texture, not a pad: nothing to do.

**M8. Grinding manual zone 4 still carried the sentence "the printed map says TRIM FLAT, ignore it"** and the test-fit text about the old STL block. Updated. The manual's zone 5b "lip" is still a model guess; the pre-grind checklist item 5 settles it with the cover in hand.

### NOTE

**N1. Camera optics.** Lens top 0.5 mm below the floor's inside face, 7 mm hole in a 1.0 mm floor: the unvignetted half-angle is atan((3.5 − 1.4) / 1.5) ≈ 54° centred, ≈ 36° at 1.0 mm offset, ≈ 22° at 1.5 mm; the OV5640 module's diagonal half-FOV is ≈ 34–39°, so **centre the module within ≈ 0.8 mm of the hole** (added to the assembly guide step 6). Minimum focus of the AF module ≈ 10 cm: the calculator reads a page held 15–30 cm above it, back down; it cannot focus lying flat on the page (added). Light leak: a 0.5 mm ring beside the 6 mm barrel lets light into the case; it lights the board only (e-paper is not light-sensitive) — cosmetic, nothing to do. Tilt: the module's base is the board; a tilt only comes from uneven tape, which the "even ring all round" check catches.

**N2. Magnet connector.** U-notch 21.5 × 7.95 in the top wall, 6.4–27.9 mm from the right edge in use (= KiCad x 116.75–138.25) ✓ consistent in all docs and the jig B window. Face flush (model 0.25 per side, 0.71 to the back cover, 0.71 to the board edge). N end = pin 1 = VBUS (stage 14 order VBUS, D−, D+, GND; meter check mandatory before gluing, both guides) ✓. The top-corner screw post (x ≈ 116, y ≈ 65, Ø3.85) overlaps the notch's x range by 1.2 mm but sits 5 mm behind the wall: it is not cut, only taped (manual says so). Leg straightening 5.3 mm, 4.5 mm into J3, trim 0.5–1 mm if they bottom out ✓. Slide case: open end at the top in both positions, magnet never covered; 8 mm case hole over the 7 mm window (`slide_case_mods.md`) — all case sizes are guesses, not used for testing ✓.

**N3. Posts, screws, snap tabs, hooks.** Locating posts Ø2.9 in Ø4.2 holes/slots: H6 0.10 mm (known; file the hole, never the post), others 0.46–0.91. Screw posts Ø3.85 in the Ø6.0 H1/H3 holes (0.91); the 6 screws run from the back cover into the faceplate's posts, the board carries no screw, so screw length is Casio's own (guide asks to measure it; model assumes 2 × 8). Comb snap tabs: top one at front X +5 (KiCad x 140.5–149.5) is 2.5 mm from the magnet body's end and clear of J3; bottom one at X +3.5 sits inside the navy end wall below the board's bottom edge. Side-wall pins (C14, 3 per side) and the three hooks per side stay above the board plane per Nirav; the board's narrowed screen section (x 118.9–183.65) clears the pins by ≥ 0.35 mm (right) / 1.5 mm (left) even if they were at board height; the e-paper panel (x 120.5–179.5) is well inside them.

**N4. Heights, component side (closed, after grinds):** J4 0.41 to the floor (solar box flat, **no stub**), camera lens 0.71 to the window edge (0.1 mm tape, no foam), J3 header 3.42, magnet body 0.71, U1 shield 2.5, J1/J2/L1 ≥ 3.0, D2 under the big ring 0.74 (no ring grind), camera ribbon over the mid rib 0.48, JST plug 0.8, battery leads 1.7. Key side: e-paper 1.05 + 0.15 tape on the board, 1.5 mm under the plate, mask 1.79 above the film, lens lifted 0.1 by the mask; key mat 0.11 from the board (lies on it), domes/travel as Casio's since the board sits where Casio's did (checklist item 7: Casio board thickness). LR44 holder 0.30 over the cell. Closed thickness 11.8 / 11.3 = D10 ✓.

**N5. Photo review vs CAD.** All 29 photos opened. New things the CAD did not have: (a) the inner rib's depth (S1); (b) the moulded label (M7); (c) the mat's four small rectangular feet at its bottom corners (photo 28bb9c4b) — they land on bare board at y > 205, harmless; (d) photo 7c6e8116's full-width cross rib between the display and the oval keys is on the key side between the panel (ends y 107.6) and the mat (starts ≈ y 113): no part there. Everything else matches `renders/compare/*` (split line, snap tabs, hooks, holder, ribs, rings, solar box, ticks).

---
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

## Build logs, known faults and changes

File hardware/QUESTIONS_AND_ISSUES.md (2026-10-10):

# Questions and issues for Nirav

Started 2026-10-03 (overnight session). Each item says what I assumed in the meantime, so nothing is blocked while you sleep. Answer them in any order. Items once marked **(blocks order)** have all been answered; only the "⭐ Start here" list below is current.

## ⭐ Start here: v15-LCD (added 2026-10-08 evening)
**v14 was ordered on 10/8 (tag `v14-order`, frozen); the list for it below still applies to the v14 boards.** The **v15-LCD board is verified "ORDER"** (`verification/14_v15_final_preorder.md`): order it with `ORDER_WALKTHROUGH_v15_lcd.md` (files `fab_v15_lcd/`, 21:38), and buy **3 × BuyDisplay ER-TFT019-1 (no touch)**. Nothing blocks the v15 order. Status: `FINAL_STATUS.md` → "Current plan".

**Closed for v15 (2026-10-08):** panel choice (ER-TFT019-1, datasheet-verified; Adafruit #5394 only a fallback; bulk from Alibaba Goldenmorning/ZJY after a sample check), R23 value (15 Ω C22810), tail route (slot x 180.5–181.5, J5 at (158.6, 93.1), one bow), board side of the pin-1 question (J5 mirrored; confirmed on two independent drawings), key-pad positions (SW1/SW2/SW50 moved to the Casio contacts). Sources: `stage15_lcd.md` §9, reviews 13, 14, 15.

**Re-checked 2026-10-10 (report only, no board change):** on a scratch copy of `kicad_v15_lcd/` with KiCad 10.0.6: ERC **0**, DRC `--refill-zones --schematic-parity --severity-all` **0 violations / 0 unconnected / 0 parity**, `tools/v15_lcd/check_hole_clearance_v15.py` **0 violations** (minimum 0.25 mm). The board (10/8 21:37) and `fab_v15_lcd/` (21:38) are unchanged since commit e82a962, so review 14 (`verification/14_v15_final_preorder.md`, the newest review) still describes them; it was followed here.

**Open for v15: the bench checks when the boards and panels arrive** (none can block the order; all are fixable on this board; `ARRIVAL_CHECKLIST.md` v15 section, v15 Power-Up guide https://claude.ai/artifact/BeQnacuLhchaHz492CnLRT):
- V1. **needs Nirav (hands, meter):** **Diode test on the first ER-TFT019-1 tail** before plugging it in: LED between finger 20 and finger 22 (11th and 9th from the pin-30 end). Finger 1 must land at the J5 silk tick (bottom), the LED fingers in the top half. If not: half twist of the tail.
- V2. **needs Nirav (meter, first board):** **Backlight current** = volts across R23 ÷ 15 at 100 %: expect 16–37 mA (≈ 26 typical). Too dim (< 18 mA): 12 Ω only if the measured Vf ≥ 2.75 V, otherwise the AW9364 driver on a later board.
- V3. **needs Nirav (first board + panel):** **Panel at 3.3 V** (top of its 2.4–3.3 V range): picture OK, IDD ≤ 20 mA. If it objects, a 2.8 V supply replaces Q4 on the next spin.
- V4. **needs Nirav (look at the colour bars):** **`LCD_INVERT` / `LCD_RGB_ORDER`** build flags on the colour bars (`firmware-v15-lcd/PORT_NOTES.md`). Checked 2026-10-10: both flags exist (`firmware-v15-lcd/platformio.ini` lines 30–31, defaults 1 / 0) and are used in `src/lcd.cpp` lines 53–54, so the bench answer is a one-line change.
- V5. **needs Nirav (calipers, at assembly):** **Tail length 36.6 ± 0.3 mm** and the bow's clearance to rib B (assembly guide, marker dot); a 36.9 mm tail leaves only ~0.1 mm.
- V6. **needs Nirav (press the keys, first assembly):** **Feel of the 3 moved keys** SHIFT, ALPHA, ON.
- Still Nirav's call (unchanged): battery-life plan (150 mAh vs the 1,200–1,500 mAh cell first), R5 → 15 k, a touch panel later (`stage15_lcd.md` §9 items 6, 7, 9). **needs Nirav (decisions):** the battery plan; R5 → 15 k also means regenerating the v15 Gerbers/BOM and a fresh check, so only on his yes; a touch panel needs GPIOs that v15 does not have, so it is a later-board question.

## ⭐ Start here for v14 (rewritten 2026-10-06 after the final review)
**Board v14 is GO to order, unchanged** (`verification/06_final_review_pcb.md` + second opinion `verification/08_second_opinion_pcb.md`, 2026-10-06: no FATAL, no SERIOUS; earlier re-check `verification/05_stage14_recheck.md`): DRC 0/0/0 with parity, ERC 0. **Not ordered yet** as of Tue 10/6. Status, decisions and history: **`FINAL_STATUS.md`**. Ordering: `ORDER_WALKTHROUGH.md`. This is the whole list of what is really open:

**Before paying JLCPCB**
1. **needs Nirav (hands, printer, front shell).** v14 is already ordered (10/8, tag `v14-order`), so this no longer gates v14. v15 uses the same holes (review 14 check 5d: the 10 NPTH/PTH holes are identical to v14) and has had no dry fit of its own (`stage15_lcd.md` §5), so this print is still the only check of the hole positions before the v15 order; whether to do it before ordering v15 is Nirav's call. **Paper dry fit, now with the antenna tab** (Nirav, when he's back): print **`Claude outputs/paper_dry_fit_v14.svg`** at 100 %, check the 50 mm line, cut it out **with the yellow antenna tab**, lay it in the front shell: every post must sit inside its hole. H6 has the least play (about 0.10 mm). Off by more than about 0.5 mm → stop and ask. **New (review 06 M1):** the ESP32 antenna sticks out about 4.2 mm past the board's left edge; the tab (4.5 × 15.4 mm, KiCad x 114.4–118.9, y 89.3–104.7) must clear the side wall (if it rubs, the fix is filing the plastic, not the board). **Review 07 (2026-10-06):** the tab is now printed on `fitcheck/grind_map_front_shell.svg`; the map's left edge is the calculator's right-hand side in use (solar-window side); if the tab or the board's top corner beside it fouls the wall's thin inner rib, that is grinding-guide zone 6 (35 mm of the rib, 14–49 mm from the shell's own top outer edge at that wall, measured from the rim's top edge right above the side rib; datum corrected 2026-10-10, was 15–50). Then do the 10-minute pre-grind checklist in `verification/07_final_review_fitment.md` §3 before any grinding. Steps: `FINAL_STATUS.md` §1a.
2. **Closed 2026-10-10 as an order question** (table below): v14 was ordered with J2 where it is, and v15 has no e-paper. What is left is an assembly habit on the v14 boards: push the ribbon fully home. Original item: **E7 / e-paper stiffener:** glass edge → ribbon tip, and the length of the stiff end. Stiff end ≤ 5 mm: fine as is. More than 5 mm: tell Claude before ordering (rule: `stage14_verification_fixes.md` §6; J2 moves +1 mm only if E7 ≥ 15.3). Settled by `verification/07_final_review_fitment.md` M2: about 1.6 mm nominal spare, about 0.3 mm worst case; build as if there were none and push the ribbon fully home.
3. **Closed 2026-10-10 for v14** (ordered 10/8); for v15 the same check is written into `ORDER_WALKTHROUGH_v15_lcd.md` (C3013941: 1,218 in stock on 10/8 21:30, review 14 check 5b). Original item: **JLCPCB stock of U1, ESP32-S3-MINI-1-N4R2 (C3013941)**, at the BOM upload step. If it is out of stock, order the bare PCBs and ask for a pre-order of C3013941; **accept no substitute** (an N8R8 loses IO33–37, which the board uses).

**When the parts arrive** (no board change either way; start at `ARRIVAL_CHECKLIST.md`, details in the Power-Up guide https://claude.ai/artifact/PqTARcDutvwxS5aGB8iEG9)
4. **needs Nirav (calipers, when the camera arrives).** **Camera ribbon length:** module far edge → tip. Under about 70.3 mm: tape the module up to 1.7 mm towards J1 and drill the 7 mm window over the lens where it actually sits. Only about 1.4 mm of spare is expected.
5. **needs Nirav (meter, real cable, before gluing).** **Magnet meter check before gluing** (mandatory): J3 = 1 VBUS, 2 D−, 3 D+, 4 GND. Find the +5 V leg of the mated #5412 cable with the meter and put it in pin 1 (board silk "N"/"+"); never trust the N/S marks alone.
6. **needs Nirav (meter).** **J4 battery polarity** (meter: red wire on "+"; if reversed, swap the crimp pins) and **E6**, the camera-ribbon beep test (fingers 2 and 15 to GND).

**Business / later (nothing blocks the order)**
- **needs Nirav (decision):** Pricing vs VovoCorp (`Claude outputs/COMPETITOR_ANALYSIS.md`); plan is $225 + $15/month, first month free.
- **needs Nirav (hosting account, may cost money):** Proxy: deploy it (Render or similar; `server/proxy/README.md`) **before Power-Up step 10**, which puts its https address and a device token into each calculator (API key only in the host's environment settings). Real sign-in on the link page before selling (Firmware 1–2 below; `server/proxy/FINAL_REVIEW_server.md` S3).
- **needs Nirav (read the back labels, take photos):** Donor edition check (Business 8), CAD photo requests (side profile, slide case) only matter for the replica model.

### Closed on 2026-10-10 (answer and source)
| Question | Answer | Source |
|---|---|---|
| E7 / e-paper stiffener: move J2 before ordering? | No longer an order question. v14 was ordered on 10/8 with J2 unchanged, and v15 removes the e-paper and J2 entirely. On the v14 boards just push the ribbon fully home (review 07 M2: about 1.6 mm nominal spare, 0.3 mm worst case). | `FINAL_STATUS.md` "Current plan" 1; tag `v14-order` (48d422a, 2026-10-08); `stage15_lcd.md` §3 "Removed" |
| U1 (C3013941) stock before paying | Closed for v14 (ordered 10/8). For v15 the check is in the walkthrough: 1,218 in stock on 10/8 21:30, accept no substitute. Re-check at the BOM step on the day. | `ORDER_WALKTHROUGH_v15_lcd.md` (stock line); `verification/14_v15_final_preorder.md` check 5b |
| Is the v15 board still clean (nothing drifted since review 14)? | Yes. 2026-10-10, scratch copy, KiCad 10.0.6: ERC 0; DRC with zone refill and schematic parity 0 / 0 / 0; copper-to-hole 0 violations. Board and fab files unchanged since e82a962. | this file, v15 block above |
| Firmware to-dos from the reviews (PCB stage 11 #10, Final review #7) | All in the board firmware, v14 and v15 alike (line numbers are for `firmware-prototype/src/`; the same code is in `firmware-v15-lcd/src/`): Wi-Fi TX cap 11 dBm (`power.h` line 33, `kWifiMaxTxQuarterDbm = 44`); AI lock below 3.6 V (`core/battery.h` line 22); TCA8418 FIFO drained and INT_STAT cleared before sleep (`keys.cpp` `keysPrepareSleep`); camera power cut first, then the camera pins released with no pulls (`power.cpp` `powerCameraPinsSafe`); camera power-up RESET low, PWR_EN, settle, RESET high (`camera.cpp` around line 365); IO35 CHG_STAT a plain input, no pull-up (`power.cpp` line 80); USB-Serial-JTAG pad off without a cable (`power.cpp` lines 179–180). | `firmware-prototype/src/`, `firmware-v15-lcd/src/` |
| Magnet connector alternates | Yiwei MG04254FRA1S1N = Adafruit #5358 (same part); Yiwei MG0425-UB-60-4P cable = #5412 equivalent (GND, D+, D−, V+ from its N end). J3 order and the meter check unchanged. Recorded in the BOM notes, the order/arrival docs and both spreadsheets. | Nirav, 2026-10-10; `stage15_lcd.md` §3 |

### Closed on 2026-10-06 (answer and source)
| Question | Answer | Source |
|---|---|---|
| Which end of the JLC-placed magnet socket C46061768 is "N"? | Not a question any more: C46061768 is a plain symmetric 4-pin 2.54 mm right-angle socket with no magnet. The "N" end belongs to the Adafruit #5358 piece Nirav plugs in; it is set by the board's "N" silk at pin 1 and the meter check (item 5). No CPL change. | `verification/08_second_opinion_pcb.md` "Resolution of open item (a)"; `06_final_review_pcb.md` check 8 |
| Is the board still GO after a from-scratch review? | Yes, v14 unchanged: pads vs netlist 0 mismatches, every IC pin vs datasheet, CPL rotations vs EasyEDA 77/77, J1–J4 pin orders, strapping pins, power tree, keypad matrix, holes vs calipers. Minor only: antenna tab (item 1), 1.25 mm of GND under the antenna root (v15), 0.06 mm pin-1 silk (cosmetic). | `verification/06_final_review_pcb.md`, `08_second_opinion_pcb.md` |
| Does the firmware block bring-up? | No. `firmware-prototype/` (the board firmware; `firmware/` is the breadboard tester, never flash it to the board) builds clean, all pins match the schematic. Its fixes were applied the same day (OTA with rollback, phone setup page via SETUP 6, battery gate for camera + Wi-Fi, EPD BUSY pull-down, `firmware_slot` in status); the first flash of each board must be over USB. | `../firmware/FINAL_REVIEW_firmware.md` |
| A bigger cell? | Decided: **Adafruit #1317, 150 mAh, 26 × 19.75 × 3.8**, same price and plug, lies on the back-cover floor, no new grind. Charge current stays 50 mA (0.33 C). | `enclosure/final_assembly/battery_upgrade.md` §8; FINAL_STATUS decisions log |
| Camera-ribbon spare: 12 mm or 1.4 mm? | About **1.4 mm** (the 70.5 mm on the drawing includes the 8.5 mm module). The 12 mm in the old model notes is wrong. | `stage14_verification_fixes.md` §6; `06_final_review_pcb.md` N2 |
| Tape under the camera and battery | **0.1 mm double-sided tape, no foam** (0.3 mm above the battery, 0.5 mm above the lens); e-paper on about 0.15 mm. The "≤ 0.2 mm" in Heights 3 below is stage-13 wording. | assembly guide; `battery_upgrade.md` §8 |
| Camera window size | **7 mm** (9/32" OK) at KiCad (150, 95.1), drilled after the ribbon is measured. "6 mm" in older docs is stale. | `stage13_heights.md`; grinding guide |
| Stage-14 "fix 4" references | The ribbon rules (camera and e-paper) are **§6** of `stage14_verification_fixes.md`; §4 is recovery/R17. | `verification/10_docs_consistency.md` #7 |
| JLCPCB preview: rotate parts? | **No.** The CPL in `fab/` is rotation-corrected (`tools/jlc_cpl.py`); verify against `ORDER_WALKTHROUGH.md` step 5, rotate and move nothing. | `verification/05`, `08` §1 |
| Does the calculator work without the subscription? | Yes (roadmap §0): it is a normal scientific calculator; only AI SOLVE needs the subscription. | `Claude outputs/LAUNCH_ROADMAP.md` §0 |
| Proxy built? Factory self-test exists? | Both done: `server/proxy/` (FastAPI, device tokens, TRIAL_DAYS=30, MONTHLY_CAP=500); self-test = SHIFT + ALPHA held, ON, or `selftest` on serial. Switches `ROUTING`, `FREE_DAILY`, `REFUSAL_FALLBACK` exist with the defaults assumed in Firmware 3–5 below. | `firmware/FIRMWARE_STAGE13.md`; `verification/10_docs_consistency.md` #12–13 |
| Order date | The Mon 10/5 order did not happen. Boards land about 10–14 days after the order (about 10/17–10/21 for an order on 10/7; `FAB_VENDOR_COMPARISON.md`); later roadmap dates slip by the same amount. | `verification/10_docs_consistency.md` §0 |
| Battery position / LR44 cup | On the back-cover floor; the LR44 cup is **not** ground. | `enclosure/final_assembly/assembly_report.md` |
| Recovery | Hold TP1 (BOOT) to TP4 (GND), tap TP7 (EN), flash. UART backup TP2/TP3. Never burn eFuses. | `stage14_verification_fixes.md` §8; `pins_final.h` |
| Waveshare "V4" | Buy raw panel SKU 12672; the page may not print "V4" (that is the HAT's name). Same panel: 250 × 122, 59.2 × 29.2 × 1.05, SSD1680. | `verification/10_docs_consistency.md` #19 |
| R17 10 k or 100 k? | 100 k (schematic, BOM C25741, board, `pins_final.h` agree). | `stage14_verification_fixes.md` §6 (R17 note) |
| Is every decision we ever made actually on the v14 board? | Yes: 50 checks run on the board file (pin map, connectors, power parts, holes, slot, antenna, silk, BOM), nothing missing. Only cosmetic leftovers on non-fabricated layers (camera marker drawn Ø 6 on User.3, old title block, J4 value text "Adafruit 1570"). | `verification/11_requirements_trace.md` |

Everything below is the full history; ✅ = answered, ~~struck~~ = superseded.

## Measurements

1. ✅ **Answered (C8 46.5 / 42.3, stage 12).** **C8: "61.8 outside to outside".** Which post pair is that? From your photos the pairs are about 46.4 (beside SHIFT/ON), 42.3 (under row 2), 38.3 and 38.6 mm apart, centre to centre. 61.8 − 3.85 = 57.95 doesn't match any of them. *Assumed: holes stay at the photo-measured positions.*
2. ✅ **Answered (C9 68.1, posts clear of board).** **C9: "3.7 outside to outside / 49.65".** Is 3.7 the post's width and 49.65 the outside-to-outside distance between the two top-corner posts? That would make them about 45.8 mm apart, centre to centre. The photos suggested about 62.7. *Assumed: photo positions kept.*
3. ✅ **Answered (stubs stop above the board; stage 12 narrowed the board anyway).** **C4: wall thickness 4.7 / 5.5.** That's thick for a side wall. Was it measured at the screen section where the round stubs are? *Assumed: 4.7 is the stub zone and the bare wall is thinner.*
4. ✅ **Mostly answered (C14, C15, D1–D13 in); E6/E7 still open.** **Still to measure :** C14 (wall stubs), C15 (post distances from the top edge), depths D1–D4, D11, D13, the ribbon checks E6/E7 and, if you can, the F6 flatbed scan (the best single source of exact positions).

## Electrical (from the independent review, `REVIEW_independent_2026-10-03.md`)

5. **R20 leakage fix.** R20 leaked about 20 µA into the charge contacts when no cable is in. The PCB worker is moving its pull-up to VBUS_SENSE (or leaving R20 off the board). Nothing for you to do, just know it changed.
6. **Regulator swap, AP2112K → RT9080.** Standby goes from about 6 weeks to about 4–6 months. Same footprint. Say if you'd rather keep the AP2112K.
7. **Battery polarity.** Before ordering, check the Adafruit battery's red wire against the J4 + mark (sheet item E3). Reversed JST leads are common.

## Business (from the roadmap)

8. **Calculator edition.** Are your two calculators the same edition (fx-115ES, **PLUS** or **PLUS 2nd edition**) as the one you measured? The insides can differ, so it's worth a quick look at the back labels.
9. **Age.** If you're under 18, a parent needs to be the account holder for the LLC, Stripe and preorder platforms. Worth sorting out early.
10. **Subscription.** Should the calculator work as a normal scientific calculator without the $15 subscription? I recommend yes.

## CAD replica
(fx-115ES shell replica, `enclosure/build_fx115es_replica.py`, details in `enclosure/replica/README.md`)

1. ~~**Width (C2 = 79.3):** is that the front shell or the back cover?~~ **Answered (2026-10-03):** C2 = front shell at the screen section, C3 = back cover, both 79.3. The model now has straight 79.3 sides and the front shell 77.4 in the keypad section. Original question: The photos show the navy back cover wrapping round the front shell along the keypad section, so the model makes the back cover 79.3 wide and the front shell ~1.8 mm narrower there (78.4 max). If the front shell itself is 79.3, say so and the tray walls get thinner.
2. **Partly answered:** total thickness is now known (D10: 11.8 top / 11.3 keypad; board at D1/D4). Still open: the side photo, for the parting line (now guessed 3.5), tray-wall height (9.8) and round-overs. Original question: **Profile from the side:** no side-on photo. Please take one straight-on photo of the long side (with a ruler). It decides the parting-line height (guessed 2.6 mm from the back), how high the back cover's tray walls come up (guessed 11.3 mm), and the edge round-overs (guessed 2.0 front / 1.2 back).
3. **Still open (face plate now 1.3, checked against D3):** **Key height:** how far do the keys stick up above the face (guessed 1.5 mm)? And the face-plate thickness.
4. **Battery:** the back shows a round LR44 hole in a shallow rectangular recess. Is there a lid or sticker over it? Size of the recess? (guessed 16 x 15 mm, 0.6 mm deep, thin lid modelled).
5. **7th hole:** the back has a small hole in the centre over the small ring (photo e82c982d). Screw or something else? (modelled as a plain 2 mm hole.)
6. **Feet:** where are the rubber feet and how big? (guessed four 7 mm round feet, now 0.3 mm proud.)
7. ~~**Corner screw posts:**~~ **Answered (2026-10-03):** C9 (68.1 c-c) + C15 (8.9 row) put them at (±34.05, 74.05); with a 1.4 skin C11 then checks out at 4.20 / 6.02. They are outside our board. Original note: with C11 (4.2 / 6.1 from the inside walls) the model puts them at (±32.7, 73.2) front-view mm, which agrees with the photo estimate within ~1 mm. Fine for the PCB's cut-outs, but check H-hole clearance once the board is final.
8. **Slide hard cover:** not measured at all; the model's cover is a placeholder (plain lid with side walls). Calipers on the real cover (length, width, height, wall thickness, how it grips) would fix it.
9. **Fixed (2026-10-03):** the json is now one continuous loop (450 points; `build_case.fx115_outline()` parses it unchanged). Original note: `enclosure/fx115es_outline.json` stores the outline as 3 runs out of order. `build_fx115es_replica.py` re-chains them; `build_case.py` reads the file as-is, which only works because Fusion builds profiles from the crossing lines. Worth fixing in the json or in `build_case.fx115_outline()`.
10. **(new) C15 reading convention.** "From the outside of the calculator to the outside of the holes": I read it as case top edge to the *far* edge of the hole inside each post (pilot Ø1.7 / bore ~Ø1.2). That fits the photos to ≤ 1.05 mm; reading it as post centres gives up to 1.65 mm. Is that what you measured? It moves H2/H9 1.0–1.2 mm lower than the board has them.
11. **(new) Row 3 (H8/H10, ~80 mm down)** was not in C15. Please read it the same way.
12. ~~**(new) D4: to the outside of the back, or to the inside of the floor?**~~ **Answered (2026-10-03):** D4 = 6.0 from the board to the back cover's *inside* face; D1 = 5.5 from the front shell's *rim* down to the board. Stack 1.0 + 6.0 + 0.8 + 4.0 = 11.8 (3.5 front side at the keys = 11.3). Replica rev B2 uses it; the camera and J4 now clear the floor (they still hit the solar box / rib B). Original question: The model takes D1 and D4 to the outside faces (5.5 + 0.8 + 5.5 = 11.8 = D10), so the space behind the board is only **4.5**. Then the 5.4 camera, J4 (5.5) and J3 do not fit (see `enclosure/replica/fitcheck_report.md`). If D4 is the inside gap, the case would be 12.8 thick, which disagrees with D10. A quick check: depth from the back cover's rim to its floor, and rim to the board with the board in.
13. ~~**(new) Stubs and the inner rib in Z:**~~ **Answered (2026-10-03):** they stop above the board plane (photo 871567b6). Modelled down to Z 8.0, 0.2 above our board, so no board-edge clash any more. Original question (C14 "5 high"): 5 high from the inside of the face, so they reach down to the board line? Our board (72.3 wide) runs 1.2–2.0 mm into them at the screen section. If they stop above the board, there is no clash.
14. **Mostly answered:** the stack-up adds up to 11.8 / 11.3 at the face, so D10 is over the face, not the keys. Still open: do the jaws sit on the feet? Original question: **(new) D10 "11.3 overall":** measured over the key tops or over the face? The model takes the face (keys 1.5 above it). And do the jaws sit on the feet (model: feet 0.3 extra)?
15. **(new) Where does the face step** from 11.3 to 11.8? The model ramps it between REPLAY and the display bezel (guess).
16. **(new) Mid screw posts:** C8 gives 46.5 between them; the board's H1–H3 are 45.6 apart, so the H1 post rubs its hole (−0.06). The pair's left-right centre is still from the mat photo (−0.8).
17. **(new) Fit check, for the PCB agent:** re-run `python build_fx115es_replica.py fitcheck fitcheck_shots` after `ai_calc_board.step` is regenerated. Today's run (STEP 18:10): camera module 0.9 into the back floor; J4 1.0 and J3 0.5 into the floor and in the solar box; solar box (5–5.5 high) over the board's top-right corner (27 × 13 mm) plus U3, D1, D7, Q2, C6, the LiPo; locating posts H2 −0.54, H9 −0.29, H6 −0.11 in their 4.2 holes; board edge in the screen-section inner rib 1.2 and stubs up to 2.0. ESP32-S3 and U6 3D models are missing from the STEP export (proxies used).
18. **Handled (stage 13; LR44 cup later dropped: battery on the back-cover floor):** grind list = solar box, rib B (camera), LR44 cup; locating holes H2/H9/H13/H14 slotted and H6 moved (fit both post readings); STEP regenerated. Original: **(new) For the PCB agent: rev B2 fit check on the stage-12 STEP (23:02).** What remains is all solar-box / rib / cup items that grinding fixes (camera 0.31 on rib B, J4 inside the solar box, J3 1.0, U3 1.05, D1 0.75, Q2 0.70, LiPo 3.2 in the solar box and 2.0 into the front shell's LR44 cup), plus the locating posts H2 −0.54 / H9 −0.29 / H6 −0.11 against their holes. The STEP board is 0.71 thick; KiCad says 0.8. Details: `enclosure/replica/fitcheck_report.md`.
19. **Done (stage 13):** the table now uses 6.0 (limit 5.7) and has camera, LiPo and magnet rows. It still counts any rib within 1.5 mm as on top of a part, on purpose (photo rib positions are ±1 mm). Original: **`hardware/fitcheck/clearance_table.md` disagrees with the replica.** It still uses a 4.5 free height (now 6.0). It adds the rib height on top of the part height wherever a rib is within 1.5 mm, so U2, C5, R2, R4, D2 and C16 show as clashes; in the replica's exact geometry they clear. It has no camera row. With 6.0, its "after grind" J4 −1.0 / J3 −0.5 become +0.5 / +1.0.

## PCB (stage 11)
(details in `stage11_epaper_calipers.md`; board is DRC 0/0/0 with schematic parity)

1. ✅ **Answered (stubs stop above board; stage 12 narrowed anyway).** **C4 wall 5.5 / 4.7 mm at the screen section.** The board's top part is 72.3 mm wide (x 113.84–186.16); with a 79.3 case and 4.7–5.5 mm walls the inside is only 68.3–69.9 mm. Please measure the *inside* width of the front shell at the screen section, wall to wall, at board height, and say where the stubs are. *Assumed: the thick reading is the stubs / wire holder, the plain wall is thin, so the outline is unchanged.* If the wall really is that thick, the ESP32 has to move about 2 mm inward.
2. ✅ **Answered (C8 = 46.5 / 42.3, stage 12).** **C8 "61.8 outside to outside" — which two posts?** No post pair on the board matches (57.95 or 58.9 c-c). *Assumed: holes stay at the photo positions.*
3. ✅ **Answered (C9 = 68.1, posts clear of the board).** **C9 "3.7 / 49.65" — which posts, and is 3.7 a diameter?** *Assumed: photo positions kept.*
4. **Window position left-right.** Only its size (60.65 × 24.3) and top edge (24.0) were measured. *Assumed: centred on the case (x = 150).*
5. **Window wider than the panel glass** (60.65 vs 59.2): about 0.5–0.8 mm of board shows at each end of the glass. *Assumed: fine; a black mask sticker can hide it.*
6. **E7 e-paper ribbon length** (panel edge to tip). *Assumed: 14.3 mm per the drawing; 13.5–15 mm works.*
7. **Panel active area centred on the glass?** *Assumed yes (as since stage 1); if your panel's driver end is wider, the picture sits off-centre by that amount.*
8. **Screw vs locating posts.** From the bare Casio board photo: the two row-1/2 posts (H1/H3) and the bottom notches are screw posts (holes 6.0 mm, notches unchanged); all others are 2.9 mm locating posts (holes now 4.2 mm). *Tell me if any small post is actually a screw.*
9. **R20 now on VBUS_SENSE, U3 now RT9080-33GJ5, new C32 22 µF, new TP5/TP6/TP7.** Nothing to do unless you want the AP2112K back. Firmware: read CHG_STAT only while VBUS_SENSE is high (it reads low with no cable).
10. ✅ **Closed 2026-10-10: all done in the firmware** (see the ⭐ "Closed on 2026-10-10" table). **Firmware to-do (review S4/S6):** cap Wi-Fi TX power (~11 dBm) and lock AI below ~3.6 V; drain the TCA8418 FIFO / clear INT_STAT before deep sleep; release camera GPIOs (no pulls) before cutting CAM power; USB-Serial-JTAG off without cable.
11. **JLCPCB preview:** check D7's cathode band is on the VBUS pad (towards J3). *Assumed: KiCad 0° = JLCPCB 0° for this SOD-123FL part.*

## PCB (stage 12)
(details in `stage12_measurements.md`; board is DRC 0/0/0 with schematic parity, ERC 0)

1. ~~**(blocks order) J4 battery socket**~~ **Answered (stage 13):** with D4 = 6.0 J4 fits (0.5 mm) once the solar box is ground flat; no board change. Original: **J4 battery socket is 5.5 mm tall; the space above the board there is about 4.0–4.6 mm** (from D1 + D10 + D5; D4 read literally would give 5.5). Even with the solar box ground flat, it's ~1 mm too tall. No JST-PH SMD socket on JLCPCB is lower. Please measure **D11** (space above the board line beside the battery bay, front + back halves added). Options if it really is ~4.5: (a) a 3.6 mm MX1.25 socket (C7430468, in stock; footprint already in the library) with a 1.25 mm-plug battery, e.g. a 100 mAh cell sold with a Molex 51021 plug; (b) leave J4 off the assembly and solder the battery leads to TP6/TP4 (you said no soldering); (c) cut a small window in the back cover over J4. *Assumed: J4 unchanged until you answer.*
2. ✅ **Answered: you chose option A, done in stage 13b.** **Still blocks order, now a decision (stage 13 → Heights item 1).** Original: **J3 magnet socket (5.0) plus the magnet's legs and body don't fit under the back cover** at the top edge (−0.5 mm after grinding, worse with the magnet itself). This needs the Adafruit 5358 in hand (P5) to see how it sits in the top-wall slot. *Assumed: J3 unchanged. If it doesn't fit, a board-edge notch so the magnet sits beside the board is the likely fix.*
3. ~~**(blocks order) Camera height.**~~ **Answered (stage 13):** 5.4 fits under 6.0 (0.5–0.6 mm) once rib B is ground for 14 mm over it; 7 mm window; the lens no longer has to go into the hole. Original: **Camera height.** The module is 5.4 tall; the space is ~4.0–4.6 (5.5 if D4 is right). It only fits if the lens barrel goes into the 6 mm back-cover hole. Please photograph the module from the side next to a ruler (F3) so I can see how tall the square body is without the lens, and how wide the lens barrel is. *Assumed: body ≤ 4 mm, barrel ≤ 6 mm; rib B ground away over the camera.*
4. ~~**D4 vs D1: which faces?**~~ **Answered (2026-10-03):** D4 = 6.0 to the back cover's inside face; D1 = 5.5 from the front-shell rim to the board. Original: **D4 vs D1: which faces?** Was D4 measured from the inside of the back cover, and D1 to the board's top face (the side facing the back cover)? This decides 4.5 vs 5.5 mm above the board, and with it items 1–3. *Assumed: 4.5 design, 4.0 worst case.*
5. **Dry fit before ordering:** print `fitcheck/grind_map_front_shell.svg` at 100 %, cut it out (outline and holes), and lay it on the posts in the front shell. Check that H3 (right screw post beside SHIFT) and H2/H6/H9 drop over their posts without pushing. The new photo puts the H3 post up to 1.4 mm left of the hole centre (other photos and C8 say it's right). *Assumed: holes at the photo/C8 positions.*
6. ~~**Snip the wire hook**~~ **Not needed (stage 13):** the clips stop above the board plane (photo 871567b6). Original: **Snip the wire hook at the top right of the screen section** (inside the wall, level with the top of the window, about 1 mm into where the board goes). It only held Casio's wires. The other hooks and the side pins are now outside the board. *Assumed: OK to snip.*
7. **Final grind list (see `FINAL_STATUS.md`):** solar box, rib B 14 mm, 7 mm camera window, magnet U-notch (5b lip only if present); the LR44 cup is no longer ground (battery on the back-cover floor). **Updated in stage 13:** grind list is now solar box flat, rib B over the camera, LR44 cup (front shell); the big ring no longer needs grinding. Original: **Grinding plan (back cover):** solar box flat to the floor; the big ring's arc next to D2/C16 down to 2 mm; rib B where it crosses the camera; the LR44 cup in the front shell. All shown in red on `fitcheck/grind_map_back_cover.svg`. *Assumed: you're happy to grind these (D6/D13 said yes).*
8. **C15 readings:** the H2/H9 and H6 rows came out +0.9 and −1.0 mm from the photos, in opposite directions only 11 mm apart, so I think one reading slipped. If you re-measure, please do just those two rows, to the centre of the post. *Assumed: photo positions.*
9. **E-paper picture sits 2.6 mm off-centre in the window** (the panel's active area is not in the middle of the glass, per the Waveshare V4 drawing). Fully visible, just not centred. Firmware can shift it; a later board can move the panel. *Assumed: OK for v12.*
10. **E7 (ribbon length) still unmeasured.** You can measure it on the panel while it's still in the HAT: glass edge to ribbon tip. 13.5–15 mm works. *Assumed: 14.3 per the drawing.*
11. **Regulator:** RT9080 kept (C841192, Extended, $0.12, in stock); AP2112K is also Extended and costs more. Nothing to do.
12. **R12 3 Ω could become a Basic 2.2 Ω part (saves $3)**, but it changes the e-paper booster's current limit. Measuring E5 (the resistor next to the inductor on your HAT) would settle it. *Assumed: stays 3 Ω.*
13. **The ESP32 antenna now hangs ~4 mm past the board edge** into the gap beside the wall (Espressif's preferred layout). Nothing to do, but don't bend the module when fitting the board.

## Heights (stage 13)
(details in `stage13_heights.md`; board is DRC 0/0/0 with schematic parity, ERC 0. Free height behind the board 6.0, design limit 5.7.)

1. ~~**Magnet connector: pick A or B.**~~ **Answered (2026-10-04): A, done in stage 13b.**
   - J3 = C46061768 at (127.5, 72.0).
   - The magnet sits in front of the board edge, so no notch was needed.
   - D7, U2 and C6 moved; the corner was re-routed; DRC 0/0/0.
   - Slot: U-notch in the top wall, 21.5 wide × 7.95 from the rim, 6.4–27.9 mm from the right side edge (seen from the front).

   Original question: **(blocks order) Magnet connector: pick A or B.** Its face is 7 mm tall, more than the 5.7 mm above the board, and its legs can't reach the 5 mm J3 socket, so it must sit across the board edge. Grinding can't fix this.
   - **A (no soldering, recommended):** a notch in the board's top edge, plus a right-angle SMD female header (C46061768, $0.18, 8,753 in stock). You straighten the 4 legs with pliers, push them in and glue the magnet into the top-wall slot. The charger parts move about 10 mm. I need about 2–3 h for that after your yes.
   - **B (smallest board change):** 4 plated holes where J3 is now, and a 22 × 5 mm window in the back cover's top edge. Someone has to solder 4 joints (JLCPCB through-hole service via Global Sourcing, a makerspace, or you).
   - *Assumed: J3 unchanged until you choose.*
2. **Grind list** (print `fitcheck/grind_map_back_cover.svg` / `grind_map_front_shell.svg` at 100 %):
   - solar box flat to the floor (5–5.5 mm),
   - rib B flat for 14 mm over the camera (1 mm),
   - ~~LR44 cup in the front shell trimmed flat (5–6 mm),~~ **superseded:** the battery now lies on the back-cover floor, so the LR44 cup is not ground (`enclosure/final_assembly/assembly_report.md`),
   - magnet U-notch in the top wall, and the back-cover lip at the notch (5b) only if your cover has one,
   - drill the camera window, Ø 7 mm at KiCad (150.0, 95.1).

   Never grind into the floor: keep ≥ 0.8 mm. *Assumed: OK (you said you can grind anything).*
3. **Camera mounting:** Kapton under it, then thin (≤ 0.2 mm; **now 0.1 mm**, see ⭐ Closed) double-sided tape, not foam. If the "with heat sink" version is taller than 5.5 with the sink on top, leave the sink off. *Assumed: module 8.5 × 8.5 × 5.4, lens centred.*
4. **Locating holes H2/H9/H13/H14 are now slots and H6 moved 0.2 mm**, so each fits the post at both the photo and the C15/CAD position (0.10–0.61 mm of room). At the dry fit, if H6 pushes, file it a little toward the top of the board. *Assumed: posts Ø 2.9.*
5. **When the magnet part arrives (P5):** check that its pins leave the body on the centre line of the 7 mm face, and measure the body depth (drawing: ~4 mm). Option A depends on it.
6. **D3 "about 5 at the top edge":** probably the back cover curving at the very end. J4 is ≥ 8 mm from the top edge, so it shouldn't matter; if you can, check the depth right above J4 (KiCad 142.6, 74.6) with the solar box ground.
7. ~~**(new, 13b) Magnet pin order.**~~ **Superseded by stage 14 (#1 below).** The old order (VBUS, GND, D−, D+) matched the cable in neither orientation, and the "turn the magnet piece over" advice would have put 5 V on D+. J3 is now VBUS, D−, D+, GND with the piece's N end at pin 1.
8. **(new, 13b) Leg length.** The drawing gives about 5.3 mm of straightened leg, and J3 takes about 4.5 mm. If the face can't sit flush, trim the legs a little. *Assumed: per the drawing; check when P5 arrives.*
9. **(new, 13b) Extra decoupling.** C33/C34 (22 µF 0805, Basic C45783) were added on the +3.3 V trunk just above the ESP32. Nothing to do.

## Final review
(2026-10-04, `REVIEW_final_2026-10-04.md`. Verdict: ready to order. DRC 0/0/0 with parity, ERC 0, fab files current, all 30 LCSC parts in stock at JLCPCB.)

1. **Paper dry fit before paying.** Print `fitcheck/grind_map_front_shell.svg` at 100 % and check the posts drop through H2/H3/H6/H9/H13/H14. This is the only remaining check that could change the board. *Assumed: holes are right.*
2. ~~**JLCPCB preview rotations.**~~ **Superseded by stage 14:** the CPL in `fab/` is now rotation-corrected (`tools/jlc_cpl.py`); check the preview against `ORDER_WALKTHROUGH.md` step 5 instead. Original: Expect to click-rotate several parts by 180°: Q1–Q3, U2–U5, U7, J4. U6 may be off by 90°. The walkthrough in the review says where pin 1 must be on each part. **D7's band must be on the right-hand pad (towards J3).** *Assumed: fixed in the preview, CPL unchanged.*
3. ~~**U1 / J3 may show up shifted in the preview.**~~ **Superseded by stage 14:** the CPL positions and rotations were checked against JLCPCB's EasyEDA footprints (`verification/05_stage14_recheck.md`); verify the preview against `ORDER_WALKTHROUGH.md` step 5, don't move or rotate anything. Original: Their KiCad origin isn't the body centre (U1: 2.55 mm, J3: about 6 mm). Ask JLCPCB to align them to the pads. Also answer "intended" to any "component exceeds board edge" question about the U1 antenna or J3. *Assumed: the engineer aligns to the pads.*
4. ✅ **Closed 2026-10-10:** Measurements 1, 2 and PCB (stage 11) 1 are marked answered above; the E6/E7 leftovers of Measurements 4 are covered in ⭐ (E7 closed as an order question, E6 = v14 item 6). **Stale "(blocks order)" items.** Measurements 1, 2 and 4 and PCB (stage 11) item 1 were answered in stages 12–13 (C8/C9/C4/D-depths). Only the dry fit and E7 are really open. *Assumed: you agree they're closed.*
5. **Battery polarity (still a meter check).** J4 is − on the left and + on the right, seen from the component side with the opening towards you, which matches the usual Adafruit/SparkFun convention. If your battery turns out reversed, swap the two crimp contacts in its plug (lift the tabs with a needle). No soldering, and Q1 protects the board meanwhile.
6. **Later revision (optional).** R5 20 k → 15 k (C25756) keeps VBUS_SENSE under 3.6 V with a 5.5 V adapter. Not needed for this order.
7. ✅ **Closed 2026-10-10: all done in the firmware** (evidence in the ⭐ "Closed on 2026-10-10" table). **Firmware to-do (from both reviews).**
   - Cap Wi-Fi TX power at about 11 dBm.
   - Clear the TCA8418 INT before sleep.
   - Release the camera pins before turning the camera off.
   - Don't enable IO35's internal pull-up without VBUS.
   - Camera power-up order: RESET low → PWR_EN → 5 ms → RESET high.

## Stage 14
(2026-10-04, `stage14_verification_fixes.md`. Fixes every finding of `verification/01–04`. Board v14: DRC 0/0/0 with parity, ERC 0. Tests 548/548, firmware 0 warnings.)

1. **Magnet (J3) pin order changed to VBUS, D−, D+, GND, with the piece's N end at pin 1** (silk "N" and "+" by pin 1, "−" by pin 4).
   - Why: the Adafruit #5412 cable's face reads GND, D+, D−, VBUS from its N end. Mated face to face, the board piece reads VBUS, D−, D+, GND from its own N end.
   - Power and ground are now the outer pins, so a piece fitted backwards can never put 5 V on a data line. It would swap VBUS and GND instead: D7 clamps that, and the host port current-limits.
   - **Do the meter check before gluing** (`ORDER_WALKTHROUGH.md`). *Assumed: Adafruit's drawing is right (~85 %). The meter check catches it if not.*
2. **The CPL now has JLCPCB's rotations built in** (`tools/jlc_cpl.py`, run by `make_outputs.sh`).
   - Checked against JLCPCB's own EasyEDA footprints: 22/22 polarised parts put pin 1 on pad 1.
   - Upload `fab/ai_calc_CPL_JLCPCB.csv` as is.
3. **Camera ribbon (verification 03 L1).** The ribbon is about 62 mm past the module, so there's only about 1.4 mm to spare, not 10 mm. **No board change (J1 stays).** Moving J1 2 mm closer would help only if the ribbon is short, and a flat ribbon can't take up extra slack if it's long.
   - **Decision rule:** if your measurement (module far edge → tip) is under about 70.3 mm, tape the module up to 1.7 mm towards J1 (still inside its keep-out) and drill the 7 mm window over the lens where it actually sits.
   - *Please measure it when the camera arrives.*
4. **E-paper stiffener (verification 03 L3).** **No board change (J2 stays).** Moving J2 1 mm away from the slot would make the ribbon too short, because the length budget already has no spare (14.3 = 14.3).
   - **Decision rule:** if the thick, stiff end is ≤ 5 mm, it's fine as is.
   - If it's > 5 mm **and** the glass-edge-to-tip length (E7) is ≥ 15.3 mm, tell me before ordering, and J2 moves +1 mm.
   - If it's > 5 mm and E7 < 15.3, neither position is clearly right: tell me before ordering, and don't guess. A partly inserted ribbon isn't an acceptable fix.
   - *Please measure both before ordering if you can.*
5. **H3 / SW1:** the SHIFT key pad's bottom bar was 0.055 mm from the H3 screw hole.
   - It's now thinned on that side only (new footprint `KeyPad_6.0x4.5_H3notch`). The finger contacts the carbon dot touches are unchanged.
   - Every copper item on the board is now ≥ 0.25 mm from every hole (custom check).
6. **R17 is 100 k, not 10 k.** Verification 02 (C12) and the stage-14 brief said 10 k, but the schematic, BOM (C25741) and board all say 100 k, and `pins_final.h` already said 100 k. Nothing changed; it now names R17. *Assumed: 100 k stays (only matters while ON is held).*
7. **Key names:** row 2 is now CALC and ∫dx (fx-115ES), in the schematic and in the firmware.
   - On the 115ES, Abs is SHIFT hyp, x³ is SHIFT x² and ∛ is SHIFT √. The firmware now does that.
   - **CALC/SOLVE and ∫dx/d/dx aren't implemented yet.** They show "Not supported yet" instead of doing the wrong thing. *Assumed: OK for the prototype; say if you want them implemented.*
   - Other fx-115ES SHIFT functions that the firmware ignores, as before: ∠, ←, a b/c⇔d/c, Σ.
8. **Recovery procedure corrected.** Plugging the cable in doesn't reset the chip while the battery is connected. Now:
   1. Hold TP1 (BOOT) to TP4 (GND).
   2. Tap TP7 (EN) to GND.
   3. Flash.
   - Or unplug the battery first.
   - UART backup on TP2/TP3.
   - Never burn the security or USB-disable eFuses.
9. **Web simulator:** its page now has the 115ES labels, but the built `simulator.html` / `AI_Calc_Simulator.html` (and the Windows exe) still have the old keys until they're rebuilt (Emscripten / MinGW aren't on this PC).

## Firmware

Stage-13 firmware notes: `firmware/FIRMWARE_STAGE13.md`. Each item says what I assumed; tell me if it's wrong.

1. **Where should the proxy run, and under which address?** The calculator needs an https:// address for `proxy`. *Assumed: Render (or Railway / Fly.io) with its own https address for now; a domain later.*
2. **The link page is only "code + e-mail".** Anyone who sees the 6-letter code on a calculator could link it to their own e-mail. That's fine for testing, but it needs a real sign-in (e-mail magic link or shop account) before selling. *Assumed: OK for the 2 prototype boards.*
3. **Haiku-first routing:** on or off? It saves money on easy photos, but hard ones are a few seconds slower because they're tried twice. *Assumed: off (`ROUTING=main`, always Sonnet 5.5) until you've compared costs.*
4. **Free tier:** how many free solves a day without a subscription, if any? *Assumed: 0 (off); the switch is `FREE_DAILY`.*
5. **Refusal fallback** (`REFUSAL_FALLBACK=1`): a beta API feature that lets another model answer if Sonnet 5.5's safety filter wrongly declines a homework photo. *Assumed: on. If your account rejects it (HTTP 400 on every solve), set it to 0.*
6. **The tester (`firmware/`) and both simulators still send your API key straight to Claude.** They are your own development tools, and `api_key.txt` stays git-ignored. *Assumed: OK. Only the board firmware is the product.*
7. **Wi-Fi is only on in AI SOLVE.** The first = after opening AI SOLVE may wait a few seconds for the hotspot (it joins while the photo is taken). *Assumed: worth it for battery life.*
8. **Self-test key combo:** SHIFT + ALPHA held, then ON. *Assumed: fine; it can't clash with SHIFT, 7, ON (exam mode).*
9. **Wake grace time:** after a key wakes the chip while it's off, it stays awake 4 s before sleeping again. That's what makes SHIFT, 7, ON and the self-test combo work. *Assumed: 4 s.*
10. **Memory when the battery is pulled:** memories, Ans and history live in RTC memory and are lost if the battery is unplugged (like the Casio). Storing them in flash on every power-off would keep them. *Assumed: RTC only. Exam mode is in flash.*
11. **AI low-battery cut-off:** 3.6 V on battery (review S2/S4). *Assumed: 3.6 V; `kAiMinMillivolts` in `core/battery.h`.*
12. **Battery calibration:** compare `status` mV with a meter on TP6 (BAT+) once, then set `kBatteryCal` in `firmware-prototype/src/power.cpp`. *Assumed: 1.00 until measured.*
13. **TCA8418 RESET isn't wired to the ESP32** (R16 pull-up only). The firmware re-writes the chip's registers at every start, and a hung scanner would need a battery pull. No free non-strap GPIO is left, so no change is proposed. *Assumed: OK.*
14. **Charging while off isn't shown.** Plugging the cable in doesn't wake the chip (VBUS_SENSE isn't an RTC pin). Charging still works, and the icon shows at the next ON. *Assumed: OK.*
15. **Sleep current must be measured on the first board** (bring-up step 2 in FIRMWARE_STAGE13.md). Target ≤ 40 µA with RT9080 and R20 → VBUS_SENSE. If it's higher, send me the number.
16. **Web simulator:** rebuild it (`sim/web/build.sh`) to get tutor mode and the ✓/⚠ check there too. *Not done here: no Emscripten on this PC.*

## CAD (3-part shell + slide case)

Rev C2 (2026-10-05): the body is modelled as **two parts** (silver faceplate + navy back cover) plus the **navy slide case** as a separate accessory. Details: `enclosure/final_assembly/assembly_report.md` section 7, `slide_case_mods.md`, `window_mask.md`. Each item says what the model assumes now.

1. **Side profile photo, please (most useful).** Lay the closed calculator on its long side next to a ruler and photograph it straight on, both long sides. It shows where the navy wall starts to rise and how high it goes. *Assumed: the split line ramps from the rim at about the small ring (51 mm below the top) to 9.8 mm high at the big ring (74 mm below the top), then stays at 9.8 round the keypad and the bottom end.*
2. **Is there a groove along the long sides** (where the case's edges would ride)? A close-up photo of one long side edge, with the case off, would settle it. *Assumed: a shallow groove 1.0 tall, 0.35 deep, 5.9-6.9 mm up from the back, along both long sides. None of the photos so far shows one, so it may not exist (the case may just grip the body's edges).*
3. **Photos of the hard case:** inside (looking into it), both long edges close up (the lips / rails), both ends (is one end open? is there a finger notch?), and one from the side. *Assumed: open end at the display end, closed end at the key end (Casio's manual: "slide its hard case downwards to remove it"), wall 1.0, floor 1.2, 0.3 clearance, no notch.*
4. **Case size with calipers:** outside length × width × depth, wall and floor thickness, and how far the edge lips stick in. *Assumed: 162.3 × 81.9 outside, floor inside face 0.3 above the key tops when stored.*
5. **Faceplate skirt depth:** with the back cover off, how far does the silver part's edge go down below the face in the keypad section (calipers from the face to the bottom of the silver edge)? *Assumed: 3.0 mm (to Z 8.3; the face is at 11.3).*
6. **Navy wall thickness low down** in the keypad section (calipers across the wall about halfway down)? C5 = 0.8 was probably at the top edge. *Assumed: 0.8 the whole height.*
7. **Snap tabs:** the photos show small clips ("III" marks) in the middle of the top and bottom ends of the silver part. *Not modelled; harmless for the fit, but tell me if they matter to you.*
8. **Window mask:** after the first test, is any white edge visible on one side? *Assumed: Waveshare's active area 48.55 × 23.70, centred where the KiCad keep-out says; trim 0.2 mm from that side of the opening if needed.*
9. **Will you ever drill the case?** Only matters later: it covers the camera in use (8 mm hole, `slide_case_mods.md`). The magnet stays clear in both positions.

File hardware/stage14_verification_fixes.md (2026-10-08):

# Stage 14: fixing the 4-part verification findings

Date 2026-10-04. Board v14 (silk "AI CALC v14 2026-10-04").

**Final state:**
- DRC: **0 errors, 0 warnings, 0 unconnected, 0 schematic-parity issues** (`kicad-cli pcb drc --refill-zones --schematic-parity --severity-all`, KiCad 10.0.6).
- ERC: **0**.
- Every copper item is ≥ 0.25 mm from every hole.
- Unit tests: 548 passed, 0 failed.
- Firmware: clean PlatformIO build, 0 warnings.

**Where things are:**
- Backup of the stage-13b board and schematic: `kicad/.mcp-backups/stage14_pre/`.
- Zip: `Claude outputs/ai_calc_pcb_14.zip`.
- How to order: `ORDER_WALKTHROUGH.md` (short version: `ORDER_CHECKLIST.md`).

Each section below goes finding → fix → how it was verified.

---

## 1. J3 magnet pin order (verification 03 F1, FATAL)

**The finding.** The #5412 cable fixes the contact order, and J3 was wired VBUS, GND, D−, D+. That matched the cable in neither of the two ways the magnet piece can be fitted:
- One way gave no USB.
- The other way put 5 V on D+. That is what the old "turn the piece over if mirrored" advice would have done.

**Re-derived independently:**
- **Adafruit #5412 drawing** (`5412_C17238_4P.pdf`, downloaded from Adafruit; text positions read from the PDF and checked on the render):
  - The face reads **N, − (GND), D+, D−, + (VBUS), S**.
  - Each label has a leader line to its own pogo pin.
- **#5358 drawing** (`geometry/adafruit_5358_MG04254FRA1S1N.pdf`): N and S magnets at the two ends, with 4 contacts at 2.5 mm pitch in a line between them. It gives no pin functions, so the order has to come from the cable.
- **The mirror logic:**
  - The two faces meet face to face. Opposite poles attract, so the cable's N end sits against the board piece's S end.
  - Each contact touches the contact directly opposite it, so positions along the line are kept.
  - So the board piece, read from **its own N end**, is **VBUS, D−, D+, GND**.
  - The legs come straight out behind their contacts, so the leg order is the same.

**The fix:**
- **Order:** J3 = **1 VBUS, 2 USB_DM, 3 USB_DP, 4 GND**, with the piece's **N end at pin 1**. This is exactly the order in the brief.
  - Power and ground are the **outer** pins.
  - A piece glued in backwards gives VBUS↔GND and D+↔D−. D7 clamps the reversed supply and the host port current-limits. 5 V can never reach a data line.
  - No order can make a backwards fit harmless, because the cable itself has power at one end and ground at the other. That's why the meter check before gluing stays mandatory.
- **Schematic** (`connectors.kicad_sch`): the three J3 net labels were swapped, and the value now reads "N end at pin 1: VBUS D- D+ GND".
- **Board:**
  - Pad nets updated.
  - USB_DM: pad 2 → new via (127.3, 74.0) → the existing B.Cu path.
  - USB_DP: pad 3 → the existing via (129.8, 73.1).
  - The old DM via sat under the new DP pad, so it was removed.
  - D+/D− still run as a side-by-side pair into the USBLC6 (U7) and on to the ESP32.
  - Pad 4 now joins the GND pour, plus a stitching via at (131.31, 69.0) under the J3 body.
- **Silk** (F.Silkscreen, off the pads): **"N"** and **"+"** beside pin 1, **"−"** beside pin 4.
- **Dangerous advice removed** from:
  - `QUESTIONS_AND_ISSUES.md` (Heights #7)
  - `REVIEW_final_2026-10-04.md` (walkthrough step 10)
  - `stage13_heights.md` §3
  - `ORDER_CHECKLIST.md`
  - `stage2_electrical.md`
  - `pins_final.h` (`MAG_PIN_ORDER`)

  It's replaced by a multimeter procedure on the real cable before gluing (`ORDER_WALKTHROUGH.md` → "Magnet piece"):
  1. On a phone charger, find the +5 V leg and check the inner legs read ~0 V.
  2. Unpowered, beep VBUS/GND to the outer USB-A contacts and D−/D+ to USB-A pins 2/3.
  3. Fit the +5 V leg in pin 1 and the GND leg in pin 4.
  4. Beep pin 4 to TP4.

**Verified:**
- Netlist (kicad-cli): J3 1 VBUS, 2 USB_DM, 3 USB_DP, 4 GND. U7 is unchanged (1/6 D+, 3/4 D−).
- Pad dump from the board matches. DRC 0/0/0 with parity. ERC 0.
- A render of the corner shows the silk marks and the GND thermal spokes on pad 4.
- Not changed: the magnet contacts still carry only VBUS/GND/D± (D1, Q2 and R20 are untouched).

---

## 2. CPL rotations (verification 04 M1/M2, FATAL)

**The finding.** JLCPCB places parts using EasyEDA footprints with different zero angles. Seven SOT parts and J3 would have gone on wrong.

**The fix (permanent):**
- New `tools/jlc_cpl.py`, run by `tools/make_outputs.sh`. The BOM is now generated first.
- It holds a rotation-offset table **per LCSC number**:

  | Offset | Parts |
  |---|---|
  | +180 | C15127 (Q1/Q2), C53099 (U4), C53100 (U5), C46061768 (J3) |
  | +270 | C424093 (U2), C841192 (U3), C7519 (U7) |
  | 0 (listed explicitly) | every other polarised part |

- It expands the BOM's "C32-C34" ranges, and refuses to write a CPL if a part has no LCSC number.

**The result in `fab/ai_calc_CPL_JLCPCB.csv`:**

| Part | Rotation |
|---|---|
| Q1 | 0 → 180 |
| Q2 | 90 → 270 |
| U2, U3, U7 | 0 → 270 |
| U4, U5 | 0 → 180 |
| J3 | 0 → 180 (the J3 change didn't move the footprint, so this still holds) |

It is identical, all 77 rows, to verification 04's hand-corrected CSV.

**Independent check** (`tools/check_cpl_easyeda.py`):
- Every polarised or multi-pin part's EasyEDA footprint was fetched with `easyeda2kicad --footprint` (scratch venv).
- Each one was placed at the CPL position and rotation with KiCad's own transform, then compared with the board's pads.
- **Negative test:** with KiCad's raw rotations, the same check fails Q1, Q2, U2, U3, U4, U5 and U7 (pin 1 2.1–3.1 mm off), so it really discriminates.
- **J3's direction:** its 4 pads are symmetric, so pad matching can't tell 0° from 180°. At 180° the EasyEDA courtyard sits at y 60.9–69.5, over the top edge like the KiCad body (61.9–70.4). At 0° it would be at y 74.5–83.1, over D1/D6/U7.

| Ref | LCSC | EasyEDA footprint | CPL rot | EasyEDA pin 1 → KiCad pad 1 (mm) | worst same-number pad offset (mm) | every EasyEDA pad on a KiCad pad | Result |
|---|---|---|---|---|---|---|---|
| D1–D6 | C8598 | SOD-123…-RD-1 | 0 | 0.05 | 0.05 | yes | PASS |
| D7 | C193402 | SOD-123FL…-RD | 180 | 0.18 | 0.18 | yes | PASS |
| J1 | C6364666 | FPC-0.5-24P-HYH2.0 | 180 | 11.50 | 11.50 | yes | PASS: pin numbers intentionally mirrored (CamReversed), geometry exact |
| J2 | C6364666 | FPC-0.5-24P-HYH2.0 | 270 | 0.00 | 0.00 | yes | PASS |
| J3 | C46061768 | HX-PM2.54-1X4PWT | 180 | 7.62 | 7.62 | yes | PASS: 4 identical contacts; body direction checked separately (above) |
| J4 | C295747 | S2B-PH-SM4-TB | 0 | 0.00 | 0.00 | yes | PASS |
| L1 | C135265 | SMNR4020 | 180 | 0.00 | 0.00 | yes | PASS |
| Q1 | C15127 | SOT-23…-BR | 180 | 0.21 | 0.21 | yes | PASS |
| Q2 | C15127 | SOT-23…-BR | 270 | 0.21 | 0.21 | yes | PASS |
| Q3 | C469327 | SOT-323…-BR | 0 | 0.00 | 0.00 | yes | PASS |
| U1 | C3013941 | ESP32-S3-MINI-1 | 90 | 0.02 | 0.03 | yes | PASS |
| U2 | C424093 | SOT-23-5…-BL | 270 | 0.01 | 0.01 | yes | PASS |
| U3 | C841192 | TSOT-23-5…-BL | 270 | 0.01 | 0.01 | yes | PASS |
| U4 | C53099 | SOT-23-5…-BR | 180 | 0.16 | 0.16 | yes | PASS |
| U5 | C53100 | SOT-23-5…-BR | 180 | 0.16 | 0.16 | yes | PASS |
| U6 | C138713 | WQFN-24…-TL | 0 | 0.08 | 0.08 | yes | PASS |
| U7 | C7519 | SOT-23-6…-BL | 270 | 0.01 | 0.01 | yes | PASS |

The residuals of 0.05–0.21 mm are only pad-size differences between the two libraries.

**One caveat:** EasyEDA's API started returning HTTP 403 after the first batch, so all footprints came from one download into one folder. They were mapped to LCSC numbers by package name, which is unique except that U4 and U5 share the same "-BR" SOT-23-5. That matches verification 04's per-number download.

---

## 3. SW1 key pad vs hole H3 (verification 04 M3)

**The finding.** SW1's COL0 bottom bar (6.0 × 0.6 mm, B.Cu) was **0.055 mm** from the 6.0 mm NPTH hole H3. JLCPCB wants ≥ 0.2 mm, and the brief asked for ≥ 0.25 mm. KiCad's DRC doesn't check this pair.

**The fix.** New footprint `ai_calc:KeyPad_6.0x4.5_H3notch`, used by SW1 only (schematic and board):
- The 1.7 mm of the bar nearest H3 is thinned from 0.6 to 0.35 mm, with its edge pulled away from the hole. The rest of the bar and all 8 fingers are unchanged.
- The carbon dot (about 4.5 mm on this row, centred on the key) only reaches the bar near its middle. The removed sliver (x 173.6–175.3, y 122.8–123.0) is outside the dot, so the contact area is unchanged.

**Verified:**
- New `tools/check_hole_clearance.py` measures every copper item (pads, tracks, vias and zone fill, both layers) against every hole edge: NPTH against any net, plated holes and vias against other nets.
- Before the fix: 1 violation (H3/SW1 0.055 mm). That reproduces verification 04 exactly.
- After the fix: **0 violations board-wide**. Minimums: H1, H3, H4, H6, H8, H10 at 0.250 (the zone-fill rule); H2, H9, H13, H14 at 0.300.
- DRC is clean, including the library-footprint match.

---

## 4. Recovery procedure (verification 02 L1) and the R17 comment

**The finding.** "Hold BOOT to GND while plugging in" doesn't work while the battery is connected. The battery keeps 3.3 V and EN up, so plugging the cable in never resets the chip.

**The fix.** The procedure is corrected in `firmware/FIRMWARE_STAGE13.md` (step 3), `hardware/pins_final.h` and `hardware/stage2_electrical.md`:
1. Hold **TP1 (BOOT) → TP4 (GND)**.
2. Tap **TP7 (EN) → GND** for about 0.2 s (or unplug the battery at J4 first).
3. Release TP1 and flash.
4. Tap TP7 again to run the new firmware.

Also added:
- The UART backup on **TP2/TP3**.
- **"Never burn the security / USB-disable eFuses"** (DIS_USB_SERIAL_JTAG, DIS_DOWNLOAD_MODE, ENABLE_SECURITY_DOWNLOAD, secure boot, flash encryption).

**R17 discrepancy.** The brief (from verification 02 C12) said R17 is 10 k on the board. It isn't:
- The schematic, the BOM (C25741, "100k") and the board footprint all say **100 k**.
- Verification 03 agrees.

`pins_final.h` already said 100 k, so it already matched the board. The comment now names R17 and its LCSC number; no value was changed.

**Verified:** text review. R17 was confirmed in the schematic file, the netlist and the BOM.

---

## 5. fx-115ES key names (verification 03 L2)

**Checked against the photo** (`e59eff71`: the face plate with the keys out, so the SHIFT legends are readable):
- Row 2: SOLVE over **CALC**, d/dx over **∫dx**, x! over x⁻¹, Σ over log□□.
- Row 3: ∛ over √, x³ over x².
- Row 4: Abs over hyp.
- Row 5: STO over RCL, ← over ENG, % over "(".

**Hardware fix** (no wiring change, SW4 and SW5 stay at R1C6 and R1C7):
- SW4 value "Abs" → **"CALC"**, SW5 "x^3" → **"∫dx"**. Changed in `keypad.kicad_sch`, on the board (KEYPADS user-layer labels too), in `geometry/keys.csv` and in `derive_geometry.py`.
- There are no key labels on the silkscreen (B.Silk stays empty over the key pads).

**Firmware fix:**
- `core`: `DKey::Abs` → `DKey::Calc` and `DKey::Cube` → `DKey::Integral`. `keys.cpp kMatrix` keeps the same positions.
- **CALC / SHIFT SOLVE / ∫dx / SHIFT d/dx are not implemented.** They now show a "CALC (or SOLVE, ∫dx, d/dx) — Not supported yet — Press [AC] key" notice instead of doing something else.
- SHIFT layer per the 115ES:
  - **SHIFT hyp = Abs**
  - **SHIFT x² = x³**
  - **SHIFT √ = ∛**
  - STO, ←, %, comma, M−, x!, ˣ√, 10ˣ, eˣ, nPr, nCr: already the same.
- Still ignored, as before: ∠, ←, a b/c⇔d/c, Σ.
- The serial `b` shortcut is now SHIFT hyp.
- The web simulator page labels are updated. The built simulator files and the Windows exe need a rebuild (no Emscripten or MinGW here).

**Verified:**
- New test lines for SHIFT hyp → |−7| = 7, SHIFT x² → 2³ = 8, SHIFT √ → ∛27 = 3, and both notices.
- **548 passed, 0 failed.** The only golden change is the new `notice_calc` snapshot; the md5 of every other golden file is unchanged.
- `pio run` for `firmware-prototype`: clean build, 197 files compiled, **0 warnings**.
- The `firmware/` tester builds with 0 warnings, and the Windows simulator compiles.

---

## 6. Ribbon lengths (verification 03 L1 / L3)

No measurements had arrived yet: `measurements_2026-10-03.md` and QUESTIONS were checked. So I asked whether each suggested move is safe in **both** the short and the long case.

**J1, 2 mm towards the camera: not safe both ways, so left where it is.**
- **Short ribbon** (verification 03's reading: about 62 mm past the module, 1.4 mm spare): the move would help. But the camera isn't soldered, so the module can instead sit up to about 1.7 mm towards J1 inside its 12 × 12 keep-out, and the 7 mm window gets drilled after taping.
- **Long ribbon** (70.5 mm past the module): the move adds 2 mm to 10–12 mm of slack. A flat FPC can't bend sideways in the board plane, and an arch of that length would need several mm of height under ribs that leave 2 mm.
- The move would also mean re-routing the densest 0.5 mm-pitch fan-out on the board.
- **Decision rule:** measure the module from its far edge to the tip. If it's under about 70.3 mm, shift the module towards J1 (≤ 1.7 mm) and drill the window over the lens where it ends up.

**J2, 1 mm away from the slot: not safe both ways, so left where it is.**
- The ribbon length budget has no spare (14.3 = 14.3, stage 4). Moving J2 out would make the nominal and short ribbons too short. (Review 07, 2026-10-06: the Fusion path from the glass edge into J2 is 12.7 mm with 2 mm inside J2, i.e. about 1.6 mm nominal spare and 0.3 worst case; the no-spare rule stands.)
- **Decision rule** (measure the stiff end and E7, glass edge → tip):

  | Stiff end | E7 | What happens |
  |---|---|---|
  | ≤ 5 mm | any | no change |
  | > 5 mm | ≥ 15.3 mm | J2 moves +1 mm (board change before ordering) |
  | > 5 mm | < 15.3 mm | tell Claude before ordering |

The camera-cable text in `stage13_heights.md` §4 ("10 mm to spare, gentle S") is corrected.

---

## 7. Order documents

**`ORDER_WALKTHROUGH.md`** (new, replaces the walkthrough in REVIEW_final) covers:
- the corrected CPL;
- an expected-look table for every polarised part;
- **edge rails on the right and bottom edges only**;
- **"J1 pin numbering is intentionally reversed, don't rotate"**;
- the order-notes text to paste;
- an answer table for JLCPCB engineering emails (overhang intended, OK to pull back copper, J1, D7, slots, drill maps, substitutes);
- the expected cost: **about $135–160 before shipping, $165–225 delivered**;
- the after-arrival meter checks, including the magnet procedure.

Also:
- `ORDER_CHECKLIST.md` is rewritten to match.
- `REVIEW_final_2026-10-04.md` now carries a stage-14 note, and its old walkthrough is replaced by a pointer.

---

## 8. Regenerated outputs

**Extra fix found while regenerating: BOM designator ranges.**
- kicad-cli wrote ranged designators into the JLCPCB BOM ("C32-C34", "C5-C7", "C21-C30", "D1-D5"). JLCPCB expects plain comma lists, so those parts could have shown up as "not in BOM".
- `make_outputs.sh` now passes `--ref-range-delimiter ''`.
- Verified: the BOM lists 77 designators, exactly the CPL's 77.
- The stale copy `bom/ai_calc_BOM_JLCPCB.csv` (still showing the old 5 mm J3, C42379197) is refreshed from `fab/`.

- `fab/` via `tools/make_outputs.sh`: gerbers, drills, BOM, the corrected CPL, the schematic and assembly PDFs, `ai_calc_board.step` and the renders.
- `fitcheck/` via `tools/make_fitcheck.py`.
- `kicad/DESIGN_SUMMARY.md` via `kicad_summary.py`.
- Silk "AI CALC v14 2026-10-04".
- `Claude outputs/ai_calc_pcb_14.zip`.
- graphify updated.

## Left open
- The paper dry fit of the post holes (unchanged from stage 13).
- The ribbon measurements (decision rules above).
- The magnet meter check when the parts arrive (it's mandatory).
- The 85 % confidence in Adafruit's cable drawing (the meter check catches it if the drawing is wrong).
- Rebuilding the simulators.

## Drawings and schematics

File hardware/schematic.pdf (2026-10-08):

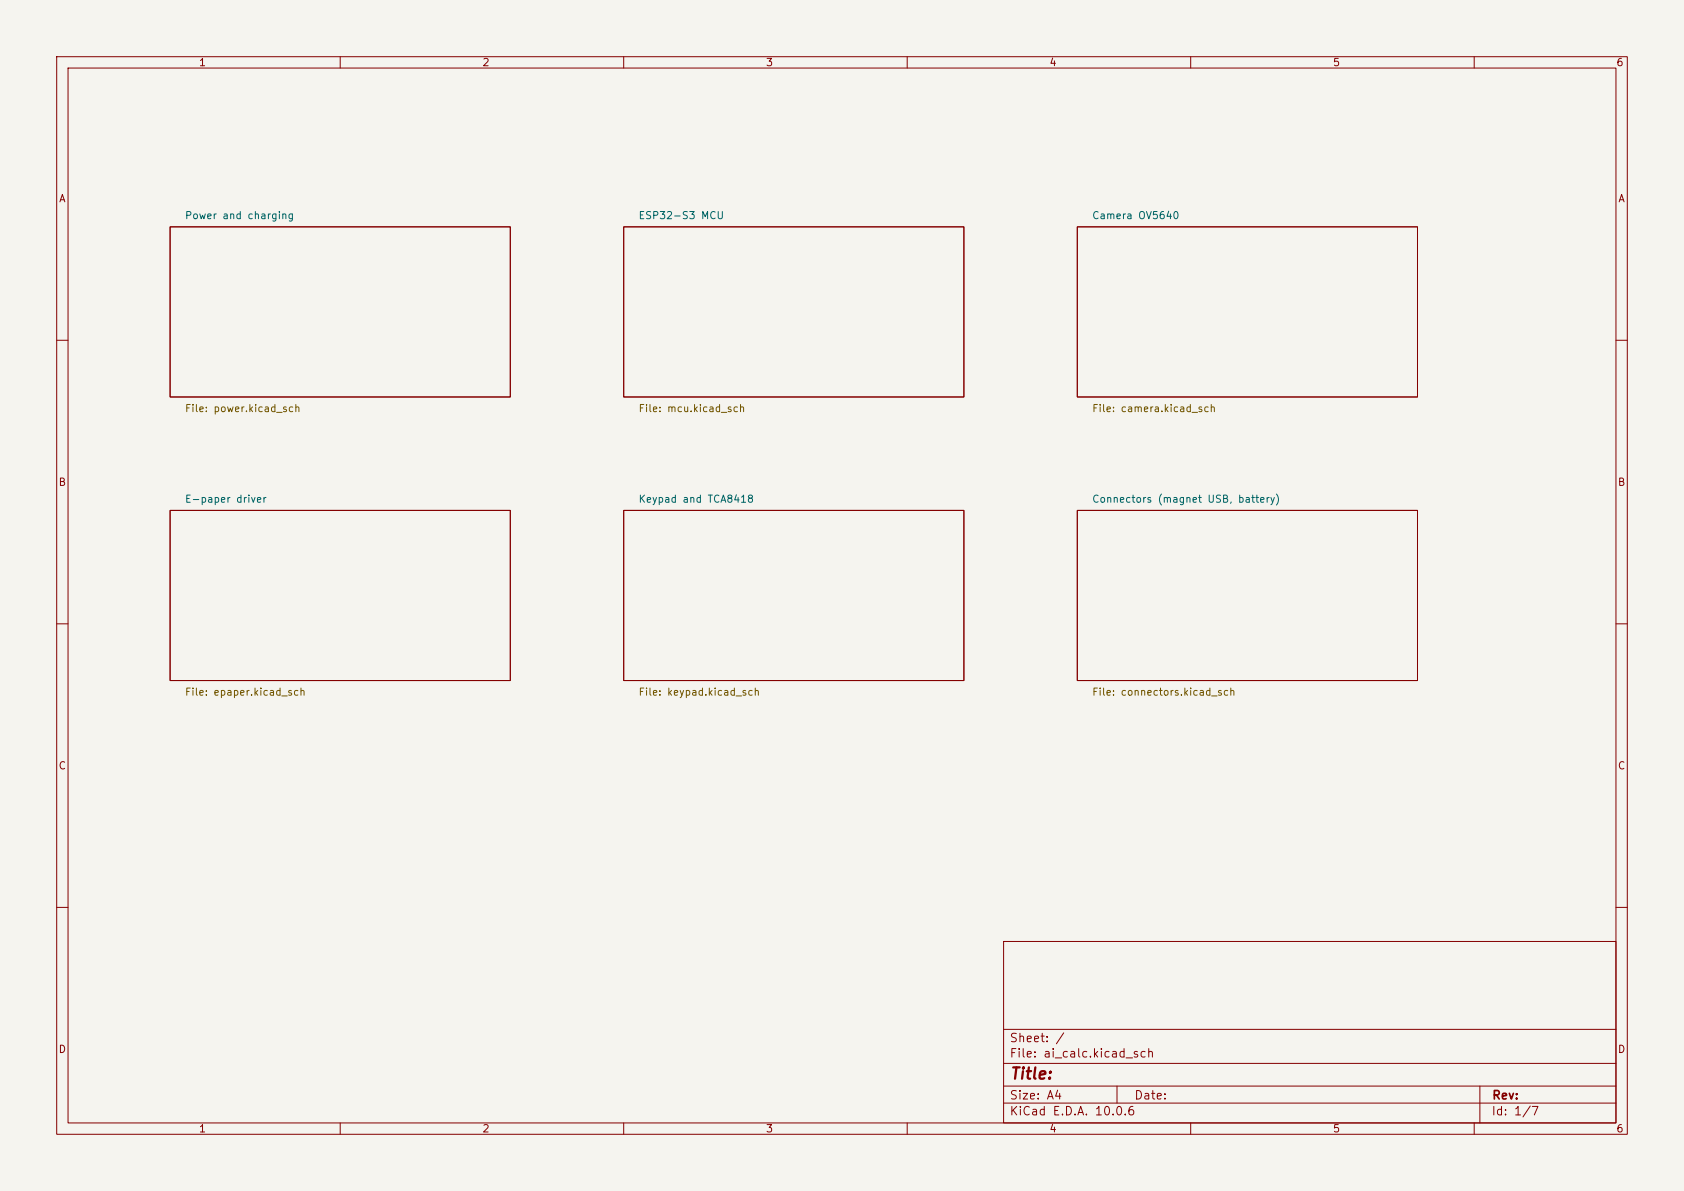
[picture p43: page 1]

E-paper driver File: epaper.kicad_sch

Size: A4 | Rev:
KiCad E.D.A. 10.0.6 | Id: 1/7

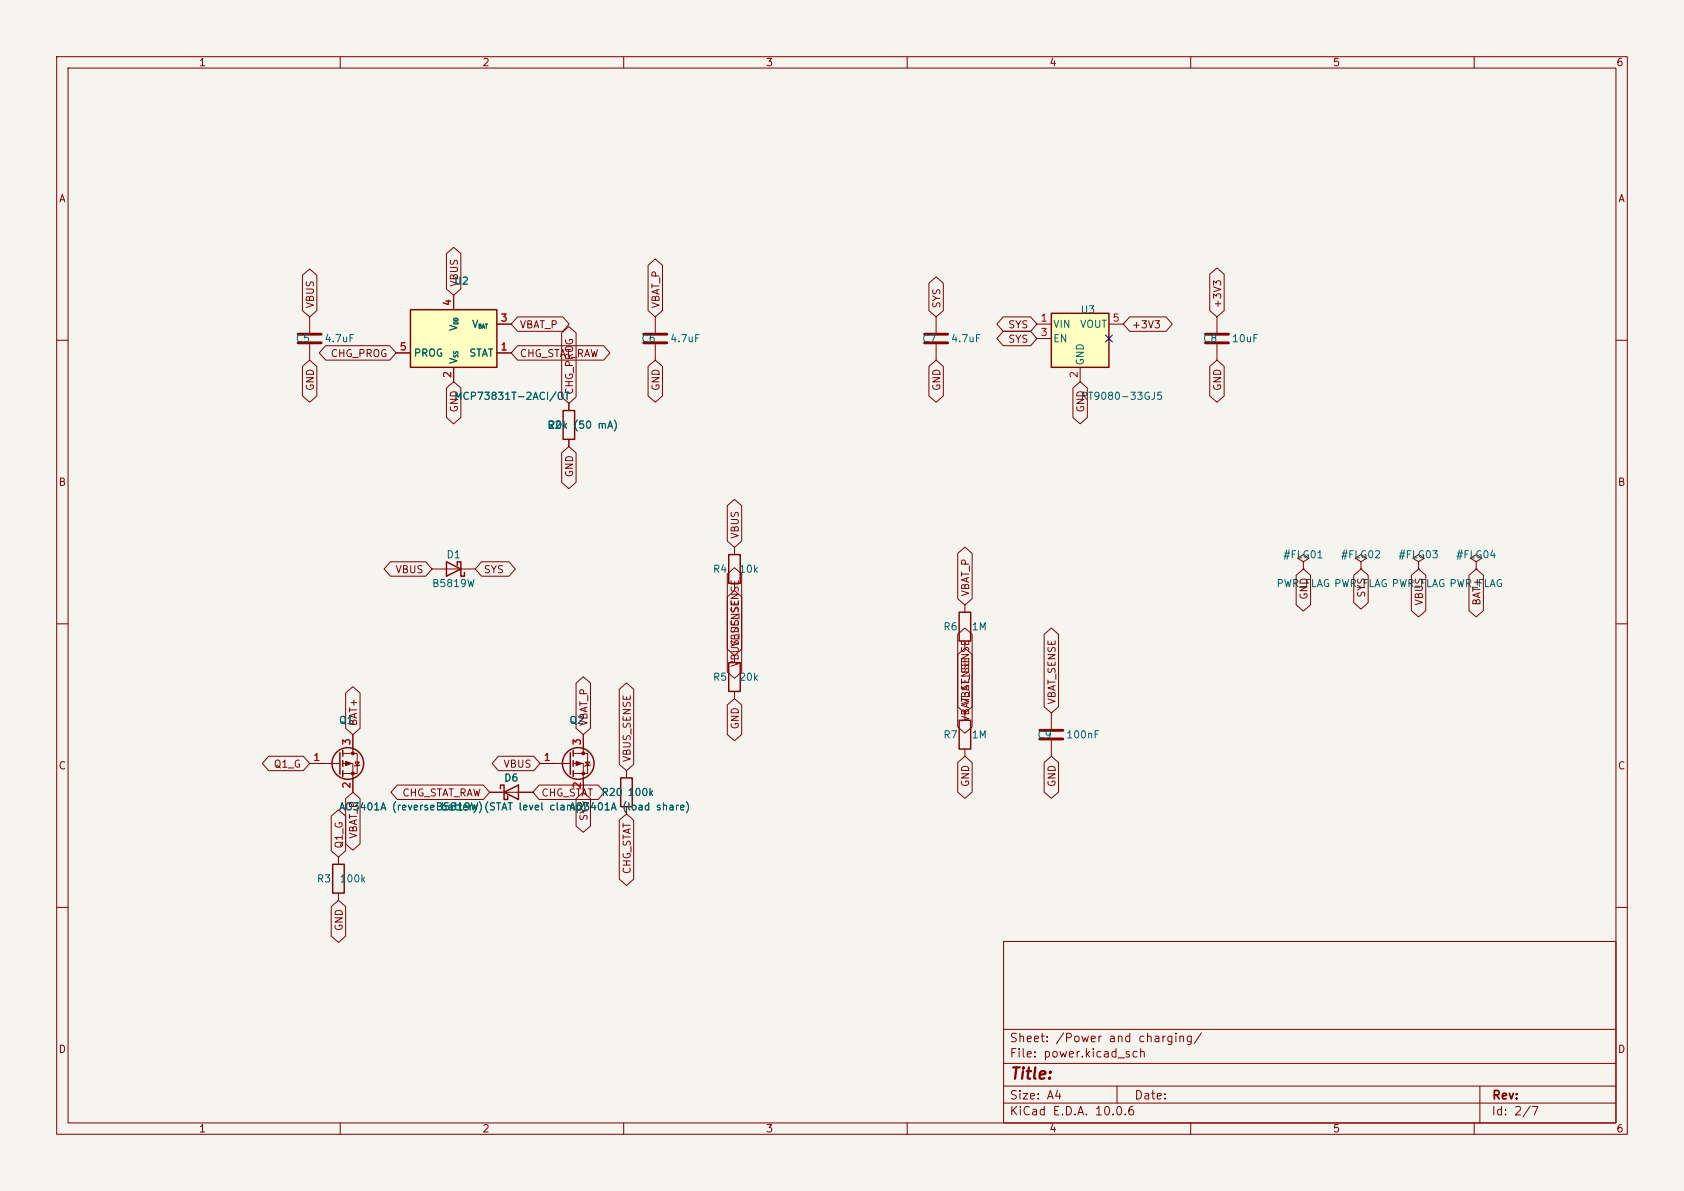
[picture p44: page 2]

Sheet: /Power and charging/
File: power.kicad_sch
Title:

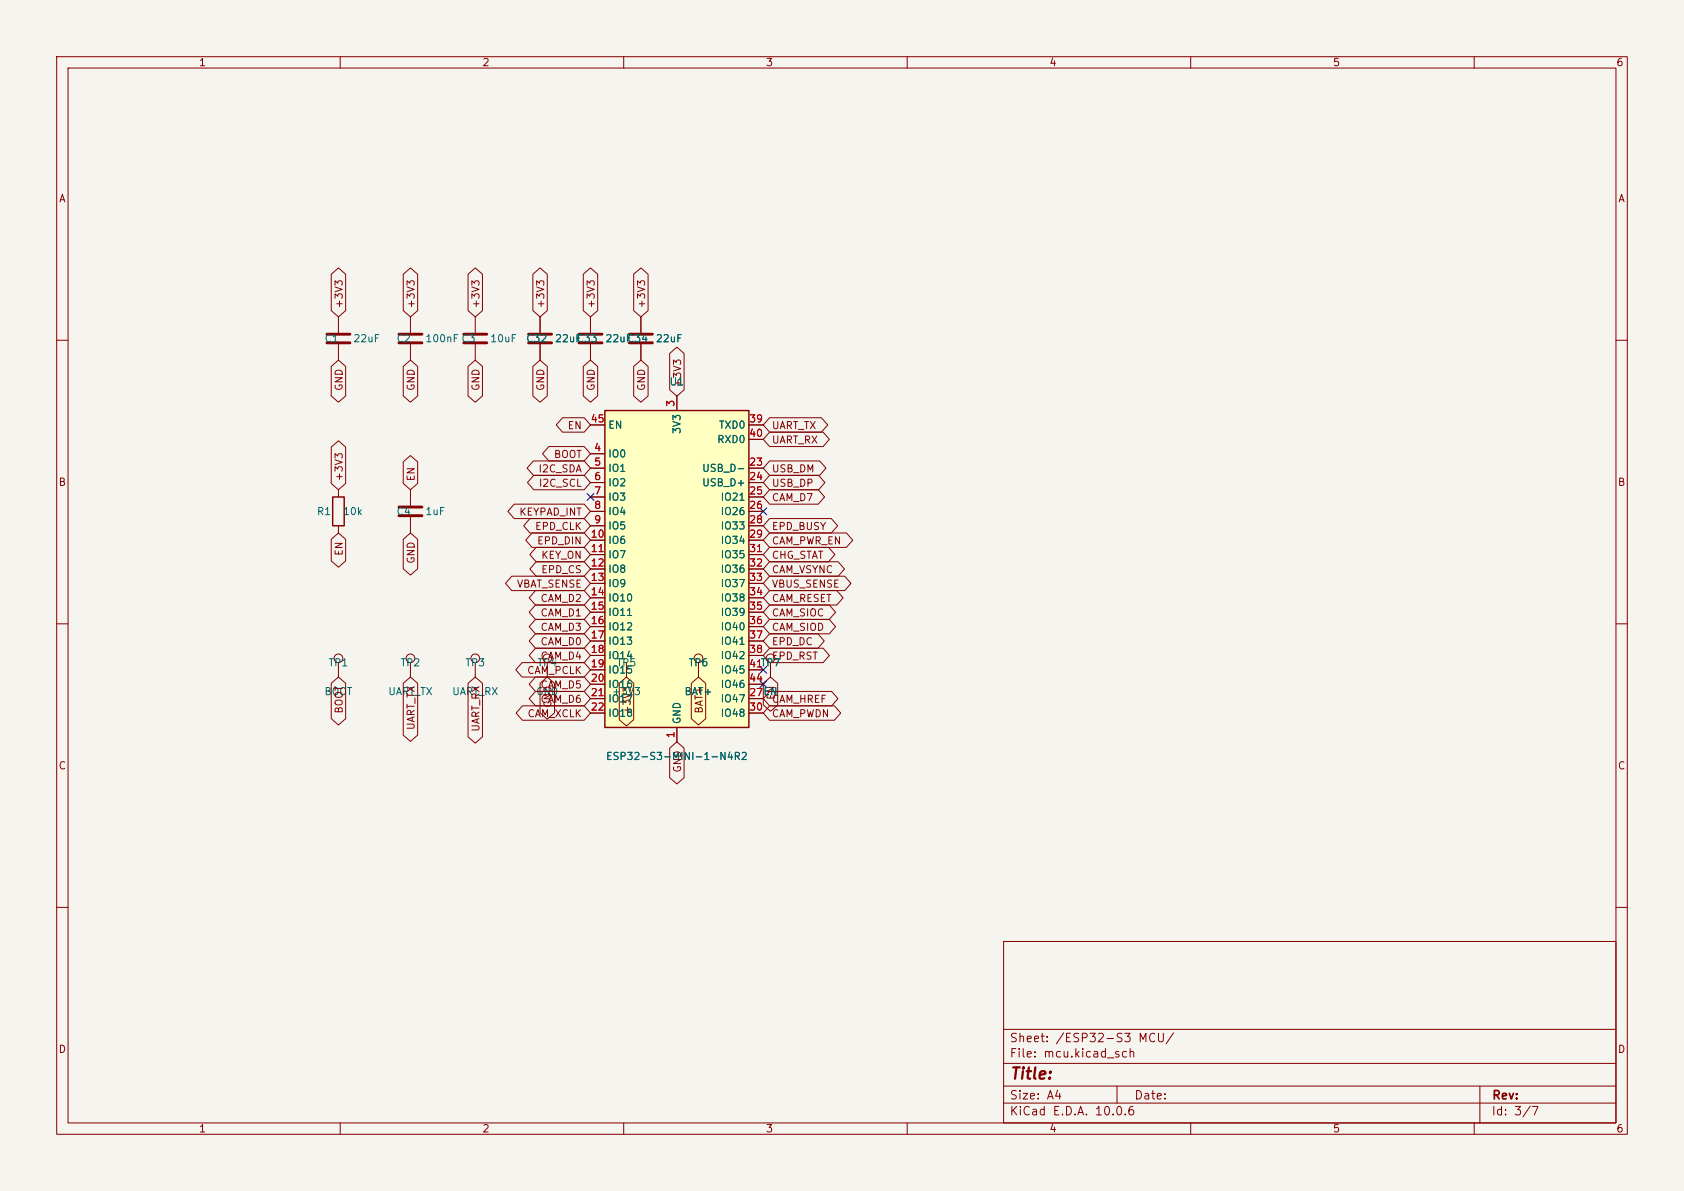
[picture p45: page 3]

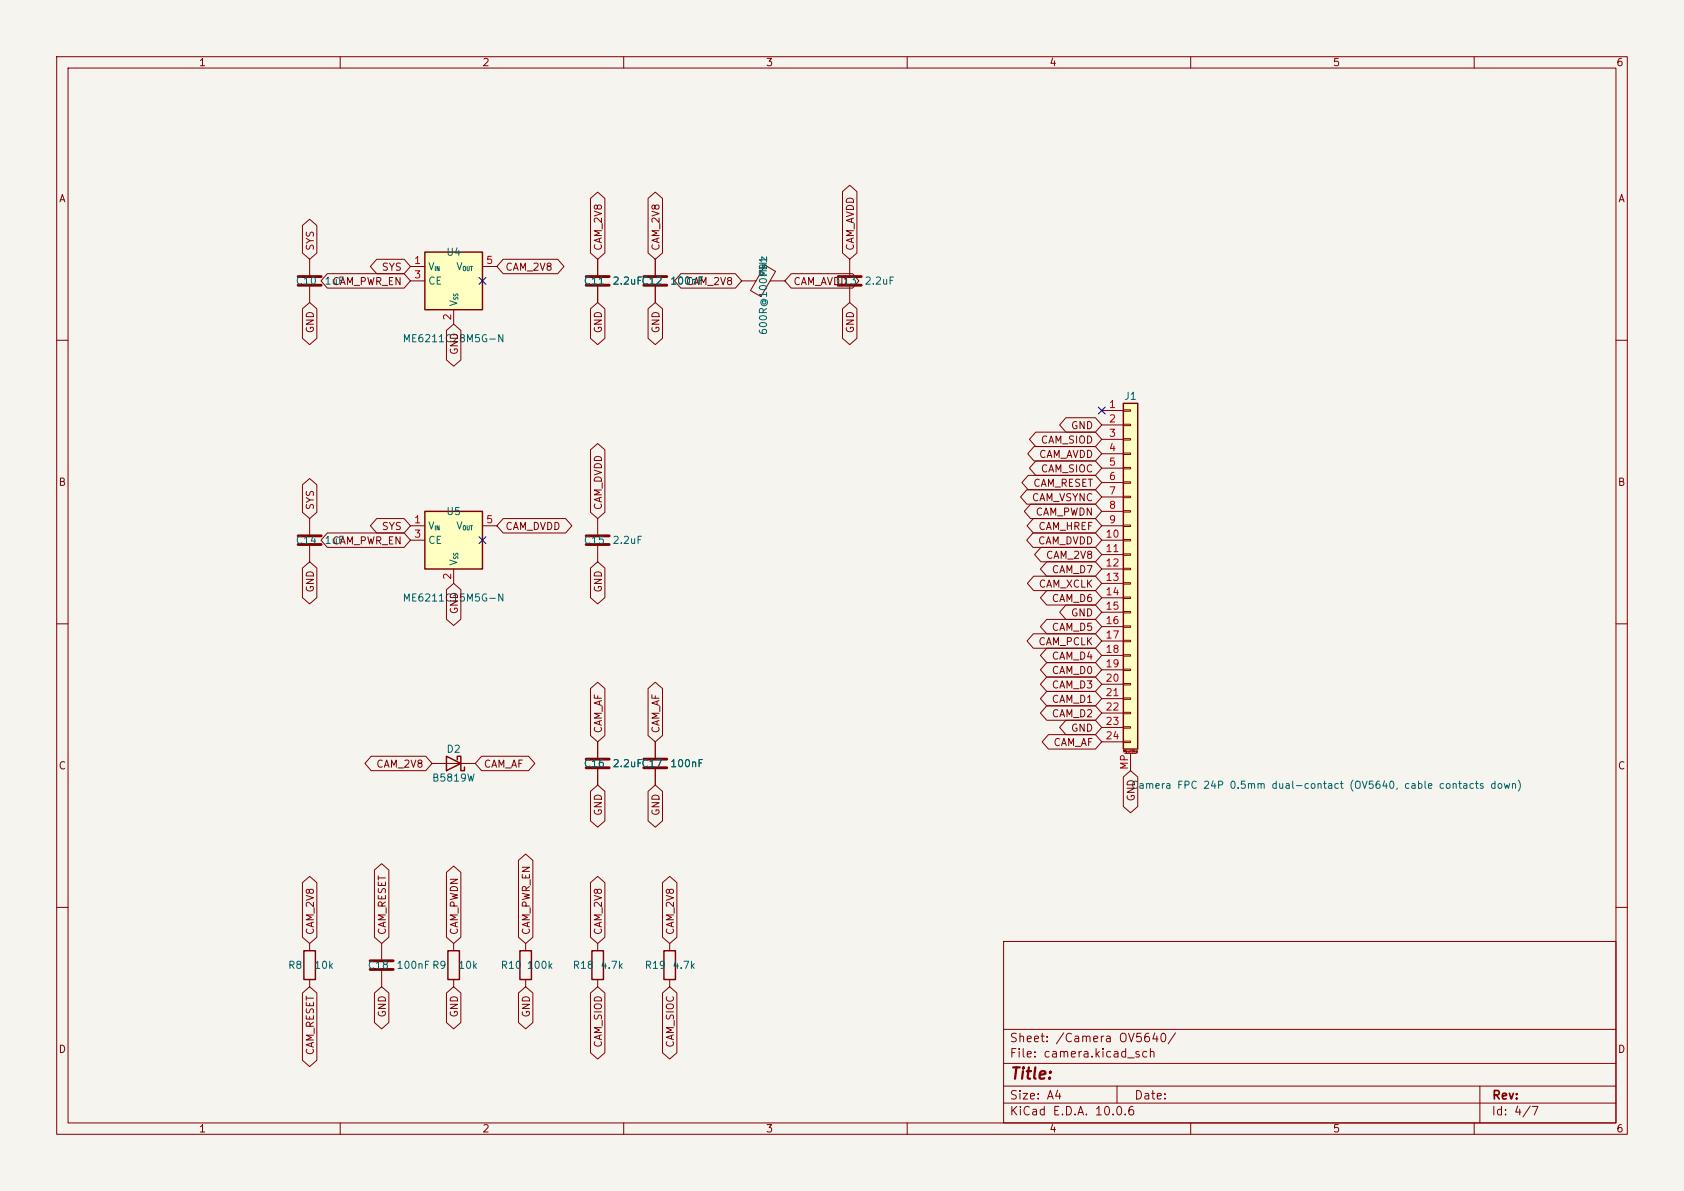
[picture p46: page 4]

J1Camera FPC 24P 0.5mm dual-contact (OV5640, cable contacts down)
Mounting 123456789

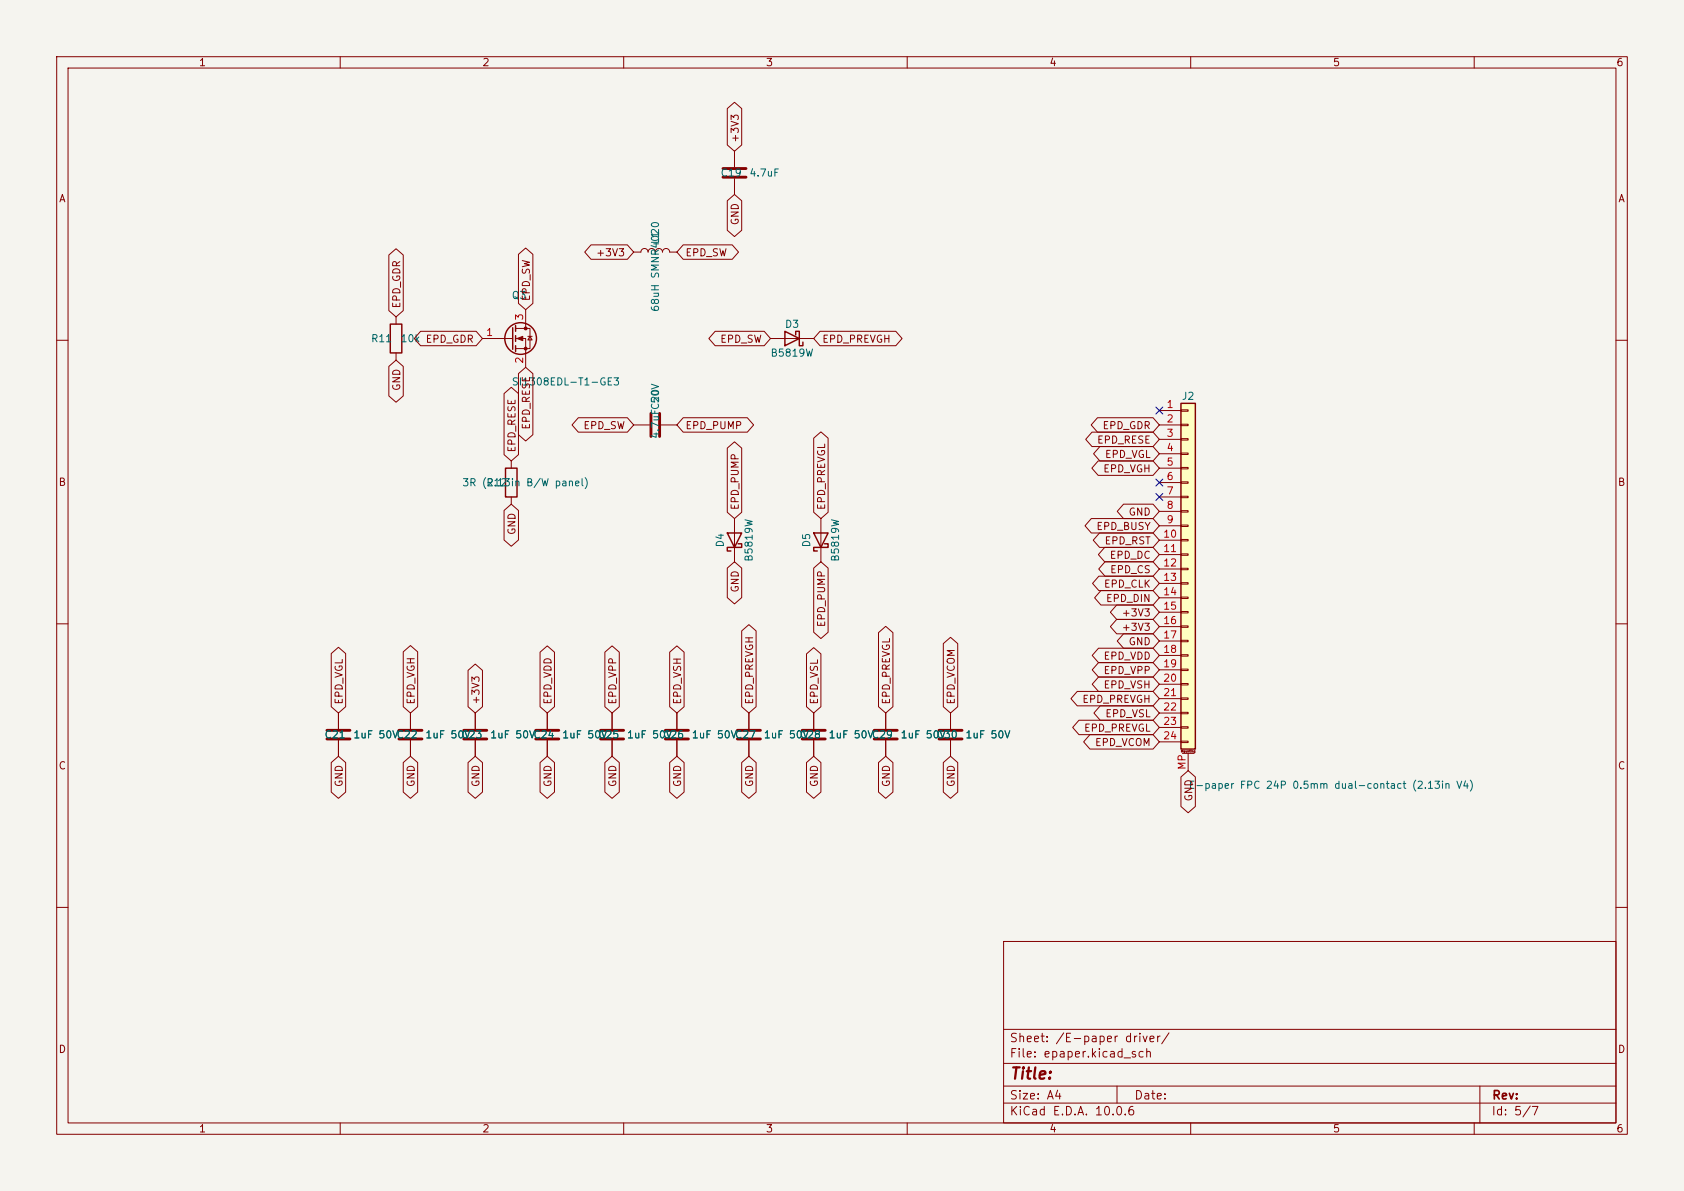
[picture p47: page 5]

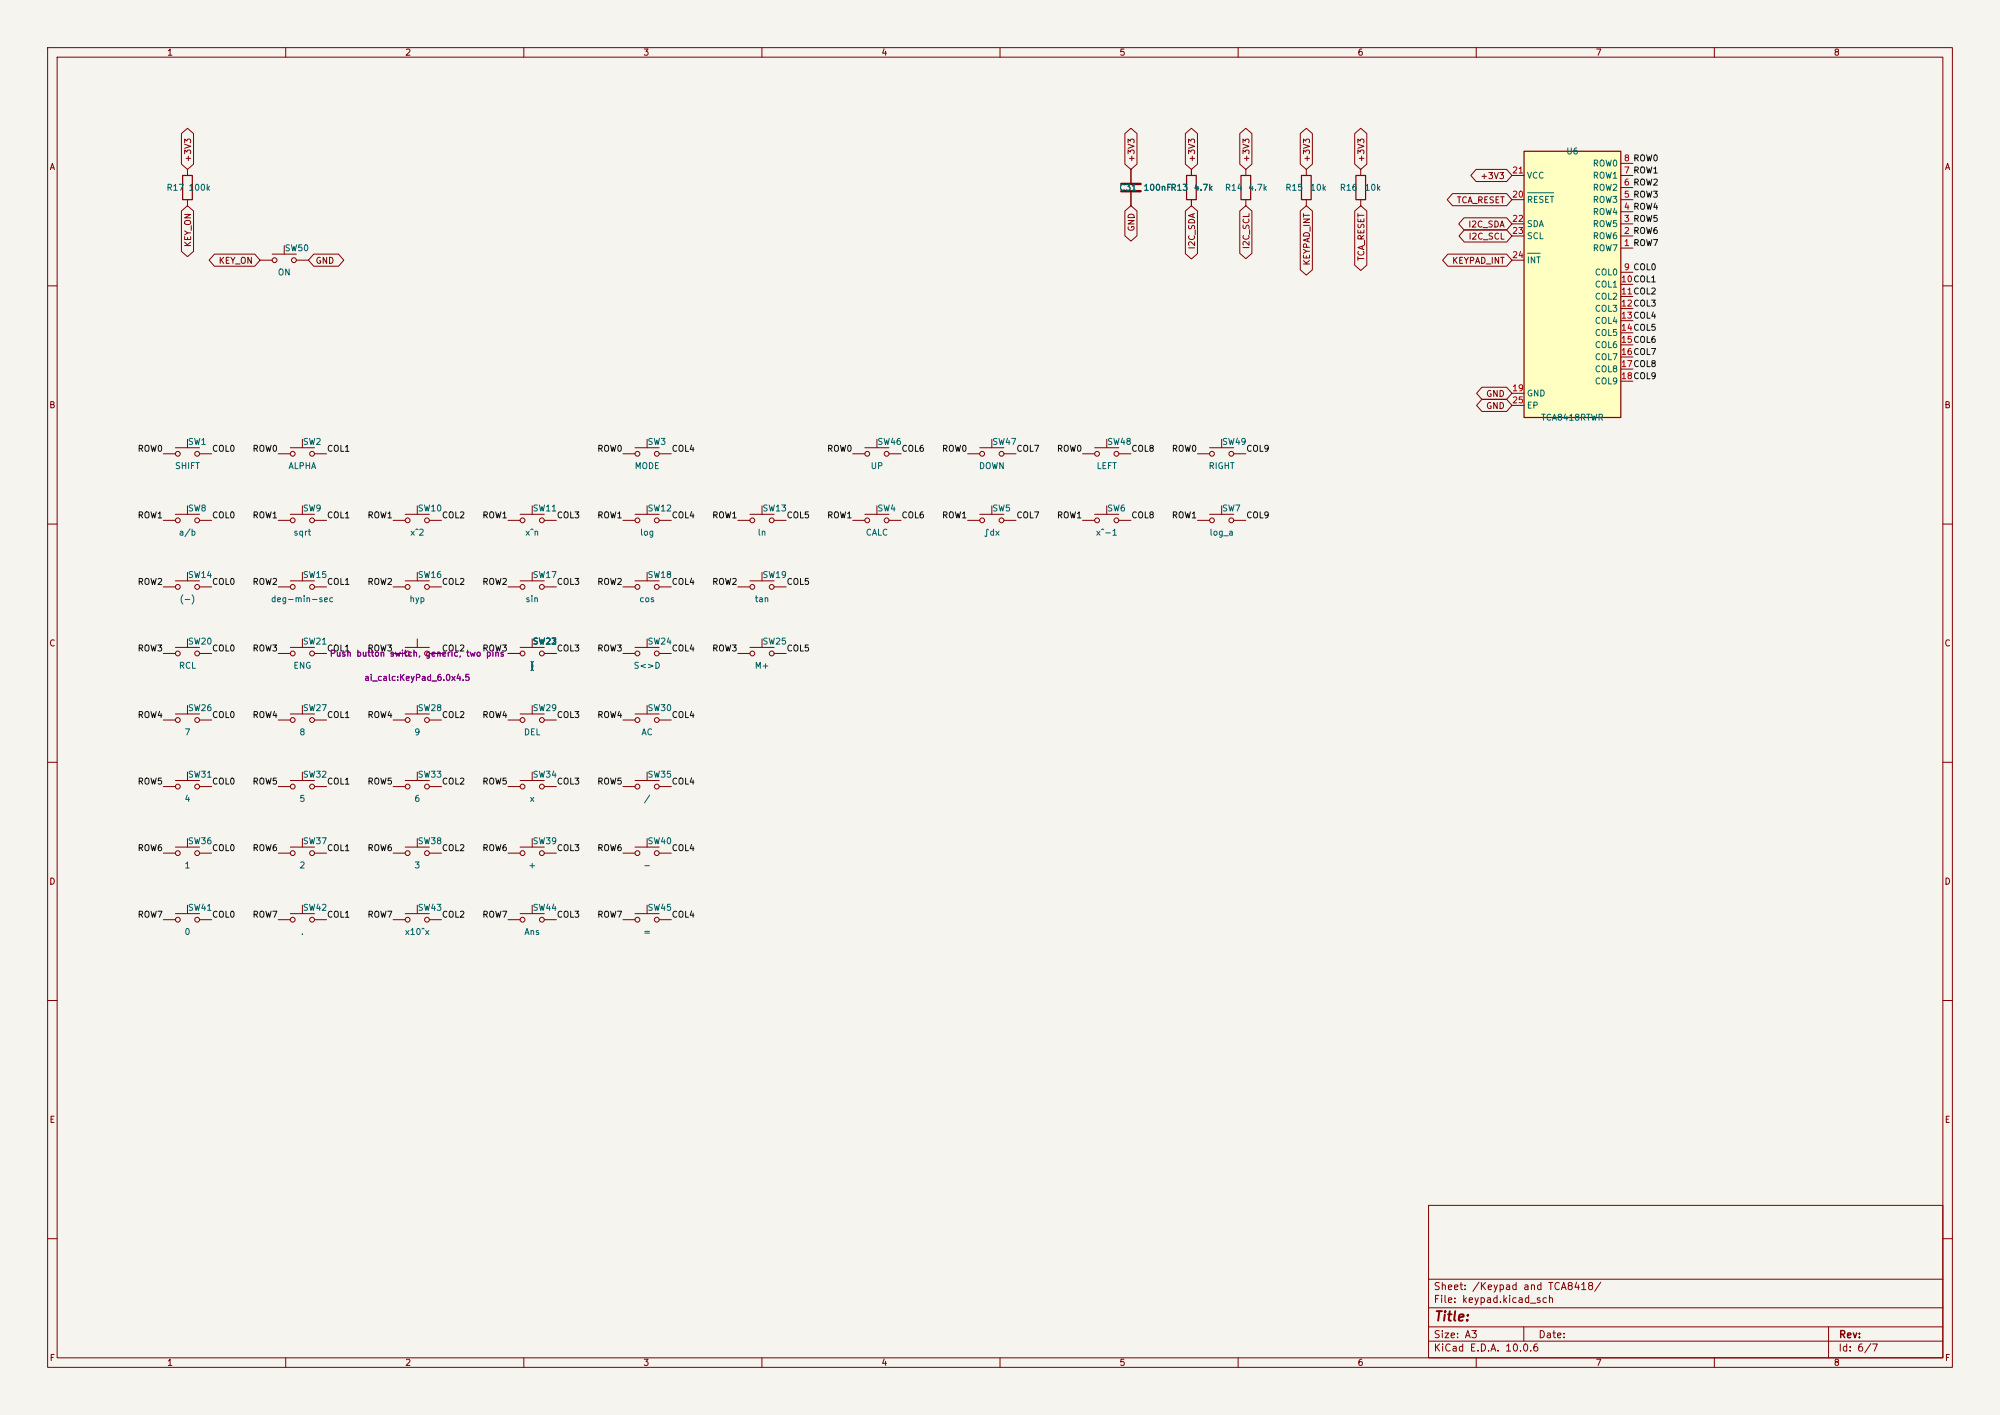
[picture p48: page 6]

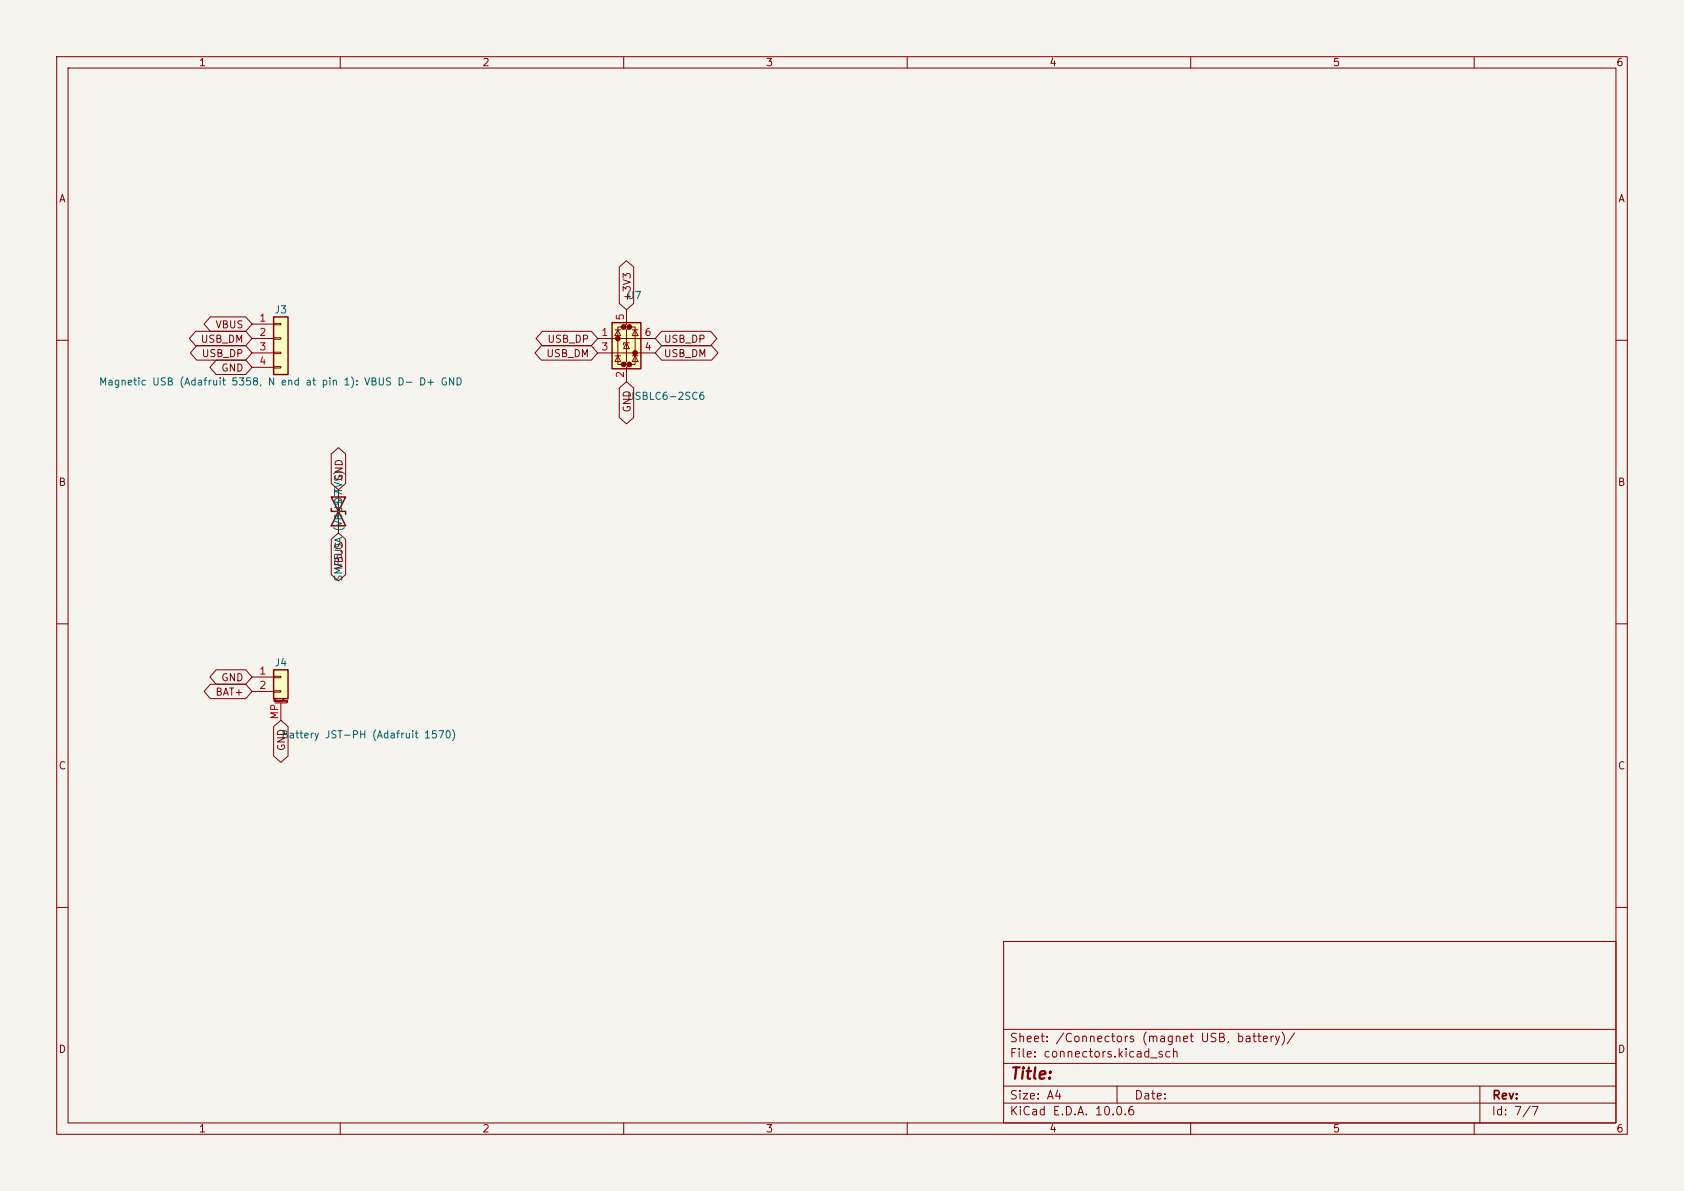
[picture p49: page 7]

Sheet: /Connectors (magnet USB, battery)/
File: connectors.kicad_sch
Title:

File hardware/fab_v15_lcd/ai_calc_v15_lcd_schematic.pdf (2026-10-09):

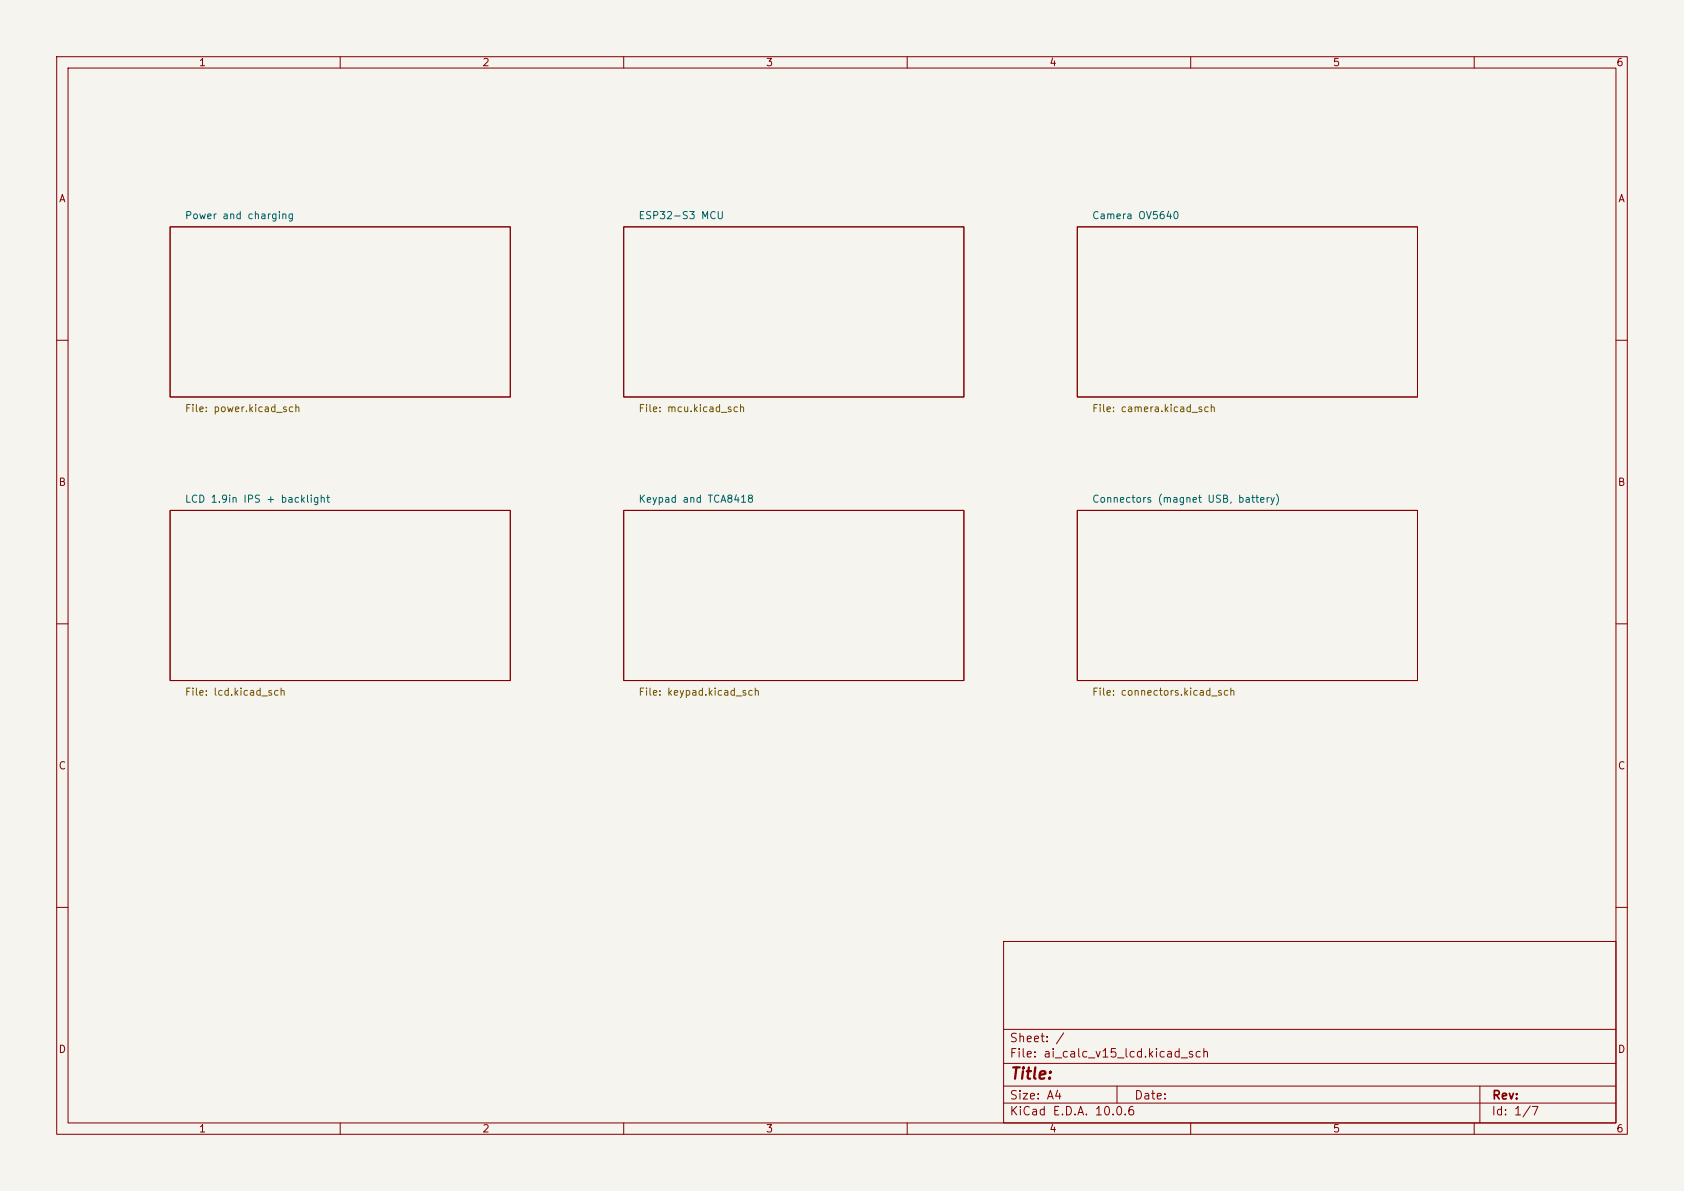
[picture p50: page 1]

Size: A4 | Rev:
KiCad E.D.A. 10.0.6 | Id: 1/7


Sheet: /Power and charging/
File: power.kicad_sch
Title:

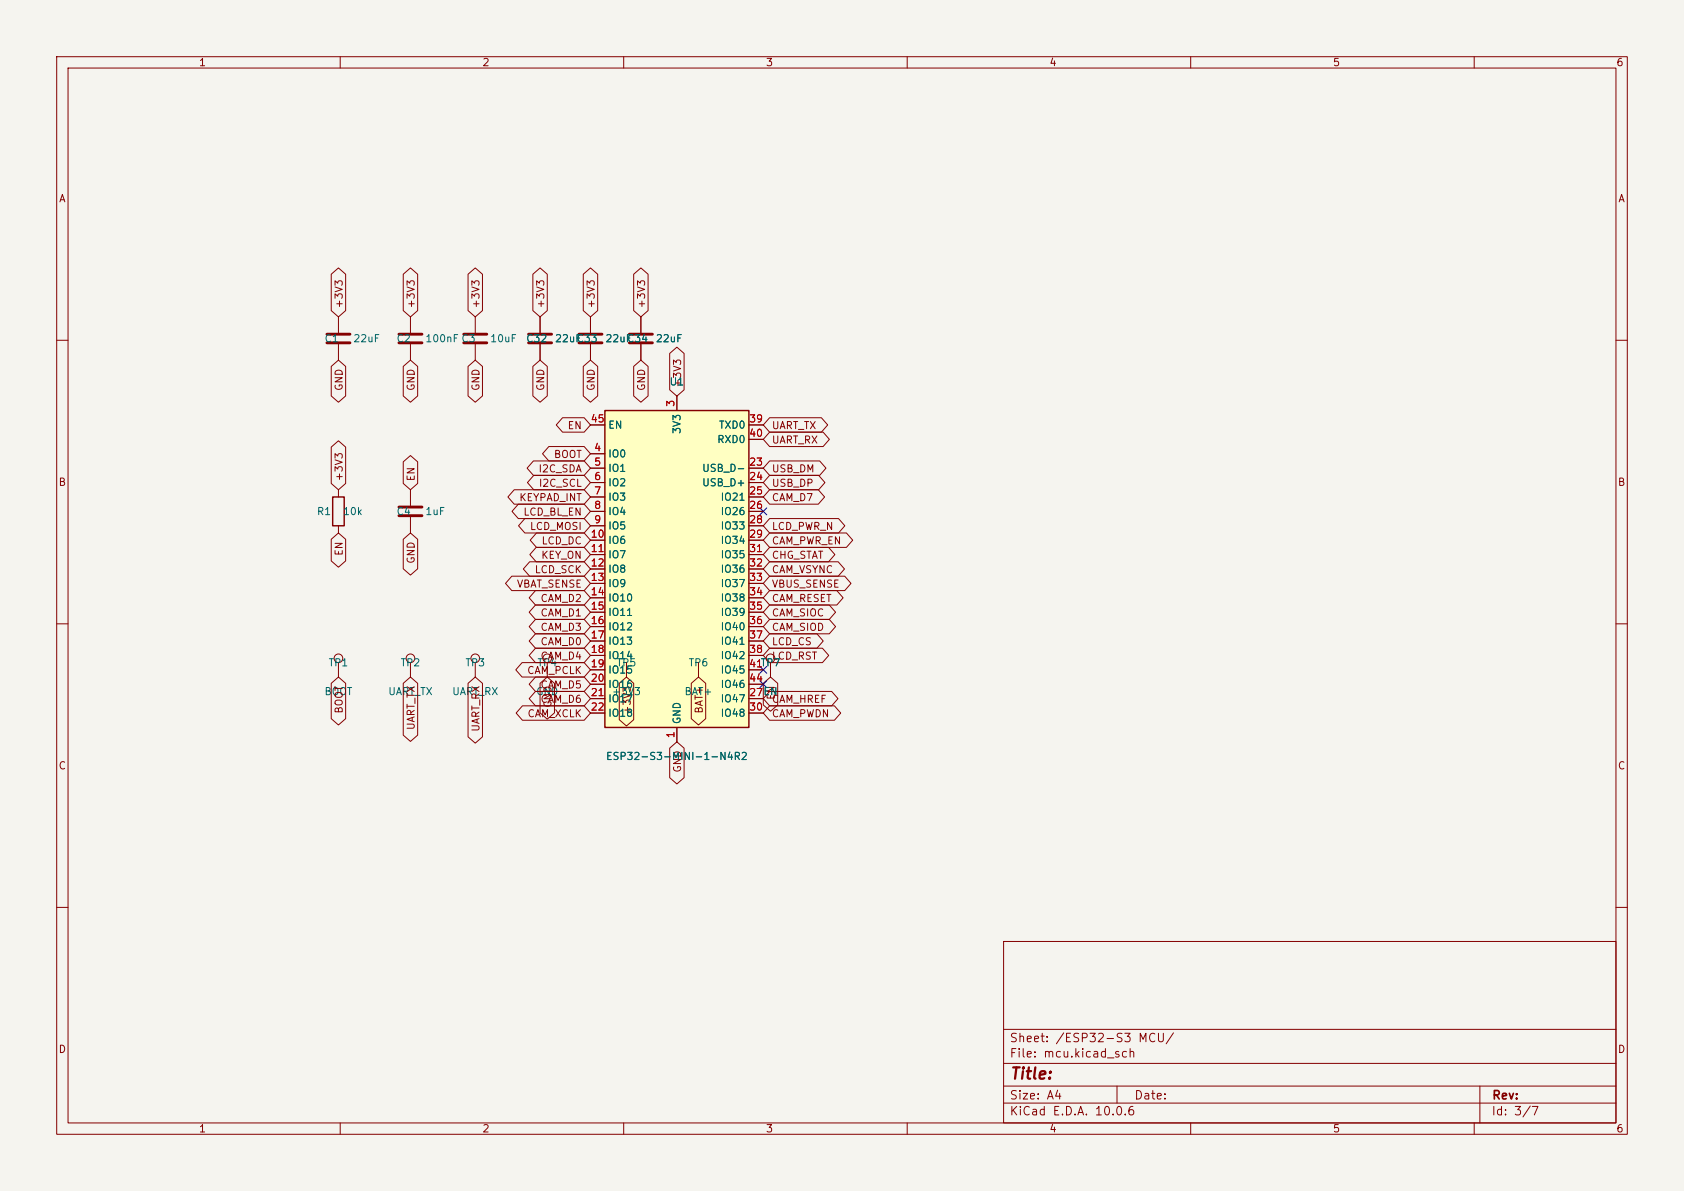
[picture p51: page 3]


J1Camera FPC 24P 0.5mm dual-contact (OV5640, cable contacts down)
Mounting 123456789

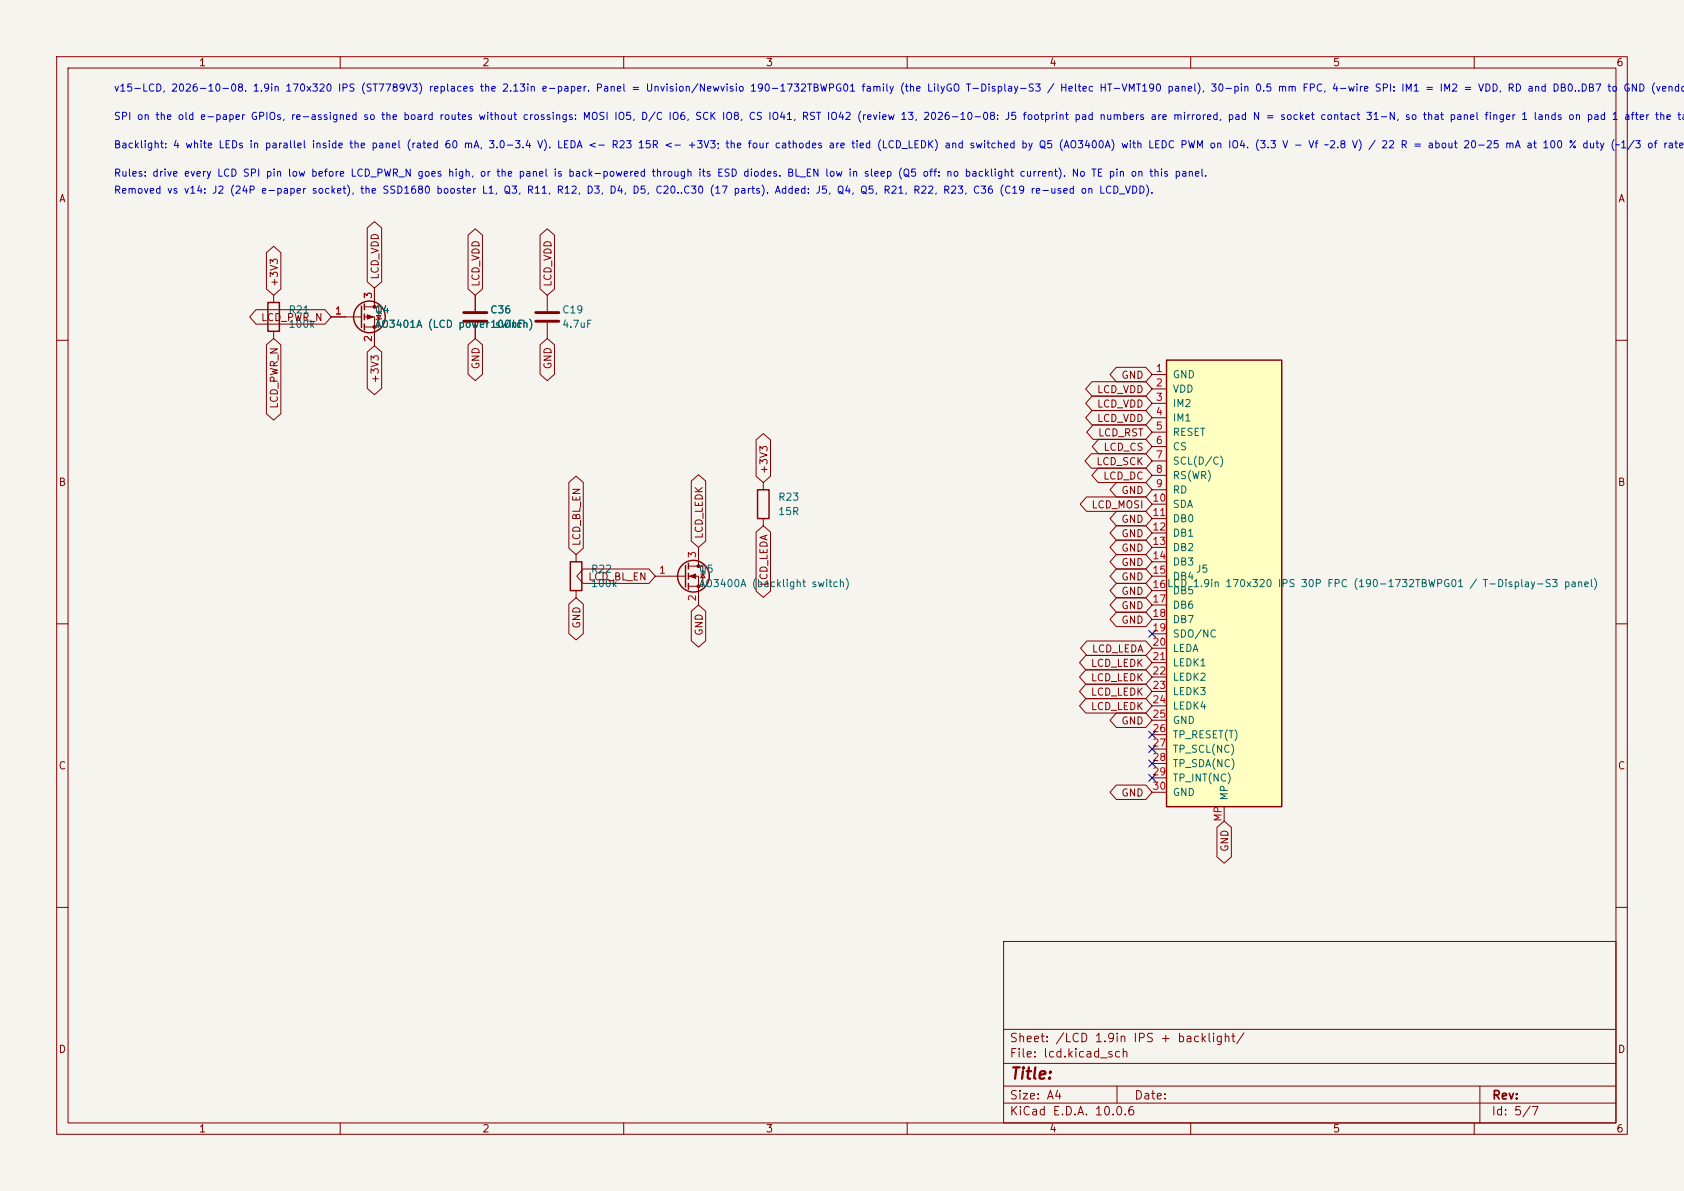
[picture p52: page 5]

v15-LCD, 2026-10-08. 1.9in 170x320 IPS (ST7789V3) replaces the 2.13in e-paper. Panel = Unvision/Newvisio 190-1732TBWPG01 family (the LilyGO T-Display-S3 / Heltec HT-VMT190 panel), 30-pin 0.5 mm FPC, 4-wire SPI: IM1 = IM2 = VDD, RD and DB0..DB7 to GND (vendor 4-SPI circuit), SDO and TP pins open. SPI on the old e-paper GPIOs, re-assigned so the board routes without crossings: MOSI IO5, D/C IO6, SCK IO8, CS IO41, RST IO42 (review 13, 2026-10-08: J5 footprint pad numbers are mirrored, pad N = socket contact 31-N, so that panel finger 1 lands on pad 1 after the tail folds through the slot; the five B.Cu lanes keep their order, so the GPIO roles swapped) (any GPIO works through the ESP32-S3 GPIO matrix). IO4 = LCD_BL_EN (PWM; KEYPAD_INT moved from IO4 to IO3, both RTC wake pins). IO33 (was EPD_BUSY) = LCD_PWR_N, active low, R21 pull-up: panel unpowered in deep sleep (ST7789 standby alone is ~20 uA).

Backlight: 4 white LEDs in parallel inside the panel (rated 60 mA, 3.0-3.4 V). LEDA <- R23 15R <- +3V3; the four cathodes are tied (LCD_LEDK) and switched by Q5 (AO3400A) with LEDC PWM on IO4. (3.3 V - Vf ~2.8 V) / 22 R = about 20-25 mA at 100 % duty (~1/3 of rated brightness, enough indoors); R22 keeps Q5 off in deep sleep. A constant-current driver (AW9364, LCSC C401007) is the upgrade if more brightness is wanted. Rules: drive every LCD SPI pin low before LCD_PWR_N goes high, or the panel is back-powered through its ESD diodes. BL_EN low in sleep (Q5 off: no backlight current). No TE pin on this panel. Removed vs v14: J2 (24P e-paper socket), the SSD1680 booster L1, Q3, R11, R12, D3, D4, D5, C20..C30 (17 parts). Added: J5, Q4, Q5, R21, R22, R23, C36 (C19 re-used on LCD_VDD). C36

LCD 1.9in 170x320 IPS 30P FPC (190-1732TBWPG01 / T-Display-S3 panel) C36

Sheet: /LCD 1.9in IPS + backlight/
File: lcd.kicad_sch
Title:



Sheet: /Connectors (magnet USB, battery)/
File: connectors.kicad_sch
Title:

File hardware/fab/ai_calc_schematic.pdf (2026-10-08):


E-paper driver File: epaper.kicad_sch

Size: A4 | Rev:
KiCad E.D.A. 10.0.6 | Id: 1/7


Sheet: /Power and charging/
File: power.kicad_sch
Title:



J1Camera FPC 24P 0.5mm dual-contact (OV5640, cable contacts down)
Mounting 123456789




Sheet: /Connectors (magnet USB, battery)/
File: connectors.kicad_sch
Title:

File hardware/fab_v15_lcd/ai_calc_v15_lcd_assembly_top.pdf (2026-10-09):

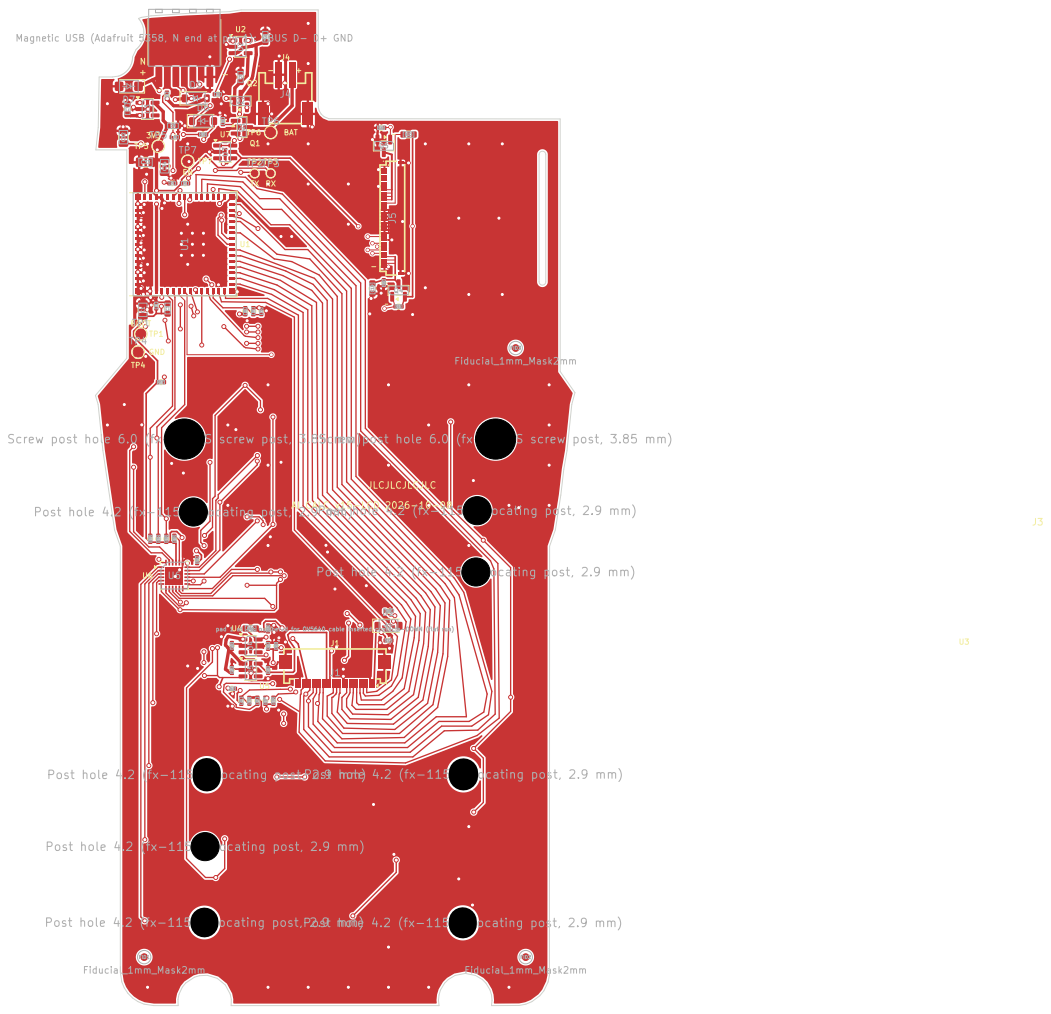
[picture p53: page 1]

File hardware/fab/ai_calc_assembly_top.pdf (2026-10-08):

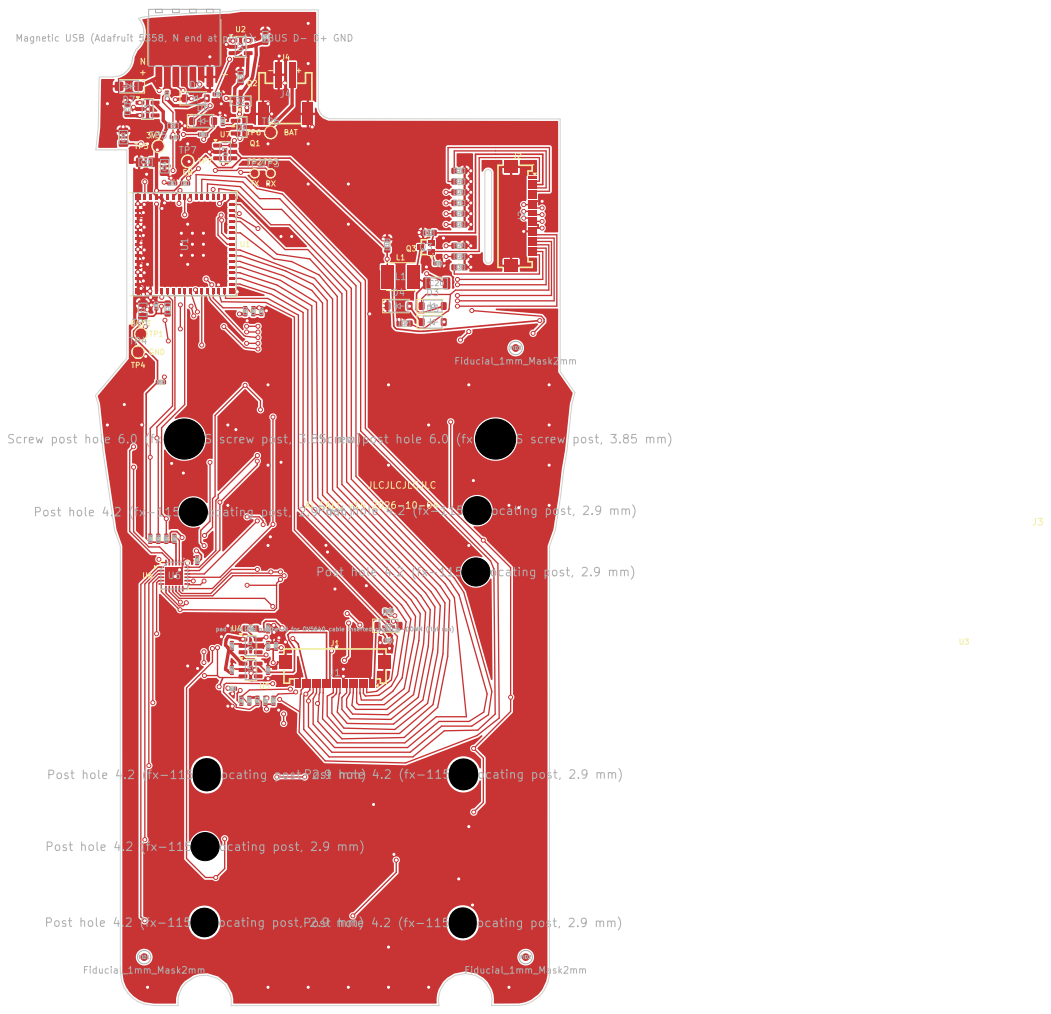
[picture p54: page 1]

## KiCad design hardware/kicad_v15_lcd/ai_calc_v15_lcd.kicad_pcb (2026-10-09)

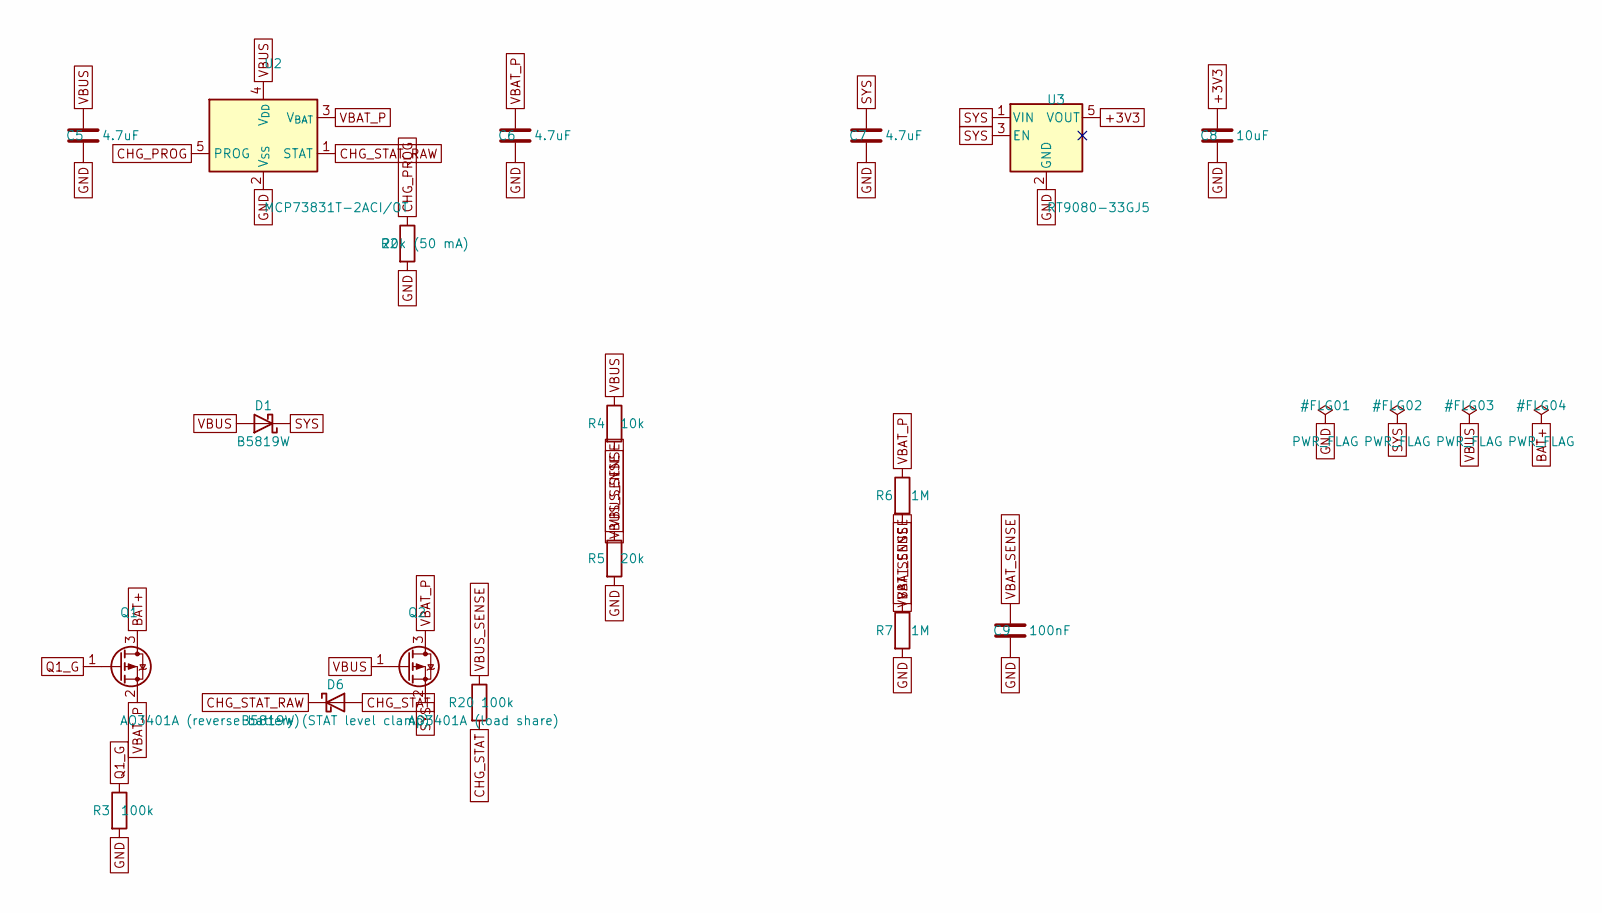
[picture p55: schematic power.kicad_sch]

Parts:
C5, C6, C7: 4.7uF; C_0603_1608Metric; LCSC C19666
C8: 10uF; C_0603_1608Metric; LCSC C19702
C9: 100nF; C_0402_1005Metric; LCSC C1525
D1: B5819W; D_SOD-123; LCSC C8598
D6: B5819W (STAT level clamp); D_SOD-123; LCSC C8598
Q1: AO3401A (reverse battery); SOT-23; LCSC C15127
Q2: AO3401A (load share); SOT-23; LCSC C15127
R2: 20k (50 mA); R_0402_1005Metric; LCSC C25765
R3, R20: 100k; R_0402_1005Metric; LCSC C25741
R4: 10k; R_0402_1005Metric; LCSC C25744
R5: 20k; R_0402_1005Metric; LCSC C25765
R6, R7: 1M; R_0402_1005Metric; LCSC C26083
U2: MCP73831T-2ACI/OT; SOT-23-5; LCSC C424093
U3: RT9080-33GJ5; SOT-23-5; LCSC C841192

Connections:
+3V3: C8.1, U3.5 (VOUT); also elsewhere on the board
BAT+: Q1.3 (D); also elsewhere on the board
CHG_PROG: R2.1, U2.5 (PROG)
CHG_STAT: D6.2 (A), R20.2; also elsewhere on the board
CHG_STAT_RAW: D6.1 (K), U2.1 (STAT)
GND: C5.2, C6.2, C7.2, C8.2, C9.2, R2.2, R3.2, R5.2, R7.2, U2.2 (V_{SS}), U3.2 (GND); also elsewhere on the board
Q1_G: Q1.1 (G), R3.1
SYS: C7.1, D1.1 (K), Q2.2 (S), U3.1 (VIN), U3.3 (EN); also elsewhere on the board
VBAT_P: C6.1, Q1.2 (S), Q2.3 (D), R6.1, U2.3 (V_{BAT})
VBAT_SENSE: C9.1, R6.2, R7.1; also elsewhere on the board
VBUS: C5.1, D1.2 (A), Q2.1 (G), R4.1, U2.4 (V_{DD}); also elsewhere on the board
VBUS_SENSE: R4.2, R5.1, R20.1; also elsewhere on the board

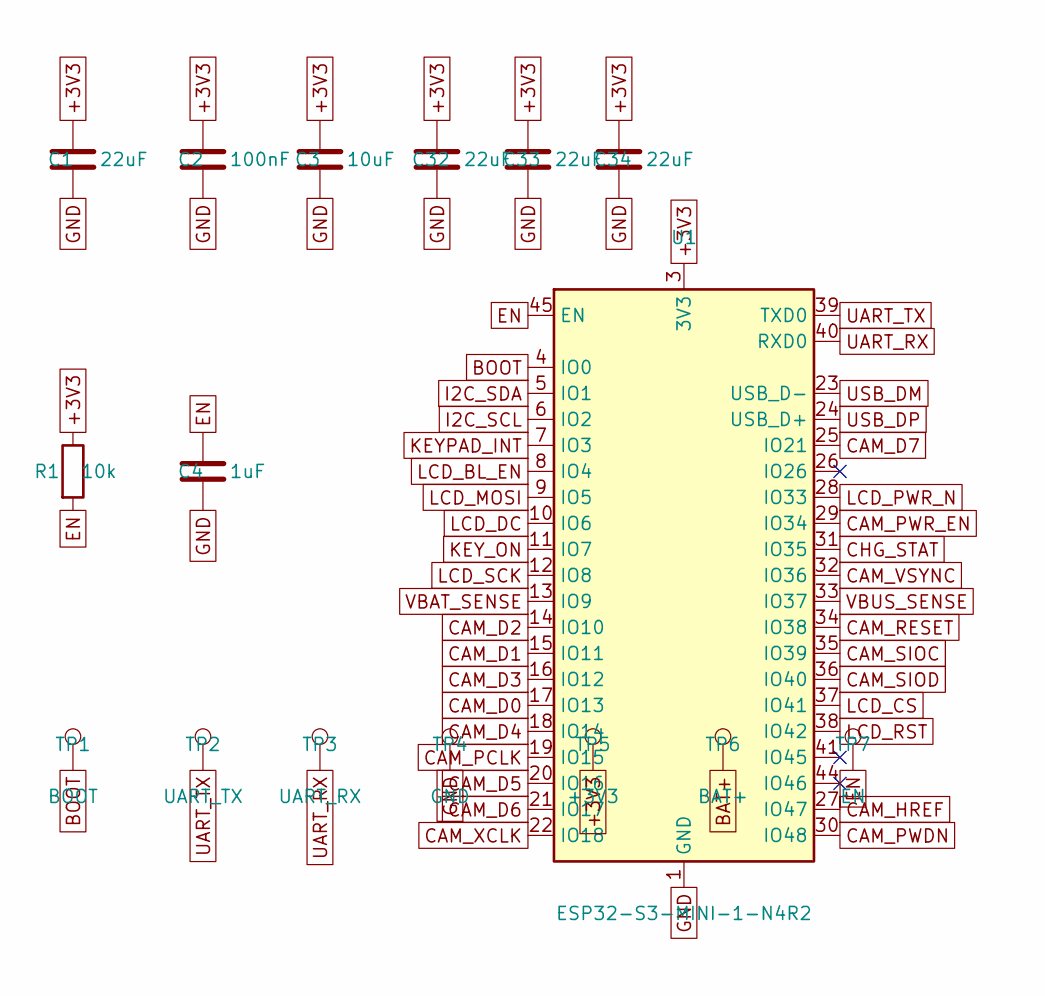
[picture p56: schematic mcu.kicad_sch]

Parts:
C1, C32, C33, C34: 22uF; C_0805_2012Metric; LCSC C45783
C2: 100nF; C_0402_1005Metric; LCSC C1525
C3: 10uF; C_0603_1608Metric; LCSC C19702
C4: 1uF; C_0402_1005Metric; LCSC C52923
R1: 10k; R_0402_1005Metric; LCSC C25744
TP1: BOOT; TestPoint_Pad_D1.5mm
TP2: UART_TX; TestPoint_Pad_D1.0mm
TP3: UART_RX; TestPoint_Pad_D1.0mm
TP4: GND; TestPoint_Pad_D1.5mm
TP5: +3V3; TestPoint_Pad_D1.5mm
TP6: BAT+; TestPoint_Pad_D1.5mm
TP7: EN; TestPoint_Pad_D1.5mm
U1: ESP32-S3-MINI-1-N4R2; ESP32-S3-MINI-1; MPN ESP32-S3-MINI-1-N4R2; LCSC C3013941

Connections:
+3V3: C1.1, C2.1, C3.1, C32.1, C33.1, C34.1, R1.1, TP5.1, U1.3 (3V3); also elsewhere on the board
BAT+: TP6.1; also elsewhere on the board
BOOT: TP1.1, U1.4 (IO0)
CAM_D0: U1.17 (IO13); also elsewhere on the board
CAM_D1: U1.15 (IO11); also elsewhere on the board
CAM_D2: U1.14 (IO10); also elsewhere on the board
CAM_D3: U1.16 (IO12); also elsewhere on the board
CAM_D4: U1.18 (IO14); also elsewhere on the board
CAM_D5: U1.20 (IO16); also elsewhere on the board
CAM_D6: U1.21 (IO17); also elsewhere on the board
CAM_D7: U1.25 (IO21); also elsewhere on the board
CAM_HREF: U1.27 (IO47); also elsewhere on the board
CAM_PCLK: U1.19 (IO15); also elsewhere on the board
CAM_PWDN: U1.30 (IO48); also elsewhere on the board
CAM_PWR_EN: U1.29 (IO34); also elsewhere on the board
CAM_RESET: U1.34 (IO38); also elsewhere on the board
CAM_SIOC: U1.35 (IO39); also elsewhere on the board
CAM_SIOD: U1.36 (IO40); also elsewhere on the board
CAM_VSYNC: U1.32 (IO36); also elsewhere on the board
CAM_XCLK: U1.22 (IO18); also elsewhere on the board
CHG_STAT: U1.31 (IO35); also elsewhere on the board
EN: C4.1, R1.2, TP7.1, U1.45 (EN)
GND: C1.2, C2.2, C3.2, C4.2, C32.2, C33.2, C34.2, TP4.1, U1.1 (GND), U1.2 (GND), U1.42 (GND), U1.43 (GND), U1.46 (GND), U1.47 (GND), U1.48 (GND), U1.49 (GND), U1.50 (GND), U1.51 (GND), U1.52 (GND), U1.53 (GND), U1.54 (GND), U1.55 (GND), U1.56 (GND), U1.57 (GND), U1.58 (GND), U1.59 (GND), U1.60 (GND), U1.61 (GND), U1.62 (GND), U1.63 (GND), U1.64 (GND), U1.65 (GND); also elsewhere on the board
I2C_SCL: U1.6 (IO2); also elsewhere on the board
I2C_SDA: U1.5 (IO1); also elsewhere on the board
KEYPAD_INT: U1.7 (IO3); also elsewhere on the board
KEY_ON: U1.11 (IO7); also elsewhere on the board
LCD_BL_EN: U1.8 (IO4); also elsewhere on the board
LCD_CS: U1.37 (IO41); also elsewhere on the board
LCD_DC: U1.10 (IO6); also elsewhere on the board
LCD_MOSI: U1.9 (IO5); also elsewhere on the board
LCD_PWR_N: U1.28 (IO33); also elsewhere on the board
LCD_RST: U1.38 (IO42); also elsewhere on the board
LCD_SCK: U1.12 (IO8); also elsewhere on the board
UART_RX: TP3.1, U1.40 (RXD0)
UART_TX: TP2.1, U1.39 (TXD0)
USB_DM: U1.23 (USB_D-); also elsewhere on the board
USB_DP: U1.24 (USB_D+); also elsewhere on the board
VBAT_SENSE: U1.13 (IO9); also elsewhere on the board
VBUS_SENSE: U1.33 (IO37); also elsewhere on the board

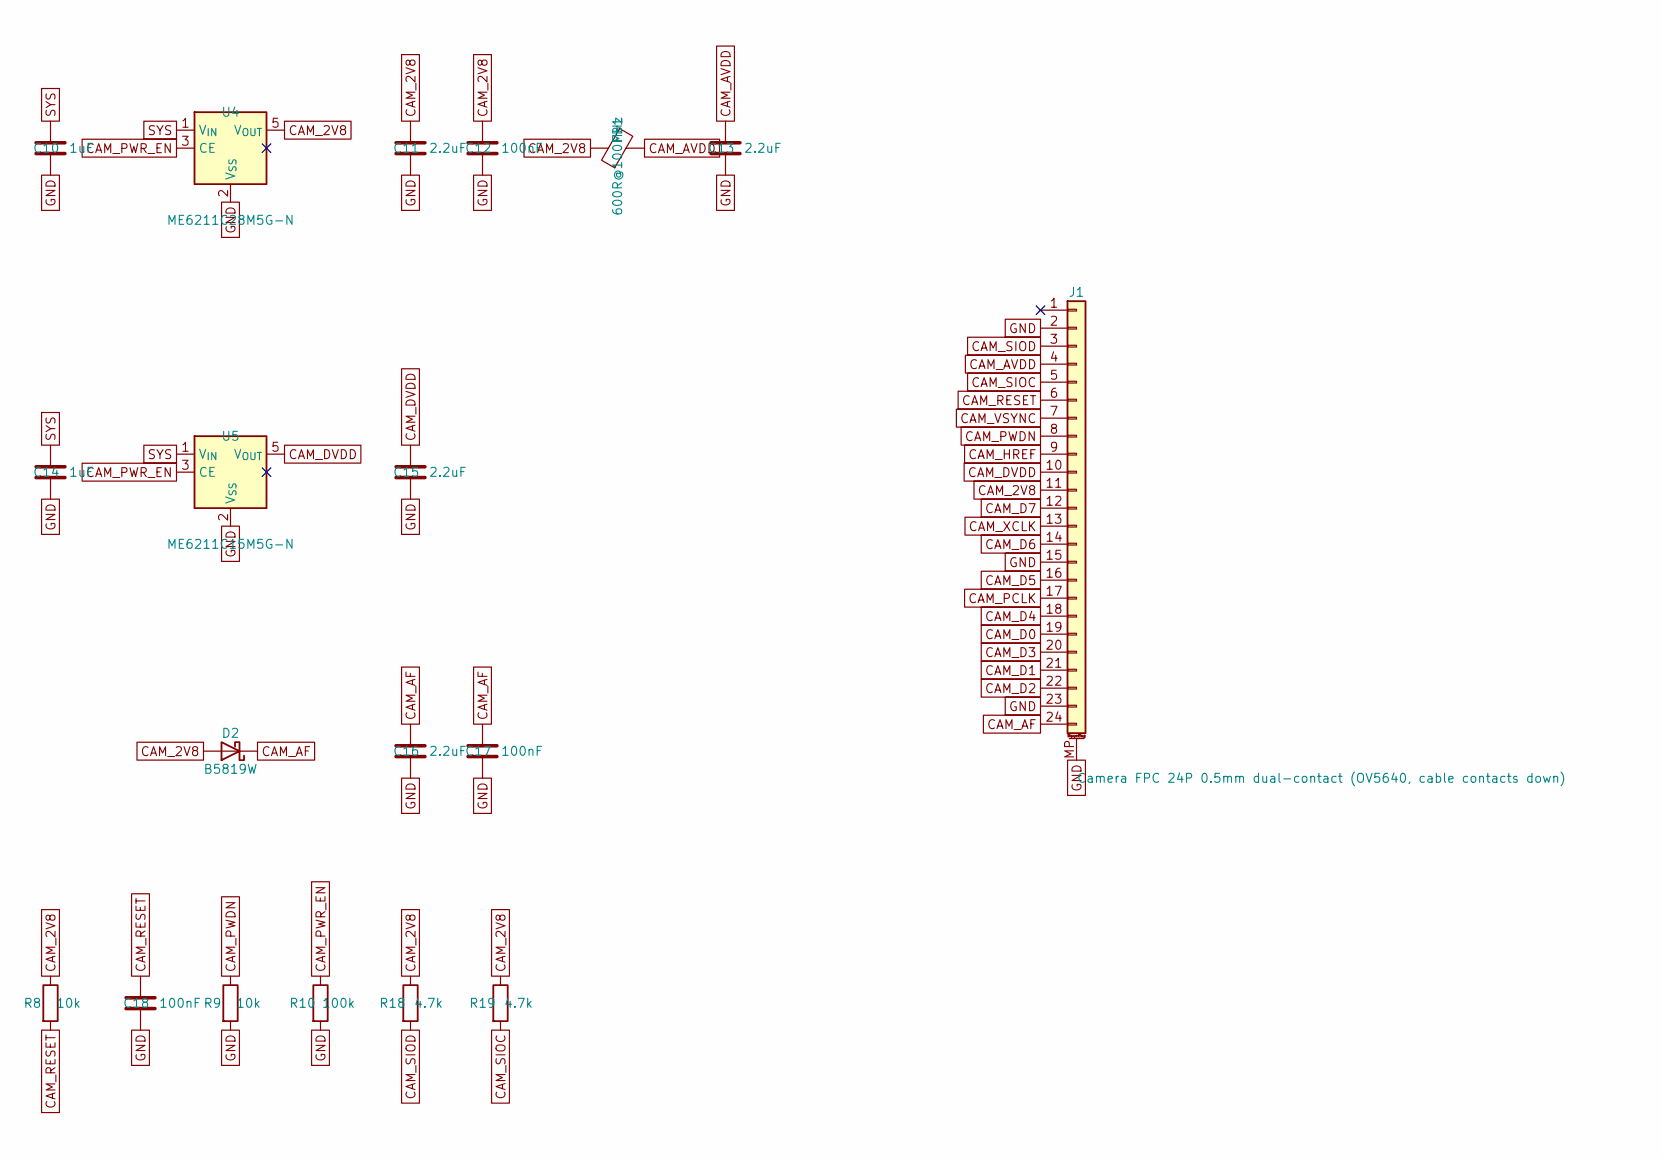
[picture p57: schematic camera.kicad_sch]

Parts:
C10, C14: 1uF; C_0402_1005Metric; LCSC C52923
C11, C13, C15, C16: 2.2uF; C_0402_1005Metric; LCSC C12530
C12, C17, C18: 100nF; C_0402_1005Metric; LCSC C1525
D2: B5819W; D_SOD-123; LCSC C8598
FB1: 600R@100MHz; L_0603_1608Metric; LCSC C1002
J1: Camera FPC 24P 0.5mm dual-contact (OV5640, cable 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; FPC_24P_P0.5mm_DualContact_C6364666_CamReversed; MPN FPC 0.5-24P HYH2.0 (SHOU HAN); LCSC C6364666
R8, R9: 10k; R_0402_1005Metric; LCSC C25744
R10: 100k; R_0402_1005Metric; LCSC C25741
R18, R19: 4.7k; R_0402_1005Metric; LCSC C25900
U4: ME6211C28M5G-N; SOT-23-5; LCSC C53099
U5: ME6211C15M5G-N; SOT-23-5; LCSC C53100

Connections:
CAM_2V8: C11.1, C12.1, D2.2 (A), FB1.1, J1.11, R8.1, R18.1, R19.1, U4.5 (V_{OUT})
CAM_AF: C16.1, C17.1, D2.1 (K), J1.24
CAM_AVDD: C13.1, FB1.2, J1.4
CAM_D0: J1.19; also elsewhere on the board
CAM_D1: J1.21; also elsewhere on the board
CAM_D2: J1.22; also elsewhere on the board
CAM_D3: J1.20; also elsewhere on the board
CAM_D4: J1.18; also elsewhere on the board
CAM_D5: J1.16; also elsewhere on the board
CAM_D6: J1.14; also elsewhere on the board
CAM_D7: J1.12; also elsewhere on the board
CAM_DVDD: C15.1, J1.10, U5.5 (V_{OUT})
CAM_HREF: J1.9; also elsewhere on the board
CAM_PCLK: J1.17; also elsewhere on the board
CAM_PWDN: J1.8, R9.1; also elsewhere on the board
CAM_PWR_EN: R10.1, U4.3 (CE), U5.3 (CE); also elsewhere on the board
CAM_RESET: C18.1, J1.6, R8.2; also elsewhere on the board
CAM_SIOC: J1.5, R19.2; also elsewhere on the board
CAM_SIOD: J1.3, R18.2; also elsewhere on the board
CAM_VSYNC: J1.7; also elsewhere on the board
CAM_XCLK: J1.13; also elsewhere on the board
GND: C10.2, C11.2, C12.2, C13.2, C14.2, C15.2, C16.2, C17.2, C18.2, J1.2, J1.15, J1.23, J1.MP (MountPin), R9.2, R10.2, U4.2 (V_{SS}), U5.2 (V_{SS}); also elsewhere on the board
SYS: C10.1, C14.1, U4.1 (V_{IN}), U5.1 (V_{IN}); also elsewhere on the board

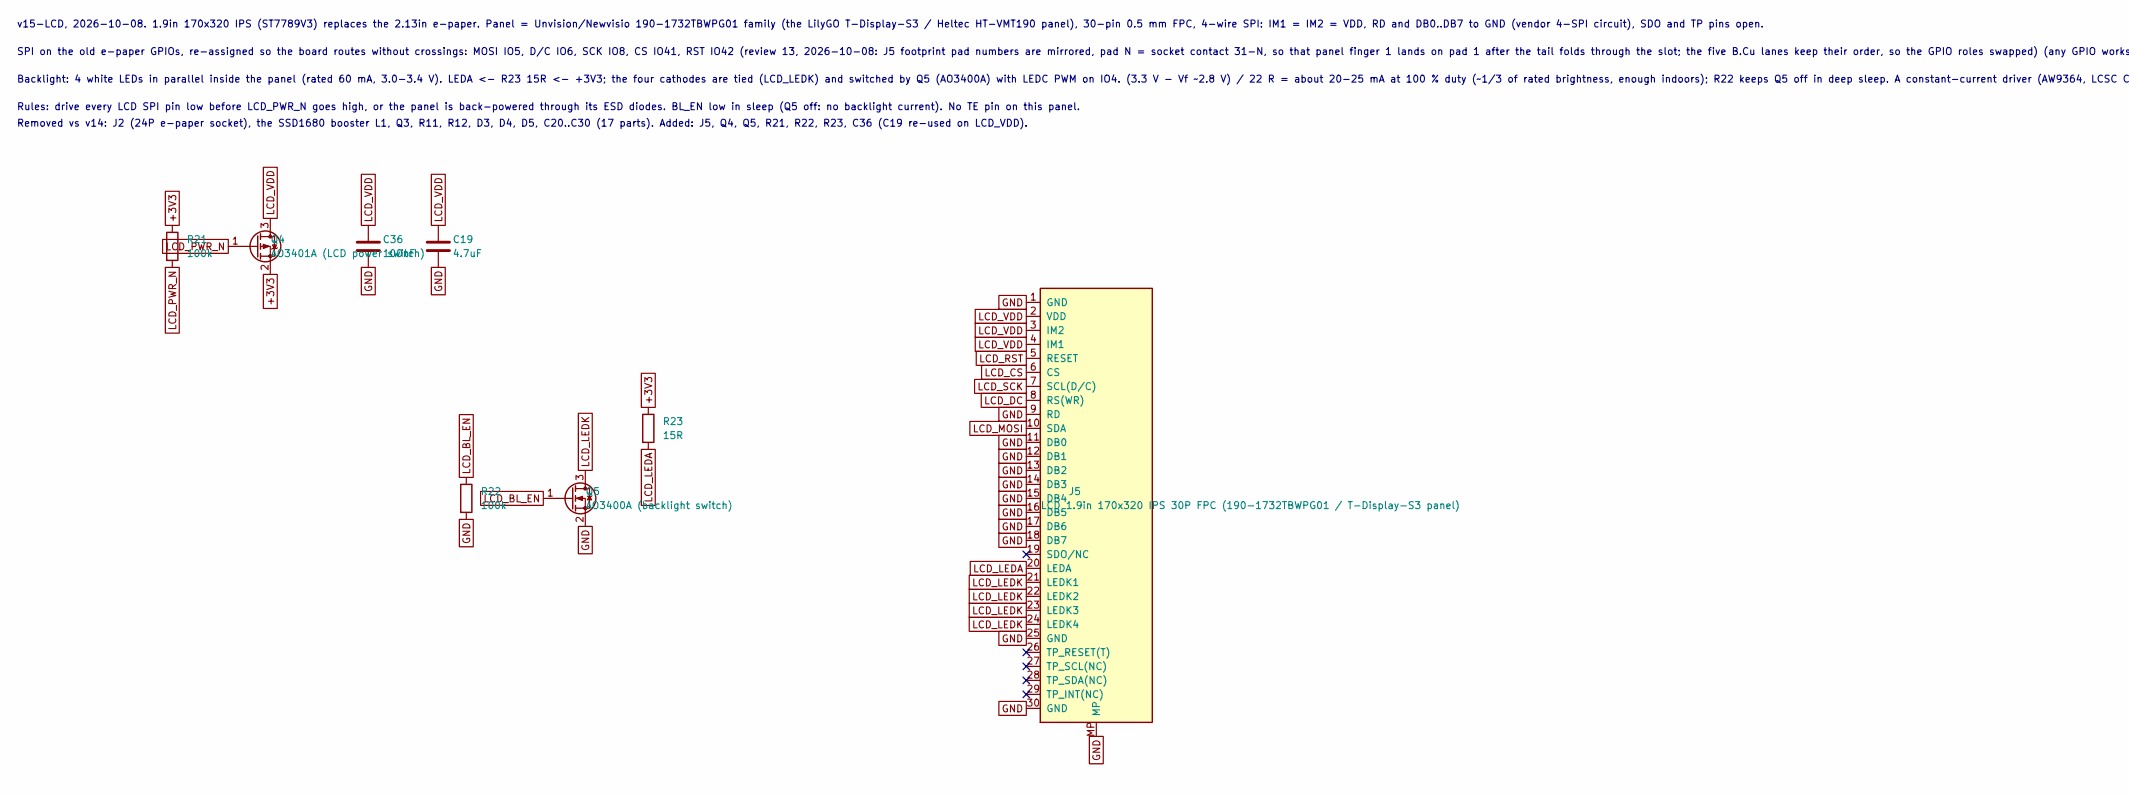
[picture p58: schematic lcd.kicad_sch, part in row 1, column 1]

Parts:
C19: 4.7uF; C_0603_1608Metric; LCSC C19666
C36: 100nF; C_0402_1005Metric; LCSC C1525
J5: LCD 1.9in 170x320 IPS 30P FPC (190-1732TBWPG01 / 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; FPC_30P_P0.5mm_DualContact_C2919501_LcdReversed; MPN HDGC 0.5K-HX-30PWB; LCSC C2919501
Q4: AO3401A (LCD power switch); SOT-23; MPN AO3401A; LCSC C15127
Q5: AO3400A (backlight switch); SOT-23; MPN AO3400A; LCSC C20917
R21, R22: 100k; R_0402_1005Metric; LCSC C25741
R23: 15R; R_0603_1608Metric; LCSC C22810

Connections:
+3V3: Q4.2 (S), R21.1, R23.1; also elsewhere on the board
GND: C19.2, C36.2, J5.1 (GND), J5.9 (RD), J5.11 (DB0), J5.12 (DB1), J5.13 (DB2), J5.14 (DB3), J5.15 (DB4), J5.16 (DB5), J5.17 (DB6), J5.18 (DB7), J5.25 (GND), J5.30 (GND), J5.MP, Q5.2 (S), R22.2; also elsewhere on the board
LCD_BL_EN: Q5.1 (G), R22.1; also elsewhere on the board
LCD_CS: J5.6 (CS); also elsewhere on the board
LCD_DC: J5.8 (RS(WR)); also elsewhere on the board
LCD_LEDA: J5.20 (LEDA), R23.2
LCD_LEDK: J5.21 (LEDK1), J5.22 (LEDK2), J5.23 (LEDK3), J5.24 (LEDK4), Q5.3 (D)
LCD_MOSI: J5.10 (SDA); also elsewhere on the board
LCD_PWR_N: Q4.1 (G), R21.2; also elsewhere on the board
LCD_RST: J5.5 (RESET); also elsewhere on the board
LCD_SCK: J5.7 (SCL(D/C)); also elsewhere on the board
LCD_VDD: C19.1, C36.1, J5.2 (VDD), J5.3 (IM2), J5.4 (IM1), Q4.3 (D)

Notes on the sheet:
v15-LCD, 2026-10-08. 1.9in 170x320 IPS (ST7789V3) replaces the 2.13in e-paper. Panel = Unvision/Newvisio 190-1732TBWPG01 family (the LilyGO T-Display-S3 / Heltec HT-VMT190 panel), 30-pin 0.5 mm FPC, 4-wire SPI: IM1 = IM2 = VDD, RD and DB0..DB7 to GND (vendor 4-SPI circuit), SDO and TP pins open.
SPI on the old e-paper GPIOs, re-assigned so the board routes without crossings: MOSI IO5, D/C IO6, SCK IO8, CS IO41, RST IO42 (review 13, 2026-10-08: J5 footprint pad numbers are mirrored, pad N = socket contact 31-N, so that panel finger 1 lands on pad 1 after the tail folds through the slot; the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
Backlight: 4 white LEDs in parallel inside the panel (rated 60 mA, 3.0-3.4 V). LEDA <- R23 15R <- +3V3; the four cathodes are tied (LCD_LEDK) and switched by Q5 (AO3400A) with LEDC PWM on IO4. (3.3 V - Vf ~2.8 V) / 22 R = about 20-25 mA at 100 % duty (~1/3 of rated brightness, enough indoors); R22 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
Rules: drive every LCD SPI pin low before LCD_PWR_N goes high, or the panel is back-powered through its ESD diodes. BL_EN low in sleep (Q5 off: no backlight current). No TE pin on this panel.
Removed vs v14: J2 (24P e-paper socket), the SSD1680 booster L1, Q3, R11, R12, D3, D4, D5, C20..C30 (17 parts). Added: J5, Q4, Q5, R21, R22, R23, C36 (C19 re-used on LCD_VDD).

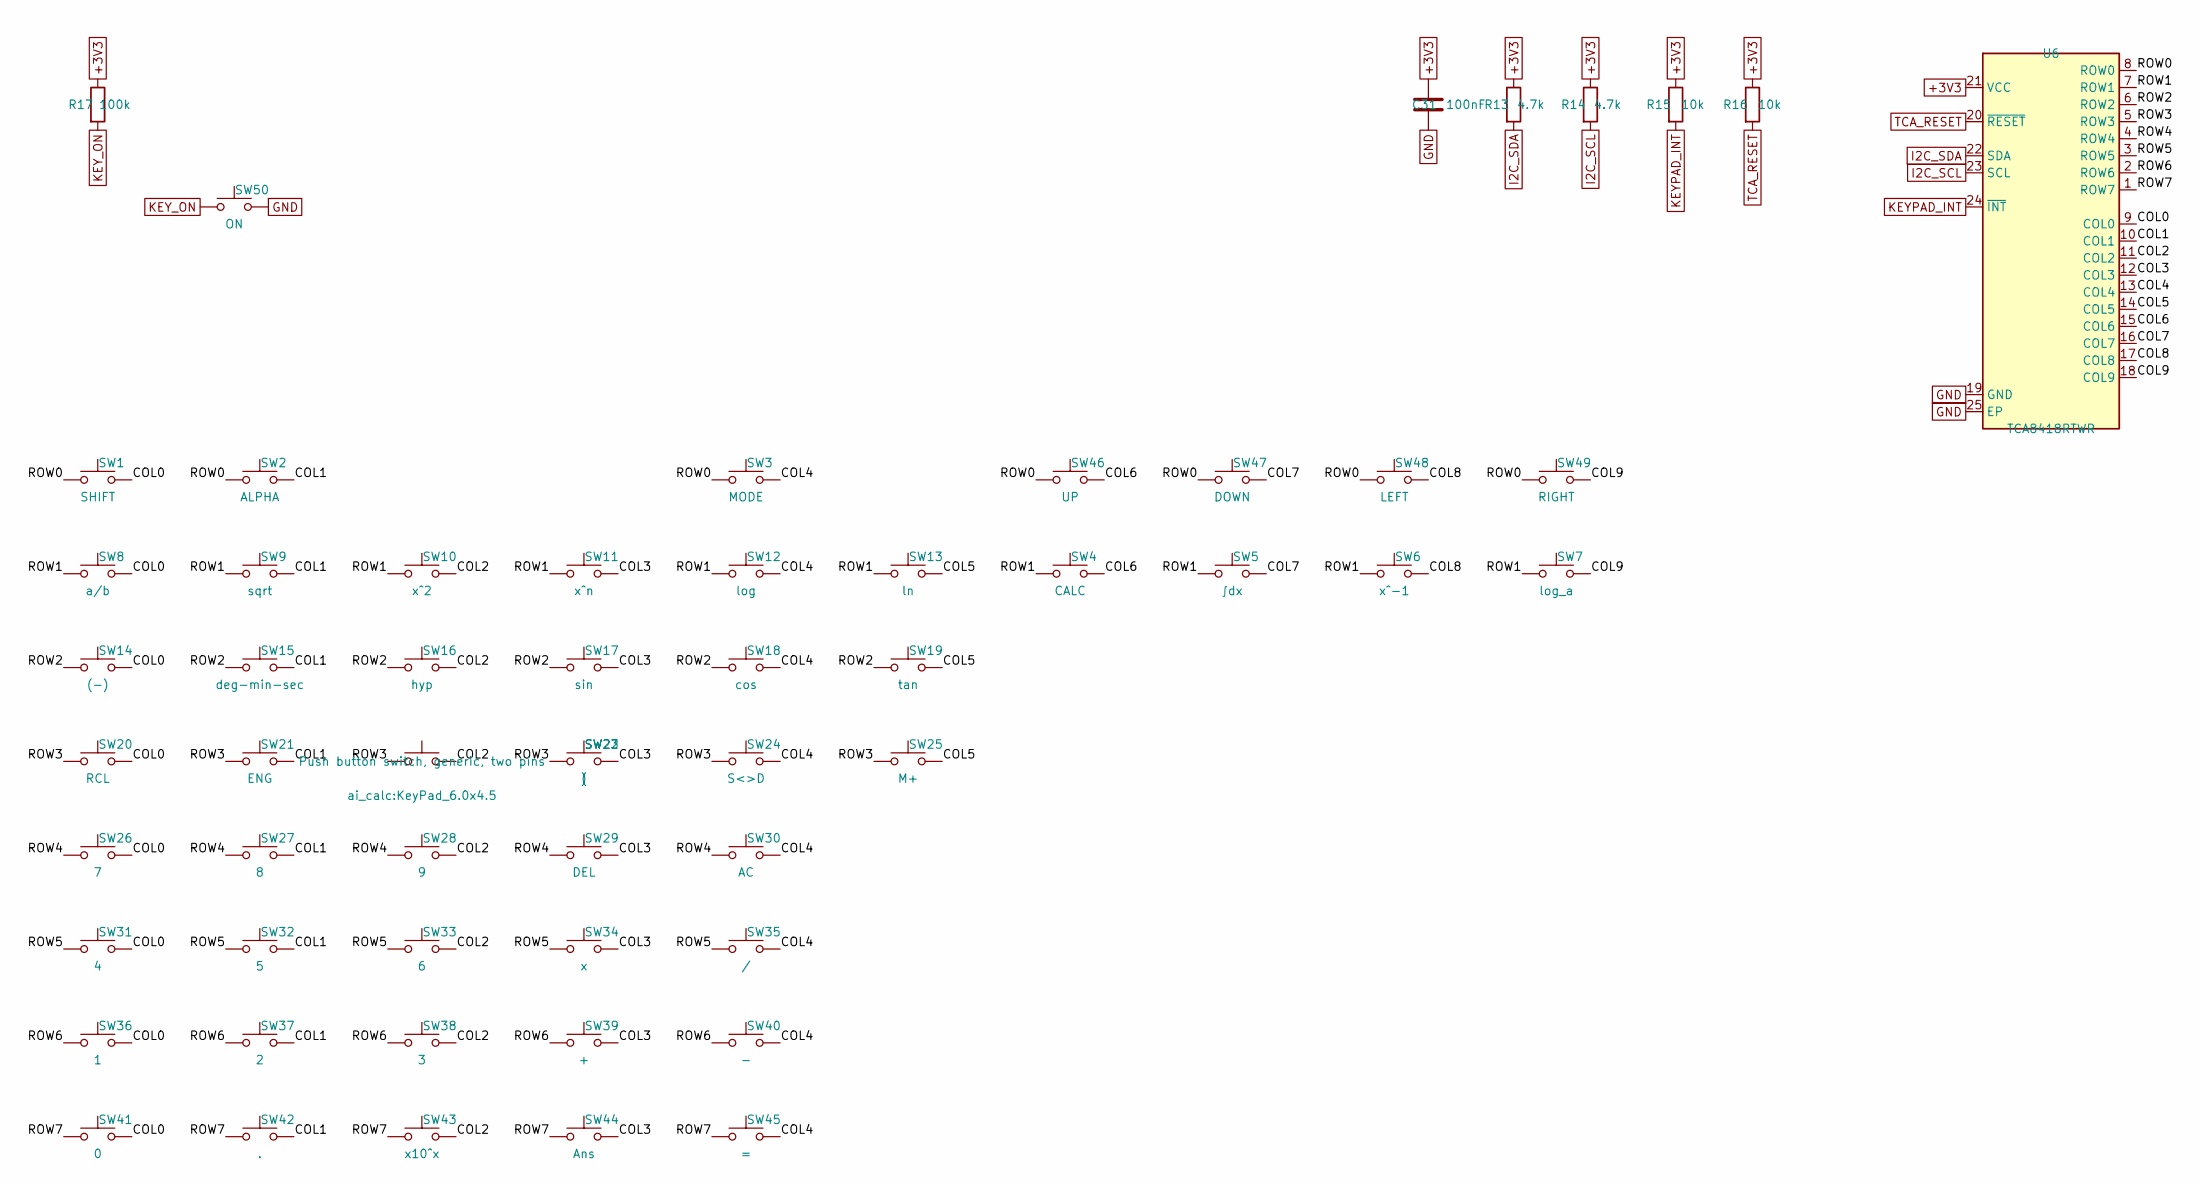
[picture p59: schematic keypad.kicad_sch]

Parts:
C31: 100nF; C_0402_1005Metric; LCSC C1525
R13, R14: 4.7k; R_0402_1005Metric; LCSC C25900
R15, R16: 10k; R_0402_1005Metric; LCSC C25744
R17: 100k; R_0402_1005Metric; LCSC C25741
SW1: SHIFT; KeyPad_6.0x4.5
SW2: ALPHA; KeyPad_6.0x4.5
SW3: MODE; KeyPad_6.0x4.5
SW4: CALC; KeyPad_6.0x4.5
SW5: ∫dx; KeyPad_6.0x4.5
SW6: x^-1; KeyPad_6.0x4.5
SW7: log_a; KeyPad_6.0x4.5
SW8: a/b; KeyPad_6.0x4.5
SW9: sqrt; KeyPad_6.0x4.5
SW10: x^2; KeyPad_6.0x4.5
SW11: x^n; KeyPad_6.0x4.5
SW12: log; KeyPad_6.0x4.5
SW13: ln; KeyPad_6.0x4.5
SW14: (-); KeyPad_6.0x4.5
SW15: deg-min-sec; KeyPad_6.0x4.5
SW16: hyp; KeyPad_6.0x4.5
SW17: sin; KeyPad_6.0x4.5
SW18: cos; KeyPad_6.0x4.5
SW19: tan; KeyPad_6.0x4.5
SW20: RCL; KeyPad_6.0x4.5
SW21: ENG; KeyPad_6.0x4.5
SW22: (; KeyPad_6.0x4.5
SW23: ); KeyPad_6.0x4.5
SW24: S<>D; KeyPad_6.0x4.5
SW25: M+; KeyPad_6.0x4.5
SW26: 7; KeyPad_9.0x7.0
SW27: 8; KeyPad_9.0x7.0
SW28: 9; KeyPad_9.0x7.0
SW29: DEL; KeyPad_9.0x7.0
SW30: AC; KeyPad_9.0x7.0
SW31: 4; KeyPad_9.0x7.0
SW32: 5; KeyPad_9.0x7.0
SW33: 6; KeyPad_9.0x7.0
SW34: x; KeyPad_9.0x7.0
SW35: /; KeyPad_9.0x7.0
SW36: 1; KeyPad_9.0x7.0
SW37: 2; KeyPad_9.0x7.0
SW38: 3; KeyPad_9.0x7.0
SW39: +; KeyPad_9.0x7.0
SW40: -; KeyPad_9.0x7.0
SW41: 0; KeyPad_6.0x4.5
SW42: .; KeyPad_6.0x4.5
SW43: x10^x; KeyPad_6.0x4.5
SW44: Ans; KeyPad_6.0x4.5
SW45: =; KeyPad_6.0x4.5
SW46: UP; KeyPad_5.0x4.0
SW47: DOWN; KeyPad_5.0x4.0
SW48: LEFT; KeyPad_5.0x4.0
SW49: RIGHT; KeyPad_5.0x4.0
SW50: ON; KeyPad_6.0x4.5
U6: TCA8418RTWR; HVQFN-24-1EP_4x4mm_P0.5mm_EP2.6x2.6mm; MPN TCA8418RTWR; LCSC C138713

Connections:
+3V3: C31.1, R13.1, R14.1, R15.1, R16.1, R17.1, U6.21 (VCC); also elsewhere on the board
/Keypad and TCA8418/COL0: SW1.2, SW8.2, SW14.2, SW20.2, SW26.2, SW31.2, SW36.2, SW41.2, U6.9 (COL0)
/Keypad and TCA8418/COL1: SW2.2, SW9.2, SW15.2, SW21.2, SW27.2, SW32.2, SW37.2, SW42.2, U6.10 (COL1)
/Keypad and TCA8418/COL2: SW10.2, SW16.2, SW22.2, SW28.2, SW33.2, SW38.2, SW43.2, U6.11 (COL2)
/Keypad and TCA8418/COL3: SW11.2, SW17.2, SW23.2, SW29.2, SW34.2, SW39.2, SW44.2, U6.12 (COL3)
/Keypad and TCA8418/COL4: SW3.2, SW12.2, SW18.2, SW24.2, SW30.2, SW35.2, SW40.2, SW45.2, U6.13 (COL4)
/Keypad and TCA8418/COL5: SW13.2, SW19.2, SW25.2, U6.14 (COL5)
/Keypad and TCA8418/COL6: SW4.2, SW46.2, U6.15 (COL6)
/Keypad and TCA8418/COL7: SW5.2, SW47.2, U6.16 (COL7)
/Keypad and TCA8418/COL8: SW6.2, SW48.2, U6.17 (COL8)
/Keypad and TCA8418/COL9: SW7.2, SW49.2, U6.18 (COL9)
/Keypad and TCA8418/ROW0: SW1.1, SW2.1, SW3.1, SW46.1, SW47.1, SW48.1, SW49.1, U6.8 (ROW0)
/Keypad and TCA8418/ROW1: SW4.1, SW5.1, SW6.1, SW7.1, SW8.1, SW9.1, SW10.1, SW11.1, SW12.1, SW13.1, U6.7 (ROW1)
/Keypad and TCA8418/ROW2: SW14.1, SW15.1, SW16.1, SW17.1, SW18.1, SW19.1, U6.6 (ROW2)
/Keypad and TCA8418/ROW3: SW20.1, SW21.1, SW22.1, SW23.1, SW24.1, SW25.1, U6.5 (ROW3)
/Keypad and TCA8418/ROW4: SW26.1, SW27.1, SW28.1, SW29.1, SW30.1, U6.4 (ROW4)
/Keypad and TCA8418/ROW5: SW31.1, SW32.1, SW33.1, SW34.1, SW35.1, U6.3 (ROW5)
/Keypad and TCA8418/ROW6: SW36.1, SW37.1, SW38.1, SW39.1, SW40.1, U6.2 (ROW6)
/Keypad and TCA8418/ROW7: SW41.1, SW42.1, SW43.1, SW44.1, SW45.1, U6.1 (ROW7)
GND: C31.2, SW50.2, U6.19 (GND), U6.25 (EP); also elsewhere on the board
I2C_SCL: R14.2, U6.23 (SCL); also elsewhere on the board
I2C_SDA: R13.2, U6.22 (SDA); also elsewhere on the board
KEYPAD_INT: R15.2, U6.24 (~INT); also elsewhere on the board
KEY_ON: R17.2, SW50.1; also elsewhere on the board
TCA_RESET: R16.2, U6.20 (~RESET)

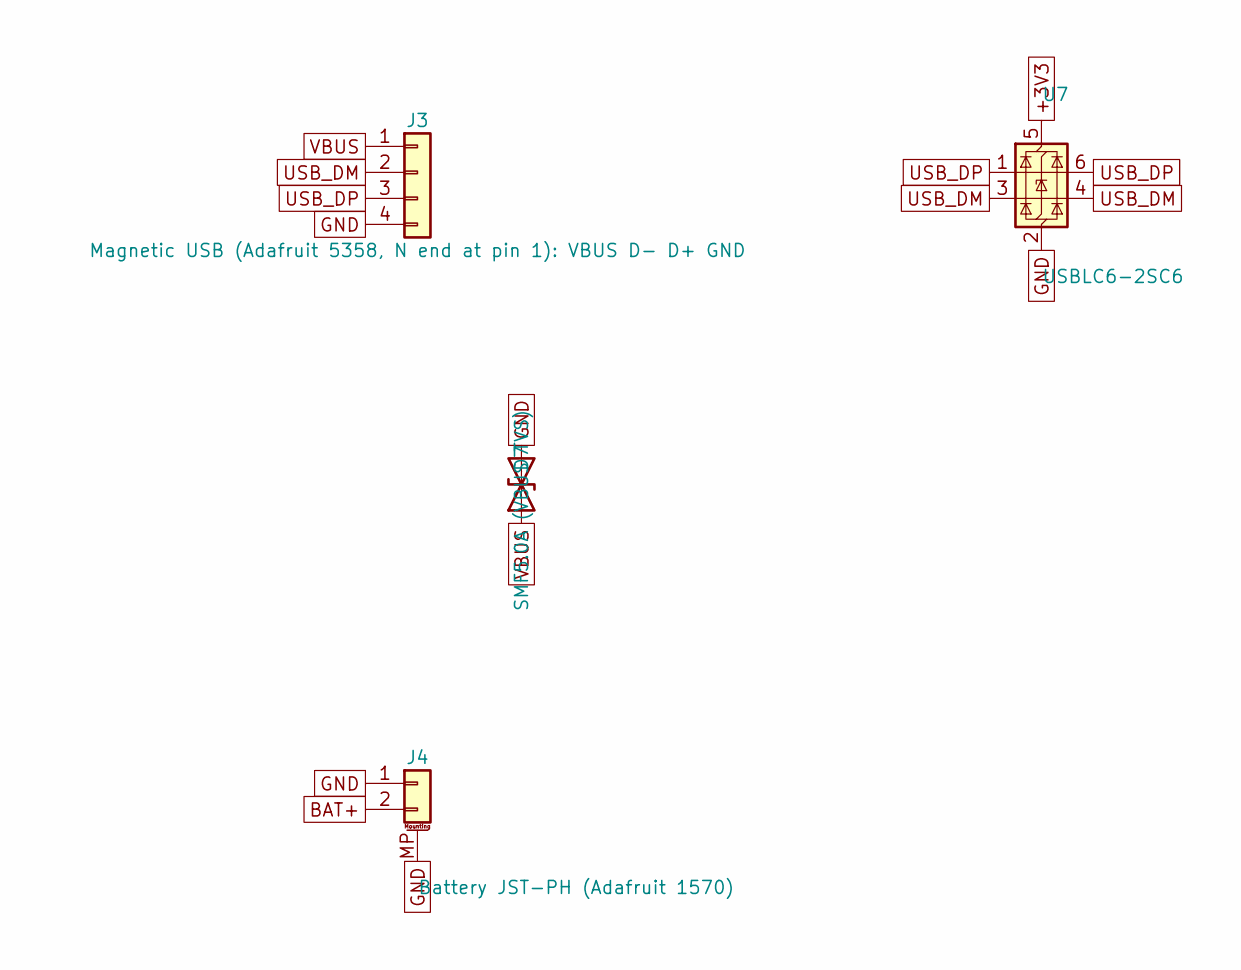
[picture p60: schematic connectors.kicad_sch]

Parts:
D7: SMF5.0A (VBUS TVS); D_SMF; LCSC C193402
J3: Magnetic USB (Adafruit 5358, N end at pin 1): VBU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; PinSocket_1x04_P2.54mm_SMD_RA_C46061768; MPN HX PM2.54-1x4P WT (right-angle SMD fema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; LCSC C46061768
J4: Battery JST-PH (Adafruit 1570); JST_PH_S2B-PH-SM4-TB_LCSC; LCSC C295747
U7: USBLC6-2SC6; SOT-23-6; LCSC C7519

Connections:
+3V3: U7.5 (VBUS); also elsewhere on the board
BAT+: J4.2; also elsewhere on the board
GND: D7.2 (A2), J3.4, J4.1, J4.MP (MountPin), U7.2 (GND); also elsewhere on the board
USB_DM: J3.2, U7.3 (I/O2), U7.4 (I/O2); also elsewhere on the board
USB_DP: J3.3, U7.1 (I/O1), U7.6 (I/O1); also elsewhere on the board
VBUS: D7.1 (A1), J3.1; also elsewhere on the board

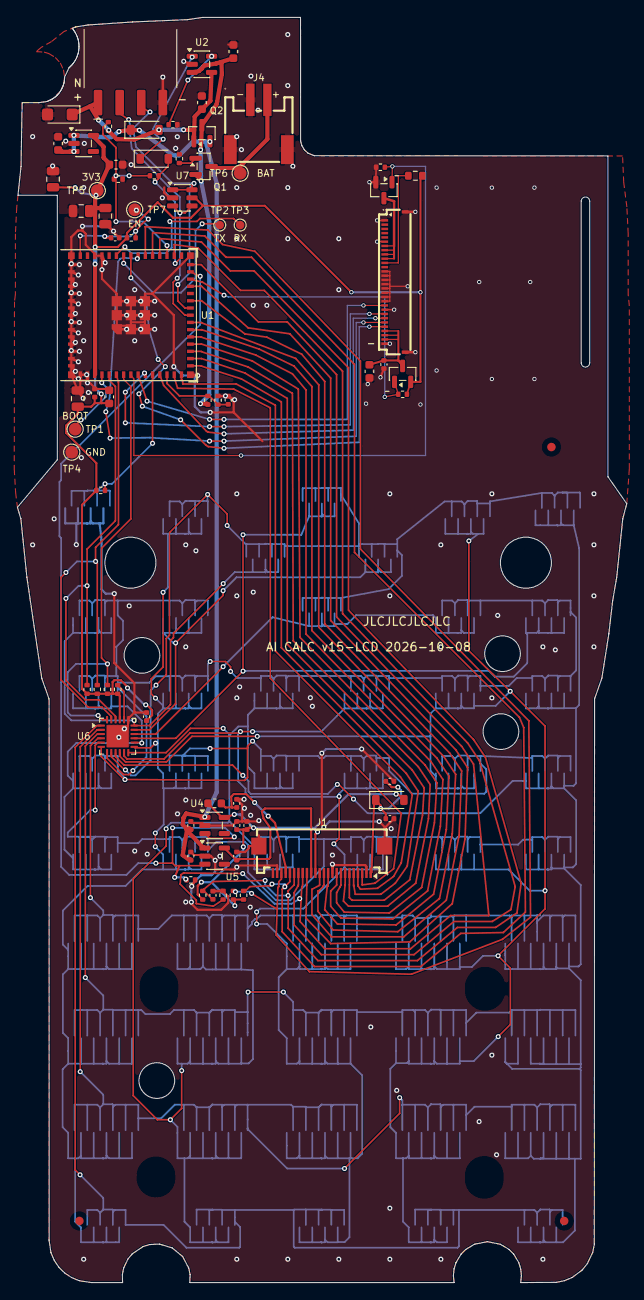
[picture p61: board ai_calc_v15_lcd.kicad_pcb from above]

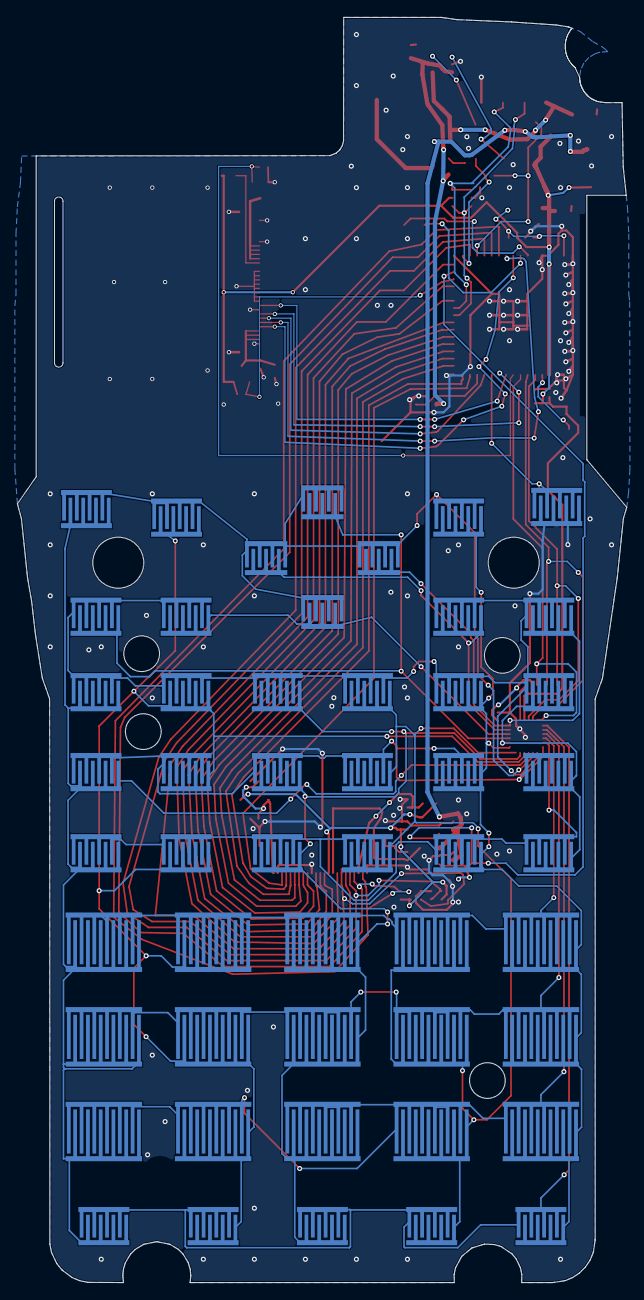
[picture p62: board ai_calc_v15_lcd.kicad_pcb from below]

Board: 2 copper layers, 71.6 x 148.8 mm, 135 parts (50 on the bottom side), 72 nets.

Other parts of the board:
FID1, FID2, FID3: Fiducial_1mm_Mask2mm
H1, H3: Screw post hole 6.0 (fx-115ES screw post, 3.85 mm); ScrewBoss_Hole_6.0mm
H2: Post hole 4.2 (fx-115ES locating post, 2.9 mm); Post_Slot_4.2x5.0mm
H4, H6, H8, H10: Post hole 4.2 (fx-115ES locating post, 2.9 mm); Post_Hole_4.2mm
H9: Post hole 4.2 (fx-115ES locating post, 2.9 mm); Post_Slot_4.4x4.8mm
H13: Post hole 4.2 (fx-115ES locating post, 2.9 mm); Post_Slot_4.2x4.45mm
H14: Post hole 4.2 (fx-115ES locating post, 2.9 mm); Post_Slot_4.2x4.65mm

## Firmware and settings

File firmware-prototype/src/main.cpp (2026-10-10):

// Firmware for the custom board inside the Casio (stage 14): the full calculator
// (Device: COMP maths, MODE / SETUP menus, AI SOLVE, exam mode), the same code as
// the simulators and the tester, with the OV5640 autofocus camera, e-paper screen,
// the whole keypad (keys.cpp), Wi-Fi through the AI proxy, the 150 mAh battery and
// deep sleep while off (power.cpp). Starts in COMP like the Casio.
//
// The calculator works fully offline: Wi-Fi is only switched on in AI SOLVE (and for
// a few serial commands and firmware updates). It never holds a Claude API key: AI
// requests go to our proxy (server/proxy) with this calculator's device token.
//
// Setup without a PC: = on SETUP > 6 starts a phone setup network (setup_portal.h).
// Every key can also be pressed from the Serial Monitor: "keys 1/3=" (see README).
// "exam off" over USB is the teacher's unlock. "selftest" runs the factory test.
// Serial log lines start with "[module]"; "SELFTEST_JSON {...}" is the test result.
#include <Arduino.h>
#include <WiFi.h>

#include "camera.h"
#include "claude_client.h"
#include "device.h"
#include "json.h"
#include "keys.h"
#include "log.h"
#include "ota.h"
#include "pins.h"
#include "power.h"
#include "preview.h"
#include "screen.h"
#include "selftest.h"
#include "settings.h"
#include "setup_portal.h"
#include "viewfinder.h"

using namespace calc;

// Headroom for JSON, TLS and the calculator's recursive parser (default is 8 KB).
SET_LOOP_TASK_STACK_SIZE(16 * 1024);

namespace {

// ---- timing, in one place
// While off, the chip stays awake this long after the last key before deep sleep
// (so SHIFT, 7, ON and SHIFT + ALPHA + ON can be typed after a wake).
constexpr uint32_t kOffGraceMs = 4000;
constexpr uint32_t kBootSerialDelayMs = 300;       // let a Serial Monitor catch the first lines
constexpr uint32_t kSelfTestComboScanMs = 150;     // held-key scan at start for SHIFT + ALPHA + ON
constexpr uint32_t kBatteryRefreshMs = 30000;      // status-bar battery and the AI lock-out
constexpr uint32_t kExamSaveEveryMs = 60000;       // exam-mode elapsed time to NVS
constexpr uint32_t kSolveWifiWaitMs = 12000;       // after the photo: a slow hotspot's last chance
constexpr uint32_t kSerialWifiWaitMs = 15000;      // pair / account / update: time to join
constexpr uint32_t kSerialWifiHoldMs = 30000;      // ...and how long Wi-Fi stays on for them
constexpr uint32_t kSendWifiWaitMs = 25000;        // preview Send: hotspot after leaving the AP
// Preview Send: Claude's answer. An idle limit, not a total one: a long xhigh/max solve keeps
// streaming (and the proxy sends ": ping" every 15 s while Claude thinks), so it may take minutes.
// The idle limit is above the client's own kIdleMs (120 s), which normally reports first.
constexpr uint32_t kSendSolveIdleMs = 150000;      // no byte to or from the proxy this long
constexpr uint32_t kSendSolveMaxMs = 300000;       // ...and a cap even while it still streams
constexpr uint32_t kViewfinderLogEveryMs = 10000;  // fps / battery line while the viewfinder runs
constexpr uint32_t kSetupAfterSaveMs = 3000;       // phone setup: the "Saved" page is sent, then the network closes
constexpr uint32_t kOtaConfirmAfterMs = 15000;     // a freshly installed image confirms itself after this
constexpr uint32_t kOtaAutoDelayMs = 20000;        // off on a cable this long before checking for updates
constexpr uint32_t kOtaRecheckMs = 24u * 60 * 60 * 1000;  // ...and again once a day if it stays on the cable
constexpr uint32_t kOtaRestartDelayMs = 1500;      // "Update done" on the glass before the restart
constexpr uint32_t kEventPostWaitMs = 1000;        // solve task -> loop queue

Device g_dev;
Framebuffer g_fb;
bool g_wasExam = false;
uint32_t g_examSavedAt = 0;
Settings g_settings;
SemaphoreHandle_t g_settingsLock;  // the solve task copies the settings
uint32_t g_lastKeyAt = 0;

// ---- work handed from the loop to the solve task, and results back ----
struct Event {
  enum Kind { Captured, Partial, Reply, Fail } kind;
  int id;
  std::string text;
  double confidence = 0;
  Failure failure = Failure::ApiError;
};
QueueHandle_t g_requests;          // int ids, loop -> task
QueueHandle_t g_events;            // Event*, task -> loop
volatile int g_wantedId = 0;       // 0 = the user cancelled (AC / OFF)

// A photo taken before the request (Send on the preview page, which takes it
// while the camera is still aimed, then steps off to reach the hotspot).
// Written by the loop before the request is queued; read once by the task.
std::string g_prePhoto, g_preDetail;

void post(Event* e) {
  if (xQueueSend(g_events, &e, pdMS_TO_TICKS(kEventPostWaitMs)) != pdTRUE) delete e;
}

Settings settingsCopy() {
  xSemaphoreTake(g_settingsLock, portMAX_DELAY);
  Settings s = g_settings;
  xSemaphoreGive(g_settingsLock);
  return s;
}

void solveTask(void*) {
  int id;
  while (true) {
    if (xQueueReceive(g_requests, &id, portMAX_DELAY) != pdTRUE) continue;
    if (g_wantedId != id) continue;
    uint32_t t0 = millis();
    std::string jpeg, detail, error;
    if (!g_prePhoto.empty()) {  // taken already by the preview page's Send
      jpeg.swap(g_prePhoto);
      detail.swap(g_preDetail);
    } else if (!cameraCapture(jpeg, detail, error, [id] { post(new Event{Event::Captured, id, ""}); })) {
      post(new Event{Event::Fail, id, error, 0, Failure::Camera});
      continue;
    }
    // Wi-Fi was switched on when AI SOLVE opened and joins while the photo is taken;
    // give a slow hotspot a few more seconds before giving up.
    for (uint32_t w = millis(); WiFi.status() != WL_CONNECTED && millis() - w < kSolveWifiWaitMs && g_wantedId == id;)
      delay(50);
    LOGF("solve", "[%d] photo %u bytes%s in %lu ms", id, (unsigned)jpeg.size(),
         detail.empty() ? "" : (" + close-up " + std::to_string(detail.size())).c_str(), millis() - t0);
    post(new Event{Event::Captured, id, ""});
    SolveCallbacks cb;
    cb.cancelled = [id] { return g_wantedId != id; };
    cb.partial = [id, t0](double conf, const std::string& a) {
      LOGF("solve", "[%d] answer after %lu ms", id, millis() - t0);
      post(new Event{Event::Partial, id, a, conf});
    };
    cb.reply = [id, t0](const std::string& json) {
      LOGF("solve", "[%d] done after %lu ms", id, millis() - t0);
      post(new Event{Event::Reply, id, json});
    };
    cb.fail = [id](Failure f, const std::string& d) {
      LOGF("solve", "[%d] failed: %d %s", id, (int)f, d.c_str());
      post(new Event{Event::Fail, id, d, 0, f});
    };
    // Effort and tutor are read from this task: safe because they only change on
    // the Ready screen, never while a request is in flight.
    claudeSolve(settingsCopy(), jpeg, detail, g_dev.ai().effortParam(), g_dev.ai().tutor(), cb);
    std::string().swap(jpeg);
    std::string().swap(detail);
  }
}

// ---- Send from the preview page ----
enum class SendStep { Idle, WaitWifi, Solving } g_send = SendStep::Idle;
uint32_t g_sendAt = 0;
int g_sendId = 0;

void sendFinished(const std::string& reply, const std::string& error) {
  previewSetResult(reply, error);
  g_send = SendStep::Idle;
  g_sendId = 0;
  if (previewResume()) LOGF("preview", "back: the page shows the answer");
}

const char* failureText(Failure f) {
  switch (f) {
    case Failure::NoConnection: return "No connection: check the phone's hotspot.";
    case Failure::NoApiKey: return "Not set up: use = on SETUP 6, or proxy and token in the Serial Monitor.";
    case Failure::Timeout: return "Claude took too long to reply.";
    case Failure::ApiBusy: return "Claude is busy: try again in a moment.";
    case Failure::ApiError: return "Claude refused the request.";
    case Failure::BadReply: return "Claude's reply couldn't be read.";
    case Failure::Camera: return "Couldn't take the photo.";
    case Failure::Account: return "The AI account refused it (link / subscription / monthly cap).";
    case Failure::LowBattery: return "Battery too low for AI: charge it.";
  }
  return "The scan failed.";
}

void handleEvent(Event* e) {
  switch (e->kind) {
    case Event::Captured: g_dev.onCaptured(e->id); break;
    case Event::Partial: g_dev.onPartialAnswer(e->id, e->confidence, e->text); break;
    case Event::Reply: g_dev.onReply(e->id, e->text); break;
    case Event::Fail: g_dev.onFailure(e->id, e->failure, e->text); break;
  }
  if (g_send == SendStep::Solving && e->id == g_sendId) {
    if (e->kind == Event::Reply) sendFinished(e->text, "");
    else if (e->kind == Event::Fail) sendFinished("", e->text.empty() ? failureText(e->failure) : e->text);
  }
  delete e;
}

// ---- battery: the AI lock-out (review S2) ----
// Camera + Wi-Fi together on a nearly flat cell can brown the board out, so below
// kAiMinMillivolts (on battery) the viewfinder, the radio and = are all held off,
// and the AI SOLVE screen says so. Hysteresis: back on above kAiResumeMillivolts.
bool g_aiBatteryOk = true;
uint32_t g_batteryAt = 0;

void serviceBattery(bool force = false) {
  if (!force && g_batteryAt && millis() - g_batteryAt < kBatteryRefreshMs) return;
  g_batteryAt = millis() | 1;
  const int mv = batteryMillivolts();
  const Charge c = chargeState();
  const bool was = g_aiBatteryOk;
  if (usbPresent()) g_aiBatteryOk = true;
  else if (mv < kAiMinMillivolts) g_aiBatteryOk = false;
  else if (mv >= kAiResumeMillivolts) g_aiBatteryOk = true;
  if (was != g_aiBatteryOk)
    LOGF("power", "battery %d mV: AI, camera and Wi-Fi %s", mv, g_aiBatteryOk ? "allowed again" : "off until charged");
  g_dev.setLowBattery(!g_aiBatteryOk);
  g_dev.setBattery(lipoPercent(mv), c == Charge::Charging);
}

// Queues a new AI request, unless the battery can't take the Wi-Fi bursts.
void queueRequest(int id) {
  if (!g_aiBatteryOk || !batteryOkForAi()) {
    g_dev.onFailure(id, Failure::LowBattery);
    return;
  }
  g_wantedId = id;
  xQueueSend(g_requests, &id, 0);
}

// ---- camera viewfinder (AI SOLVE home screen) ----
Viewfinder g_vf;
Panel g_panel;
bool g_vfPaused = false;     // timed out, or no camera: the normal AI SOLVE screen shows
bool g_wasAiReady = false;   // for noticing "just arrived on the AI SOLVE home screen"
uint32_t g_vfLogAt = 0;
int g_vfLogFrames = 0, g_vfLogMv = 0;

// Frames come from their own task, so the next frame is taken and decoded while the
// e-paper is still busy with the last one (~2.5 fps instead of ~2), and the camera's
// 1 s power-up never blocks the keypad.
SemaphoreHandle_t g_grabLock;   // held by the task for a whole grab; taken to stop it
SemaphoreHandle_t g_frameLock;  // guards the hand-over below
bool g_grabOn = false;          // written only while holding g_grabLock
volatile bool g_grabFailed = false;
std::vector<uint8_t> g_frame;
int g_frameW = 0, g_frameH = 0;
bool g_frameFocused = false;
uint32_t g_frameSeq = 0, g_frameUsed = 0;

void grabTask(void*) {
  std::vector<uint8_t> buf;
  while (true) {
    xSemaphoreTake(g_grabLock, portMAX_DELAY);
    if (!g_grabOn) {
      xSemaphoreGive(g_grabLock);
      vTaskDelay(pdMS_TO_TICKS(30));
      continue;
    }
    int w = 0, h = 0;
    bool focused = false;
    const bool ok = cameraPreviewFrame(buf, w, h, focused);
    if (ok) {
      xSemaphoreTake(g_frameLock, portMAX_DELAY);
      g_frame.swap(buf);
      g_frameW = w;
      g_frameH = h;
      g_frameFocused = focused;
      ++g_frameSeq;
      xSemaphoreGive(g_frameLock);
    } else {
      g_grabOn = false;
      g_grabFailed = true;
    }
    xSemaphoreGive(g_grabLock);
    vTaskDelay(1);
  }
}

void setGrabbing(bool on) {
  xSemaphoreTake(g_grabLock, portMAX_DELAY);  // waits for a grab in progress to finish
  g_grabOn = on;
  if (on) g_grabFailed = false;
  xSemaphoreGive(g_grabLock);
}

bool onAiReady() {
  return !g_dev.isOff() && g_dev.mode() == Mode::Ai && g_dev.view() == View::Ai && g_dev.ai().screen() == Screen::Ready;
}

// ---- screens drawn by this file (not by Device): setup mode, updates ----
void showLines(const std::vector<std::string>& lines) {
  g_fb.clear();
  for (size_t i = 0; i < lines.size() && i < size_t(Framebuffer::kRows); ++i)
    g_fb.drawText(0, int(i), lines[i], i == 0);
  screenShow(g_fb, false);
}

// ---- phone setup mode (review S3) ----
SetupInfo g_setupInfo;
bool g_setupSaved = false;  // the page saved: close the network once the "Saved" page is out

void setupBegin(const char* how);  // below (needs wifiOff)

void setupEnd() {
  if (!setupActive()) return;
  setupStop();
  g_setupSaved = false;
}

void drawSetupScreen() {
  // Whole minutes: the e-paper is redrawn only when the text changes.
  const uint32_t left = setupSecondsLeft();
  char timer[24];
  snprintf(timer, sizeof timer, "%lu min left", (unsigned long)((left + 59) / 60));
  if (g_setupSaved) {
    showLines({"SETUP BY PHONE", "Saved. Closing the", "setup network...", "", "Next: MODE 4, then =", "", "AC:back"});
    return;
  }
  showLines({"SETUP BY PHONE",
             "1.Join Wi-Fi " + g_setupInfo.apName,
             "  password " + g_setupInfo.apPass,
             "2.Open the page it shows",
             "  or go to 192.168.4.1",
             "AC:back",
             timer});
}

// ---- keys ----
void press(DKey k) {
  g_lastKeyAt = millis();
  if (setupActive()) {  // the keypad only leaves setup mode (AC or ON)
    if (k == DKey::AC || k == DKey::On) {
      LOGF("setup", "ended with %s", dkeyName(k));
      setupEnd();
    }
    if (k != DKey::On) return;
  }
  if (g_vf.running()) g_vf.touch(millis());  // any key keeps the viewfinder on
  if (k == DKey::Right && g_vfPaused && onAiReady()) {  // ▶ on the AI SOLVE screen: viewfinder again
    g_vfPaused = false;
    return;
  }
  // = on SETUP > 6:Wi-Fi & key: set up from a phone (no PC needed).
  if (k == DKey::Eq && g_dev.view() == View::NetInfo && !g_dev.isOff() && g_dev.radiosAllowed()) {
    setupBegin("= on SETUP 6");
    return;
  }
  // SHIFT + ALPHA held while ON is pressed: the factory self-test.
  if (k == DKey::On && selfTestComboHeld()) selfTestRun("SHIFT+ALPHA+ON");
  LOGF("keys", "%s", dkeyName(k));  // lets you test every button without a multimeter
  g_dev.tick(millis());
  g_dev.onKey(k);
  g_wantedId = g_dev.activeRequest();  // 0 after AC / MODE / OFF: the solve task stops
  if (int id = g_dev.takeRequest()) queueRequest(id);
}

void typeKeys(const std::string& text) {
  for (char c : text) {
    if (c == ' ') continue;
    DKey ks[2];
    int n = 0;
    if (!keysForChar(c, ks, n)) {
      LOGF("keys", "no key for '%c' (type help, or see the README key list)", c);
      return;
    }
    for (int i = 0; i < n; ++i) press(ks[i]);
  }
}

// ---- Wi-Fi: only while it's needed ----
// Why the last join attempt failed, in words (0 = none yet).
volatile uint8_t g_wifiReason = 0;
volatile bool g_wifiReasonNew = false;
bool g_wifiOn = false;
uint32_t g_wifiNeededUntil = 0;  // serial commands (pair, account, update) keep it on briefly

const char* wifiReasonText(uint8_t r) {
  switch (r) {
    case WIFI_REASON_NO_AP_FOUND:
      return "can't see that hotspot. Check the name with scan; keep the phone's Personal Hotspot screen open";
    case WIFI_REASON_AUTH_FAIL:
    case WIFI_REASON_4WAY_HANDSHAKE_TIMEOUT:
    case WIFI_REASON_HANDSHAKE_TIMEOUT:
    case WIFI_REASON_802_1X_AUTH_FAILED:
      return "wrong password (type wifi to enter it again)";
    case WIFI_REASON_ASSOC_FAIL:
    case WIFI_REASON_AUTH_EXPIRE:
    case WIFI_REASON_BEACON_TIMEOUT:
      return "hotspot didn't answer; move the phone closer";
    default:
      return nullptr;
  }
}

void onWifiEvent(arduino_event_id_t event, arduino_event_info_t info) {
  if (event == ARDUINO_EVENT_WIFI_STA_DISCONNECTED) {
    const uint8_t r = info.wifi_sta_disconnected.reason;
    if (r != g_wifiReason) g_wifiReasonNew = true;
    g_wifiReason = r;
  } else if (event == ARDUINO_EVENT_WIFI_STA_GOT_IP) {
    g_wifiReason = 0;
    LOGF("wifi", "connected: %s", WiFi.localIP().toString().c_str());
  }
}

// Reports a new failure reason once, not on every retry.
void reportWifi() {
  if (!g_wifiReasonNew || !g_wifiOn) return;
  g_wifiReasonNew = false;
  const uint8_t r = g_wifiReason;
  const char* t = wifiReasonText(r);
  if (t) LOGF("wifi", "%s (code %u)", t, r);
  else LOGF("wifi", "not connected (code %u)", r);
}

void scanWifi() {
  LOGF("wifi", "scanning (a few seconds)...");
  if (!g_wifiOn) {
    WiFi.mode(WIFI_STA);
    powerLimitWifi();
  }
  const int n = WiFi.scanNetworks();
  if (n <= 0) {
    LOGF("wifi", "no networks found. The chip only sees 2.4 GHz: on iPhone turn on Maximize Compatibility");
  } else {
    bool found = false;
    for (int i = 0; i < n; ++i) {
      const String name = WiFi.SSID(i);
      const bool mine = !g_settings.ssid.empty() && name == g_settings.ssid.c_str();
      found |= mine;
      Serial.printf("  %s\"%s\"  signal %d dBm%s\n", mine ? "* " : "  ", name.c_str(), WiFi.RSSI(i),
                    mine ? "  <- your saved hotspot" : "");
    }
    if (!g_settings.ssid.empty() && !found)
      LOGF("wifi", "your saved hotspot \"%s\" is not in the list. Names must match exactly (capitals, apostrophes)",
           g_settings.ssid.c_str());
  }
  WiFi.scanDelete();
  if (!g_wifiOn) WiFi.mode(WIFI_OFF);
}

void wifiOff() {
  if (!g_wifiOn) return;
  g_wifiOn = false;
  WiFi.disconnect(true);
  WiFi.mode(WIFI_OFF);
}

void wifiOn() {
  if (g_wifiOn) return;
  if (previewRunning()) previewStop();  // it shares the radio (a Send's pause is handled by its own step)
  if (setupActive()) setupEnd();
  g_wifiOn = true;
  WiFi.mode(WIFI_STA);
  powerLimitWifi();  // 11 dBm: plenty for a phone in the same room, small bursts for the cell
  WiFi.setAutoReconnect(true);
  g_wifiReason = 0;
  g_wifiReasonNew = false;
  WiFi.begin(g_settings.ssid.c_str(), g_settings.password.c_str());
}

// Wi-Fi is on only while the AI can use it: on, AI SOLVE (or a Send / serial command),
// not in exam mode, battery not nearly flat, hotspot set up. COMP maths never needs it.
void serviceWifi() {
  const bool aiScreen = !g_dev.isOff() && g_dev.mode() == Mode::Ai;
  const bool want = !g_settings.ssid.empty() && g_dev.radiosAllowed() && g_aiBatteryOk && !previewRunning() &&
                    !setupActive() &&
                    (aiScreen || g_dev.activeRequest() != 0 || g_send == SendStep::WaitWifi ||
                     g_send == SendStep::Solving || int32_t(g_wifiNeededUntil - millis()) > 0);
  if (want) wifiOn();
  else if (!previewActive() && !setupActive()) wifiOff();
}
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
void loop() {
  std::string arg;
  Settings edited = g_settings;  // the solve task may be copying g_settings right now
  const SerialCmd cmd = settingsPoll(edited, statusText, arg);
  switch (cmd) {
    case SerialCmd::Changed: publishSettings(edited); break;
    case SerialCmd::Keys: typeKeys(arg); break;
    case SerialCmd::ExamOff:
      if (g_dev.examActive()) g_dev.usbUnlock();
      else LOGF("exam", "exam mode is not on");
      break;
    case SerialCmd::Snap: {
      if (g_dev.activeRequest() != 0) {
        LOGF("cam", "busy with a photo; try again in a moment");
        break;
      }
      std::string jpeg, detail, err;
      uint32_t t0 = millis();
      if (cameraCapture(jpeg, detail, err))
        LOGF("cam", "test photo: %u bytes%s in %lu ms", (unsigned)jpeg.size(),
             detail.empty() ? "" : (" + close-up " + std::to_string(detail.size())).c_str(), millis() - t0);
      else
        LOGF("cam", "%s", err.c_str());
      break;
    }
    case SerialCmd::Scan:
      if (!g_dev.radiosAllowed()) LOGF("wifi", "off in exam mode");
      else scanWifi();
      break;
    case SerialCmd::Preview: {
      if (!g_dev.radiosAllowed()) {
        LOGF("preview", "off in exam mode");
        break;
      }
      wifiOff();
      setupEnd();
      std::string msg;
      previewStart(msg);
      Serial.println(msg.c_str());
      break;
    }
    case SerialCmd::PreviewOff:
      if (previewRunning()) previewStop();
      else LOGF("preview", "not on");
      break;
    case SerialCmd::Pair: pairCommand(); break;
    case SerialCmd::Account: accountCommand(); break;
    case SerialCmd::Setup:
      if (g_dev.isOff()) press(DKey::On);
      setupBegin("serial");
      break;
    case SerialCmd::SetupOff:
      if (setupActive()) setupEnd();
      else LOGF("setup", "not on");
      break;
    case SerialCmd::Update: updateCommand(); break;
    case SerialCmd::SelfTest:
      wifiOff();
      setupEnd();
      selfTestRun("serial");
      break;  // never reached (selfTestRun restarts); keeps the switch readable
    case SerialCmd::None: break;
  }
  if (cmd != SerialCmd::None) g_lastKeyAt = millis();
  reportWifi();
  previewService();
  serviceSend();
  serviceSetup();

  keysPoll(press);
  Event* e;
  while (xQueueReceive(g_events, &e, 0) == pdTRUE) handleEvent(e);

  serviceExam();
  if (usbPresent() && !g_aiBatteryOk) serviceBattery(true);  // a cable lifts the lock-out at once
  serviceBattery();
  serviceWifi();
  // "Online" once Wi-Fi is on for AI SOLVE: = may be pressed while it is still joining
  // the hotspot (the photo takes longer than the join; the solve task waits for it).
  g_dev.setOnline(WiFi.status() == WL_CONNECTED || (g_wifiOn && !g_settings.ssid.empty()));
  g_dev.setHoldUntil(cameraHoldUntil());  // "HOLD STILL 3 s" countdown while the camera waits
  g_dev.tick(millis());
  if (setupActive()) {
    drawSetupScreen();
  } else if (!serviceViewfinder()) {
    g_dev.render(g_fb);
    screenShow(g_fb, g_dev.dotMatrix());  // no-op unless the picture changed
  }
  serviceOtaConfirm();
  serviceOta();
  servicePower();
  delay(10);
}

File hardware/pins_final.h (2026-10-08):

// AI Calculator final board: every ESP32 pin in one place.
// THIS FILE IS THE SINGLE SOURCE OF TRUTH. The board firmware includes it directly
// (firmware-prototype/src/pins.h is a one-line #include of this file), so a pin changed
// here is a pin changed in the firmware. Net names in [brackets] are the schematic's.
//
// Module: ESP32-S3-MINI-1-N4R2 (4 MB quad flash + 2 MB quad PSRAM in the chip package).
// Checked against the ESP32-S3-MINI-1 datasheet v1.7, Table 3-1 + chapter 4:
//   - IO26 is taken by the PSRAM on -N4R2 parts: never use it.
//   - IO33..IO37 are exposed and free on -N4R2 (only octal-PSRAM parts lose them).
//   - Strapping pins 0, 3, 45, 46 are left unused (0 = BOOT pad only; 45 must stay low = 3.3 V flash).
//   - RTC GPIOs (can wake from deep sleep) are IO0..IO21.
//   - ADC1 (works while Wi-Fi is on) is IO1..IO10; ADC2 is not usable with Wi-Fi.
// Verified 2026-10-03 against a netlist exported with kicad-cli from hardware/kicad (stage 13):
// every U1 pad below carries the net named in its comment. Re-check after any schematic change:
//   python firmware-prototype/tools/check_pins.py
// The tester (firmware/src/pins.h) is different hardware and keeps its own pins.
#pragma once
#include <stdint.h>

// ---- Camera: OV5640 autofocus, 24-pin 0.5 mm FPC socket J1 (esp32-camera naming: D0..D7 = Y2..Y9)
// Stage 6 (2026-10-02): pins re-ordered so the bus leaves the module in the same order as the
// socket pins (no crossings, 0.6 mm track pitch). Same set of GPIOs as before, different roles.
constexpr int PIN_CAM_XCLK  = 18;  // [CAM_XCLK] 20 MHz clock out (LEDC)
constexpr int PIN_CAM_SIOD  = 40;  // [CAM_SIOD] SCCB data, own bus (not shared with the keypad); MTDO (JTAG) pin
constexpr int PIN_CAM_SIOC  = 39;  // [CAM_SIOC] SCCB clock; MTCK (JTAG) pin. 4.7 k pull-ups R18/R19 go to CAM_2V8
constexpr int PIN_CAM_D0    = 13;  // [CAM_D0] Y2
constexpr int PIN_CAM_D1    = 11;  // [CAM_D1] Y3
constexpr int PIN_CAM_D2    = 10;  // [CAM_D2] Y4
constexpr int PIN_CAM_D3    = 12;  // [CAM_D3] Y5
constexpr int PIN_CAM_D4    = 14;  // [CAM_D4] Y6
constexpr int PIN_CAM_D5    = 16;  // [CAM_D5] Y7
constexpr int PIN_CAM_D6    = 17;  // [CAM_D6] Y8
constexpr int PIN_CAM_D7    = 21;  // [CAM_D7] Y9
constexpr int PIN_CAM_VSYNC = 36;  // [CAM_VSYNC]
constexpr int PIN_CAM_HREF  = 47;  // [CAM_HREF]
constexpr int PIN_CAM_PCLK  = 15;  // [CAM_PCLK]
constexpr int PIN_CAM_PWDN  = 48;  // [CAM_PWDN] high = sensor powered down (active high); 10 k pull-down.
                                   // Never drive it high while CAM_2V8 is off (~330 uA into the unpowered sensor).
constexpr int PIN_CAM_RESET = 38;  // [CAM_RESET] low = reset (active low); 10 k pull-up to CAM_2V8 + 100 nF
constexpr int PIN_CAM_PWR_EN = 34; // [CAM_PWR_EN] high = 2.8 V + 1.5 V camera regulators on; R10 100 k pull-down = off in sleep

// ---- E-paper: 2.13" 250x122 bare panel (SSD1680), 24-pin 0.5 mm FPC socket J2 + booster on the board (SPI, write-only)
constexpr int PIN_EPD_CLK  = 5;    // [EPD_CLK]
constexpr int PIN_EPD_DIN  = 6;    // [EPD_DIN] (MOSI)
constexpr int PIN_EPD_CS   = 8;    // [EPD_CS]
constexpr int PIN_EPD_DC   = 41;   // [EPD_DC]
constexpr int PIN_EPD_RST  = 42;   // [EPD_RST]
constexpr int PIN_EPD_BUSY = 33;   // [EPD_BUSY] input; high while the panel is refreshing

// ---- Keypad: 49 keys as an 8 x 10 matrix on a TCA8418 (U6, I2C 0x34); ON has its own pin
constexpr int PIN_I2C_SDA    = 1;  // [I2C_SDA] 4.7 k pull-ups to 3.3 V on the board
constexpr int PIN_I2C_SCL    = 2;  // [I2C_SCL]
constexpr int PIN_KEYPAD_INT = 4;  // [KEYPAD_INT] TCA8418 INT (open drain, 10 k pull-up R15, low while a key event
                                   // waits); RTC pin: wakes the chip from deep sleep (EXT1). Clear it before sleeping
                                   // or R15 draws 330 uA all night.
constexpr int PIN_KEY_ON     = 7;  // [KEY_ON] ON pad to GND, R17 100 k pull-up (board/BOM: 100k C25741); RTC pin: wakes the chip from deep sleep (EXT1, low)
constexpr uint8_t TCA8418_I2C_ADDR = 0x34;
// TCA8418 ~RESET [TCA_RESET] has only a 10 k pull-up (R16): it is NOT wired to the ESP32. The firmware
// re-writes every TCA8418 register at start instead of resetting it.
constexpr int PIN_TCA_RESET  = -1;
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

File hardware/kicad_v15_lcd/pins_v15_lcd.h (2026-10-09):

// AI Calculator board v15-LCD: every ESP32 pin in one place (stage 15, 2026-10-08).
// This is hardware/pins_final.h (v14, e-paper) with the display block replaced by the 1.9in IPS LCD.
// When the v15 board is built, firmware-prototype/src/pins.h should include THIS file instead of
// ../../hardware/pins_final.h. Net names in [brackets] are the schematic's (hardware/kicad_v15_lcd/).
//
// What changed vs v14 (everything else is identical to pins_final.h):
//   - E-paper (SSD1680, J2, booster) is gone. 1.9in 170x320 IPS, ST7789V3, 4-wire SPI, on J5 (30-pin FPC).
//   - The five e-paper SPI GPIOs are re-used, but their ROLES were re-assigned so the board's B.Cu bus
//     meets the socket without crossings: IO5 MOSI, IO6 D/C, IO8 SCK, IO41 CS, IO42 RST (review 13, 2026-10-08:
//     J5's footprint pad numbers are mirrored like J1's, pad N = socket contact 31-N, so the roles swapped vs stage15_lcd.md).
//   - Backlight PWM on IO4 (was KEYPAD_INT). KEYPAD_INT moved to IO3 (both RTC pins: deep-sleep wake still works).
//   - LCD power switch (P-MOSFET Q4, active LOW) on IO33 (was EPD_BUSY). High / floating = LCD unpowered.
//   - IO3 is a strapping pin (JTAG source) only when the JTAG-select eFuse is burned; this project never burns
//     eFuses, so it is an ordinary RTC GPIO here. It has no internal pull at reset.
#pragma once
#include <stdint.h>

// ---- Camera: OV5640 autofocus, 24-pin 0.5 mm FPC socket J1 (unchanged from v14)
constexpr int PIN_CAM_XCLK  = 18;  // [CAM_XCLK]
constexpr int PIN_CAM_SIOD  = 40;  // [CAM_SIOD]
constexpr int PIN_CAM_SIOC  = 39;  // [CAM_SIOC]
constexpr int PIN_CAM_D0    = 13;  // [CAM_D0] Y2
constexpr int PIN_CAM_D1    = 11;  // [CAM_D1] Y3
constexpr int PIN_CAM_D2    = 10;  // [CAM_D2] Y4
constexpr int PIN_CAM_D3    = 12;  // [CAM_D3] Y5
constexpr int PIN_CAM_D4    = 14;  // [CAM_D4] Y6
constexpr int PIN_CAM_D5    = 16;  // [CAM_D5] Y7
constexpr int PIN_CAM_D6    = 17;  // [CAM_D6] Y8
constexpr int PIN_CAM_D7    = 21;  // [CAM_D7] Y9
constexpr int PIN_CAM_VSYNC = 36;  // [CAM_VSYNC]
constexpr int PIN_CAM_HREF  = 47;  // [CAM_HREF]
constexpr int PIN_CAM_PCLK  = 15;  // [CAM_PCLK]
constexpr int PIN_CAM_PWDN  = 48;  // [CAM_PWDN] active high; 10 k pull-down. Never high while CAM_2V8 is off.
constexpr int PIN_CAM_RESET = 38;  // [CAM_RESET] active low; 10 k pull-up to CAM_2V8 + 100 nF
constexpr int PIN_CAM_PWR_EN = 34; // [CAM_PWR_EN] high = camera regulators on; R10 100 k pull-down = off in sleep

// ---- LCD: 1.9in 170x320 IPS, ST7789V3 (panel 190-1732TBWPG01 family = LilyGO T-Display-S3 / Heltec HT-VMT190
//      panel), 30-pin 0.5 mm FPC socket J5 (HDGC 0.5K-HX-30PWB, dual contact). 4-wire SPI, write-only (SDO open).
//      Panel pins: 1 GND, 2 VDD, 3 IM2, 4 IM1 (both tied to VDD = 4-line SPI), 5 RESET, 6 CS, 7 SCL, 8 RS (D/C),
//      9 RD (GND), 10 SDA (MOSI), 11-18 DB0-7 (GND), 19 SDO (open), 20 LEDA, 21-24 LEDK1-4, 25/30 GND, 26-29 open.
//      No TE pin on this panel.
constexpr int PIN_LCD_SCK   = 8;   // [LCD_SCK]  (was EPD_CS)
constexpr int PIN_LCD_MOSI  = 5;   // [LCD_MOSI] (was EPD_CLK)  review 13: roles swapped with the mirrored J5 numbering
constexpr int PIN_LCD_CS    = 41;  // [LCD_CS]   (was EPD_DC)   review 13
constexpr int PIN_LCD_DC    = 6;   // [LCD_DC]   (was EPD_DIN)  review 13
constexpr int PIN_LCD_RST   = 42;  // [LCD_RST]  (was EPD_RST)  review 13
constexpr int PIN_LCD_PWR_N = 33;  // [LCD_PWR_N] LOW = Q4 on = LCD_VDD (3.3 V) to the panel. R21 100 k pull-up:
                                   // the panel is unpowered in deep sleep and before the firmware runs.
                                   // Not an RTC pin: it floats in deep sleep, which R21 turns into "off".
constexpr int PIN_LCD_BL    = 4;   // [LCD_BL_EN] gate of Q5 (AO3400A) -> backlight cathodes. LEDC PWM, active high.
                                   // R22 100 k pull-down = off in sleep. 100 % duty = (3.3 V - Vf) / 15 R = ~16-37 mA (26 typ; review 14)
                                   // through the 4 parallel LEDs (panel rating 60 mA). RTC pin.
constexpr int PIN_LCD_MISO  = -1;  // SDO (pin 19) left open
constexpr int PIN_LCD_TE    = -1;  // the panel has no tearing-effect pin
constexpr int LCD_WIDTH  = 170;    // native portrait; the firmware uses it rotated to 320 x 170 landscape
constexpr int LCD_HEIGHT = 320;
constexpr int LCD_COL_OFFSET = 35; // ST7789 170-px panels: RAM column offset 35 (TFT_eSPI: TFT_WIDTH 170 handles it)
constexpr uint32_t LCD_SPI_HZ = 40000000;  // 40 MHz through the GPIO matrix (80 MHz needs IOMUX pins, not used here)
// Power-down order (hardware/stage15_lcd.md): backlight off (BL duty 0), SLPIN, then every LCD GPIO low or
// input-no-pull, THEN PIN_LCD_PWR_N high. A high SPI line into an unpowered panel back-feeds it through its ESD diodes.
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

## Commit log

2026-10-01 First snapshot: calculator core, simulators, tester and prototype firmware
    - core/: the calculator (COMP maths, menus, AI SOLVE, exam mode) shared by
    every build; Claude reads boxed problems and 2D math notation, effort
    switch on the AI SOLVE screen, steps even on unsure answers
    - firmware/: breadboard tester (ESP32-S3-CAM, OV3660, 4 buttons + BOOT),
    hold to scroll
    - firmware-prototype/: final board (WROOM-1-N16R8, OV5640 autofocus,
    TCA8418 keypad, LiPo, sleep while off); builds, not yet run on hardware
    - sim/, tests/, samples/, tools/, graphify-out/ knowledge graph
    [camera.cpp]
2026-10-02 Keypad row 2 follows the board: Abs, x^3, x^-1, log_a b
    The prototype board is traced from the newer fx-300ES PLUS keypad, whose
    second row is Abs, x^3, x^-1, log_a b (not x^-1, nCr, Pol, x^3). nPr and
    nCr move to SHIFT x and SHIFT /, as on that keypad; Abs gets its own key,
    so SHIFT hyp no longer types it. Updated the key list, the prototype's key
    matrix, the web simulator's keypad, and the tests (nCr, nPr, Abs, log_a b).
    [keys.cpp]
2026-10-02 Prototype firmware matches the KiCad board
    Checked firmware-prototype against hardware/kicad/ai_calc.kicad_sch and
    fixed every difference:
    - module is ESP32-S3-MINI-1-N4R2: 4 MB flash, 2 MB quad PSRAM (qio_qspi);
    the octal-PSRAM build would not have booted
    - e-paper BUSY on GPIO 33 (was 3)
    - camera regulators on CAM_PWR_EN (GPIO 34): driven high before init, low
    in sleep (the camera had no power before); camera RESET on GPIO 36
    - keypad is an 8 x 10 matrix (ROW0-7, COL0-9): kMatrix copied from the
    schematic's 49 switches
    - 2 MB PSRAM: one frame buffer, 2048x1536 OV5640 scans, frames scored as
    they arrive and only the sharpest kept, no preview copy
    - charging (CHG_STAT, GPIO 35) and U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
    [camera.cpp, keys.cpp, main.cpp]
2026-10-02 Prototype firmware uses the board's stage-6 camera pins
    The v9 board re-orders the camera GPIOs so the bus leaves the module in
    the socket's pin order. CHG_STAT is a plain input (the board pulls it up).
2026-10-03 Add hardware folder, stage-11 PCB work in progress, and launch roadmap
    Puts the KiCad project, fab outputs, fit-check files, enclosure CAD and
    stage docs under version control for the first time. The board is
    mid-way through stage 11 (e-paper block moved up 3.57 mm to match the
    measured LCD window), so DRC is not clean in this commit yet.
    Also adds the independent design review, the launch roadmap (markdown,
    chart data and the published HTML page), and refreshed graphify output.
    [ai_calc.kicad_pcb, ai_calc.kicad_sch, ai_calc.stage1.kicad_pcb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]
2026-10-03 Roadmap: $2,000 budget plan and $225 + $15/month pricing
    Adds a money section to the launch roadmap: how the starting budget is
    split into two supply waves, profit per unit and per subscriber, and how
    preorders compound into bigger batches. Also saves the PR description.
    [ai_calc.kicad_pcb, mcu.kicad_sch, power.kicad_sch]
2026-10-03 PCB stage 11 finished (DRC 0/0/0) and unbranded fx-115ES replica CAD
    Board: e-paper block moved 3.57 mm up to the measured LCD window and
    fully re-routed; review fixes applied (R20 pull-up to VBUS_SENSE,
    U3 -> RT9080-33GJ5 for longer standby, D7 orientation checked, 22 uF
    bulk cap C32); test points TP5-TP7; locating-post holes 4.2 mm; antenna
    keep-out strip; straightened track chains. DRC with refilled zones and
    schematic parity: 0 errors, 0 unconnected, 0 parity issues. fab/,
    fit-check and summary regenerated.
    CAD: build_fx115es_replica.py builds an unbranded fx-115ES shell in
    Fusion from the caliper readings and the 23 shell photos (60 bodies,
    0 interferences), with F3D/STEP/STL exports a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
    [00_Key_Abs.stl, 01_Key_RCL.stl, 02_Key_a_b.stl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]
2026-10-03 Add second batch of caliper readings (2026-10-03)
    [ai_calc-B_Cu.gbl, ai_calc-B_Mask.gbs, ai_calc-B_Paste.gbp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]
2026-10-08 Final review, v14 order prep, firmware fixes and production planning
    - PCB v14 confirmed GO by final reviews (verification 06, 08, 11)
    - CAD fit rev G with measured rib/pin/hook heights; grind zones 6, 6b, 6c
    - Firmware: OTA updates, phone setup portal, low-battery gate, polish
    - Docs: arrival checklist, vendor comparison, order walkthrough updates
    - Production: QA test plan, knockoff shell plan, cost model
    [00_Key_Abs.stl, 01_Key_RCL.stl, 02_Key_a_b.stl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]
2026-10-09 v15 colour-LCD board, firmware with live preview, CAD and docs
    - v14 frozen (tag v14-order, archive copies)
    - v15-LCD PCB: 1.9in ST7789 IPS (BuyDisplay ER-TFT019-1), J5 mirrored,
    slot/J5 moved for the tail bow, R23 15 ohm, SHIFT/ALPHA/ON pads matched
    to the Casio board; reviews 13-15 verdict ORDER; fab_v15_lcd outputs
    - firmware-v15-lcd: LovyanGFX colour UI, backlight, live camera preview
    - OTA server: never offers one board family's image to the other
    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
    [AI_Calculator_Shopping_List.xlsx, Alibaba_Bulk_Sourcing.xlsx, COST_MODEL.xlsx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]
2026-10-10 CAD: Goldenmorning T190X7-C30-01H fit check (2.03/2.18 mm), report and log
2026-10-10 Docs: Yiwei MG04254FRA1S1N / MG0425-UB-60-4P as alternates to Adafruit #5358 / #5412 (J3 order unchanged)
    [AI_Calculator_Shopping_List.xlsx, Alibaba_Bulk_Sourcing.xlsx]
2026-10-10 CAD: DCXYX OV5640-AF camera fit on v15 (S-fold tuck fits; 8 mm move fallback)
2026-10-10 Guides: power-up guides v14/v15 with tool primers, labelled board maps, probe pictures, flowcharts
2026-10-10 Renders: guide picture library (grind before/after per zone, v14/v15 assembly close-ups, bring-up maps) + manifest
2026-10-10 Guides: v15 assembly guide rewritten with 88 pictures, diagrams, checks and glossary
2026-10-10 Guides: v14 assembly + grinding manual rewritten with pictures and diagrams; camera-hole datum 38.0 mm; Sungood panel and TW302030 cell recorded
2026-10-10 Guides: correct battery tape picture, confirm key-mat orientation, fix top-edge datum (zones 1/6/6b/6c), TW302030 battery fit (fits, 1 mm left)
2026-10-10 Project hub page (both builds, status board, guides, parts, money, timeline)
2026-10-10 Docs: propagate corrected zone datums, battery tape strip-2 margin, key-mat orientation, TW302030 to older docs and sheets
    [AI_Calculator_Shopping_List.xlsx, Alibaba_Bulk_Sourcing.xlsx]
2026-10-10 UI sim: real v15 LCD screenshots rendered by the firmware's own UI code on PC (48 screens, framed renders)
2026-10-10 Guides: battery tape strip 2 at 0.5 mm (pictures re-rendered), TW302030 140 mAh, zone 6 14-49 on grind map/photos, FINAL_STATUS zone 6+6b always needed (verification 12)
2026-10-10 Proxy: tiers + model fallback + prompt caching, server-owned prompt, rate limits, signed /link flow, Stripe-signed billing, SSE keep-alive, safe logging (51 tests)
2026-10-10 Animations: assembly, turntable and x-ray GIFs for v14 and v15; hub 'See it come together' section
2026-10-11 Animations: assembly order matches the build guides, v14 e-paper shows a result
2026-10-14 v15 firmware: MODE 4 Apps, all fx-115ES modes, Worker API, simulators
    - Calculator screens match the Casio (no hint bar); colour only in Apps
    - MODE 4 Apps: AI Solve, Type it, History, Notes, Geography, Periodic
    Table, Settings (incl. Link calculator); all off in exam mode
    - Calculator modes: STAT, TABLE, EQN, CMPLX, BASE-N, MATRIX, VECTOR,
    plus CALC, SOLVE, integral and derivative; all allowed in exam mode
    - Stage 2: firmware talks to the Cloudflare Worker API (register, status,
    link code, plan state, solve incl. typed PNG, firmware by family);
    TLS roots for Cloudflare's CAs
    - ~45 bugs fixed from reviews and fuzzing (camera power, crash races,
    stack depth, exam-mode edge cases, nu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
2026-10-14 Proofline loading screen at start-up and after ON
    Core (Device): startBoot / setBootStep / finishBoot show a splash with the
    logo, "AI CALCULATOR", a loading bar and the current step; it stays up at
    least 1.5 s. setSplash(true) also shows it for 0.8 s after ON. Keys still
    reach the calculator, and once loading is done any key skips it.
    v15 LCD: ui::showSplash() draws it in the brand navy and orange, on a cold
    start from setup() (settings, apps, Wi-Fi, camera) and through showDevice()
    after ON. The viewfinder waits until it is gone.
    v14 prototype: cold start only (waking from deep sleep stays instant).
    Tester and all simulators show it too. ui_sim_v15 renders 57_splash_boot
    and 58_splash_aft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
